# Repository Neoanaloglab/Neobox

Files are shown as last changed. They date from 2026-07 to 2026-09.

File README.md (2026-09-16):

# NeoBox

**English** · [简体中文](README.zh-CN.md) · [日本語](README.ja.md)

> An open-hardware, 3D-printable desktop flash light box for camera scanning 135 and 120 film: about 125 × 155 × 83 mm, twelve printed parts (four of them optional) at roughly 300–350 g, assembled with magnets alone: no screws, no threads, no tools. Any hot-shoe flash lies at the fully open front and fires in; an insert platform keeps the film flat, with a single universal anti-Newton glass as the optional upgrade.

**Contents:** [What NeoBox is](#what-neobox-is) · [What you get, and what you must already own](#what-you-get-and-what-you-must-already-own) · [Why a flash](#why-a-flash) · [How the light works](#how-the-light-works) · [Documentation](#documentation) · [Quick start](#quick-start) · [Repository layout](#repository-layout) · [Adapting to a different flash](#adapting-to-a-different-flash) · [Status](#status) · [Licence and credits](#licence-and-credits)

   

> [!IMPORTANT]
> This is the first release. The geometry is dimensionally verified in the Blender source and the exported STL files are numerically verified, but **no box of this geometry has ever been printed, photographed, measured or evenness-tested.** Read [Status](#status) before you spend money.

## What NeoBox is

NeoBox is a white box, fully open at the front, that turns one bare speedlight into an evenly glowing surface, so you can photograph film with a digital camera instead of a scanner, a technique called [camera scanning](docs/glossary.md#camera-scanning) (also DSLR scanning).

The flash lies flat on the desk with its head at the open front and fires **horizontally** into the white cavity; light reaches the film only after several diffuse bounces and one opal acrylic diffuser.

Because the flash stays outside the enclosure, the box only has to contain the mixing cavity and the film platform, which is why twelve printed parts, roughly 300–350 g of PLA and a 160 × 160 mm build plate are enough.

| Item | Specification |
|---|---|
| Outer size | ≈ 125 × 155 × 83 mm (footprint 124.8 × 154.8 mm; 87 mm to the top of a seated film holder) |
| Formats | 135 and 120 up to 6×9; 6×6 via a mask insert; 6×4.5 by cropping in post; mounted 135 slides via the optional slide plate; 4×5 sheets via the optional 4×5 stage, with an evenness caveat |
| Printed parts | 12 STL files (3 white, 9 black, including the optional 6×6 mask, slide plate and 4×5 stage); ≈ 300–350 g; all support-free |
| Bought parts | 1 opal acrylic diffuser, 32 Ø8 × 2 mm magnets, 4 steel washers; optional: 1 anti-Newton glass, 1 flocking sheet |
| Enclosure | A one-piece main body with a fully open front, and a cover-stage that drops on over four locating tenons |
| Diffusion | Single opal acrylic diffuser, 68 × 118 × 2 mm, under a 62 × 95 mm light window, 4.6 mm below the film |
| Film flatness | Insert platform: a 4.6 mm element ledge in the holder base carries a printed pressure-window insert, upgradable to one universal 64 × 95 × 2 mm anti-Newton glass |
| Film holders | Sliding-channel holders for 135 and 120, closed by Ø8 × 2 magnets, swapped by lifting one off and setting the other down; a pocketed slide plate for mounted 135 slides |
| Film plane | 83.2 mm above the desk, identical for both formats |
| Light source | Any hot-shoe flash with manual power, lying flat at the open front; reference build is a NEEWER TT560 with a ZENIKO T1 trigger set |
| Assembly | No screws, no threads, no tools; magnets and gravity only; levelling is done on the camera side with a small mirror |
| Licence | MIT |

## What you get, and what you must already own

NeoBox is one half of a scanning rig. It replaces the light table; it does not replace the camera above it.

| This repository gives you | You must already own or buy |
|---|---|
| 12 STL files (3 white, 9 black), every one printing support-free on a flat face | A camera body with manual exposure and raw capture (mirrorless or DSLR) |
| The Blender source `cad/neobox.blend`, the authoritative geometry | A macro-capable lens; one 1:1 macro lens covers every format in this project |
| Drawings, in English, 简体中文 and 日本語 | A [copy stand](docs/glossary.md#copy-stand), or a tripod with a horizontal or reversible column, that holds the camera squarely above the box |
| Ten documents covering shopping, printing, building and scanning | The flash itself, plus a trigger set: the transmitter goes on the camera's hot shoe, and the receiver stays outside the box |
| The committed STL exporter and the geometry verification script | A remote release, and software that does [flat-field correction](docs/glossary.md#flat-field-correction) and negative [inversion](docs/glossary.md#inversion) |
| Copy-paste [vendor scripts](docs/bom.md#vendor-scripts) for ordering every part from a print shop | The consumables in [Tools and consumables](docs/bom.md#tools-and-consumables); assembly itself needs no screwdriver, wrench or soldering iron |

> [!IMPORTANT]
> The build cost covers the printed and bought parts only. It excludes the flash, the trigger, the camera, the lens, the stand, the release and the software. If you own none of those, budget for them first; [Getting started](docs/getting-started.md#what-you-must-already-own) itemises the whole list.

## Why a flash

**The flash pulse *is* the exposure.** The camera's shutter dial stays at an ordinary sync speed (1/125 s is the recommendation); its only job is to be open when the flash fires. What actually defines the frame is the tube's pulse, which lasts just 1/1,000–1/20,000 s at working power. The front of the box is open, so ambient light can reach the cavity, but the pulse is far brighter than room light. Shoot in a dim room, keep ceiling lights out of the opening, and ambient contributes nothing visible.

**That makes vibration irrelevant.** The pulse behaves as an effective shutter one to three orders of magnitude shorter than the 1/15–1/60 s of real shutter time a continuous LED panel needs at ISO 100 and f/8. Copy-stand flex, shutter shock and footsteps on a wooden floor stop mattering, because nothing moves measurably within the pulse. This is the project's central claim.

The second argument is spectral, and film is pickier here than it looks. A colour negative is three stacked dye layers: yellow, magenta, cyan, recording blue, green and red respectively, with the cyan record and the orange mask both working at the red end of the spectrum. A scanning light has to deliver honest energy across all three bands at once. Wherever the source is weak or gapped, that dye layer is under-sampled, the channels stop separating cleanly, and the bill arrives after inversion: crossed colour curves and stubborn casts that no single white-balance click can fix.

**A xenon tube is the native light source for silver-halide materials.** Its emission is a genuinely continuous spectrum at roughly 5600 K, daylight-class colour rendering (CRI typically ≥ 95) with strong deep red, the R9 patch LEDs struggle with. A typical white LED is a blue pump plus phosphor: a spike near 450 nm, a dip around 480 nm (the "cyan gap"), a broad phosphor hump, then a roll-off past about 630 nm, landing exactly where the cyan layer and the orange mask need light most. The figure below shows the shape of the problem; the curves are schematic, typical of the two source classes, not measurements.

Spectral and time-domain comparison of flash and LED

"White" mixed from three LEDs fares no better, for the opposite reason: the spectrum collapses to three narrow spikes with near-nothing between them, so whole bands of the dye spectra are simply never sampled. A one-shot colour camera makes it worse. Its colour matrix is calibrated for continuous illuminants, three spikes read through the Bayer filters produce cross-talk the calibration never anticipated, and the white point baked into the mixing ratios fights the orange mask. The result is casts that shift from film stock to film stock and refuse to grade out.

The honest optimum lives elsewhere, and it deserves saying plainly: a monochrome camera with sequential RGB. Three exposures under narrow red, green and blue on a sensor with no Bayer mosaic make a densitometer-grade trichromatic scan, full resolution in every channel, separation defined by the source instead of by filter dyes. That is the drum-scanner lineage. It costs a niche camera, three shots per frame and a registration workflow. NeoBox deliberately sits at the pragmatic point of that curve: one flash, one shot, any camera, with a continuous spectrum keeping the single-shot path honest.

Consistency is the third argument, quiet but real. A manual flash at a fixed power fraction repeats shot after shot: every frame of a roll receives the same light, so one inversion profile fits the whole roll. There is no warm-up drift, no thermal colour shift over a session, and no PWM dimming, so nothing bands against an electronic shutter. And all of it arrives at f/8 and [base ISO](docs/glossary.md#base-iso), with power in reserve.

The precedent is commercial. Ricoh's [PENTAX FILM DUPLICATOR](https://ricohimagingstore.com/pentax-film-duplicator.html) is the benchmark camera-scanning rig, from a camera maker with film heritage, and it is specified around exactly this recipe: a digital camera with a macro lens, and an external strobe fired through a diffusion screen. NeoBox is the same optical recipe, with the light box printed at home and a film path of its own.

**An LED panel was considered and declined.** A panel is already a surface emitter, but it takes neither the effective-shutter argument nor the spectral argument above. The reasoning is in [Design](docs/design.md#8-flash-operation) and the [FAQ](docs/getting-started.md#faq).

## How the light works

Optical path through NeoBox: the flash fires horizontally into the white cavity, which mixes the light over several diffuse bounces; an opal acrylic diffuser under the film smooths it, the black parts above the diffuser absorb stray light, and the camera photographs the film against the even glow

1. **The flash fires sideways into the cavity, never at the film.** It lies flat on the desk with its light face at the fully open front, aimed into the box. The trigger receiver stays outside with it.
2. **The white cavity does the mixing.** Bare white filament walls and ceiling randomise direction over several diffuse bounces, the way an [integrating cavity](docs/glossary.md#integrating-cavity) does. There is no reflector plate and no internal adjustment hardware.
3. **One opal acrylic diffuser does the smoothing.** A 68 × 118 × 2 mm diffuser sits in a shallow recess in the cover-stage under the 62 × 95 mm light window, 4.6 mm below the film. Dust on it never images, because the diffuser itself is the glowing surface; wipe it occasionally and move on.
4. **Everything above the diffuser is black.** The holders, inserts and mask print in black filament, and an optional flocking sheet on the stage face kills the last of the glare, so stray light is absorbed instead of veiling the image.
5. **Nothing touches the image area.** The film rides on narrow lands along its non-image edges, under a pressure element seated on the 4.6 mm element ledge, leaving a 0.4 mm channel across the full frame. With the printed pressure-window insert any bow stays within 0.28 mm (inside the depth of field at 1:1 and f/8), and the optional [anti-Newton](docs/glossary.md#newton-rings) glass caps the whole frame continuously without ringing. Frames advance by pulling the strip through, so the holder is never opened mid-roll.

<details>
<summary>Why the flash stays outside the box</summary>

Earlier NeoBox revisions sealed the speedlight inside the enclosure, so the box had to be sized around the largest supported flash, and changing its batteries meant opening the box. v1 leaves the front wall entirely open: the flash lies on the desk and fires in, so the enclosure no longer depends on any flash dimension, any brand works, and the radio receiver sits outside where its signal is unobstructed.

Fully diffuse illumination keeps a side benefit known from darkroom enlargers, too: fine scratches and grain render softer than under directional light.

</details>

## Documentation

Read in this order. Everything below the line is reference material you can reach from anywhere.

```mermaid
flowchart LR
  A[Getting started] --> B[Bill of materials]
  B --> C[3D printing]
  C --> D[Assembly]
  D --> E[Scanning]
  E --> F[Troubleshooting]
```

| Document | Read this if… |
|---|---|
| [Getting started](docs/getting-started.md#getting-started) | You are new to this and want to know whether the project suits you, what it really costs, and how long it takes end to end. |
| [Bill of materials](docs/bom.md#bill-of-materials-and-sourcing) | You are about to buy. Parts, tools and consumables, sourcing in China, Japan and elsewhere, and copy-paste vendor scripts. |
| [3D printing](docs/printing.md#printing) | You are about to print, or to brief a print service. One settings block, a card per part, and acceptance checks. |
| [Assembly](docs/assembly.md#assembly) | The parts have arrived. Pressing in the magnets, the stack order, a checkpoint at every step, and the mirror levelling trick. |
| [Scanning](docs/scanning.md#scanning) | The box is built and you want negatives. Camera, lens, magnification, parallelism, focus, exposure, loading film, inversion. |
| [Troubleshooting](docs/troubleshooting.md#troubleshooting) | Something is wrong. Symptom, likely cause and fix, across printing, assembly, light and capture. |
| [Glossary](docs/glossary.md#glossary) | A word in these documents means nothing to you. One line per term, plus why it matters here. |
| [Design](docs/design.md#design) | You want the engineering: the dimension chain, the optical decisions, and how to work with the Blender source. |
| [Design log](docs/design-log.md#design-log) | You want to know why it is shaped like this, and which alternatives were tried and rejected. |
| [Contributing](CONTRIBUTING.md#contributing-to-neobox) | You want to send a patch. Which files are generated, the export and verify gate, and the three-language rule. |

## Quick start

- [ ] **1. Check that it suits you**: what you must already own, and the honest timeline. → [Getting started](docs/getting-started.md#getting-started)
- [ ] **2. Buy**: one opal acrylic diffuser cut to 68 × 118 × 2 mm, 32 Ø8 × 2 mm N35 magnets, 4 steel washers, and optionally one 64 × 95 × 2 mm anti-Newton glass and a flocking sheet. → [Bill of materials](docs/bom.md#tools-and-consumables)
- [ ] **3. Print**: 12 STL files in two colours (3 white, 9 black), plain PLA, no supports; every part prints on a flat face. The white filament must be **matte**: silk or glossy white keeps specular reflections alive in the cavity. → [3D printing](docs/printing.md#printing)
- [ ] **4. Assemble and calibrate**: press in the magnets, stack the parts; no screws, no tools. Then set a small mirror on the stage and centre the lens's own reflection in the viewfinder: the sensor is now parallel to the film plane. → [Assembly](docs/assembly.md#assembly)
- [ ] **5. Scan**: focus on the grain, meter, and shoot a roll. → [Scanning](docs/scanning.md#scanning)

> [!TIP]
> **[Bed size](docs/glossary.md#bed-size) is no longer a constraint.** The largest part is 154.8 mm long, so a 160 × 160 mm build plate is enough; every mainstream printer qualifies, and the large-bed warnings from earlier revisions no longer apply.

## Repository layout

| Path | Contents | Kind |
|---|---|---|
| [`cad/neobox.blend`](cad/neobox.blend) | Blender source: the authoritative geometry for every part | Source |
| [`cad/film-stage-aluminium-3mm.dxf`](cad/film-stage-aluminium-3mm.dxf) | The printed prototype's aluminium film stage, superseded; in v1 the stage is merged into the cover-stage | Historical |
| [`cad/legacy-plywood/`](cad/legacy-plywood/) | Two DXFs left from the abandoned plywood route. Not a complete build; kept for the record | Historical |
| [`stl/white-pla/`](stl/white-pla/) | `main-body.stl`, `cover-stage.stl`, `cover-stage-4x5.stl` | Generated |
| [`stl/black-pla/`](stl/black-pla/) | Four film-holder parts, two pressure-window inserts, `mask-6x6.stl`, `slide-plate-135.stl` and `sheet-plate-4x5.stl` | Generated |
| [`drawings/`](drawings/) | Optical path, cross-section, print orientation, exploded view, capture setup and manufacturing overview, in three languages, regenerated from the generators in `tools/drawings/` | Generated |
| [`docs/`](docs/) | The documentation set, each file in English, 简体中文 and 日本語 | Source |
| [`tools/export_stl.py`](tools/export_stl.py) | The committed exporter; regenerates the twelve STL files from `cad/neobox.blend` | Source |
| [`tools/drawings/`](tools/drawings/) | The drawing generators; regenerate the 18 SVG files under `drawings/` | Source |
| [`tools/verify_stl.py`](tools/verify_stl.py) | The geometry gate; checks watertightness, the 0.2 mm z-grid and every bounding box | Source |

## Adapting to a different flash

There is nothing to adapt. The reference build is a NEEWER TT560 with a ZENIKO T1 trigger set, but no dimension in the geometry depends on either: the flash lies flat on the desk with its head at the fully open front, and the receiver stays outside the box, where its radio signal is unobstructed and its batteries can be changed without touching anything.

Choosing a substitute takes one criterion: **manual power control**. TTL and HSS are useless here; do not pay for them. There is no re-derivation and no CAD edit: set the flash down, aim its head into the opening, re-meter, shoot. The dimension chain that actually sets the enclosure (window, cavity, film plane) is in [Design § 2](docs/design.md#2-dimension-chain).

> [!TIP]
> Never fix the outer height first and back-calculate the layers. Sum the layers, then read off the height. Doing it the other way round made the first draft physically unbuildable; it is entry 1 of the [design log](docs/design-log.md#design-log).

## Status

First release, v1 geometry.

- **Verified:** all twelve STL files are watertight single solids with zero non-manifold edges, every horizontal face sits on the 0.2 mm layer grid in its print orientation, and every bounding box matches the published dimensions. Run `tools/verify_stl.py` to reproduce this.
- **Not verified:** this geometry has **never been printed, photographed, measured or evenness-tested.** The only box ever printed was the old prototype, which shares almost no parts with v1.
- Every evenness figure quoted in the documents is a **design target**, not a measurement.
- The single-diffuser decision is informed by the author's existing light-pad workflow, not by testing this box.
- The film-flatness figures (the 0.4 mm channel, the ≤ 0.28 mm bow under the printed insert) come from the CAD stack and tolerance analysis, not from measuring real film in a real holder.

If you build one, the project would like to hear what came out tight, loose or uneven.

## Licence and credits

Designed by [Neo Analog Lab Inc. (ネオアナログラボ株式会社)](https://github.com/Neoanaloglab). Released under the [MIT License](LICENSE): build it, sell it, modify it, no permission needed.

---

[Documentation index](#documentation) · [Getting started](docs/getting-started.md#getting-started) →

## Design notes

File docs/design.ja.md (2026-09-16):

# 設計

[English](design.md) · [简体中文](design.zh-CN.md) · **日本語**

> エンジニアリングの参照資料です。どの寸法がどこから来ているのか、どの数字が光学的でどの数字が構造的なのか、ひとつ変えると何が起きるのか、そして CAD ソースを開き、編集し、書き出し直して検証するまでを扱います。

**目次：** [1. 光路](#1-光路) · [2. 寸法チェーン](#2-寸法チェーン) · [3. 光学上の判断](#3-光学上の判断) · [4. 天板ステージ](#4-天板ステージ) · [5. フィルムホルダー](#5-フィルムホルダー) · [6. 筐体](#6-筐体) · [7. フォーカス用ライト](#7-フォーカス用ライト) · [8. ストロボの運用](#8-ストロボの運用) · [9. 位置合わせと再現性](#9-位置合わせと再現性) · [10. v1 本体での 4×5](#10-v1-本体での-45) · [11. ソースファイルを扱う](#11-ソースファイルを扱う)

参考ストロボ：**NEEWER TT560** スピードライト 1 灯と **ZENIKO T1** 2.4 GHz トリガーセット。あくまで参考であって、前提ではありません。ストロボは箱の**外**、机の上に横たわるので、本書のどの寸法もストロボには依存しません。マニュアルで発光量を設定できるスピードライトなら何でも使えます。

| 表記 | 本書での意味 |
|---|---|
| 寸法 | ミリメートル。幅 × 奥行 × 高さ（X × Y × Z）の順に書く |
| `z` | 机の面を 0 とした絶対高さ。箱は机に直接立つので、本体の外底面からの高さでもある |
| パーツローカル z | [§2](#2-寸法チェーン) の積層量子化の表は、各パーツ自身のプリント底面から測る。使う箇所で明記する |
| XY 座標 | 箱の中心から測った値。箱の中心は採光窓の中心でもある |
| STL バウンディングボックス | 「STL バウンディングボックス」と明記した箇所だけの意味。値の大きい順に並んでいるので、X × Y × Z の順とは限らない |
| 出典 | 以下の数値はすべて `cad/neobox.blend` か、書き出し済みの STL ファイルから読んだもの。自分で読む手順は [§11](#11-ソースファイルを扱う) |

> [!IMPORTANT]
> ジオメトリは Blender 上で寸法を照合し、書き出した STL ファイルを数値で検証してあります。**この箱はまだ一度も、出力も組み立ても撮影も実測もされていません。** 本書に出てくる性能値はすべて結果ではなく設計目標です。拡散のためのマージンも、≤ 0.28 mm という平面保持の上限も、被写界深度によるカバーも同じです。均一性は測られておらず、本書のどこにも測ったかのような記述はありません。

---

## 1. 光路

NeoBox の断面図

机から上へ、順に積み上げると：

**机に横たわるストロボ → 完全に開いた前面 → 白い拡散チャンバー 120 × 150 × 70 → 天板ステージの採光窓 62 × 95 → 乳白アクリル 68 × 118 × 2、上面 78.6 → 空気 4.6 mm → フィルム面 z = 83.2。**

ストロボは箱の中にいません。箱と同じ机の上に横たわり、発光部を**オープンフロント（前面開口）**に寄せて、水平にチャンバーへ発光します。箱の前面には、壁がそもそもありません。TT560 の発光面は 60 × 45、中心は机から 31 mm で、高さ 70 mm の開口に余裕をもって収まります。

**フィルムに向けられている光は一切ありません。** 採光窓はチャンバーの天井、ビームと直角の位置にあり、光は素地のままの白い PLA で何度も拡散反射してからでなければ窓に届きません。これが内部を、シェードをかぶせたランプではなく[積分キャビティ (integrating cavity)](glossary.ja.md#積分キャビティ-integrating-cavity) にしています。光は 62 × 95 の窓を抜け、そのすぐ上、天板ステージに埋め込まれた[乳白 (opal)](glossary.ja.md#乳白-opal) アクリル 1 枚で最後の均しを受けます。

オープンフロントこそが v1 の設計変更のすべてです。実際に出力したプロトタイプ（社内第 4 版）はストロボを密閉した箱に収めており、その厄介ごとはすべてそこから生じていました：箱の高さはストロボの厚みから導出され、発光量のダイヤルに触るためのアクセスパネルが要り、配線のためのケーブルグランドが要り、公開 STL は特定の 1 機種にしか合いませんでした。ストロボが外に出れば、その全部が消えます：どのメーカーのストロボでも使え、レシーバーは電波の通りがよく電池交換もしやすい机の上に残り、パネルもグランドも換気の問題も存在しなくなります（[§6](#6-筐体)）。対価は、環境光がチャンバーに入り得ることです。このトレードは黙認ではなく織り込み済みです：同調速度において、閃光のパルスは室内の環境光よりはるかに明るいからです（[§8](#8-ストロボの運用)）。

> [!NOTE]
> **薄暗い部屋で撮影し、天井の照明が開口へ直射しないようにしてください。** パルスが環境光を圧倒するのは設計の前提ですが、開いた前面へまっすぐ向いた明るいランプだけは、そのマージンをただで削る唯一の置き方です。

---

## 2. 寸法チェーン

プロトタイプの箱はストロボから導出されており、その数字はプロトタイプとともに失効しました。v1 はその結びつきを断ちます：ストロボは箱に入らないので、寸法チェーンはもはや製品カタログから始まりません。机から始まり、パーツの上にパーツを重ねて、重力で上へ伸びていきます。

### プリントパーツ

STL は 12 ファイル。白 3 点、黒 9 点、すべてサポート不要です：

| STL | 色 | 外形 (mm) | 内容 |
|---|---|---|---|
| `main-body.stl` | 白 | 124.8 × 154.8 × 75.6 | 本体：底 3.0、左右と奥の壁 2.4、前面は全開。側壁の上面に位置決めダボ 2.4 × 12 × 2.6 を 4 個 |
| `cover-stage.stl` | 白 | 124.8 × 154.8 × 10.0 | 天板ステージ：壁に載る 6 mm 板。採光窓・アクリル溝・ワッシャーポケット・ホルダートレイを持つ（[§4](#4-天板ステージ)） |
| `film-holder-135-base.stl` | 黒 | 94 × 120 × 5 | 135 ホルダー底：窓 25 × 37、内側のガイドレール、4.6 のエレメント段を持つ外レール（[§5](#5-フィルムホルダー)） |
| `film-holder-135-lid.stl` | 黒 | 94 × 120 × 3 | 135 ホルダー蓋：窓 25 × 37、エレメントの収まるキャビティ、マグネットポケット 8 |
| `film-holder-120-base.stl` | 黒 | 94 × 120 × 5 | 120 ホルダー底：窓 57 × 85（6×9 フルコマ）、溝幅 62、外レールと段は 135 と同一 |
| `film-holder-120-lid.stl` | 黒 | 94 × 120 × 3 | 120 ホルダー蓋：窓 57 × 85、それ以外は 135 の蓋と同じ |
| `pressure-window-135.stl` | 黒 | 64 × 95 × 2 | 押さえ窓インサート 135（窓 25 × 37） |
| `pressure-window-120.stl` | 黒 | 64 × 95 × 2 | 押さえ窓インサート 120（窓 57 × 85） |
| `mask-6x6.stl` | 黒 | 94 × 80 × 1 | 6×6 マスク（窓 56.5 × 56.5）。トレイの中、120 の底の下に敷く |
| `slide-plate-135.stl` | 黒 | 94 × 120 × 5 | マウント済み 135 スライド用のスライドプレート：51.4 × 51.4 のポケット、窓 26 × 38、指掛け溝 2 つ。1 部品で完結する 4 組目のホルダー（[§5](#5-フィルムホルダー)） |
| `cover-stage-4x5.stl` | 白 | 124.8 × 154.8 × 10.0 | 4×5 天板ステージ：天板ステージと同じ外形・板・4 つのダボ穴に、採光窓 102 × 126、アクリル溝 107 × 131、トレイ 112.6 × 138.6 を持つ。ワッシャーポケットはない（[§10](#10-v1-本体での-45)） |
| `sheet-plate-4x5.stl` | 黒 | 112 × 138 × 5 | 4×5 シートプレート：102.2 × 127.6 のポケット、窓 97 × 121、縁の切欠き 2 つ。4×5 天板ステージのトレイに立つ |

どのパーツも平らな面を下にしてプリントします。ホルダー蓋 2 点だけは**上面を下**にします。最長のパーツは 154.8 mm なので、160 × 160 のビルドプレートで足ります。積層ピッチ・向き・スライサー設定は[プリントの資料](printing.ja.md)にあります。

### 高さ

アセンブリ全体がひとつの重力スタックです。ワールド z、机 = 0：

| 層 | z 範囲 | 備考 |
|---|---|---|
| 机 | 0 | ストロボと箱は同じ面に立つ |
| 本体の底板 | 0 – 3.0 | |
| 拡散チャンバー | 3.0 – 73.0 | 内寸 120 × 150 × 70、前面は開いている |
| 天板ステージの板 | 73.0 – 79.0 | 壁の上面に載る 6 mm 板。デッキ面は 79.0 |
| 乳白アクリル | 76.6 – 78.6 | 溝に収まり、上面はデッキより 0.4 低い |
| 鉄ワッシャー | 78.0 – 79.0 | ポケットに収まり、デッキと面一 |
| トレイのフランジ | 79.0 – 83.0 | ホルダー座を囲む縁。高さ 4 |
| ホルダー底 | 79.0 – 84.0 | フランジの内側、デッキの上に立つ。スライドプレートも同じ 5 mm を占める |
| **フィルム面** | **83.2** | 受けの上面。どちらのフォーマットでも同じ高さ |
| スライドのフィルム面 | ≈ 82.6 – 83.6 | スライドプレート内：ポケットの底 82.0 にマウント厚のおよそ半分を足した高さ。ピントを合わせ直す |
| 4×5 のフィルム面 | ≈ 82.2 | シートプレートのポケットの底 82.0 に載ったシート。ピントを合わせ直す |
| 押さえエレメント | 83.6 – 85.6 | インサートまたは AN ガラス。4.6 の段に載る |
| ホルダー蓋 | 84.0 – 87.0 | 組み上がりの総高 87 |

### 幅と奥行

本体の外形は 124.8 × 154.8。壁は 2.4 で前面は開いているので、内部チャンバーは **120 × 150 × 70**、オープンフロントはチャンバーの断面そのまま 120 × 70 です。62 × 95 の採光窓は中央にあり、窓の縁から最寄りの壁までの白壁マージンは **x 方向 29 mm、y 方向 27.5 mm**。これが拡散のためのマージンです。設計として意図的に余裕をもたせた値であり、下限は求められておらず、実測もありません。

### 別のストロボへの一般化

導出し直すものは何もありません。ストロボのカタログ値を箱の高さに変換していたプロトタイプの式は、入力そのものが消えたので式ごと消えました：**v1 の箱のどの寸法も、いかなるストロボのいかなる寸法も符号化していません。** 代わりのストロボに必要なのは、マニュアルで発光量を設定できること、そして横に寝かせた発光部が開口へ水平に発光できることだけです。TT560 の発光面 60 × 45・中心高さ 31 は参考値であって上限ではありません。レシーバーも箱の外なので、トリガーの機種も同様に自由です。ストロボを替えても `cad/neobox.blend` にも STL にも触りません（[§11](#11-ソースファイルを扱う)）。

### 積層ピッチへの量子化

**この設計でプリントされる z 方向の形状はすべて 0.2 mm のちょうど整数倍で、露出する水平の段差はどれも 0.4 mm（2 層）を下回りません。** 各パーツは自身のプリントの向きで、自身のプリント底面から量子化されています：

| パーツ（基準 = プリント底面） | z の段 |
|---|---|
| 本体 | 0 · 3.0 底板の上面 · 73.0 壁の上面 · 75.6 ダボの上面 |
| 天板ステージ | 0 · 2.8 ダボ穴の天井 · 3.6 アクリル溝の底 · 5.0 ワッシャーポケットの底 · 6.0 デッキ · 10.0 フランジの上面 |
| ホルダー底（両フォーマット共通） | 0 · 2.2 マグネットポケットの底 · 3.8 板面 · **4.2 受け** · **4.6 エレメント段** · 5.0 レールの上面 |
| ホルダー蓋（上面を下にしてプリント） | 0 · 1.0 キャビティの天井 · 3.0 蓋の下面（アセンブリ座標では 8.0 / 7.0 / 5.0） |
| インサート／マスク | 平板、2.0 ／ 1.0 |
| スライドプレート | 0 · 1.0 指掛け溝の底 · 3.0 ポケットの底 · 5.0 上面 |
| 4×5 天板ステージ | 0 · 2.8 ダボ穴の天井 · 3.6 アクリル溝の底 · 6.0 デッキ · 10.0 フランジの上面 |
| シートプレート | 0 · 1.0 切欠きの底 · 3.0 ポケットの底 · 5.0 上面 |

このグリッドの意味：0.2 mm の[積層ピッチ (layer height)](glossary.ja.md#積層ピッチ-layer-height)なら、上の段はすべて層の境界にぴたりと載るので、プリントされた 0.4 の段差は本物の 0.4 であって、スライサーの丸めの産物ではありません。0.1 mm もこのグリッドを割り切れますが、0.12 と 0.16 は割り切れません。この理屈はプロトタイプのホルダーで生まれ、そのまま引き継がれています（[設計ログ](design-log.ja.md#18-ホルダーを積層ピッチに量子化)の第 18 項）。v1 で新しいのは、ホルダーだけでなく設計全体がこれに従うことです。発注時のプリント仕様は全パーツ 0.2 です（[プリントの資料](printing.ja.md)）。検証スクリプトは書き出しのたびにグリッドと最小段差を強制します（[§11](#11-ソースファイルを扱う)）。

---

## 3. 光学上の判断

**最後の拡散層は、天板ステージに埋め込んだ乳白板 1 枚。** アクリル（購入部品、68 × 118 × 2）は 69 × 119・深さ 2.4 の溝に落とし込みます：横のクリアランスは各 0.5 mm、上面はデッキより 0.4 低くなります。ホルダーはデッキの上に立つので、**アクリルには何も触れません**。アクリルは光学の層であって構造の層ではなく、フィルム面の高さは終始プリントされたプラスチックを介して伝わり、アクリルを経由しません。取り出すときは、ホルダーを外し、箱の開口から手を入れて採光窓越しに突き上げます。

**アクリルの上の塵は写りません。** アクリルそのものが拡散して発光する面だからです：その上に載った粒子は光源の一部であって、光源とレンズの間に立つ物体ではなく、輪郭を投影できません。ときどき拭けば十分で、セッションごとの儀式は要りません。（オプションのガラスの上の塵は正反対のケースです。[§5](#5-フィルムホルダー) を参照。）

**拡散のマージン。** 窓から壁まで（x 29、y 27.5）が、チャンバーが窓を均一に満たせるかどうかを決める数字です。意図的に余裕をもたせた設計マージンで、下限は求められておらず、実測の裏付けもありません。

**チャンバー内は白一色、つや消しのみ。** 白い PLA そのものが拡散面です。内側は塗装しないでください。白いパーツにシルクや光沢のフィラメントも使わないこと。鏡面の壁は光を散らさず、発光部をホットスポットとして再現してしまいます。

**アクリルより上はすべて黒。** ホルダー・インサート・マスクは黒でプリントし、拡散層より上の迷光は反射させず吸収させます。オプションとして、デッキに A5 の黒い植毛シートを貼れば最後のぎらつきも消せます（[部品表](bom.ja.md)）。

**環境光は締め出すのではなく、許容する。** オープンフロントは室内光を通します。設計の答えは運用側にあります（薄暗い部屋、開口へ直射するランプを置かない、カメラは同調速度で）。残った環境光はパルスがはるかに上回るからです（[§8](#8-ストロボの運用)）。

**内部に調整パーツは置かない。** 光路のどこにも反射板もバッフルも水平出しの金物もありません。チャンバーは素の白壁だけです。内部パーツは 1 つ増えるごとに、位置を合わせる手間が 1 つ、ずれる原因が 1 つ増えます。均一性は[フラットフィールド補正 (flat-field correction)](glossary.ja.md#フラットフィールド補正-flat-field-correction)をかけたテストフレームで確認します。この補正が、レンズの周辺減光と光源そのもののムラを切り分けてくれます（[組み立ての資料](assembly.ja.md)）。

---

## 4. 天板ステージ

天板ステージは、プロトタイプの天板とフィルムステージを 1 枚の白い板に統合したものです。かつての蓋 1 枚・ステージ 1 枚・寸切りボルト 3 本・ナット 6 個・インサートナット 3 個が、いまはプリントパーツ 1 点です。壁の上面に直接載り、チャンバーより上の光学系すべてを受け持ちます。

この 1 パーツが持っているもの：

- **板体**：124.8 × 154.8、全高 10。構造板は 6 mm で、デッキ面は z = 79.0 に来ます。四隅のダボ穴（深さ 2.8）が本体の高さ 2.6 のダボにかぶさり、縦方向に 0.2 の逃げ。板は壁の上面に座り、ダボの上には決して載りません。ダボは XY の位置決めだけを受け持ちます。
- **採光窓**：62 × 95、中央、板を貫通。
- **アクリル溝**：69 × 119、深さ 2.4、底は 76.6、デッキ側に開口。乳白板は上から落とし込み、上面はデッキより 0.4 低く収まります（[§3](#3-光学上の判断)）。
- **トレイ**：94.6 × 120.6 のホルダー座を囲む高さ 4 のフランジで、上面は 83.0。ホルダーを片側 0.3 mm で位置決めし、その上面はフィルム面より 0.2 低い位置で、ホルダーから出たフィルムの尾を受け支えます（[§5](#5-フィルムホルダー)）。
- **ワッシャーポケット**：(±41, ±12) に 4 個、10.6 角・深さ 1.0。それぞれに 10 × 10 × 1 の鉄ワッシャー（または Ø10 × 1 の円板）を落とし込むとデッキと面一になります：ホルダー底のマグネットの受け座で、ホルダーはトレイにぱちんと吸い付いて動かなくなります。プロトタイプで接着していたワッシャーと同じ仕事を、接着なしでやります。

動かすときは、フランジをつまんで持ち上げます。天板ステージ全体が一体で箱から外れます。

**水平出しの金物がないのは、設計そのものであって欠落ではありません。** プロトタイプは 3 本の M6 寸切りでフィルムステージを箱に対して水平にしていました。v1 は寸切りもナットもインサートも、その手順ごと削除しました。

<details>
<summary>なぜ水平出しはカメラ側へ移ったのか</summary>

この設計では、プラスチックは決してねじを受け持ちません。FDM でプリントしたねじは弱く、荷重でクリープします。プロトタイプはすでに真鍮のインサートと鋼の寸切りでそれを避けていましたが、v1 はそれすら不要にしました。

より深い理由はこうです：意味のある平行はただひとつ、**フィルム面とセンサー**の平行であって、ステージを箱に対して水平にしてもそれは直接には得られません。プロトタイプで 3 つのナットを回し終えても、カメラをステージに正対させる作業は残っていました。v1 は、意味のあるその一手だけを残しました。フィルムステージに小さな鏡を置き、ファインダーを覗きながら、レンズ自身の反射が中央に来るまでカメラを動かします：中央に来た瞬間、センサーは鏡と平行であり、したがって鏡が載っているフィルム面と平行です（[鏡を使う方法](assembly.ja.md#ステップ-7--カメラ側で平行を出す鏡の方法)）。

鏡はプリントされたスタック全体の*最終結果*（底板・壁・板体・ホルダー）の上に載っているので、その下にあるすべてのプリント公差は、この一度の位置合わせで吸収されます。箱がどこかの基準まで平らである必要はありません。カメラのほうが、フィルム面が実際にある場所へ合わせに行くのです。

</details>

---

## 5. フィルムホルダー

フォーマットごとにホルダー 1 組。ホルダー底とホルダー蓋、どちらも 94 × 120 で、天板ステージのトレイに立ちます。フォーマットの変更は、1 組を持ち上げてもう 1 組を下ろすだけ：マグネットが外れて吸い直すまで 5 秒ほどで、ほかには何も動きません。コマ送りは、閉じたままのホルダーからフィルムを引き抜く動作で、1 本の途中でホルダーを開けることはありません。マウント済み 135 スライド用の 4 組目は、蓋のない 1 枚の板です（[下記](#マウント済みスライドスライドプレート)）。

| 項目 | 135 ホルダー | 120 ホルダー |
|---|---|---|
| 外形（底・蓋とも） | 94 × 120 | 94 × 120 |
| ホルダー底／蓋の板厚 | 5 ／ 3 | 5 ／ 3 |
| [窓 (window)](glossary.ja.md#窓-window)（底・蓋・インサートで共通） | 25 × 37 | 57 × 85（6×9 に対応） |
| フィルムの通り幅 | 内レールの間 35.4 | 溝の壁の間 62.0 |
| エレメント段（[下記](#フィルムの平面保持)） | 高さ 4.6、x 31 – 32.2 | 同一 |
| マグネット Ø8 × 2 | 底に 8 個 + 蓋に 8 個 | 同じ |

**窓は名目のコマに対して片側あたり約 0.5 mm 大きく開けてあります**（135 の名目は 24 × 36、120 の名目は 56 × 84）。カメラごとの画面枠のばらつきと、プリンタの XY 公差を吸収するためです。コマに合わせたトリミングは後処理で行います。[フィルムの装填](scanning.ja.md#フィルムの装填)を参照してください。

### フィルムの平面保持

フィルム面は[受け (land)](glossary.ja.md#受け-land)の上面です。窓を**四辺すべて**で囲む細い台で、ホルダー底の底面から 4.2。フィルムの厚みは 0.12 – 0.18 なので、その上面は 4.32 – 4.38 に来ます。そのすぐ上の 0.2 グリッドの段が **4.6** で、4.6 はまさに、エレメント段がその上に載るものの下面を置く高さです。この 3 つの数字がシステムのすべてです：

**受け 4.2 → フィルム上面 4.32 – 4.38 → エレメント下面 4.6。**

これで窓の四辺の受けの上に 0.4 mm の通り道ができ、エレメントの下ならどこでもフィルムは 0.22 – 0.28 mm だけ自由に浮けます。エレメントとは、段に載せる 64 × 95 × 2 の板のことです。交換式であることの根拠はここにあります：

- **標準：プリントの押さえ窓インサート**（フォーマットごとに 1 枚）。窓の周囲を一周する硬い天井が、縁での浮きを ≤ 0.28 に抑えます。開いた窓の真上ではフィルムは拘束されませんが、等倍・f/8 の被写界深度は約 ±0.4 mm あり、残った反りを覆います。
- **アップグレード：アンチニュートンガラス 1 枚、64 × 95 × 2、両フォーマット共用。** フルコマを連続して覆う天井：どの位置でも ≤ 0.28 mm。つや消し（AN）面を下にして、光沢のあるフィルムベース側に当てるので[ニュートンリング (Newton rings)](glossary.ja.md#ニュートンリング-newton-rings)は出ません。乳剤面は下の開いた窓を向き、何にも触れません。

**なぜガラス 1 枚でサンドイッチが完成するのか：** 昔ながらのガラスキャリアが 2 枚のガラスを必要とするのは、スタックの底面を定義するものがほかにないからです。ここでは底面がプリントされていて、受けが 4.2 の高さで四辺からフィルムを支えます。だから上にガラスを 1 枚置けばサンドイッチは閉じます。手入れすべきガラス面は半分になり、乳剤の下にはガラスが 1 枚もありません。

**なぜ 1 枚のガラスが両フォーマットに合うのか：** どちらの底も外レールの断面が同一だからです。エレメント段が x 31 – 32.2・高さ 4.6、その外の段が 32.2 – 33.5・高さ 5.0 で、エレメントの横方向を位置決めします。つまり同じ 64 × 95 の座が両方に存在します。135 の底では、細いストリップを導く内レール（±17.7 – 19.7）が 64 幅の板と干渉するため、|y| < 48 の中央部を丸ごと省き、両端に 12 mm のガイドだけを残してあります：ガラスはその切れ目から段の上へ落ち、ガイドが長手方向のずれを挟み止めます。

エレメントは一度据えたら、以後は手を触れません。コマ送りは、ホルダーから突き出たフィルムの先端をつまんで引くだけです。反った部分はエレメントの下面をくぐるときに押し伸ばされます。蓋のキャビティ（64.8 × 96、天井 7.0）は 0.4 の浮きしろを残してエレメントを囲みます：蓋はエレメントの位置を決めますが、決して押し付けません。エレメントの高さは常に段がプリントした 4.6 のままで、力で作った嵌合ではありません。装填の向きの目安：**ガラスなら反りを上に**（ガラスが押し伸ばします）、**インサートなら反りを下に**。ホルダーから出たフィルムはトレイのフランジに掛かり、その上面はフィルム面より 0.2 低い位置にあります。挟むのではなく、支えるだけです。長いストリップは尾側を手で支えてください。

> [!CAUTION]
> **ガラスの下面は焦点面からわずか 0.2 mm で、そこに載った塵はほぼピントの合った状態で写ります。** ガラスを据える前に両面をブロワーで吹いてください。箱の中で塵が写る面はここだけです。アクリルは正反対で、生まれつき塵に強い面です（[§3](#3-光学上の判断)）。

**マグネット。** Ø8 × 2 の N35 を圧入します（接着剤はどこにも使いません）。1 パーツに 8 個、両セットで 32 個。底のマグネットは板面から 0.4 突き出し、蓋のマグネットは蓋の下面と面一。閉じたとき両者の面は 0.8 離れていて**決して接触しません**。だから蓋は常にプリントされたレールの上面に座り、通り道の高さはマグネットの積み上がりではなく、プリントされた数字のままです。極性は、底と蓋のすべての位置が引き合うように組にすること：圧入の前に必ず相手のマグネットと吸着を確かめてください。圧入したマグネットは二度と抜けません。

**6×6 と 6×4.5。** 6×6 では `mask-6x6.stl`（94 × 80 × 1、窓 56.5 × 56.5）をトレイの中、120 の底の*下*に敷きます：ホルダー 1 組がまるごと 1 mm 高くなりますが、これは正常です。ピントを合わせ直して続けてください。6×4.5 に専用マスクはありません。後処理でトリミングします。

### マウント済みスライド：スライドプレート

マウントに入ったスライドの厚みはおよそ 1.2 – 3.2 mm で、0.4 mm の通り道の何倍もあるので、135 ホルダーには決して入りません。かといって 135 の底にポケットを掘れば、ストリップを支える受けがなくなります（[設計ログのエントリ 25](design-log.ja.md#25-マウント済みスライドには専用の板を)）。そこで `slide-plate-135.stl` を、1 部品で完結する 4 組目のホルダーとしました：94 × 120 × 5 の黒い板 1 枚で、135 のホルダー 1 組の代わりにトレイに立ちます。蓋もマグネットも押さえエレメントもありません。マウントは硬く、箱は水平なので、ポケットが位置を決め、重力が押さえます。

| 項目 | スライドプレート |
|---|---|
| 外形と厚み | 94 × 120 × 5。トレイの座はホルダー底と同じ |
| ポケット | 51.4 × 51.4、深さ 2.0。底は板の底面から 3.0（z = 82.0） |
| 窓 | 26 × 38、ポケットの底を貫通 |
| 指掛け溝 | 2 つ、18 × 12、ポケットの短辺の中央。底は 1.0 で、貫通しない |
| フィルム面 | ポケットの底にマウント厚のおよそ半分を足した高さ：紙マウントで約 82.6、ガラスマウントで約 83.6。ピントを合わせ直す |

**なぜ 51.4 か：** マウントの公称は 50 × 50 ですが、紙マウントは 50.8（2 インチ）まであります。51.4 なら最大のマウントでも片側 0.3 mm、プラマウントなら 0.7 mm の隙間が残り、ホルダー底がトレイに持つ隙間と同じです。**なぜ深さ 2.0 か：** いちばん薄い紙マウント（約 1.2）でもポケットの壁が捕まえ、いちばん厚いガラスマウント（約 3.2）は 1.2 突き出しますが、上には何もないので邪魔になりません。**なぜ 25 × 37 ではなく 26 × 38 か：** マウントはポケットの中で最大 0.7 mm 動けます。公称 24 × 36 のコマに対して片側 1 mm の余裕があれば、画面を縁取るのは常にマウント自身の開口であって、プリントの縁ではありません。それでもどのマウントも窓を四辺とも 5 mm 以上覆うので、光は漏れません。**指掛け溝**は、ポケットの縁より 0.8 低く座る紙マウントの縁に爪を掛けるためのものです。貫通せず、ポケットの底より 2.0 深いだけなので、光は通しません。

マウントは、窓にかざして見るときと同じ向きに入れます：上から見て像が正しく読める向き、つまりエマルジョン面が下。ストリップと同じ規則です。反った紙マウントや飛び出したコマは、ここでは何も平らにしません。専用のスライドスキャナーと同じです。1:1・f/8 での約 ±0.4 mm の被写界深度が、そのほとんどを吸収します。

---

## 6. 筐体

**本体**は一体でプリントする 1 パーツ：底板 3.0、左・右・奥の壁 2.4、そして前面には壁がありません。側壁の上面に位置決めダボが 4 個（2.4 × 12 × 2.6）立ち、天板ステージの四隅のダボ穴と噛み合います。

**オープンフロントが削除したもの。** プロトタイプにアクセスパネルが要ったのは、ストロボの発光量ダイヤルが遮光された箱の中にあったからです。配線が遮光壁を貫くからケーブルグランドが要り、熱の逃げ場がないから換気にも答えが要りました。v1 の箱の中には、手を伸ばす相手がそもそもいません：ストロボもレシーバーもその電池も机の上にあり、発光量の変更は指先ひとつ、フォーカス用ライトのケーブルは開口からそのまま外へ出て、チャンバーは外気に通じています。3 つの問題は、前の壁と一緒に消えました。

**ねじなし、接着剤なし、工具なし。** この設計のどこにも、プラスチックに噛み込むねじ山はありません。すべての結合は、ダボ穴に入るダボか、重力か、マグネットです：天板ステージはダボで位置が決まり自重で座り、ホルダーはマグネットでワッシャーに吸い付き、蓋はマグネットで底に吸い付き、エレメントは重力で段に載っています。マグネットは圧入、ワッシャーは置くだけ。組み立てとは順番に積むことで、数分で終わります（[組み立ての資料](assembly.ja.md)）。

> [!NOTE]
> **このビルド全体の締結部品の一覧は：ねじ 0 本、接着剤 0 滴。** プロトタイプに最後まで残っていた 2 つの接着箇所（ホルダーのマグネットと鉄ワッシャー）も消えました：v1 のマグネットは締まりばめで、ワッシャーはポケットに収まっています。

> [!WARNING]
> **重力スタックは、傾けて運んではいけません。** 組み上がった箱は、位置が合っているだけで、固定されてはいません：机の上を水平に滑らせるか、分解して別々に運んでください。天板ステージはフランジをつまめば一動作で外れます。

### 各部の位置一覧

XY は箱の中心から、z は机から。`cad/neobox.blend` から読んだ値です。

| 部位 | XY | z | 寸法 |
|---|---|---|---|
| オープンフロント | 前面 | 3.0 – 73.0 | チャンバーの全断面、120 × 70 |
| 位置決めダボ 4 個 | 側壁の上面 | 73.0 – 75.6 | 2.4 × 12 × 2.6 |
| ダボ穴 4 個 | 天板ステージの下面 | 深さ 2.8 | ダボに対し縦 0.2 の逃げ |
| 採光窓 | 中央 | 板を貫通、73.0 – 79.0 | 62 × 95 |
| アクリル溝 | 中央 | 底 76.6、79.0 のデッキへ開口 | 69 × 119、深さ 2.4 |
| ワッシャーポケット 4 個 | (±41, ±12) | 78.0 – 79.0 | 10.6 角、深さ 1.0 |
| トレイのフランジ | 94.6 × 120.6 の座を囲む | 79.0 – 83.0 | 縁、高さ 4 |

> [!TIP]
> ダボとダボ穴の嵌め合いは、FDM の通常の誤差に収まる寸法です。エレファントフット、XY の膨らみ、反りのどれもがここを食い潰します。天板ステージがきつい、あるいはガタつくときの対処はスライサーの設定であって、ファイルの編集ではありません。[きつい場合と緩い場合の対処](printing.ja.md#きつい場合と緩い場合の対処)を参照してください。

---

## 7. フォーカス用ライト

内蔵のフォーカス用ライトはなく、筐体の中に電気部品は一切ありません。構図合わせとピント合わせは普通の室内光で足ります。薄暗い部屋でもフィルムのディテールは十分見えますし、オープンフロントへ直接差し込まない限りどんな照明でも構いません。撮影の瞬間は、部屋の光をストロボが圧倒します。

---

## 8. ストロボの運用

マニュアル発光量のみ、通常シンクロ、[RAW](glossary.ja.md#raw) で撮影します。[TTL](glossary.ja.md#ttl-through-the-lens-調光) 調光はここでは無意味です（被写体は永遠に変わらないので、発光量は一度マニュアルで決めれば終わりです）。そして [HSS](glossary.ja.md#hss-ハイスピードシンクロ) が解決する問題は、[同調速度 (sync speed)](glossary.ja.md#同調速度-sync-speed)以下には存在しません。どちらにもお金を払わないでください。

**パルスがそのまま露光です。** 前面が開いていても、薄暗い部屋なら、同調速度の 1 回の露光が拾う環境光はパルスに比べて無視できます。つまりストロボ自身の発光時間が実効シャッターになり、三脚で耐えられるどんな定常光の露光時間より桁違いに短くなります。振動もシャッターショックも床の揺れも、問題でなくなります。

**シャッター速度：推奨は 1/125 秒。** フォーカルプレーンシャッターの同調速度は通常 1/160 – 1/250 とされますが、安価な 2.4 GHz トリガーの遅延がそこから約 1 段を食います。だから 1/125 です。本当の限界を超えたときの症状は見間違えようがありません：画面を横切る、縁のくっきりした暗い帯です。

> [!IMPORTANT]
> **電子シャッターでは、たいていストロボがそもそも発光しません。** ボタンを押しても何も起きないときは、まずここを確認してください。詳しくは[露出](scanning.ja.md#露出)にあります。

発光量の変更は指先ひとつです。ストロボは目の前の机に横たわっていて、開けるものも、乱すものもありません。レシーバーはその隣、箱の外にあり、電波の通り道はきれいで、電池交換は何にも触れません。実際には発光量はテストフレームで一度決めたら、あとは触りません。露出の手順は[露出](scanning.ja.md#露出)にあります。

---

## 9. 位置合わせと再現性

フィルム面は**どちらのストリップ判型でも** z = 83.2 に固定です（6×6 マスクは 120 の 1 組を 1 mm 持ち上げ、スライドプレートとシートプレートはフィルムをそこから 1 mm 以内に置きます。ピントを合わせ直すだけで、ほかは何も変わりません）。135 と 120 で変わるのは必要な撮影倍率、したがってカメラの高さであって、フィルムの高さではありません。カメラの高さは、フィルム面の高さにレンズの[ワーキングディスタンス](glossary.ja.md#ワーキングディスタンス-working-distance)を足して求めます。計算は[カメラの高さとスタンド](scanning.ja.md#カメラの高さとスタンド)にあります。

**平行出しは一度の位置合わせ：鏡を使う方法です。** フィルムステージに小さな鏡を置き、ファインダーの中でレンズ自身の反射を中央に持ってきます。その瞬間、センサーはフィルム面と平行になり、その下のスタック全体のプリント公差も同じ一手で吸収されています（[鏡を使う方法](assembly.ja.md#ステップ-7--カメラ側で平行を出す鏡の方法)、理由は [§4](#4-天板ステージ)）。箱に水平出しの金物がひとつもないのは、まさにこのためです。

カメラが決まったら、動かすのは箱のほうです。カメラを振り直すのではなく、机の上で箱をずらしてコマを中央に持ってきます。ストロボは開口へ軽く寄せ直すだけです。決まったら位置を再現できるようにしておきます。ベースボードに位置決めピンを 2 本打つか、箱の外形を鉛筆でなぞるか、どちらでも構いません。あわせて、フォーマットごとに使ったポールの高さも書き留めておきます。

**平行が先、均一性が後。** ストロボは振動を止めますが、センサーと平行になっていないフィルム面を直すことはできません。まず鏡を使う方法、それから[フラットフィールド補正](glossary.ja.md#フラットフィールド補正-flat-field-correction)をかけたテストフレームで均一性を確認します。

---

## 10. v1 本体での 4×5

4×5 は、本体をそのままに、オプションの部品 2 点と一回り大きいアクリル 1 枚で載ります。`cover-stage-4x5.stl` が天板ステージの代わりに載り、そのトレイに `sheet-plate-4x5.stl` が立ち、溝には 106 × 130 × 2 の乳白板が入ります。ほかは何も変わりません。同じダボ、同じオープンフロントに同じストロボ、同じ重力スタック、同じ 160 × 160 のビルドプレートです。

| 項目 | 4×5 天板ステージ | v1 天板ステージ |
|---|---|---|
| 外形・板・ダボ穴 | 124.8 × 154.8、6 mm の板、ダボに掛かる 4 つのダボ穴 | 同一 |
| 採光窓 | 102 × 126 | 62 × 95 |
| アクリル溝 | 107 × 131、底は 3.6。106 × 130 × 2 の板用 | 69 × 119。68 × 118 × 2 用 |
| フランジ内側のトレイ | 112.6 × 138.6、フランジ幅 4、上面 10.0 | 94.6 × 120.6、フランジ幅 7 |
| ワッシャーポケット | なし：シートプレートにマグネットはない | 4 個 |
| 拡散マージン（窓の縁から壁まで） | x 方向 9、y 方向 12 | x 方向 29、y 方向 27.5 |

| 項目 | シートプレート |
|---|---|
| 外形と厚み | 112 × 138 × 5。4×5 のフランジの内側でデッキの上に立つ |
| ポケット | 102.2 × 127.6、深さ 2.0。底は板の底面から 3.0（z = 82.0） |
| 窓 | 97 × 121、ポケットの底を貫通。画面 96 × 120 に、いつもの片側 0.5 を足したもの |
| 縁の切欠き | 2 つ、幅 18、短辺側。シートの縁の 3.7 内側から板の縁を突き抜けて外まで。底は 1.0 |
| フィルム面 | シートはポケットの底に載る：約 82.2 |

**なぜシートに押さえエレメントが要らないのか。** フルサイズで 4×5 を撮る倍率はおよそ 0.25× で、そのとき f/8 の被写界深度はおよそ 8 – 10 mm、135 の場合の 10 倍です。シート自身のミリ単位の反りは、この尺度では見えません。だからこの板は、シートの縁を受ける受けを持つポケットであって、上には何も載りません。蓋もガラスもマグネットもなし。シートは 1 枚ずつ、上から見て像が正しく読める向き（エマルジョン面が下）で入れ、縁の切欠きから取り出します。

**分かっていないこと：均一性。** v1 の窓は壁から 29 と 27.5 mm、4×5 の窓は 9 と 12 mm です。マージンの下限はこれまで一度も確立されておらず、何も測っていません。だから 4×5 ステージは、数値としてではなく、同じ本体の上での実験として公開します。まず何も入れずに 1 コマ撮ってください。受け入れられない勾配が見えたら、後処理のフラットフィールド補正が第一の手段（[scanning.ja.md](scanning.ja.md#フラットフィールド補正と反転)）、より大きな箱が第二の手段です。

<details>
<summary>マージンが足りないと分かったときの、大きな箱への道</summary>

導出すべきは「より大きな箱」であって、「別の種類の箱」ではありません。102 × 126 の窓はそのままに v1 のマージンを与えると、チャンバー内寸は 160 × 181、本体外形はおよそ 164.8 × 185.8 になり、160 × 160 のビルドプレートを超えて 220 クラスが必要になります。天板ステージ、トレイ、シートプレート、アクリルもそれに合わせて拡大します。オープンフロントの構成、ねじなしの重力スタック、積層グリッドはそのまま使えます。ストロボは大きくしなくて済むかもしれません。窓が大きくなる分で約 1.2 段失い、1:1 から 0.25× に下がる分で約 1.3 段戻るからです。ただしこれも測っていません。
</details>

---

## 11. ソースファイルを扱う

`cad/neobox.blend` が、このリポジトリで唯一のジオメトリのソースです。12 の STL ファイルはすべてここから生成されており、blend ファイルを通さずに STL へ届いた変更は、次に誰かが書き出し直した時点で失われます。

### ファイルを開く

| 項目 | 値 |
|---|---|
| Blender のバージョン | **3.0 以降。** ファイルは Zstandard 圧縮で、3.0 より前の Blender ではそもそも読めません。ファイルヘッダーには、最後に保存したバージョンとして **Blender 5.2** が記録されています |
| 単位系 | メートル法、unit scale 0.001、長さの単位はミリメートル。**Blender の 1 単位が 1 mm** |
| シーンの配置 | アセンブリは組み付いた位置のままモデリングしてあり、z の基準は本書と同じです：机（箱の外底面）が z = 0。120 のホルダー 1 組はアセンブリの脇 x = 200 に、6×6 マスクは x = 350 に、スライドプレートは x = 500 に、4×5 ステージは x = 650 に置いてあります |

### コレクション構成

```
Scene Collection
├── mock_view-target    ビューのターゲット用の empty
├── Scaffolding         Camera、Light：レンダリング用の足場
├── NeoBox_v1           筐体、天板ステージ、モックアップ
├── Holder_135          135 のホルダー 1 組。組み付いた位置にある
├── Holder_120          120 のホルダー 1 組。x = 200 に置いてある
├── Masks               6×6 マスク。x = 350 に置いてある
├── Holder_slide        スライドプレートとマウントのモックアップ。x = 500 に置いてある
└── Stage_4x5           4×5 天板ステージとシートプレート、そのモックアップ。x = 650 に置いてある
```

### どのオブジェクトがどの STL になるか

| STL ファイル | Blender のオブジェクト | 内容 |
|---|---|---|
| `main-body.stl` | `main-body_floor`、`main-body_wall-left`、`main-body_wall-right`、`main-body_wall-rear` | **4 オブジェクト**：底板、左壁、右壁、奥壁。前面が開いているので、まぐさも前柱も要らない |
| `cover-stage.stl` | `cover-stage` | 天板ステージ、一体、窓 62 × 95 |
| `film-holder-135-base.stl` | `film-holder-135-base` | 135 のホルダー底、平底 |
| `film-holder-135-lid.stl` | `film-holder-135-lid` | 135 のホルダー蓋 |
| `film-holder-120-base.stl` | `film-holder-120-base` | 120 のホルダー底、平底 |
| `film-holder-120-lid.stl` | `film-holder-120-lid` | 120 のホルダー蓋 |
| `pressure-window-135.stl` | `pressure-window-135` | 押さえ窓インサート 135 |
| `pressure-window-120.stl` | `pressure-window-120` | 押さえ窓インサート 120 |
| `mask-6x6.stl` | `mask-6x6` | 6×6 マスク |
| `slide-plate-135.stl` | `slide-plate-135` | スライドプレート、1 部品 |
| `cover-stage-4x5.stl` | `cover-stage-4x5` | 4×5 天板ステージ、1 部品 |
| `sheet-plate-4x5.stl` | `sheet-plate-4x5` | 4×5 シートプレート、1 部品 |

### 書き出してはいけないモックアップ

シーンにあるそれ以外のすべては、収まりと光路を見るためのモックアップで、どれ 1 つプリントも書き出しもしません：ストロボ本体とその発光面（`mock_flash-body`、`mock_flash-face`）、T1 レシーバー（`mock_trigger-receiver`）、光路を示す矢印 4 本（`mock_ray-1-into-cavity` から `mock_ray-4-through-window`）、135 と 120 のフィルムストリップのモックアップ（`mock_film-135`、`mock_film-120`）、50 × 50 × 2 のスライドマウント（`mock_slide-mount-50x50x2`）、4×5 のシート（`mock_film-4x5`）、乳白アクリル 2 枚（`mock_diffuser-68x118x2`、`mock_diffuser-106x130x2`）、AN ガラス（`mock_an-glass-64x95x2`）、鉄ワッシャー 4 枚（`mock_steel-shim-1` から `mock_steel-shim-4`）、テキストラベル（`mock_label`）、そしてカメラ／ライト／ビューターゲットという足場（`Camera`、`Light`、`mock_view-target`）です。

見分け方は名前です。プリントするパーツは、自分がなる STL ファイルと同じ名前を持ちます（本体だけは例外で、`main-body_` で始まる 4 枚のシェルに分かれています）。プリントしないオブジェクトは `mock_` で始まります。`Camera` と `Light` だけはこの規則の外ですが、どちらもメッシュではないので STL に届きようがありません。この命名規則は飾りではありません。`tools/export_stl.py` が書き出しのたびに検査していて、`MAPPING` に載っておらず `mock_` でも始まらないメッシュオブジェクトが 1 つでもあれば、書き出しは全体として失敗します。おかげで、シーンに足したプリントパーツを `MAPPING` に書き忘れても、そのパーツの STL が欠けたまま公開されることはありません。

> [!CAUTION]
> **マテリアル名はフィラメントの色を表していません。** マテリアルスロットはレンダリングのためのものです。8 つのマテリアルはいずれも、実際に割り当てられている相手を名前で説明しています：`NB_white` は本体シェルと天板ステージ、`NB_black` は黒でプリントするパーツすべてと、ストロボ本体・ラベル・スライドマウントのモック、`NB_steel` は鉄ワッシャーのモック 4 枚、`NB_opal` は乳白アクリルと AN ガラスのモック、`NB_film` はフィルムのモック 2 枚、`NB_glow` はストロボの発光面、`NB_ray` は光路の矢印 4 本、`NB_receiver` はレシーバーのモックです。プロトタイプ時代に残っていたマテリアルはすべて削除済みで、誤解を招く名前はもう残っていません。それでも色の出典はここではありません。色は必ず[12 点のパーツ](printing.ja.md#12-点のパーツ)から取り、マテリアルスロットからは絶対に取らないでください。

### 書き出しの約束

STL はすべて、**アセンブリのワールド座標のまま**書き出しています。途中で原点を戻したり、向きを変えたりはしません。

| ファイル | 書き出したファイルの中での位置 |
|---|---|
| `main-body.stl` | z 0 – 75.6、XY は中央 |
| `cover-stage.stl` | z 73 – 83、XY は中央 |
| `film-holder-135-base.stl` ／ `-lid.stl` | z 79 – 84 ／ 84 – 87、組み付いた位置のまま |
| `pressure-window-135.stl` | z 83.6 – 85.6、組み付いた位置のまま |
| `film-holder-120-base.stl` ／ `-lid.stl` | x 153 – 247、z 0 – 5 ／ 5 – 8 に置いてある |
| `pressure-window-120.stl` | x 168 – 232、z 4.6 – 6.6 に置いてある |
| `mask-6x6.stl` | x 303 – 397、z 0 – 1 に置いてある |
| `slide-plate-135.stl` | x 453 – 547、z 0 – 5 に置いてある |
| `cover-stage-4x5.stl` | x 587.6 – 712.4、z 0 – 10 に置いてある |
| `sheet-plate-4x5.stl` | x 594 – 706、z 6 – 11。4×5 天板ステージのデッキの上に立てて置いてある |

スライサーは各ファイルをバウンディングボックスでビルドプレートに落とします。12 ファイルのうち 10 は、読み込んだ時点でプリント面を下にして寝ています。ホルダー蓋の 2 つだけは違います。**上面を下**にしてプリントするパーツなので、インポート後に裏返す必要があります。必要な回転量は、[12 点のパーツ](printing.ja.md#12-点のパーツ)のパーツカードにそれぞれ書いてあります。

### 再書き出しの手順

コマンド 1 本で 12 ファイルすべてを再生成します。これは公開中の STL を作ったパイプラインをリポジトリに収めたものであり、サポートされる唯一の書き出し方法です：

```
blender --background cad/neobox.blend --python tools/export_stl.py
```

（`blender` は Blender インストール内の実行ファイルです。4.x／5.x のどれでも動きます。リポジトリのルートで実行し、続けて `python3 tools/verify_stl.py` を走らせてください。）

このスクリプトが必要な理由は、プリント部品が**互いに食い込むシェルとしてモデリングされている**からです。意図的に 0.2 – 0.5 mm 重ねてあります：壁は床へ、フランジは天板ステージの板へ、レールはホルダー底へ沈み込んでいます。これはソースをパラメトリックで編集しやすく保つための作りです。スクリプトは出力ファイルごとに、ソースオブジェクトを複製し、ルースパーツで分割し、EXACT ソルバーのブーリアン結合で 1 つのソリッドにまとめ、ブーリアンの残渣を溶接で除去し、水密を自己検査してから、アセンブリのワールド座標のまま書き出します。シーン自体には一切手を触れません。素のオブジェクトを File → Export → STL するとマルチシェルのファイルになり、その内部面が検証スクリプトの積層グリッド検査で不合格になります。

再生成したファイルは公開ファイルと**バイト単位では一致しないことがあります**（三角形分割は Blender のバージョン間で安定しません）が、幾何は完全に同一です。審判は検証スクリプトです：バウンディングボックス・水密・積層グリッド・最小段差の 4 項目がすべて合格であること。

<details>
<summary>手動での書き出し（スクリプトが使えない場合の代替）</summary>

1. **1 つの出力ファイルに対応するオブジェクトを選択します。** 上の対応表のとおりに選びます。*チェックポイント：*選択したオブジェクトの数が表と一致すること。本体は 4 つ、それ以外は 1 つずつ。
2. **本体だけでなく、どの部品も 1 つのソリッドにします。** 単一オブジェクトの部品も、内部はマルチシェルであり得ます。必要なものを join し、ルースパーツで分割してブーリアン結合し、距離 0.02 mm で頂点をマージ、1° の限定的溶解でブーリアン残渣を取り除きます。*チェックポイント：*部品が連続した 1 枚のシェルになり、検証スクリプトが「非多様体エッジなし」と報告すること。
3. **書き出します。** File → Export → STL、*Selection Only* にチェック、scale 1.00、forward Y、up Z。座標軸の変換はしないこと：ファイルの中の数値が、Blender の中の数値と一致していなければなりません。*チェックポイント：*書き出したファイルを読み込み直すと、パーツが元の位置にぴたりと戻ること。
4. **同じパスへ上書きします。** `stl/white-pla/` か `stl/black-pla/` の下に、ファイル名はそのままで。*チェックポイント：*`git status` に出るのが変更されたファイルであって、新規ファイルではないこと。
5. **コミットの前に検証します。** *チェックポイント：*`python3 tools/verify_stl.py` が `all 12 files pass` と表示し、終了コード 0 で終わること。

</details>

```mermaid
flowchart LR
  A[cad/neobox.blend を編集] --> B[影響する STL を書き出す]
  B --> C[python3 tools/verify_stl.py]
  C -->|12 ファイルすべて合格| D[3 言語のドキュメントを更新]
  C -->|1 つでも FAIL| A
  D --> E[blend・STL・ドキュメントをまとめてコミット]
```

### 検証スクリプトを走らせる

`tools/verify_stl.py` は、依存関係のない素の Python 3 です。リポジトリのルートで実行します。

```
python3 tools/verify_stl.py
```

`stl/` 以下のすべての `.stl` をたどり、ファイルごとに 4 つの不変条件を確認します。

| 確認項目 | 何を保証するか |
|---|---|
| watertight | すべてのエッジがちょうど 2 つの三角形に共有されていること。穴のない閉じたソリッド |
| layer grid | 水平面がすべて、そのパーツ自身の底面から 0.2 mm の整数倍の高さにあること |
| minimum step | 露出する水平の段差が、0.4 mm（0.2 で 2 層）を下回らないこと |
| bounding box | パーツの寸法が、ドキュメントに書いてあるとおりのままであること |

段差を探すとき 1 mm² 未満の水平面は無視するので、モデリング上の細片が誤検出を起こすことはありません。出力はファイルごとに 1 行と、合計が 1 行。どれかが失敗すると終了コードが 0 以外になるため、このスクリプトでコミットをゲートできます。

```
ok    film-holder-120-base.stl  [94.0, 120.0, 5.0]  256 triangles
...
all 12 files pass
```

公開しているバウンディングボックスは、スクリプト冒頭の `EXPECTED` テーブルに、値の大きい順で並べてあります。**公開している寸法を意図して変えたときは、同じコミットで `EXPECTED` も直してください**。さもないと、変えたつもりのパーツで検証が落ち、変えていないパーツのほうは黙って通ってしまいます。

### ストロボを変更する

プロトタイプでは、この見出しの下に導出し直しのチェックリストがありました。v1 では、変えるものがありません：**箱のどの寸法もストロボを符号化していない**ので、別のストロボ（別のトリガーでも）にしても `cad/neobox.blend` にも STL にも触りません。新しいストロボに必要なのは、マニュアルの発光量設定と、横に寝かせてオープンフロントへ水平に発光できる発光部だけです。交換したら、露出のテストフレームを撮り直して作業を続けてください（[§8](#8-ストロボの運用)）。

### `cad/` のその他のファイル

- `film-stage-aluminium-3mm.dxf`：プロトタイプのアルミ製フィルムステージ。履歴として残してあるだけです。v1 にフィルムステージはありません：このパーツは天板ステージに統合され、現在の設計でこのファイルから切り出すものは何もありません。
- `legacy-plywood/`：合板版の DXF。履歴として残してあるだけです。2 ファイルを合わせてもシェルとして完結しておらず、現在の設計でここから切り出すものは何もありません。

コントリビューションのルール（何がソースで何が生成物か、そして 3 言語をそろえる要件）は [CONTRIBUTING.md](../CONTRIBUTING.md#source-of-truth-vs-generated-files) にあります。

---

← [用語集](glossary.ja.md) · [ドキュメント一覧](../README.ja.md#ドキュメント) · [設計ログ](design-log.ja.md) →

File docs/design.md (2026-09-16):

# Design

**English** · [简体中文](design.zh-CN.md) · [日本語](design.ja.md)

> The engineering reference: where every dimension comes from, which numbers are optical and which are structural, what happens if you change one, and how to open, edit, re-export and verify the CAD source.

**Contents:** [1. Light path](#1-light-path) · [2. Dimension chain](#2-dimension-chain) · [3. Optical decisions](#3-optical-decisions) · [4. Cover-stage](#4-cover-stage) · [5. Film holders](#5-film-holders) · [6. Enclosure](#6-enclosure) · [7. Focus light](#7-focus-light) · [8. Flash operation](#8-flash-operation) · [9. Repositioning and repeatability](#9-repositioning-and-repeatability) · [10. 4×5 on the v1 body](#10-45-on-the-v1-body) · [11. Working with the source](#11-working-with-the-source)

Reference flash: a **NEEWER TT560** speedlight with a **ZENIKO T1** 2.4 GHz trigger set. It is a reference, not a requirement. The flash lies on the desk *outside* the box, so no dimension in this document depends on it; any speedlight with manual power control works.

| Convention | What it means here |
|---|---|
| Dimensions | Millimetres, written width × depth × height (X × Y × Z) |
| `z` | Absolute height above the desk. The box stands directly on the desk, so this is also the height above the outer bottom of the main body |
| Part-local z | The layer-quantisation tables in [§2](#2-dimension-chain) measure each part from its own print-bed face instead; stated where used |
| XY positions | Measured from the centre of the box, which is also the centre of the light window |
| STL bounding box | Quoted only where it is labelled as such; it is sorted largest first and is often not in X × Y × Z order |
| Source | Every number below is read from `cad/neobox.blend` or from the exported STL files. [§11](#11-working-with-the-source) explains how to read them yourself |

> [!IMPORTANT]
> The geometry is verified dimensionally in Blender and numerically in the exported STL files. **The box has never been printed, built, photographed or measured.** Every performance figure in this document is a design target, not a result: the mixing margins, the ≤ 0.28 mm flatness bound, the depth-of-field coverage. No evenness has been measured, and nothing here claims otherwise.

---

## 1. Light path

Cross-section drawing of the NeoBox

The stack, desk upward:

**flash lying flat on the desk → the fully open front → white cavity 120 × 150 × 70 → light window 62 × 95 in the cover-stage → opal acrylic 68 × 118 × 2, top face at 78.6 → 4.6 mm of air → film plane at z = 83.2.**

The flash is not inside the box. It lies flat on the same desk the box stands on, its head against the **open front** (the front face of the box has no wall at all) and fires horizontally into the cavity. The TT560's emitting face is 60 × 45 with its centre 31 mm above the desk, well inside the 70 mm-tall opening.

**Nothing is aimed at the film.** The light window is in the ceiling of the cavity, at right angles to the beam, so light reaches it only after several diffuse bounces off the bare white PLA. That is what makes the interior an [integrating cavity](glossary.md#integrating-cavity) rather than a lamp with a shade. It leaves through the 62 × 95 window and gets its final smoothing from one [opal](glossary.md#opal) acrylic sheet recessed into the cover-stage directly above.

The open front is the whole v1 architecture in one move. The printed prototype (internal revision 4) sealed the flash inside the box, and everything difficult about the prototype followed from that: the box height was derived from the flash's thickness, an access panel was needed to reach the power dial, a cable gland to pass wires, and the published STLs fitted one flash model and no other. With the flash outside, all of it disappears: any brand of flash works, the receiver stays on the desk where its radio signal is clean and its batteries are reachable, and there is no panel, gland or ventilation question left to answer ([§6](#6-enclosure)). The price is that ambient light can enter the cavity. That trade is accepted, not ignored: the flash pulse is far brighter than room ambient at sync speed ([§8](#8-flash-operation)).

> [!NOTE]
> **Work in a dim room, and keep ceiling lamps from shining straight into the opening.** The pulse overwhelms ambient light by design, but a bright lamp aimed into the open front is the one geometry that erodes that margin for free.

---

## 2. Dimension chain

In the prototype the box was derived from the flash, and its numbers died with it. v1 severs the link: the flash never enters the box, so the chain no longer starts at a product's datasheet. It starts at the desk and runs upward, part stacked on part, by gravity.

### The printed parts

Twelve STL files, three white and nine black, all printed without supports:

| STL | Colour | Overall (mm) | What it is |
|---|---|---|---|
| `main-body.stl` | white | 124.8 × 154.8 × 75.6 | Main box: 3.0 floor, 2.4 left/right/rear walls, front fully open; four locating tenons 2.4 × 12 × 2.6 on the side-wall tops |
| `cover-stage.stl` | white | 124.8 × 154.8 × 10.0 | Cover-stage: 6 mm plate seated on the walls, with light window, acrylic recess, washer pockets and holder tray ([§4](#4-cover-stage)) |
| `film-holder-135-base.stl` | black | 94 × 120 × 5 | 135 holder base: 25 × 37 window, inner guide rails, outer rails with the 4.6 element ledge ([§5](#5-film-holders)) |
| `film-holder-135-lid.stl` | black | 94 × 120 × 3 | 135 holder lid: 25 × 37 window, element cavity, 8 magnet pockets |
| `film-holder-120-base.stl` | black | 94 × 120 × 5 | 120 holder base: 57 × 85 window (full 6×9), 62 channel, same outer rails and ledge as the 135 |
| `film-holder-120-lid.stl` | black | 94 × 120 × 3 | 120 holder lid: 57 × 85 window, otherwise identical to the 135 lid |
| `pressure-window-135.stl` | black | 64 × 95 × 2 | Pressure-window insert, 135 (window 25 × 37) |
| `pressure-window-120.stl` | black | 64 × 95 × 2 | Pressure-window insert, 120 (window 57 × 85) |
| `mask-6x6.stl` | black | 94 × 80 × 1 | 6×6 mask (window 56.5 × 56.5), laid in the tray under the 120 base |
| `slide-plate-135.stl` | black | 94 × 120 × 5 | Slide plate for mounted 135 slides: 51.4 × 51.4 pocket, 26 × 38 window, two finger wells; a fourth holder set in one piece ([§5](#5-film-holders)) |
| `cover-stage-4x5.stl` | white | 124.8 × 154.8 × 10.0 | 4×5 cover-stage: the cover-stage's outline, plate and four notches with a 102 × 126 light window, a 107 × 131 acrylic recess and a 112.6 × 138.6 tray; no washer pockets ([§10](#10-45-on-the-v1-body)) |
| `sheet-plate-4x5.stl` | black | 112 × 138 × 5 | 4×5 sheet plate: 102.2 × 127.6 pocket, 97 × 121 window, two edge notches; stands in the 4×5 cover-stage's tray |

Every part prints flat face down; the two lids print top face down. The largest part is 154.8 mm long, so a 160 × 160 print bed is enough. Layer heights, orientation cards and slicer settings are in [printing.md](printing.md).

### Height

The whole assembly is one gravity stack. World z, desk = 0:

| Layer | z range | Note |
|---|---|---|
| Desk | 0 | the flash and the box stand on the same surface |
| Main-body floor | 0 – 3.0 | |
| Cavity | 3.0 – 73.0 | interior 120 × 150 × 70, open at the front |
| Cover-stage plate | 73.0 – 79.0 | 6 mm plate seated on the wall tops; deck face at 79.0 |
| Opal acrylic | 76.6 – 78.6 | in its recess, top face 0.4 below the deck |
| Steel washers | 78.0 – 79.0 | in their pockets, flush with the deck |
| Tray flange | 79.0 – 83.0 | rim around the holder seat, 4 high |
| Holder base | 79.0 – 84.0 | stands on the deck inside the flange; the slide plate occupies the same 5 mm |
| **Film plane** | **83.2** | land top; the same height for both formats |
| Slide film plane | ≈ 82.6 – 83.6 | in the slide plate: pocket floor at 82.0 plus about half the mount's thickness; refocus |
| 4×5 film plane | ≈ 82.2 | a sheet lying on the sheet plate's pocket floor at 82.0; refocus |
| Pressure element | 83.6 – 85.6 | insert or AN glass on the 4.6 ledge |
| Holder lid | 84.0 – 87.0 | total assembled height 87 |

### Width and depth

The main body is 124.8 × 154.8 outside; the walls are 2.4, the front is open, so the interior cavity is **120 × 150 × 70** and the open front is the cavity's full 120 × 70 cross-section. The 62 × 95 light window is centred, which leaves **29 mm of white wall in x and 27.5 mm in y** between the window edge and the nearest wall: the mixing margin. It is deliberately generous by design; no minimum has been established, and nothing has been measured.

### Generalising to another flash

There is nothing to re-derive. The prototype-era formulas that turned a flash datasheet into a box height are gone because the input is gone: **no dimension of the v1 box encodes any dimension of any flash.** A substitute flash needs manual power control and a head that can lie flat and fire level into the open front. The TT560's emitting face, 60 × 45 with its centre 31 above the desk, is the reference, not a limit. The receiver stays outside too, so the trigger model is equally free. Swapping flashes touches neither `cad/neobox.blend` nor the STLs ([§11](#11-working-with-the-source)).

### Layer quantisation

**Every printed z-feature in this design is an exact multiple of 0.2 mm, and no exposed horizontal step is under 0.4 mm (two layers).** Each part is quantised in its own print orientation, measured from its own print-bed face:

| Part (datum = print-bed face) | z stations |
|---|---|
| Main body | 0 · 3.0 floor top · 73.0 wall top · 75.6 tenon top |
| Cover-stage | 0 · 2.8 notch ceiling · 3.6 acrylic-recess floor · 5.0 washer-pocket floor · 6.0 deck · 10.0 flange top |
| Holder bases (both formats) | 0 · 2.2 magnet-pocket floor · 3.8 plate face · **4.2 land** · **4.6 element ledge** · 5.0 rail top |
| Holder lids (printed top face down) | 0 · 1.0 element-cavity ceiling · 3.0 lid underside (assembly-local 8.0 / 7.0 / 5.0) |
| Inserts / mask | flat plates, 2.0 / 1.0 |
| Slide plate | 0 · 1.0 finger-well floor · 3.0 pocket floor · 5.0 top |
| 4×5 cover-stage | 0 · 2.8 notch ceiling · 3.6 acrylic-recess floor · 6.0 deck · 10.0 flange top |
| Sheet plate | 0 · 1.0 notch floor · 3.0 pocket floor · 5.0 top |

The point of the grid: at a 0.2 mm [layer height](glossary.md#layer-height) every one of those stations lands exactly on a layer boundary, so a printed 0.4 step is a true 0.4 step, not a slicer rounding. 0.1 mm also divides the grid; 0.12 and 0.16 do not. The reasoning dates from the prototype's holders and carries over unchanged ([design log entry 18](design-log.md#18-layer-quantised-holders)); what is new in v1 is that the whole design obeys it, not just the holders. The print order spec pins every file at 0.2 ([printing.md](printing.md)). The verifier enforces the grid and the minimum step on every export ([§11](#11-working-with-the-source)).

---

## 3. Optical decisions

**One opal sheet, recessed into the cover-stage, is the final diffuser.** The acrylic (a bought part, 68 × 118 × 2) drops into a 69 × 119 recess 2.4 deep: 0.5 mm of side clearance, top face 0.4 below the deck. Because the holder stands on the deck, **nothing ever touches the acrylic**: it is an optical layer, not a structural one, and the film plane is referenced through printed plastic, never through it. To lift it out, take the holder off and push the sheet up through the light window from inside the box.

**Dust on the acrylic does not image.** The acrylic is itself the diffuse emitting surface: a particle sitting on it is part of the source, not an object between the source and the lens, so it cannot project an outline onto the film. Wipe the sheet periodically and move on; no per-session ritual. (Dust on the optional glass is the opposite case; see [§5](#5-film-holders).)

**Mixing margins.** The window-to-wall margins, 29 in x and 27.5 in y, are the numbers that decide how well the cavity fills the window evenly. They are design margins, chosen generous, with no established minimum and no measurement behind them.

**All-white cavity, matte only.** The white PLA *is* the mixing surface. Do not paint the inside, and do not print the white parts in silk or glossy filament: a specular wall reproduces the flash head as a hot spot instead of scattering it.

**Everything above the acrylic is black.** The holders, inserts and mask print in black so stray light above the diffuser is absorbed, not bounced back into the film. An optional A5 black flocking sticker on the deck kills the last of the glare ([bom.md](bom.md)).

**Ambient light is tolerated, not sealed out.** The open front admits room light; the design answer is operational (dim room, no lamp aimed into the opening, camera at sync speed), because the pulse dwarfs what remains ([§8](#8-flash-operation)).

**No internal adjusters.** No reflector plates, no baffles, no levelling hardware anywhere in the light path: the cavity is bare white walls and nothing else. Every internal part would be one more thing to align and one more thing to knock out of place. Verify evenness with a [flat-field-corrected](glossary.md#flat-field-correction) test frame, which separates lens vignetting from real source unevenness ([assembly.md](assembly.md)).

---

## 4. Cover-stage

The cover-stage is the prototype's top cover and film stage merged into a single white plate: one printed part where there used to be a cover, a stage, three studs, six nuts and three heat-set inserts. It seats directly on the wall tops and carries everything optical above the cavity.

What the one part carries:

- **The plate**: 124.8 × 154.8, 10 overall, a 6 mm structural plate whose deck face lands at z = 79.0. Four corner notches, 2.8 deep, drop over the main body's 2.6 tenons with 0.2 of vertical clearance. The plate seats on the wall tops, never on the tenons; the tenons only pin it in XY.
- **The light window**: 62 × 95, centred, straight through the plate.
- **The acrylic recess**: 69 × 119, 2.4 deep, floor at 76.6, open to the deck. The opal sheet drops in from above and sits 0.4 below the deck ([§3](#3-optical-decisions)).
- **The tray**: a flange rim around a 94.6 × 120.6 seat, 4 high, top at 83.0. It locates the holder with 0.3 mm per side and its top face catches the film tail 0.2 below the film plane ([§5](#5-film-holders)).
- **The washer pockets**: four, 10.6 square and 1.0 deep, at (±41, ±12). A 10 × 10 × 1 steel washer (or a Ø10 × 1 disc) drops into each, flush with the deck: ferrous seats for the holder-base magnets, so the holder snaps down onto the tray and stays put. It is the same job the prototype's glued washers did, now without glue.

To move it, pinch the flange and lift; the whole cover-stage comes off the box in one piece.

**There is no levelling hardware, and that is the design, not an omission.** The prototype levelled its film stage against the box on three M6 studs; v1 deletes the studs, the nuts, the inserts and the procedure.

<details>
<summary>Why levelling moved to the camera end</summary>

Plastic never carries a thread in this design. FDM-printed threads are weak and creep under load; the prototype already avoided them with brass inserts and steel studs, and v1 removes the need for even those.

The deeper reason: the only parallelism that matters is **film plane to sensor**, and levelling the stage against the box never delivered that directly; after the prototype's three-nut ritual you still had to square the camera to the stage. v1 keeps only the step that matters. Lay a small mirror on the film stage, look through the viewfinder, and move the camera until the reflection of its own lens is centred: when it is, the sensor is parallel to the mirror, and therefore to the film plane the mirror is lying on ([assembly.md](assembly.md#step-7--level-at-the-camera-the-mirror-method)).

Because the mirror lies on the *result* of the whole printed stack (floor, walls, plate, holder), every print tolerance underneath it is absorbed in that single alignment. The box does not need to be flat to a target; the camera meets the film plane wherever it actually is.

</details>

---

## 5. Film holders

One holder set per format: a base and a lid, both 94 × 120, standing in the cover-stage tray. Changing format means lifting one set off and dropping the other in: the magnets release and re-seat in about five seconds, and nothing else moves. The film is advanced by pulling the strip through the closed holder; it is never opened mid-roll. A fourth set, for mounted 135 slides, is a single plate with no lid ([below](#mounted-slides-the-slide-plate)).

| Feature | 135 holder | 120 holder |
|---|---|---|
| Outline, base and lid | 94 × 120 | 94 × 120 |
| Base / lid thickness | 5 / 3 | 5 / 3 |
| [Window](glossary.md#window) (base, lid and insert) | 25 × 37 | 57 × 85 (covers 6×9) |
| Film guide width | 35.4 between the inner rails | 62.0 between the channel walls |
| Element ledge ([§ below](#the-flattening-system)) | 4.6 high, at x 31 – 32.2 | identical |
| Magnets Ø8 × 2 | 8 in the base + 8 in the lid | same |

**Windows are deliberately about 0.5 mm oversize per side** against the nominal frame (135 is nominally 24 × 36, 120 is nominally 56 × 84) to absorb camera-gate variance between bodies and printer XY tolerance. You crop to the frame in post; see [scanning.md](scanning.md#loading-film).

### The flattening system

The film plane is the top of the [land](glossary.md#land), a ledge framing the window **on all four sides**, at 4.2 above the base bottom. Film is 0.12 – 0.18 thick, so its top face lies at 4.32 – 4.38. The next 0.2-grid station above that is **4.6**, and 4.6 is exactly where the element ledge places the underside of whatever rests on it. Those three numbers are the whole system:

**land 4.2 → film top 4.32 – 4.38 → element underside 4.6.**

That makes a 0.4 mm channel over the land on all four sides of the window, and 0.22 – 0.28 mm of free lift for the film anywhere under the element. The element is whatever 64 × 95 × 2 plate you set on the ledge; that is what makes the system interchangeable:

- **Default: the printed pressure-window insert**, one per format. A hard ceiling all round the window perimeter holds lift to ≤ 0.28 there; over the open window the film is unconstrained, but at 1:1 and f/8 the depth of field is about ±0.4 mm, which covers the residual bow.
- **Upgrade: one anti-Newton glass, 64 × 95 × 2, shared by both formats.** A continuous ceiling over the full frame: ≤ 0.28 mm at any position. Its matte (AN) face goes down, against the glossy film base, so no [Newton rings](glossary.md#newton-rings) form; the emulsion faces the open window below and touches nothing.

**Why a single glass completes the sandwich:** a classical glass carrier needs two glasses because nothing else defines the bottom of the stack. Here the bottom is printed (the land frame supports the film on all four sides at 4.2), so one glass on top closes the sandwich, with half the glass surfaces to keep clean and no glass at all under the emulsion.

**Why one glass fits both formats:** both bases carry an identical outer-rail profile: the element ledge at x 31 – 32.2, 4.6 high, and an outer step at 32.2 – 33.5, 5.0 high, which locates the element sideways. The same 64 × 95 seat therefore exists in both. In the 135 base, the inner guide rails at ±17.7 – 19.7 that steer the narrow strip would foul a 64-wide plate, so their middle is omitted over |y| < 48, leaving 12 mm guide stubs at each end: the glass drops through the gap onto the ledge, and the stubs bracket it lengthwise.

The element is seated once and then never handled. Advancing film means gripping the leader where it protrudes from the holder and pulling; a bowed section is ironed flat as it slides under the element. The lid's cavity (64.8 × 96, ceiling at 7.0) captures the element with 0.4 of float: the lid locates it but never presses on it, so the element's height remains the ledge's printed 4.6, not a force fit. Loading advice: **glass mode, bow up** (the glass flattens it); **insert mode, bow down**. Film that leaves the holder drapes onto the tray flange, whose top sits 0.2 below the film plane: a support, not a pinch. Hand-support the tail of a long strip.

> [!CAUTION]
> **The glass underside sits 0.2 mm from the focal plane, so dust on it lands essentially in focus.** Blow both faces of the glass before seating it; it is the one surface in the box where dust images. The acrylic, by contrast, is self-forgiving ([§3](#3-optical-decisions)).

**Magnets.** Ø8 × 2 N35, press-fitted (no glue anywhere), 8 per part, 32 across both sets. The base magnets stand 0.4 proud of the plate face; the lid magnets sit flush with the lid underside; closed, the faces are 0.8 apart and **never touch**, so the lid always seats on the printed rail tops and the channel height stays a printed number, not a magnet stack-up. Polarity must be paired so that every base–lid position attracts: check each magnet against its mate before pressing it home; a press-fitted magnet does not come back out.

**6×6 and 6×4.5.** For 6×6, lay `mask-6x6.stl` (94 × 80 × 1, window 56.5 × 56.5) in the tray *under* the 120 base: the whole set rides 1 mm higher, which is normal; refocus and carry on. 6×4.5 has no dedicated mask; crop in post.

### Mounted slides: the slide plate

A slide in its mount is about 1.2 – 3.2 mm thick, many times the 0.4 mm channel, so it can never enter the 135 holder; and cutting a pocket for it into the 135 base would remove the land that supports the strip ([design log entry 25](design-log.md#25-mounted-slides-a-plate-of-their-own)). Instead `slide-plate-135.stl` is a fourth holder set in one piece: a 94 × 120 × 5 black plate that stands in the tray in place of the 135 set. It has no lid, no magnets and no pressure element: a mount is rigid and the box is horizontal, so the pocket locates the mount and gravity holds it.

| Feature | Slide plate |
|---|---|
| Outline and thickness | 94 × 120 × 5, the same seat in the tray as a holder base |
| Pocket | 51.4 × 51.4, 2.0 deep; floor at 3.0 above the plate bottom (z = 82.0) |
| Window | 26 × 38, through the pocket floor |
| Finger wells | two, 18 × 12, centred on the pocket's short sides; floor at 1.0, blind |
| Film plane | pocket floor plus about half the mount's thickness: roughly 82.6 (card mounts) to 83.6 (glass mounts); refocus |

**Why 51.4:** mounts are nominally 50 × 50, but card mounts run up to 50.8 (2 inch), so 51.4 leaves 0.3 mm per side on the largest mount and 0.7 on a plastic one: the same clearance the holder bases have in the tray. **Why 2.0 deep:** the thinnest card mount, about 1.2, is still captured by the pocket walls, and the thickest glass mount, about 3.2, stands 1.2 proud, where nothing sits above it to object. **Why 26 × 38, not 25 × 37:** the mount can float up to 0.7 mm in the pocket, and with 1 mm of margin per side against the nominal 24 × 36 frame it is always the mount's own aperture, never the printed edge, that frames the image; every mount still overlaps the window by more than 5 mm on every side, so nothing leaks. **The finger wells** let a fingernail under the edge of a card mount that sits 0.8 below the pocket rim; they are blind, 2.0 below the pocket floor, so they pass no light.

A mount is loaded the way you would hold it up to a window: image reading correctly from above, which puts the emulsion down, the same rule as for strips. A warped card mount or a popped frame is not flattened by anything here, exactly as in a dedicated slide scanner; at 1:1 and f/8 the roughly ±0.4 mm depth of field absorbs most of it.

---

## 6. Enclosure

**Main body** is one printed piece: a 3.0 floor, three 2.4 walls (left, right, rear), and no front wall at all. Four locating tenons, 2.4 × 12 × 2.6, stand on the side-wall tops and engage the cover-stage's corner notches.

**What the open front deleted.** The prototype needed an access panel because the flash's power dial lived inside a sealed box, a cable gland because wires had to cross a light-tight wall, and a ventilation answer because heat had nowhere to go. In v1 there is nothing inside to reach: flash, receiver and their batteries all sit on the desk, a power change is a fingertip away, the focus light's cable simply walks out through the opening, and the cavity is open air. All three problems left with the front wall.

**No screws, no glue, no tools.** No thread engages plastic anywhere in the design. Every joint is a tenon in a notch, gravity, or a magnet: the cover-stage locates on tenons and holds by weight, the holder holds by magnets on washers, the lid by magnets on the base, the element by gravity in its ledge. The magnets press-fit; the washers drop in loose. Assembly is stacking, in order, and is over in minutes ([assembly.md](assembly.md)).

> [!NOTE]
> **The fastener inventory of the entire build is: zero screws, zero adhesive.** Even the prototype's two glue points (holder magnets and steel washers) are gone: v1's magnets are interference-fitted and its washers sit in pockets.

> [!WARNING]
> **A gravity stack must not be carried tilted.** Assembled, the box is aligned, not attached: move it flat across the desk, or move the pieces separately; the cover-stage lifts off by its flange in one motion.

### Feature location schedule

XY from the centre of the box; z from the desk. Read from `cad/neobox.blend`.

| Feature | XY | z | Size |
|---|---|---|---|
| Open front | front face | 3.0 – 73.0 | full cavity cross-section, 120 × 70 |
| Locating tenons, 4 | side-wall tops | 73.0 – 75.6 | 2.4 × 12 × 2.6 |
| Corner notches, 4 | cover-stage underside | 2.8 deep | 0.2 vertical clearance over the tenons |
| Light window | centred | through the plate, 73.0 – 79.0 | 62 × 95 |
| Acrylic recess | centred | floor 76.6, open to the deck at 79.0 | 69 × 119, 2.4 deep |
| Washer pockets, 4 | (±41, ±12) | 78.0 – 79.0 | 10.6 square, 1.0 deep |
| Tray flange | around the 94.6 × 120.6 seat | 79.0 – 83.0 | rim, 4 high |

> [!TIP]
> The tenon-and-notch fit is sized inside normal FDM error: elephant foot, XY expansion and warp all eat into it. If the cover-stage binds or rattles, the remedy is a slicer setting, not a file edit; see [printing.md](printing.md#if-it-came-out-tight-or-loose).

---

## 7. Focus light

There is no built-in focus light, and nothing electrical lives inside the enclosure. Frame and focus with ordinary room light: a dim room shows plenty of film detail, any lamp works as long as it does not shine straight into the open front, and at capture the flash overwhelms whatever the room contributes.

---

## 8. Flash operation

Manual power only, normal sync, shoot [raw](glossary.md#raw). [TTL](glossary.md#ttl) metering is useless here (the scene never changes, so power is set once, manually), and [HSS](glossary.md#hss) solves a problem that does not exist at or below [sync speed](glossary.md#sync-speed). Do not pay for either.

**The pulse is the exposure.** Even with the open front, in a dim room the ambient light a sync-speed exposure collects is negligible next to the pulse, so the flash's own duration acts as the effective shutter, orders of magnitude shorter than any tripod-safe continuous-light exposure. Vibration, shutter shock and floor rumble stop mattering.

**Shutter speed: 1/125 s is the recommendation.** Focal-plane shutters typically sync at 1/160 – 1/250, and a cheap 2.4 GHz trigger's latency costs about one stop of that; hence 1/125. The symptom of pushing past the real limit is unmistakable: a clean-edged dark band across the frame.

> [!IMPORTANT]
> **An electronic shutter will usually not fire a flash at all.** If nothing happens when you press the button, that is the first thing to check. Details in [scanning.md](scanning.md#exposure).

Power changes are a fingertip away: the flash is on the desk in front of you, nothing to open, nothing to disturb. The receiver sits beside it, outside the box, where its radio path is clean and a battery swap touches nothing. In practice power is set once, from a test frame, and left alone; exposure procedure is in [scanning.md](scanning.md#exposure).

---

## 9. Repositioning and repeatability

The film plane is fixed at z = 83.2 for **both** strip formats (the 6×6 mask lifts the 120 set by 1 mm; the slide plate and the sheet plate put their film within a millimetre of it; refocus, nothing else changes). What changes between 135 and 120 is the magnification you need, and therefore the camera height, not the height of the film. Work the camera height out from the film plane plus your lens's [working distance](glossary.md#working-distance); the arithmetic is in [scanning.md](scanning.md#camera-height-and-the-stand).

**Parallelism is one alignment: the mirror method.** Lay a small mirror on the film stage and centre the reflection of your own lens in the viewfinder: the sensor is then parallel to the film plane, and every print tolerance in the stack below has been absorbed in the same move ([assembly.md](assembly.md#step-7--level-at-the-camera-the-mirror-method), and the reasoning in [§4](#4-cover-stage)). This is why the box carries no levelling hardware at all.

Once the camera is set, the box is what moves: slide it on the desk to centre the frame rather than re-aiming the camera; the flash just gets nudged back against the opening. When you are satisfied, make the position repeatable (two locating pins on the baseboard or a pencil outline of the footprint, either works) and write down the column height you used for each format.

**Parallelism first, evenness second.** A flash freezes vibration; it cannot fix a film plane that is not parallel to the sensor. Mirror method first, then a [flat-field-corrected](glossary.md#flat-field-correction) test frame to check evenness.

---

## 10. 4×5 on the v1 body

4×5 rides on the unchanged main body with two optional parts and one larger acrylic: `cover-stage-4x5.stl` replaces the cover-stage, `sheet-plate-4x5.stl` stands in its tray, and a 106 × 130 × 2 opal sheet lies in its recess. Nothing else changes: the same tenons, the same flash at the same open front, the same gravity stack, the same 160 × 160 bed.

| Feature | 4×5 cover-stage | v1 cover-stage |
|---|---|---|
| Outline, plate, notches | 124.8 × 154.8, 6 mm plate, four notches over the tenons | identical |
| Light window | 102 × 126 | 62 × 95 |
| Acrylic recess | 107 × 131, floor at 3.6, for a 106 × 130 × 2 sheet | 69 × 119, for 68 × 118 × 2 |
| Tray inside the flange | 112.6 × 138.6, flange 4 wide, top at 10.0 | 94.6 × 120.6, flange 7 wide |
| Washer pockets | none: the sheet plate has no magnets | four |
| Mixing margin, window edge to wall | 9 in x, 12 in y | 29 in x, 27.5 in y |

| Feature | Sheet plate |
|---|---|
| Outline and thickness | 112 × 138 × 5, standing on the deck inside the 4×5 flange |
| Pocket | 102.2 × 127.6, 2.0 deep; floor at 3.0 above the plate bottom (z = 82.0) |
| Window | 97 × 121, through the pocket floor: the 96 × 120 image area plus the usual 0.5 per side |
| Edge notches | two, 18 wide, on the short sides, running from 3.7 under the sheet edge out through the plate edge; floor at 1.0 |
| Film plane | the sheet lies on the pocket floor: about 82.2 |

**Why the sheet needs no pressure element.** 4×5 on full frame is about 0.25×, and at f/8 the depth of field is then roughly 8 – 10 mm, ten times the 135 case. A sheet's own curl, a millimetre or two, is invisible at that scale, so the plate is a pocket with a land under the sheet edges and nothing on top: no lid, no glass, no magnets. Sheets load one at a time, image reading correctly from above (emulsion down), and lift out by the edge notches.

**What is not known: evenness.** The v1 window sits 29 and 27.5 mm from the walls; the 4×5 window sits 9 and 12. No minimum margin has ever been established and nothing has been measured, so the 4×5 stage is published as an experiment on the same body, not as a figure. Shoot one blank frame first: if it shows a gradient you will not accept, flat-field correction in post is the first remedy ([scanning.md](scanning.md#flat-field-and-inversion)) and a bigger box the second.

<details>
<summary>The bigger-box route, if the margins prove too small</summary>

Derive a bigger box, not a different kind of box: keep the 102 × 126 window and give it v1's margins, which makes the cavity 160 × 181 inside and the main body about 164.8 × 185.8 outside, past a 160 × 160 bed and onto a 220-class one, with the cover-stage, tray, sheet plate and acrylic scaled to match. The open-front architecture, the screwless gravity stack and the layer grid carry over unchanged. The flash may not need to grow: the larger window costs about 1.2 stops, and the drop from 1:1 to 0.25× gives back about 1.3, though that too is unmeasured.
</details>

---

## 11. Working with the source

`cad/neobox.blend` is the only source of geometry in this repository. The twelve STL files are generated from it, and a change that reaches the STLs without going through the blend file is lost the next time anyone re-exports.

### Opening the file

| Property | Value |
|---|---|
| Blender version | **3.0 or newer.** The file is Zstandard-compressed, which pre-3.0 Blender cannot read at all. The file header records **Blender 5.2** as the version it was last saved with |
| Unit system | Metric, unit scale 0.001, length unit millimetres: **one Blender unit is one millimetre** |
| Scene layout | The assembly is modelled in place, on the same z datum this document uses: the desk (the outer bottom of the box) is z = 0. The 120 holder set is parked beside the assembly at x = 200, the 6×6 mask at x = 350, the slide plate at x = 500 and the 4×5 stage at x = 650 |

### The collection tree

```
Scene Collection
├── mock_view-target        an empty, used as a view target
├── Scaffolding             Camera, Light: render scaffolding
├── NeoBox_v1               the enclosure, the cover-stage and the mock-ups
├── Holder_135              the 135 holder set, assembled in place
├── Holder_120              the 120 holder set, parked at x = 200
├── Masks                   the 6×6 mask, parked at x = 350
├── Holder_slide            the slide plate and its mount mock-up, parked at x = 500
└── Stage_4x5               the 4×5 cover-stage and sheet plate with their mock-ups, parked at x = 650
```

### Which objects make each STL

| STL file | Blender object(s) | Gloss |
|---|---|---|
| `main-body.stl` | `main-body_floor`, `main-body_wall-left`, `main-body_wall-right`, `main-body_wall-rear` | **four objects**: floor, left wall, right wall, rear wall; the open front needs no lintel or posts |
| `cover-stage.stl` | `cover-stage` | cover-stage, one piece, window 62 × 95 |
| `film-holder-135-base.stl` | `film-holder-135-base` | 135 holder base, flat-bottomed |
| `film-holder-135-lid.stl` | `film-holder-135-lid` | 135 holder lid |
| `film-holder-120-base.stl` | `film-holder-120-base` | 120 holder base, flat-bottomed |
| `film-holder-120-lid.stl` | `film-holder-120-lid` | 120 holder lid |
| `pressure-window-135.stl` | `pressure-window-135` | pressure-window insert, 135 |
| `pressure-window-120.stl` | `pressure-window-120` | pressure-window insert, 120 |
| `mask-6x6.stl` | `mask-6x6` | 6×6 mask |
| `slide-plate-135.stl` | `slide-plate-135` | slide plate, one piece |
| `cover-stage-4x5.stl` | `cover-stage-4x5` | 4×5 cover-stage, one piece |
| `sheet-plate-4x5.stl` | `sheet-plate-4x5` | 4×5 sheet plate, one piece |

### What is a mock-up and must never be exported

**The name says whether an object is printed.** A printed part carries the name of the STL file it becomes: `cover-stage` is the object that becomes `cover-stage.stl`, and the main body is the four shells sharing the `main-body_` prefix. Everything else in the scene is a mock-up, there to show fit and light path, and takes the `mock_` prefix instead; none of it is printed or exported: the flash body and its emitting face (`mock_flash-body`, `mock_flash-face`), the T1 receiver (`mock_trigger-receiver`), the four light-path arrows (`mock_ray-1-into-cavity` to `mock_ray-4-through-window`), the 135 and 120 film-strip mock-ups (`mock_film-135`, `mock_film-120`), a 50 × 50 × 2 slide mount (`mock_slide-mount-50x50x2`), a 4×5 sheet (`mock_film-4x5`), the two opal acrylics (`mock_diffuser-68x118x2`, `mock_diffuser-106x130x2`), the AN glass (`mock_an-glass-64x95x2`), the four steel washers (`mock_steel-shim-1` to `mock_steel-shim-4`), a text label (`mock_label`), and the view target (`mock_view-target`). `Camera` and `Light` carry no prefix and need none: neither is a mesh, so neither can reach an STL.

The convention is a gate, not a habit. `tools/export_stl.py` fails the whole export when it finds a mesh object that is neither listed in its `MAPPING` table, reproduced above, nor prefixed `mock_`. A printed part added to the scene and forgotten in that table therefore stops the export instead of quietly dropping out of the release.

> [!CAUTION]
> **Material names do not tell you the filament colour.** The eight materials (`NB_white`, `NB_black`, `NB_steel`, `NB_opal`, `NB_film`, `NB_glow`, `NB_ray`, `NB_receiver`) exist for the renders, and each is named for what it is applied to rather than for anything you load into the printer: `NB_black`, for one, covers every black printed part and three mock-ups, the flash body, the label and the slide mount. The prototype-era materials have been deleted, so nothing misleading survives in the list, but colours still come from [printing.md](printing.md#the-twelve-parts), never from the material slot.

### The export convention

Every STL is exported **in assembly world space**: nothing is re-zeroed or re-oriented on the way out.

| File | Where it sits inside the exported file |
|---|---|
| `main-body.stl` | z 0 – 75.6, centred on XY |
| `cover-stage.stl` | z 73 – 83, centred on XY |
| `film-holder-135-base.stl` / `-lid.stl` | z 79 – 84 / 84 – 87, in place on the assembly |
| `pressure-window-135.stl` | z 83.6 – 85.6, in place |
| `film-holder-120-base.stl` / `-lid.stl` | parked at x 153 – 247, z 0 – 5 / 5 – 8 |
| `pressure-window-120.stl` | parked at x 168 – 232, z 4.6 – 6.6 |
| `mask-6x6.stl` | parked at x 303 – 397, z 0 – 1 |
| `slide-plate-135.stl` | parked at x 453 – 547, z 0 – 5 |
| `cover-stage-4x5.stl` | parked at x 587.6 – 712.4, z 0 – 10 |
| `sheet-plate-4x5.stl` | parked at x 594 – 706, z 6 – 11, standing on the 4×5 cover-stage's deck |

A slicer drops each file onto the build plate by its bounding box. Ten of the twelve files arrive lying on their print face already; the two holder lids do not: they print **top face down** and have to be flipped after import. The required rotation is on each part card in [printing.md](printing.md#the-twelve-parts).

### Re-exporting

One command regenerates all twelve files. It is the committed form of the pipeline that produced the published STLs, and it is the only supported way to export:

```
blender --background cad/neobox.blend --python tools/export_stl.py
```

(`blender` is the binary inside your Blender installation; any 4.x/5.x build works. Run it from the repository root, then `python3 tools/verify_stl.py`.)

The script matters because the printable parts are **modelled as overlapping shells**, interpenetrating by 0.2 – 0.5 mm on purpose: the walls sink into the floor, the flange into the cover-stage plate, the rails into the holder bases. That keeps the source parametric and easy to edit. For every output file the script copies the source objects, splits them into shells, boolean-unions the shells into one solid (EXACT solver), welds away the boolean slivers, checks the result is watertight, and exports it in assembly world space; the scene itself is never touched. A naive File → Export → STL of the raw objects produces multi-shell files whose internal faces fail the verifier's layer-grid check.

Regenerated files may differ from the published ones **byte for byte** (triangulation is not stable across Blender versions) while being geometrically identical. The verifier is the referee: bounding box, watertightness, layer grid and minimum step must all pass.

<details>
<summary>Manual export, if you cannot run the script</summary>

1. **Select the objects** for one output file, using the mapping table above. *Checkpoint:* the number of selected objects matches the table: four for the main body, one for everything else.
2. **Make it one solid: every part, not just the main body.** Single-object parts can still be multi-shell inside. Join what needs joining, separate by loose parts, boolean-union the shells, then merge vertices by distance (0.02 mm) and run a limited dissolve (1°) to remove the boolean slivers. *Checkpoint:* the part is one connected shell and the verify script reports no non-manifold edges.
3. **Export.** File → Export → STL, with *Selection Only*, scale 1.00, forward Y, up Z. No axis conversion: the numbers in the file must be the numbers in Blender. *Checkpoint:* re-importing the file puts the part back exactly where it was.
4. **Write it to the same path** under `stl/white-pla/` or `stl/black-pla/`, keeping the filename. *Checkpoint:* `git status` shows a modified file, not a new one.
5. **Verify** before you commit anything. *Checkpoint:* `python3 tools/verify_stl.py` prints `all 12 files pass` and exits 0.

</details>

```mermaid
flowchart LR
  A[Edit cad/neobox.blend] --> B[Export the affected STLs]
  B --> C[python3 tools/verify_stl.py]
  C -->|all 12 files pass| D[Update the docs in all three languages]
  C -->|any FAIL| A
  D --> E[Commit blend, STLs and docs together]
```

### Running the verifier

`tools/verify_stl.py` is plain Python 3 with no dependencies. Run it from the repository root:

```
python3 tools/verify_stl.py
```

It walks every `.stl` under `stl/` and checks four invariants per file:

| Check | What it enforces |
|---|---|
| watertight | Every edge is shared by exactly two triangles: a closed solid, no holes |
| layer grid | Every horizontal face sits on a 0.2 mm multiple above that part's own base |
| minimum step | No exposed horizontal step below 0.4 mm, which is two layers at 0.2 |
| bounding box | The part still measures what the documentation says it measures |

Horizontal faces smaller than 1 mm² are ignored when hunting for steps, so modelling slivers do not raise false alarms. Output is one line per file plus a total, and the exit status is non-zero if anything fails, so the script can gate a commit:

```
ok    film-holder-120-base.stl  [94.0, 120.0, 5.0]  256 triangles
...
all 12 files pass
```

The published bounding boxes live in the `EXPECTED` table at the top of the script, sorted largest first. **If you change a published dimension on purpose, edit `EXPECTED` in the same commit**; otherwise the check fails on the part you meant to change and quietly passes on the part you did not.

### Changing the flash

In the prototype era this heading introduced a re-derivation checklist. In v1 there is nothing to change: **no dimension of the box encodes the flash**, so a different flash (or a different trigger) touches neither `cad/neobox.blend` nor the STLs. The new flash needs manual power control and a head that can lie flat and fire level into the open front; after swapping, redo the metering test frame and carry on ([§8](#8-flash-operation)).

### Other files in `cad/`

- `film-stage-aluminium-3mm.dxf`: the prototype's aluminium film stage, kept for history only. v1 has no film stage: the part was merged into the cover-stage, and nothing in the current design is cut from this file.
- `legacy-plywood/`: DXFs from the plywood revision, kept for history only. Between them the two files do not describe a complete shell, and nothing in the current design is cut from them.

Contribution rules (what is source, what is generated, and the three-language requirement) are in [CONTRIBUTING.md](../CONTRIBUTING.md#source-of-truth-vs-generated-files).

---

← [Glossary](glossary.md) · [Documentation index](../README.md#documentation) · [Design log](design-log.md) →

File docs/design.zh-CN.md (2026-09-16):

# 设计

[English](design.md) · **简体中文** · [日本語](design.ja.md)

> 工程参考：每一个尺寸从哪里来，哪些数字是光学的、哪些是结构的，改动其中一个会发生什么，以及怎么打开、修改、重新导出并校验 CAD 源文件。

**目录：**[1. 光路](#1-光路) · [2. 尺寸链](#2-尺寸链) · [3. 光学决策](#3-光学决策) · [4. 顶盖台](#4-顶盖台) · [5. 胶片夹](#5-胶片夹) · [6. 壳体](#6-壳体) · [7. 对焦灯](#7-对焦灯) · [8. 闪光灯用法](#8-闪光灯用法) · [9. 复位与重复性](#9-复位与重复性) · [10. 4×5 装在 v1 主箱上](#10-45-装在-v1-主箱上) · [11. 使用源文件](#11-使用源文件)

参考闪光灯：一只 **NEEWER TT560** 机顶闪，配一套 **ZENIKO T1** 2.4 GHz 触发器，只是参考，不是前提。闪光灯平躺在箱**外**的桌面上，本文没有任何一个尺寸依赖于它；任何能手动调出力的机顶闪都可以用。

| 约定 | 在本文里的含义 |
|---|---|
| 尺寸 | 单位毫米，一律写成 宽 × 深 × 高（X × Y × Z） |
| `z` | 从桌面起算的绝对高度。箱子直接立在桌面上，所以这也是从主箱外底面起算的高度 |
| 零件自身 z | [§2](#2-尺寸链) 的层高量化表按每个零件自己的打印底面起算，用到的地方会注明 |
| XY 坐标 | 从箱体中心起算，箱体中心也就是透光窗中心 |
| STL 包围盒 | 只在明确写了「STL 包围盒」的地方才是这个含义：它按数值从大到小排序，往往不是 X × Y × Z 的顺序 |
| 数据来源 | 下文每一个数字都读自 `cad/neobox.blend` 或导出的 STL 文件。[§11](#11-使用源文件) 讲了怎么自己去读 |

> [!IMPORTANT]
> 几何在 Blender 里做过尺寸核对，导出的 STL 文件也做过数值校验。**这只箱子从未被打印、装配、拍照或实测过。** 本文里所有性能数字都是设计目标，不是结果：混光余量、≤ 0.28 mm 的压平上限、景深覆盖，全部如此。均匀度没有实测过，本文也没有任何地方声称测过。

---

## 1. 光路

NeoBox 剖视图

自桌面向上的叠层：

**闪光灯平躺在桌面 → 完全敞开的前口 → 白色混光腔 120 × 150 × 70 → 顶盖台上的透光窗 62 × 95 → 乳白亚克力 68 × 118 × 2，顶面在 78.6 → 4.6 mm 空气 → 胶片面 z = 83.2。**

闪光灯不在箱子里。它平躺在与箱子同一张桌面上，灯头怼着**敞开前口**（箱体前面根本没有墙），水平向腔内发光。TT560 的发光面是 60 × 45，中心离桌面 31 mm，稳稳落在 70 mm 高的箱口范围之内。

**没有任何光是对着胶片打的。** 透光窗开在混光腔的顶上，与光束成直角，光要在裸白 PLA 壁面上漫反射好几次才走得到窗口。正是这一点让箱子内部成为一个[混光腔](glossary.zh-CN.md#混光腔)（integrating cavity），而不是一盏带灯罩的灯。光从 62 × 95 的窗口射出，再由嵌在顶盖台里的那块[乳白](glossary.zh-CN.md#乳白)（opal）亚克力完成最后一道柔化。

敞开前口就是 v1 的全部架构变化。打印过的原型机（内部第 4 版）把闪光灯封在箱内，它的一切麻烦都由此而来：箱体高度要从灯体厚度推导、要开抽口才够得着出力拨盘、要留过线孔穿线，发布的 STL 也只适配一款闪光灯。灯一出箱，这些全部消失：任何品牌的闪光灯都能用，接收器留在桌面上，信号干净、换电池不碰箱子，抽口、盖板、过线孔和通风问题都不复存在（[§6](#6-壳体)）。代价是环境光可以进入混光腔。这个交换是算过账的，不是装看不见：在同步速度下，闪光脉冲远比室内环境光亮（[§8](#8-闪光灯用法)）。

> [!NOTE]
> **在昏暗的房间里拍摄，并且别让顶灯直射箱口。** 脉冲压过环境光是设计前提，但一盏正对敞开前口的亮灯，是唯一能白白吃掉这个余量的摆法。

---

## 2. 尺寸链

原型机的箱子是从闪光灯推导出来的，那些数字也随它一起作废了。v1 切断了这条线：闪光灯根本不进箱，尺寸链不再从某款产品的规格表开始，而是从桌面开始，一件叠一件，靠重力向上生长。

### 打印件

十二个 STL 文件，白色三件、黑色九件，全部免支撑：

| STL | 颜色 | 外形 (mm) | 内容 |
|---|---|---|---|
| `main-body.stl` | 白 | 124.8 × 154.8 × 75.6 | 主箱：底 3.0，左右后三壁 2.4，前面全开；侧壁顶四个定位榫 2.4 × 12 × 2.6 |
| `cover-stage.stl` | 白 | 124.8 × 154.8 × 10.0 | 顶盖台：6 mm 板搁在箱壁上，带透光窗、亚克力暗槽、垫片沉孔和夹座托盘（[§4](#4-顶盖台)） |
| `film-holder-135-base.stl` | 黑 | 94 × 120 × 5 | 135 夹底座：开窗 25 × 37，内侧导轨，外轨带 4.6 元件台阶（[§5](#5-胶片夹)） |
| `film-holder-135-lid.stl` | 黑 | 94 × 120 × 3 | 135 夹上盖：开窗 25 × 37，元件限位腔，8 个磁孔 |
| `film-holder-120-base.stl` | 黑 | 94 × 120 × 5 | 120 夹底座：开窗 57 × 85（整格 6×9），通道宽 62，外轨与台阶和 135 完全相同 |
| `film-holder-120-lid.stl` | 黑 | 94 × 120 × 3 | 120 夹上盖：开窗 57 × 85，其余与 135 上盖一样 |
| `pressure-window-135.stl` | 黑 | 64 × 95 × 2 | 135 压片窗插片（窗 25 × 37） |
| `pressure-window-120.stl` | 黑 | 64 × 95 × 2 | 120 压片窗插片（窗 57 × 85） |
| `mask-6x6.stl` | 黑 | 94 × 80 × 1 | 6×6 遮幅插片（窗 56.5 × 56.5），垫在托盘里 120 底座下方 |
| `slide-plate-135.stl` | 黑 | 94 × 120 × 5 | 装框 135 幻灯片用的幻灯片板：51.4 × 51.4 方槽、26 × 38 开窗、两个指槽；独立的第四副夹子，只有一件（[§5](#5-胶片夹)） |
| `cover-stage-4x5.stl` | 白 | 124.8 × 154.8 × 10.0 | 4×5 顶盖台：沿用顶盖台的外形、板身和四个榫槽，透光窗改为 102 × 126、亚克力暗槽 107 × 131、托盘 112.6 × 138.6；没有垫片沉孔（[§10](#10-45-装在-v1-主箱上)） |
| `sheet-plate-4x5.stl` | 黑 | 112 × 138 × 5 | 4×5 片板：102.2 × 127.6 片槽、97 × 121 开窗、两个边缺口；立在 4×5 顶盖台的托盘里 |

每个零件都是平的那一面朝下打印；两个上盖**顶面朝下**。最大件长 154.8 mm，160 × 160 的打印床就够。层高、摆放方向和切片参数见[打印文档](printing.zh-CN.md)。

### 高度

整个装配就是一摞重力堆叠。世界坐标 z，桌面 = 0：

| 层 | z 范围 | 说明 |
|---|---|---|
| 桌面 | 0 | 闪光灯和箱子立在同一张桌面上 |
| 主箱底板 | 0 – 3.0 | |
| 混光腔 | 3.0 – 73.0 | 内腔 120 × 150 × 70，前面敞开 |
| 顶盖台板 | 73.0 – 79.0 | 6 mm 板搁在壁顶上，台面在 79.0 |
| 乳白亚克力 | 76.6 – 78.6 | 嵌在暗槽里，顶面比台面低 0.4 |
| 钢垫片 | 78.0 – 79.0 | 落在沉孔里，与台面齐平 |
| 托盘凸缘 | 79.0 – 83.0 | 围着夹座的一圈边，高 4 |
| 夹底座 | 79.0 – 84.0 | 立在凸缘围出的台面上；幻灯片板占的也是这 5 mm |
| **胶片面** | **83.2** | 承台顶面，两种画幅同一高度 |
| 幻灯片的胶片面 | ≈ 82.6 – 83.6 | 在幻灯片板里：槽底 82.0 加上框厚的一半左右；重新对焦 |
| 4×5 的胶片面 | ≈ 82.2 | 页片平躺在片板槽底 82.0 上；重新对焦 |
| 压片元件 | 83.6 – 85.6 | 插片或防牛顿环玻璃，搁在 4.6 台阶上 |
| 夹上盖 | 84.0 – 87.0 | 装配总高 87 |

### 宽度与深度

主箱外形 124.8 × 154.8；壁厚 2.4，前面敞开，所以内腔是 **120 × 150 × 70**，敞开前口就是内腔完整的 120 × 70 截面。62 × 95 的透光窗居中，窗口边缘到最近箱壁的白壁余量是 **x 方向 29 mm、y 方向 27.5 mm**，这就是混光余量。它是刻意留得宽裕的设计余量；下限没有确定过，也没有任何实测。

### 换用其他闪光灯

没有任何东西需要重新推导。原型机那套把闪光灯规格表换算成箱体高度的公式没有了，因为输入本身没有了：**v1 箱体的任何尺寸都不编码任何闪光灯的任何尺寸。** 替代的闪光灯只需要能手动调出力、灯头能平躺着水平对准敞开前口。TT560 的发光面 60 × 45、中心离桌 31，是参考，不是限制。接收器同样在箱外，触发器的型号也同样自由。换闪光灯既不用动 `cad/neobox.blend`，也不用动 STL（[§11](#11-使用源文件)）。

### 层高量化

**这个设计里每一个打印出来的 z 向特征都是 0.2 mm 的整数倍，暴露的水平台阶一律不低于 0.4 mm（两层）。** 每个零件按自己的打印方向量化，从自己的打印底面起算：

| 零件（基准 = 打印底面） | z 特征位 |
|---|---|
| 主箱 | 0 · 3.0 底板顶 · 73.0 壁顶 · 75.6 榫顶 |
| 顶盖台 | 0 · 2.8 榫槽顶 · 3.6 亚克力槽底 · 5.0 垫片孔底 · 6.0 台面 · 10.0 凸缘顶 |
| 夹底座（两幅面同） | 0 · 2.2 磁孔底 · 3.8 板面 · **4.2 承台** · **4.6 元件台阶** · 5.0 导轨顶 |
| 夹上盖（顶面朝下打印） | 0 · 1.0 限位腔顶 · 3.0 盖底（装配坐标 8.0 / 7.0 / 5.0） |
| 插片／遮幅片 | 平板，2.0 ／ 1.0 |
| 幻灯片板 | 0 · 1.0 指槽底 · 3.0 槽底 · 5.0 顶面 |
| 4×5 顶盖台 | 0 · 2.8 榫槽顶 · 3.6 亚克力槽底 · 6.0 台面 · 10.0 凸缘顶 |
| 片板 | 0 · 1.0 缺口底 · 3.0 槽底 · 5.0 顶面 |

这张网格的意义：在 0.2 mm [层高](glossary.zh-CN.md#层高)下，上面每一个特征位都正好落在层边界上，打印出来的 0.4 台阶就是真正的 0.4，而不是切片软件四舍五入的产物。0.1 mm 也整除这张网格；0.12 和 0.16 不整除。这套推理源自原型机的胶片夹，原样沿用（[设计日志第 18 条](design-log.zh-CN.md#18-夹子按层高量化)）；v1 的新意在于整个设计都服从它，而不只是夹子。下单打印规格是所有件一律 0.2（[打印文档](printing.zh-CN.md)）。校验脚本对每次导出都强制检查网格和最小台阶（[§11](#11-使用源文件)）。

---

## 3. 光学决策

**最后一道扩散层是一块嵌在顶盖台里的乳白板。** 亚克力（外购件，68 × 118 × 2）落进 69 × 119、深 2.4 的暗槽：四周各 0.5 mm 间隙，顶面比台面低 0.4。因为胶片夹立在台面上，**永远没有东西碰到亚克力**：它是光学层，不是结构层，胶片面的高度全程经由打印塑料传递，从不经过它。要取出来，掀掉夹子，从箱口伸手经透光窗向上一顶。

**亚克力上的灰尘不会成像。** 亚克力本身就是漫射发光面：落在它上面的颗粒是光源的一部分，不是挡在光源和镜头之间的物体，投不出轮廓。定期擦拭即可，不需要每次开工的仪式。（可选玻璃上的灰尘是完全相反的情况，见 [§5](#5-胶片夹)。）

**混光余量。** 窗到壁的余量（x 29、y 27.5）是决定腔体能不能把窗口照匀的数字。它们是刻意留宽的设计余量，没有确定过下限，也没有实测依据。

**腔内全白，而且只能哑光。** 白色 PLA 本身*就是*那层混光面。不要在内部涂装，白色件也不要用丝绸或高光耗材：镜面壁会把灯头复制成一个热点，而不是把它打散。

**亚克力以上的一切都是黑的。** 夹子、插片和遮幅片都用黑色打印，扩散层以上的杂光被吸收，而不是反弹回胶片。可选项：在台面贴一张 A5 黑色植绒贴，消掉最后一点眩光（[物料清单](bom.zh-CN.md)）。

**环境光是被容忍的，不是被封死的。** 敞开前口会放进室内光；设计给出的答案是操作性的（昏暗房间、别让灯直射箱口、快门保持在同步速度），因为剩下那点环境光被脉冲远远压过（[§8](#8-闪光灯用法)）。

**没有任何内部调节件。** 光路里没有反射板、没有挡板、没有调平五金：混光腔就是四面裸白墙，别无他物。每多一个内部零件，就多一样要对齐、也多一样会被碰歪的东西。均匀度用一张做过[平场校正](glossary.zh-CN.md#平场校正)的测试片来验证，平场校正能把镜头暗角和光源本身的不均分开（[装配文档](assembly.zh-CN.md)）。

---

## 4. 顶盖台

顶盖台是原型机的顶盖和胶片台合并成的一块白色板：过去的一个盖、一块台、三根螺杆、六颗螺母、三颗热熔铜螺母，现在是一个打印件。它直接搁在箱壁顶上，承载混光腔以上的全部光学件。

这一个零件身上带着什么：

- **板体**：124.8 × 154.8，总高 10；结构板厚 6 mm，台面落在 z = 79.0。四角榫槽深 2.8，罩住主箱 2.6 高的定位榫，竖向留 0.2 间隙。板搁在壁顶上，永远不压在榫上；榫只负责 XY 定位。
- **透光窗**：62 × 95，居中，贯穿板体。
- **亚克力暗槽**：69 × 119，深 2.4，槽底在 76.6，向台面开口。乳白板从上方落入，顶面比台面低 0.4（[§3](#3-光学决策)）。
- **托盘**：围着 94.6 × 120.6 夹座的一圈凸缘，高 4，顶在 83.0。它给夹子留每边 0.3 mm 的定位间隙，顶面还在比胶片面低 0.2 处托住伸出的片尾（[§5](#5-胶片夹)）。
- **垫片沉孔**：四个，10.6 见方、深 1.0，位于 (±41, ±12)。每孔放入一片 10 × 10 × 1 钢垫片（或 Ø10 × 1 圆片），与台面齐平：给夹底座的磁铁当铁座，夹子啪地吸落在托盘上不再乱动，干的和原型机那四片粘上去的垫片是同一件事，只是不再用胶。

要挪动它，捏住凸缘一提，整个顶盖台一体离箱。

**没有调平五金，这是设计本身，不是缺漏。** 原型机用三根 M6 螺杆把胶片台对着箱体调平；v1 把螺杆、螺母、铜螺母连同那套流程一起删掉了。

<details>
<summary>为什么调平挪到了相机端</summary>

这个设计里塑料从不承担螺纹。FDM 打印的螺纹既弱又会蠕变；原型机已经在用铜螺母加钢螺杆回避它，v1 则连这些都不再需要。

更深一层的原因是：唯一要紧的平行度是**胶片面对传感器**，而对着箱体调平胶片台从来就没有直接给出过这件事；原型机拧完三颗螺母，还是得把相机对着台面摆正。v1 只保留了真正要紧的那一步。在胶片台上放一面小镜子，看着取景器移动相机，直到镜头自己的倒影居中：居中的那一刻，传感器就平行于镜面，也就平行于镜子所躺的胶片面（[装配文档的镜子法](assembly.zh-CN.md#第-7-步相机端调平镜子法)）。

因为镜子躺在整摞打印件的*最终结果*上（底板、箱壁、板体、夹子），它下面的所有打印公差都在这一次对齐里被吸收了。箱子不需要平到某个指标；相机会在胶片面实际所在的位置迎上去。

</details>

---

## 5. 胶片夹

每种画幅一副夹子：夹底座加夹上盖，都是 94 × 120，立在顶盖台的托盘里。换画幅就是掀走一副、放下另一副：磁吸松开再吸合，前后五秒，其余什么都不动。过片是把片条从合着的夹子里抽过去，整卷中途从不开夹。装框的 135 幻灯片另有第四副，只有一块板、没有上盖（[见下](#装框幻灯片幻灯片板)）。

| 特征 | 135 夹 | 120 夹 |
|---|---|---|
| 外形，两件相同 | 94 × 120 | 94 × 120 |
| 夹底座／夹上盖板厚 | 5 ／ 3 | 5 ／ 3 |
| [开窗](glossary.zh-CN.md#开窗)（底座、上盖与插片同窗） | 25 × 37 | 57 × 85（覆盖 6×9） |
| 走片宽度 | 内轨之间 35.4 | 通道壁之间 62.0 |
| 元件台阶（[见下](#压平系统)） | 高 4.6，位于 x 31 – 32.2 | 完全相同 |
| 磁铁 Ø8 × 2 | 底座 8 颗 + 上盖 8 颗 | 相同 |

**开窗每边刻意比标称画幅大出约 0.5 mm**（135 标称 24 × 36，120 标称 56 × 84），用来吸收不同机身片门的差异和打印机的 XY 公差。最终构图靠后期裁切，见[翻拍扫描的装片](scanning.zh-CN.md#装片)。

### 压平系统

胶片面就是[承台](glossary.zh-CN.md#承托)的顶面，一圈**四边环绕**开窗的窄台，在底座底面以上 4.2。胶片厚 0.12 – 0.18，顶面因此落在 4.32 – 4.38。再往上最近的 0.2 网格位是 **4.6**，而 4.6 恰好就是元件台阶托住任何搁在上面之物底面的高度。这三个数就是整套系统：

**承台 4.2 → 胶片顶 4.32 – 4.38 → 元件底 4.6。**

于是开窗四边的承台上方各有一条 0.4 mm 通道，元件之下的任何位置胶片都有 0.22 – 0.28 mm 的自由起伏量。元件就是你搁在台阶上的那块 64 × 95 × 2 的板，可互换性正来自于此：

- **默认：打印压片窗插片**，每幅面一片。窗口四周一圈硬限位，把边缘起伏压到 ≤ 0.28；开窗正上方胶片虽然无约束，但 1:1、f/8 时景深约 ±0.4 mm，足以覆盖残余的拱起。
- **升级：一片防牛顿环玻璃，64 × 95 × 2，两幅面通用。** 整幅画面连续封顶：任何位置 ≤ 0.28 mm。磨砂（AN）面朝下贴着光亮的片基，不起[牛顿环](glossary.zh-CN.md#牛顿环)；药膜面朝着下方敞开的窗口，不接触任何东西。

**为什么单片玻璃就能凑齐三明治：** 传统玻璃夹片器要两片玻璃，因为没有别的东西来定义叠层的底面。这里的底面是打印出来的（承台在 4.2 处从四边托住胶片），所以顶上加一片玻璃就把三明治合上了：要保持干净的玻璃面少了一半，药膜下方更是一片玻璃都没有。

**为什么一片玻璃能通吃两种画幅：** 两个底座的外轨轮廓完全相同：元件台阶在 x 31 – 32.2、高 4.6，外档在 32.2 – 33.5、高 5.0，负责元件的横向定位。同一个 64 × 95 的座在两个底座里都存在。135 底座上，引导窄片条的内轨（±17.7 – 19.7）会顶住 64 宽的板，所以内轨在 |y| < 48 的中段整个断开，只在两端各留 12 mm 导向段：玻璃从缺口落到台阶上，导向段顺势在长度方向上把它框住。

元件放进去一次，之后就不再碰。过片是捏住伸出夹外的片头直接抽拉；拱起的部位滑过元件底面时被顺势压平。上盖的限位腔（64.8 × 96，顶在 7.0）以 0.4 的浮动余量罩住元件：上盖给它定位，却从不压它，元件的高度始终是台阶打印出来的 4.6，不是压出来的配合。装片方向建议：**玻璃模式拱面朝上**（让玻璃把它压平）；**插片模式拱面朝下**。伸出夹外的胶片搭在托盘凸缘上，凸缘顶比胶片面低 0.2：是托，不是夹；长片条请用手托住尾端。

> [!CAUTION]
> **玻璃底面离焦平面只有 0.2 mm，落在上面的灰尘几乎就在焦点上。** 装玻璃之前把两面都用气吹吹净：这是箱子里唯一会让灰尘成像的表面。亚克力则恰恰相反，天生免疫（[§3](#3-光学决策)）。

**磁铁。** Ø8 × 2 N35，过盈压入（全程无胶），每件 8 颗，两副共 32 颗。底座磁铁凸出板面 0.4；上盖磁铁与盖底齐平；合上后两组磁面相距 0.8，**永不接触**，所以上盖永远坐在打印的导轨顶上，通道高度始终是打印出来的数字，而不是磁铁叠出来的。极性必须配对，让每一对底座–上盖位置都相吸：压入前逐颗与对位磁铁验吸；压进去的磁铁是取不出来的。

**6×6 与 6×4.5。** 拍 6×6 时，把 `mask-6x6.stl`（94 × 80 × 1，窗 56.5 × 56.5）垫进托盘、放在 120 底座*下方*：整副夹子抬高 1 mm，属于正常，重新对焦即可。6×4.5 没有专用遮幅片，后期裁切。

### 装框幻灯片：幻灯片板

装框的幻灯片厚约 1.2 – 3.2 mm，是 0.4 mm 通道的许多倍，永远进不了 135 夹；而在 135 底座上给它挖一个槽，又会把托住片条的承台挖掉（[设计日志第 25 条](design-log.zh-CN.md#25-装框幻灯片自成一板)）。所以 `slide-plate-135.stl` 是独立的第四副夹子，只有一件：一块 94 × 120 × 5 的黑色板，代替 135 那副立在托盘里。它没有上盖、没有磁铁、没有压片元件：幻灯片框本身是硬的，箱子又是卧式的，方槽负责定位，重力负责压住。

| 特征 | 幻灯片板 |
|---|---|
| 外形与厚度 | 94 × 120 × 5，在托盘里坐的是和夹底座同一个位置 |
| 方槽 | 51.4 × 51.4，深 2.0；槽底在板底以上 3.0（z = 82.0） |
| 开窗 | 26 × 38，穿过槽底 |
| 指槽 | 两个，18 × 12，居中开在方槽的两条短边上；底在 1.0，不穿透 |
| 胶片面 | 槽底加上框厚的一半左右：纸框约 82.6，玻璃框约 83.6；重新对焦 |

**为什么是 51.4：** 幻灯片框标称 50 × 50，但纸框可以到 50.8（2 英寸），51.4 给最大的框每边留 0.3 mm、给塑料框每边留 0.7 mm，和夹底座在托盘里的间隙是同一口径。**为什么深 2.0：** 最薄的纸框约 1.2，仍然被槽壁扣住；最厚的玻璃框约 3.2，露出 1.2，上面没有任何东西会碰到它。**为什么是 26 × 38 而不是 25 × 37：** 框在槽里最多能偏 0.7 mm，相对标称的 24 × 36 画幅每边留 1 mm 余量，框住画面的就永远是框自己的片窗，而不是打印出来的边；任何框在四边仍然比开窗多盖出 5 mm 以上，所以不漏光。**指槽**让指甲能伸到纸框的边下面，纸框比槽沿低 0.8；指槽是盲槽，比槽底再低 2.0，不透光。

装框幻灯片的放法和你拿着它对着窗看时一样：从上往下看图像是正的，这样药膜就朝下，和片条同一规则。翘曲的纸框或者鼓起来的片子，这里没有任何东西能压平，专用的幻灯片扫描仪也一样；1:1、f/8 下约 ±0.4 mm 的景深能吃掉大部分。

---

## 6. 壳体

**主箱**是一体打印件：底板 3.0，左、右、后三面壁 2.4，前面根本没有墙。侧壁顶上立着四个定位榫，2.4 × 12 × 2.6，与顶盖台的四角榫槽配合。

**敞开前口删掉了什么。** 原型机需要抽口盖板，因为闪光灯的出力拨盘封在不透光的箱子里；需要过线孔，因为线要穿过一面遮光墙；还要回答通风问题，因为热量无处可去。v1 的箱内没有任何需要伸手去够的东西：闪光灯、接收器和它们的电池都在桌面上，改出力抬手就到，对焦灯的线直接从箱口走出去，腔体本身就通着空气。三个问题和那面前墙一起消失了。

**无螺丝、无胶水、无工具。** 整个设计里没有任何螺纹咬进塑料。每一处连接不是榫入槽、就是重力、就是磁吸：顶盖台靠榫定位、靠自重压住，夹子靠磁铁吸在垫片上，上盖靠磁铁吸在底座上，元件靠重力躺在台阶里。磁铁压入，垫片散放。装配就是按顺序往上摞，几分钟完事（[装配文档](assembly.zh-CN.md)）。

> [!NOTE]
> **整台装配的紧固件清单是：零颗螺丝、零滴胶水。** 连原型机仅剩的两处用胶（夹子磁铁和铁垫片）也没有了：v1 的磁铁是过盈压入的，垫片是落在沉孔里的。

> [!WARNING]
> **重力堆叠不能斜着搬。** 组装态的箱子是对齐的，不是连接的：要么贴着桌面平移，要么拆开来分件搬；顶盖台捏住凸缘一提就整体离箱。

### 特征位置总表

XY 从箱体中心起算，z 从桌面起算。数据读自 `cad/neobox.blend`。

| 特征 | XY | z | 尺寸 |
|---|---|---|---|
| 敞开前口 | 前面 | 3.0 – 73.0 | 内腔完整截面，120 × 70 |
| 定位榫，4 个 | 侧壁顶 | 73.0 – 75.6 | 2.4 × 12 × 2.6 |
| 榫槽，4 个 | 顶盖台底面 | 深 2.8 | 罩榫，竖向留 0.2 间隙 |
| 透光窗 | 居中 | 贯穿板体，73.0 – 79.0 | 62 × 95 |
| 亚克力暗槽 | 居中 | 槽底 76.6，向 79.0 的台面开口 | 69 × 119，深 2.4 |
| 垫片沉孔，4 个 | (±41, ±12) | 78.0 – 79.0 | 10.6 见方，深 1.0 |
| 托盘凸缘 | 围 94.6 × 120.6 夹座 | 79.0 – 83.0 | 一圈边，高 4 |

> [!TIP]
> 榫与榫槽的配合尺寸落在 FDM 的正常误差范围之内：象足、XY 膨胀和翘曲都会吃掉它。顶盖台扣不动或者晃，要改的是切片参数，不是模型文件，见[打印文档里的偏紧偏松处理](printing.zh-CN.md#打紧了或打松了怎么办)。

---

## 7. 对焦灯

箱内没有内置对焦灯，也没有任何电气件。取景和对焦用普通房间光就够：昏暗房间里看清胶片细节绰绰有余，什么灯都行，只要别直射敞开前口；拍摄瞬间闪光会把房间光全部压过去。

---

## 8. 闪光灯用法

只用手动出力、普通同步，拍 [raw](glossary.zh-CN.md#raw)。[TTL](glossary.zh-CN.md#ttl) 测光在这里毫无用处（场景永远不变，出力手动定一次就够），而 [HSS](glossary.zh-CN.md#hss) 解决的问题在[同步速度](glossary.zh-CN.md#同步速度)以内根本不存在。都别为它们花钱。

**闪光脉冲本身就是曝光。** 就算前口敞开，在昏暗房间里，一次同步速度的曝光收进来的环境光与脉冲相比可以忽略，于是闪光自身的持续时间就是等效快门，比任何三脚架能撑住的连续光曝光短几个数量级。振动、快门震动、地面传来的抖动，从此都不再是问题。

**快门速度：推荐 1/125 s。** 焦平面快门的同步速度通常标 1/160 – 1/250，而廉价 2.4 GHz 引闪器的延迟大约要吃掉一档，所以是 1/125。超过真实极限的症状一目了然：画面上一条边缘干净利落的暗带。

> [!IMPORTANT]
> **电子快门通常根本引不了闪。** 按下快门什么都没发生，这是第一个要检查的地方。细节见[翻拍扫描的曝光](scanning.zh-CN.md#曝光)。

改出力抬手就到：闪光灯就躺在你面前的桌上，没有东西要打开，也没有东西会被碰乱。接收器就在它旁边、箱子外面，信号路径干净，换电池什么都不碰。实际使用中，出力靠一张试拍定一次，之后不再动；曝光流程在[翻拍扫描的曝光](scanning.zh-CN.md#曝光)。

---

## 9. 复位与重复性

**两种片条画幅**的胶片面都固定在 z = 83.2（6×6 遮幅片把 120 那副抬高 1 mm；幻灯片板和片板托出的胶片面与它相差不到一毫米；重新对焦即可，其余不变）。135 和 120 之间变的是需要的放大倍率，因而变的是相机高度，不是胶片的高度。相机高度要用胶片面高度加上镜头的[工作距离](glossary.zh-CN.md#工作距离)算出来，算法在[翻拍扫描的相机高度与支架](scanning.zh-CN.md#相机高度与支架)。

**平行度就是一次对齐：镜子法。** 在胶片台上放一面小镜子，让取景器里镜头自己的倒影居中：传感器随即平行于胶片面，其下整摞零件的打印公差也在同一个动作里被吸收（[装配文档的镜子法](assembly.zh-CN.md#第-7-步相机端调平镜子法)，推理见 [§4](#4-顶盖台)）。这正是箱体上一件调平五金都没有的原因。

相机一旦调好，之后动的是箱子：在桌面上推动箱体来把画幅摆正居中，而不是重新去瞄相机；闪光灯顺手往箱口一靠就位。位置满意之后，把它变成可复现的：在底板上打两个定位销，或者用铅笔描出箱子的轮廓，两种都行；再把每种画幅对应的立柱高度记下来。

**先平行度，后均匀度。** 闪光能冻结振动，却治不好一个与传感器不平行的胶片面。先做镜子法，再拍一张做过[平场校正](glossary.zh-CN.md#平场校正)的测试片检查均匀度。

---

## 10. 4×5 装在 v1 主箱上

4×5 靠两个可选件和一块更大的亚克力，直接装在原封不动的主箱上：`cover-stage-4x5.stl` 代替顶盖台，`sheet-plate-4x5.stl` 立在它的托盘里，一块 106 × 130 × 2 的乳白板躺在它的暗槽里。其余什么都不变：同一组定位榫，同一支闪光灯放在同一个敞开前口，同一套重力堆叠，同一块 160 × 160 的打印床。

| 特征 | 4×5 顶盖台 | v1 顶盖台 |
|---|---|---|
| 外形、板身、榫槽 | 124.8 × 154.8，6 mm 板，四个榫槽对准定位榫 | 相同 |
| 透光窗 | 102 × 126 | 62 × 95 |
| 亚克力暗槽 | 107 × 131，槽底在 3.6，放 106 × 130 × 2 的板 | 69 × 119，放 68 × 118 × 2 |
| 凸缘围出的托盘 | 112.6 × 138.6，凸缘宽 4，顶在 10.0 | 94.6 × 120.6，凸缘宽 7 |
| 垫片沉孔 | 没有：片板没有磁铁 | 四个 |
| 混光余量，窗口边到箱壁 | x 方向 9，y 方向 12 | x 方向 29，y 方向 27.5 |

| 特征 | 片板 |
|---|---|
| 外形与厚度 | 112 × 138 × 5，立在 4×5 凸缘围出的台面上 |
| 片槽 | 102.2 × 127.6，深 2.0；槽底在板底以上 3.0（z = 82.0） |
| 开窗 | 97 × 121，穿过槽底：96 × 120 的影像区加上惯例的每边 0.5 |
| 边缺口 | 两个，宽 18，开在两条短边上，从页片边缘下方 3.7 处一直切出板边；底在 1.0 |
| 胶片面 | 页片平躺在槽底上：约 82.2 |

**为什么页片不需要压片元件。** 全画幅拍 4×5 约为 0.25×，f/8 下的景深大约 8 – 10 mm，是 135 的十倍。页片自身一两毫米的卷曲在这个尺度上看不出来，所以片板就是一个槽，页片边缘下面有承台，上面什么都没有：没有上盖、没有玻璃、没有磁铁。页片一张一张装，从上往下看图像是正的（药膜朝下），从边缺口抠出来。

**不知道的事：均匀性。** v1 的窗口离箱壁 29 和 27.5 mm，4×5 的窗口只离 9 和 12。从来没有确立过最小余量，也没有测过任何东西，所以 4×5 套件是作为同一只箱子上的实验发布的，不是作为一个数字。先拍一张空白片：如果出现你不能接受的渐变，第一个办法是后期平场校正（[scanning.zh-CN.md](scanning.zh-CN.md#平场校正与反相)），第二个办法是更大的箱子。

<details>
<summary>余量真的不够时的大箱路线</summary>

要推导的是一只更大的箱子，不是另一种箱子：保留 102 × 126 的窗口，给它 v1 的余量，内腔就成了 160 × 181，主箱外形约 164.8 × 185.8，超出 160 × 160 的床、要上 220 级的床，顶盖台、托盘、片板和亚克力按比例跟着改。敞开前口的架构、无螺丝的重力堆叠和层格原样沿用。闪光灯未必要换大：更大的窗口要多吃约 1.2 档，而从 1:1 降到 0.25× 又还回约 1.3 档，不过这一点同样没有实测。
</details>

---

## 11. 使用源文件

`cad/neobox.blend` 是本仓库里唯一的几何来源。十二个 STL 文件都由它生成，任何绕过 blend 文件、直接改到 STL 上的改动，下一次有人重新导出时就会丢失。

### 打开文件

| 项目 | 值 |
|---|---|
| Blender 版本 | **3.0 或更新。** 文件是 Zstandard 压缩的，3.0 以前的 Blender 根本读不了。文件头记录的最后保存版本是 **Blender 5.2** |
| 单位系统 | 公制，unit scale 0.001，长度单位毫米：**一个 Blender 单位就是一毫米** |
| 场景布局 | 装配体就位建模，z 基准与本文一致：桌面（也就是箱体外底面）为 z = 0。120 那副夹子停放在装配体旁 x = 200 处，6×6 遮幅片停放在 x = 350 处，幻灯片板停放在 x = 500 处，4×5 套件停放在 x = 650 处 |

### 集合（collection）树

```
Scene Collection
├── mock_view-target    一个 empty，用作视图目标
├── Scaffolding         Camera、Light：渲染用的脚手架
├── NeoBox_v1           壳体、顶盖台和示意件
├── Holder_135          135 那副夹子，就位装配
├── Holder_120          120 那副夹子，停放在 x = 200
├── Masks               6×6 遮幅片，停放在 x = 350
├── Holder_slide        幻灯片板和它的幻灯片框示意件，停放在 x = 500
└── Stage_4x5           4×5 顶盖台和片板及其示意件，停放在 x = 650
```

### 每个 STL 由哪些对象组成

| STL 文件 | Blender 对象 | 说明 |
|---|---|---|
| `main-body.stl` | `main-body_floor`、`main-body_wall-left`、`main-body_wall-right`、`main-body_wall-rear` | **四个对象**：底板、左壁、右壁、后壁；前面敞开，不再需要门楣和前柱 |
| `cover-stage.stl` | `cover-stage` | 顶盖台，一体件，窗 62 × 95 |
| `film-holder-135-base.stl` | `film-holder-135-base` | 135 夹底座，平底 |
| `film-holder-135-lid.stl` | `film-holder-135-lid` | 135 夹上盖 |
| `film-holder-120-base.stl` | `film-holder-120-base` | 120 夹底座，平底 |
| `film-holder-120-lid.stl` | `film-holder-120-lid` | 120 夹上盖 |
| `pressure-window-135.stl` | `pressure-window-135` | 135 压片窗插片 |
| `pressure-window-120.stl` | `pressure-window-120` | 120 压片窗插片 |
| `mask-6x6.stl` | `mask-6x6` | 6×6 遮幅插片 |
| `slide-plate-135.stl` | `slide-plate-135` | 幻灯片板，一体 |
| `cover-stage-4x5.stl` | `cover-stage-4x5` | 4×5 顶盖台，一体 |
| `sheet-plate-4x5.stl` | `sheet-plate-4x5` | 4×5 片板，一体 |

### 哪些是示意件，绝不能导出

场景里其余的一切都是看装配关系和光路用的示意件，一件也不打印、不导出：闪光灯灯体和它的发光面（`mock_flash-body`、`mock_flash-face`）、T1 接收器（`mock_trigger-receiver`）、四支光路箭头（`mock_ray-1-into-cavity` 到 `mock_ray-4-through-window`）、135 和 120 的胶片示意条（`mock_film-135`、`mock_film-120`）、一个 50 × 50 × 2 的幻灯片框（`mock_slide-mount-50x50x2`）、一张 4×5 页片（`mock_film-4x5`）、两块乳白亚克力（`mock_diffuser-68x118x2`、`mock_diffuser-106x130x2`）、防牛顿环玻璃（`mock_an-glass-64x95x2`）、四片钢垫片（`mock_steel-shim-1` 到 `mock_steel-shim-4`）、一个文字标签（`mock_label`），以及相机／灯光／视图目标这些脚手架（`Camera`、`Light`、`mock_view-target`）。

这条界线现在写在名字里，也由脚本兜底。命名约定有两条：**要打印的对象，名字就是它生成的那个 STL 文件名**（主箱是四片壳体，共用 `main-body_` 前缀）；**不打印的对象，一律带 `mock_` 前缀**。`Camera` 和 `Light` 不在这条规则之内：它们不是 MESH 对象，本来就到不了 STL。`tools/export_stl.py` 会强制执行：任何一个 MESH 对象，只要既不在它的 `MAPPING` 表里、又没有 `mock_` 前缀，导出就整体失败。这样一来，往场景里加了新的可打印零件却忘了写进 `MAPPING`，不会悄无声息地少导出一个零件，而是当场让导出失败。

> [!CAUTION]
> **材质名不代表耗材颜色。** 场景里现在只有八个材质，全部只为渲染服务，名字说的是它贴在什么东西上：`NB_white` 贴主箱四片壳体和顶盖台，`NB_black` 贴全部黑色打印件外加闪光灯灯体、文字标签和幻灯片框这三个示意件，其余六个（`NB_steel`、`NB_opal`、`NB_film`、`NB_glow`、`NB_ray`、`NB_receiver`）只贴在示意件上。原型机时代那批材质已经全部删除，槽里不再有会误导人的残余。即便如此，耗材颜色仍然一律以[打印文档的十二个零件](printing.zh-CN.md#十二个零件)为准，绝不要看材质槽。

### 导出约定

每个 STL 都是**按装配体的世界坐标**导出的，导出过程中没有任何归零或改向。

| 文件 | 它在导出文件里所处的位置 |
|---|---|
| `main-body.stl` | z 0 – 75.6，XY 居中 |
| `cover-stage.stl` | z 73 – 83，XY 居中 |
| `film-holder-135-base.stl` ／ `-lid.stl` | z 79 – 84 ／ 84 – 87，在装配位上 |
| `pressure-window-135.stl` | z 83.6 – 85.6，在装配位上 |
| `film-holder-120-base.stl` ／ `-lid.stl` | 停放在 x 153 – 247，z 0 – 5 ／ 5 – 8 |
| `pressure-window-120.stl` | 停放在 x 168 – 232，z 4.6 – 6.6 |
| `mask-6x6.stl` | 停放在 x 303 – 397，z 0 – 1 |
| `slide-plate-135.stl` | 停放在 x 453 – 547，z 0 – 5 |
| `cover-stage-4x5.stl` | 停放在 x 587.6 – 712.4，z 0 – 10 |
| `sheet-plate-4x5.stl` | 停放在 x 594 – 706，z 6 – 11，立在 4×5 顶盖台的台面上 |

切片软件是按包围盒把文件落到打印床上的。十二个文件里有十个导入时就已经打印面朝下躺平；两个夹上盖不是：它们要**顶面朝下**打印，导入后必须翻面。每个零件需要转多少，写在[打印文档的十二个零件](printing.zh-CN.md#十二个零件)那一节的零件卡片上。

### 重新导出

一条命令再生成全部十二个文件。它就是产出已发布 STL 的那套管线的入库版本，也是唯一受支持的导出方式：

```
blender --background cad/neobox.blend --python tools/export_stl.py
```

（`blender` 指你 Blender 安装目录里的可执行文件，4.x／5.x 都可以。在仓库根目录运行，跑完接着 `python3 tools/verify_stl.py`。）

这个脚本之所以必要，是因为可打印零件都是**用互相嵌入的壳体建模的**，刻意互相咬进 0.2 – 0.5 mm：墙体沉入箱底、凸缘沉入顶盖台板、导轨沉入夹底座。这样源文件才能保持参数化、容易修改。脚本对每个输出文件做的是：复制源对象、按松散壳体拆分、用 EXACT 求解器把壳体布尔并集成单一实体、焊掉布尔残渣、自检水密，再按装配体世界坐标导出；场景本身自始至终不被改动。直接 File → Export → STL 导出原始对象，得到的是多壳体文件，其内部假面过不了校验脚本的层高网格检查。

再生成的文件与已发布文件**逐字节比可能不同**（三角剖分在 Blender 版本之间并不稳定），但几何完全一致。裁判是校验脚本：外形、水密、层高网格、最小台阶四项全过才算数。

<details>
<summary>手动导出（跑不了脚本时的后备）</summary>

1. **选中一个输出文件对应的对象**，照上面的映射表来。*检查点：*选中的对象数量和表里对得上：主箱四个，其余每个文件一个。
2. **每个零件都要合成单一实体，不只是主箱。** 单对象的零件内部同样可能是多壳体。该 join 的 join，按松散块拆分后做布尔并集，再按距离合并顶点（0.02 mm）、跑一次 1° 的有限溶解清掉布尔残渣。*检查点：*零件是一层连通的壳，校验脚本报告没有非流形边。
3. **导出。** File → Export → STL，勾 *Selection Only*，scale 1.00，forward Y，up Z。不要做任何坐标轴转换：文件里的数字必须和 Blender 里的数字一致。*检查点：*把文件重新导入，零件正好回到原来的位置。
4. **写回原路径**，`stl/white-pla/` 或 `stl/black-pla/` 下面，文件名不变。*检查点：*`git status` 显示的是一个被修改的文件，不是一个新文件。
5. **提交之前先校验。** *检查点：*`python3 tools/verify_stl.py` 打印 `all 12 files pass` 并以 0 退出。

</details>

```mermaid
flowchart LR
  A[修改 cad/neobox.blend] --> B[重新导出受影响的 STL]
  B --> C[python3 tools/verify_stl.py]
  C -->|12 个文件全部通过| D[三种语言的文档一起更新]
  C -->|有任何 FAIL| A
  D --> E[blend、STL 和文档一并提交]
```

### 运行校验脚本

`tools/verify_stl.py` 是纯 Python 3，没有任何依赖。在仓库根目录运行：

```
python3 tools/verify_stl.py
```

它会遍历 `stl/` 下的每一个 `.stl`，对每个文件检查四条不变量：

| 检查项 | 它保证什么 |
|---|---|
| watertight | 每条边恰好被两个三角面共用：闭合实体，没有破洞 |
| layer grid | 每个水平面都落在该零件自身基准面以上 0.2 mm 的整数倍处 |
| minimum step | 没有低于 0.4 mm 的暴露水平台阶，也就是 0.2 层高下的两层 |
| bounding box | 零件的实际尺寸仍然和文档写的一致 |

找台阶时会忽略小于 1 mm² 的水平面，这样建模留下的碎片不会误报。输出是每个文件一行加一个合计，只要有任何一项失败退出码就非零，所以这个脚本可以用来卡提交：

```
ok    film-holder-120-base.stl  [94.0, 120.0, 5.0]  256 triangles
...
all 12 files pass
```

对外公布的包围盒数据存在脚本顶部的 `EXPECTED` 表里，按数值从大到小排序。**如果你是有意改动了某个已公布的尺寸，请在同一个 commit 里改 `EXPECTED`**；否则你想改的那个零件会检查失败，而你没打算改的那个零件反倒悄悄通过了。

### 换闪光灯

在原型机时代，这个标题下面是一份重新推导的清单。到了 v1，没有任何东西需要改：**箱体的任何尺寸都不编码闪光灯**，换一只闪光灯（或者换一套触发器），既不碰 `cad/neobox.blend` 也不碰 STL。新闪光灯只要能手动调出力、灯头能平躺着水平对准敞开前口；换完重拍一张测光试片，继续干活（[§8](#8-闪光灯用法)）。

### `cad/` 里的其他文件

- `film-stage-aluminium-3mm.dxf`：原型机的铝制胶片台，只作历史保存。v1 没有胶片台：这个零件已并入顶盖台，现在的设计里没有任何东西按它切。
- `legacy-plywood/`：胶合板版本留下的 DXF，只作历史保存。这两个文件加起来也描述不出一个完整的壳体，现在的设计里没有任何零件是按它们切的。

贡献规则（哪些是源文件、哪些是生成物，以及三语同步的要求）在 [CONTRIBUTING.md（英文）](../CONTRIBUTING.md#source-of-truth-vs-generated-files)。

---

← [术语表](glossary.zh-CN.md) · [文档索引](../README.zh-CN.md#文档) · [设计日志](design-log.zh-CN.md) →

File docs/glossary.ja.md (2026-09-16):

# 用語集

[English](glossary.md) · [简体中文](glossary.zh-CN.md) · **日本語**

> NeoBox のドキュメントが「読者は当然知っている」という顔で使っている語を、1 語 1 行で定義し、このプロジェクトでなぜそれが効いてくるのかを 1 行添えたページです。ほかのページからは、必要な項目へ直接リンクしています。

**目次：** [アンチニュートンガラス](#アンチニュートンガラス-anti-newton-glass) · [ベース ISO](#ベース-iso) · [ビルドプレートのサイズ](#ビルドプレートのサイズ-bed-size) · [ブリッジ](#ブリッジ-bridging) · [カメラスキャン](#カメラスキャン-camera-scanning) · [溝](#溝-channel) · [複写スタンド](#複写スタンド-copy-stand) · [天板ステージ](#天板ステージ-cover-stage) · [拡散板](#拡散板-diffuser) · [EFCS](#efcs-先幕電子シャッター) · [エレメント段](#エレメント段-element-ledge) · [エレファントフット](#エレファントフット-elephant-foot) · [EV](#ev-露出値) · [フィルムゲート](#フィルムゲート-film-gate) · [フラットフィールド補正](#フラットフィールド補正-flat-field-correction) · [ガイドナンバー](#ガイドナンバー-gn) · [HSS](#hss-ハイスピードシンクロ) · [インフィル](#インフィル-infill) · [積分キャビティ](#積分キャビティ-integrating-cavity) · [反転](#反転-inversion) · [受け](#受け-land) · [積層ピッチ](#積層ピッチ-layer-height) · [位置決めダボとダボ穴](#位置決めダボとダボ穴-locating-tenon-and-notch) · [撮影倍率](#撮影倍率-magnification-ratio) · [マニュアル発光量](#マニュアル発光量-manual-power-fraction) · [ミラー調整法](#ミラー調整法-mirror-alignment) · [ニュートンリング](#ニュートンリング-newton-rings) · [乳白](#乳白-opal) · [オープンフロント](#オープンフロント-open-front) · [外周壁](#外周壁-perimeters) · [押さえ窓インサート](#押さえ窓インサート-pressure-window-insert) · [レール](#レール-rail) · [RAW](#raw) · [フィルム走行路](#フィルム走行路-run-out-corridor) · [シートプレート](#シートプレート-sheet-plate) · [スライドプレート](#スライドプレート-slide-plate) · [サポート](#サポート-supports) · [同調速度](#同調速度-sync-speed) · [TTL](#ttl-through-the-lens-調光) · [窓](#窓-window) · [ワーキングディスタンス](#ワーキングディスタンス-working-distance)

## A–Z

このプロジェクトでは、フィルム写真と 3D プリントという 2 つの語彙が交差します。両方に通じている読者は、まずいません。以下の項目はどれも、どちらも初めてという人に向けて書いてあります。並び順は英語版・中国語版と行を揃えるため、英語名のアルファベット順です。

> [!TIP]
> パーツの名前は別の話です。各パーツには名前が 1 つだけあり、途中で呼び替えることはありません。プリントするもの：**本体**、**天板ステージ**、**フィルムホルダー**（**ホルダー底** / **ホルダー蓋**、フォーマットごとに 1 組）、**押さえ窓インサート**、**6×6 マスク**、**スライドプレート**、**4×5 天板ステージ**、**シートプレート**。買うもの：**拡散板**、**磁石**、**スチールシム**、オプションで**アンチニュートンガラス**。プロトタイプの**天板**と**フィルムステージ**は v1 で天板ステージに統合され、**アクセスパネル**・**寸切りボルト**・**ナット**は廃止されました。v1 には締結部品がひとつもありません。目の前にある形と名前が結び付かないときは[パーツ各部の呼び方](printing.ja.md#パーツ各部の呼び方)を見てください。名前ごとに、目で見える特徴が対応づけてあります。

### アンチニュートンガラス (anti-Newton glass)

片面を微細なマット仕上げにしたガラス。フィルムを押し当てても[ニュートンリング](#ニュートンリング-newton-rings)が出ないように作られている。NeoBox のオプションの平面性アップグレードは、両フォーマット共用の片面 AN ガラス 1 枚、64 × 95 × 2 mm。

**なぜ重要か：** プリント製の[押さえ窓インサート](#押さえ窓インサート-pressure-window-insert)の代わりに[エレメント段](#エレメント段-element-ledge)へ置くと、コマ全体を連続した面で押さえ、フィルムのどの位置でも浮きを 0.28 mm 以内に抑えます。マット面を下にして、フィルムの光沢のあるベース面に当てます。乳剤面は下の開いた窓に向くので、何にも触れません。ガラスの下面は焦点面からわずか 0.2 mm なので、付いた埃はそのまま写ります。装填前にブロアーで吹いてください。

### ベース ISO

カメラのセンサーが持つ本来の最低感度。多くの機種では ISO 100 で、ダイナミックレンジが最も広く、ノイズが最も少ない。

**なぜ重要か：** 箱の中ではストロボの出力に余裕があるので、ベース ISO から動かす理由はどこにもありません。測光は ISO 100、f/5.6–f/8 から始めます。[露出](scanning.ja.md#露出)を参照してください。

### ビルドプレートのサイズ (bed size)

FDM プリンタのビルドプレートのうち、実際に出力できる範囲。X × Y で表す。

**なぜ重要か：** 好みではなく可否の判定です。ただし v1 では簡単に通ります。最大のパーツは本体と天板ステージの 124.8 × 154.8 mm なので、160 × 160 mm のプレートがあれば全パーツを出力できます。280 mm 級のプレートを求めたプロトタイプ時代の注意書きは廃止です。[お使いのプリンタで出力できるか](printing.ja.md#お使いのプリンタで出力できるか)を参照してください。

### ブリッジ (bridging)

支えのない隙間を、両端の定着点のあいだに一気に架け渡すようにフィラメントを押し出し、垂れる前に空中で冷やし固める造形。

**なぜ重要か：** v1 にはブリッジすべき場所がありません。本体の前面は「渡された開口」ではなく、壁そのものがありません。それが[オープンフロント](#オープンフロント-open-front)です。12 点のパーツはすべて平らな面を下にして、[サポート](#サポート-supports)なしで出力できます。

### カメラスキャン (camera scanning)

ネガをフラットベッドスキャナやドラムスキャナに通す代わりに、スタンドに据えたデジタルカメラで撮影して取り込む方法。使うカメラが何であれ DSLR スキャンとも呼ばれる。

**なぜ重要か：** NeoBox はこの方法のための光源であり、それ以外の何物でもありません。カメラを保持する機能はありませんし、カメラ本体・レンズ・スタンドは自分で用意するものです。[カメラスキャンとは](getting-started.ja.md#カメラスキャンとは)を参照してください。

### 溝 (channel)

フィルムホルダーの内部で、フィルムストリップが滑って通る高さ 0.4 mm のすき間。幅は 135 用ホルダーで 35.4 mm、120 用ホルダーで 62.0 mm。床が[受け](#受け-land)、側面が[レール](#レール-rail)、天井は、[エレメント段](#エレメント段-element-ledge)に載った押さえエレメント（[押さえ窓インサート](#押さえ窓インサート-pressure-window-insert)または[アンチニュートンガラス](#アンチニュートンガラス-anti-newton-glass)）の下面。

**なぜ重要か：** フィルムの装填もコマ送りも、はみ出した先端をつまんで溝を横に引き抜くことで行います。途中でホルダーを開けることも、押さえエレメントを動かすこともありません。反ったコマは、滑り込むときに天井へ押し当てられて平らになります。0.4 mm という数字は、ホルダー系のパーツだけ細かい[積層ピッチ](#積層ピッチ-layer-height)で出力する価値がある理由でもあります。

### 複写スタンド (copy stand)

台板に立てた支柱でカメラを真下向きに保持し、高さを変えられるようにした器具。水平アームや反転可能なセンターポールを持つ三脚でも同じ役目を果たす。

**なぜ重要か：** フィルム面は机の面から 83.2 mm 上にあり、スタンドはその高さにレンズの[ワーキングディスタンス](#ワーキングディスタンス-working-distance)を足した分を確保しつつ、センサーをフィルムと平行に保てなければなりません。[カメラの高さとスタンド](scanning.ja.md#カメラの高さとスタンド)を参照してください。

### 天板ステージ (cover-stage)

箱の上面を閉じる白いパーツ 1 点。プロトタイプの天板とフィルムステージが v1 で統合されたもので、124.8 × 154.8 × 10 mm。6 mm の板が箱の壁に載り、本体側の[位置決めダボ](#位置決めダボとダボ穴-locating-tenon-and-notch)に 4 つのダボ穴で位置決めされます。板の上では立ち上がったフランジが 94.6 × 120.6 mm のホルダー座を囲み、板には 62 × 95 mm の採光窓、[拡散板](#拡散板-diffuser)を収める隠しスロット、そしてホルダーの磁石が吸い付く、面一に埋まったスチールシム 4 枚を備えています。オプションの 4×5 版 `cover-stage-4x5.stl` は外形とダボ穴をそのままに、102 × 126 mm の窓、106 × 130 × 2 mm の板を収める溝、[シートプレート](#シートプレート-sheet-plate)用の 112.6 × 138.6 mm のトレイを持ちます。

**なぜ重要か：** 天板とステージの統合で、部品の積み重ねとその間の公差がまるごと消えました。水平を出すものも、ねじ止めするものもありません。フランジをつまめば全体を持ち上げられ、ホルダーはその上で磁力により数秒で着脱できます。フランジ上面はフィルム面より 0.2 mm 低いので、ホルダーからはみ出したフィルムは引っかからずにその上を渡っていきます。

### 拡散板 (diffuser)

透過する光を散らし、均一な光の面に変える半透明の板。NeoBox にあるのはちょうど 1 枚、68 × 118 × 2 mm の[乳白](#乳白-opal)アクリル板で、[天板ステージ](#天板ステージ-cover-stage)内部、採光窓の下の浅いスロットに収まっている。

**なぜ重要か：** これ自体が光る面です。ここを出た光は、4.6 mm の空気を挟んですぐフィルムに届きます。拡散して光る面なので、付いた埃は像になりません。毎回の儀式ではなく、ときどき拭けば十分です。取り出すときは、ホルダーを外し、箱の口から手を入れて採光窓越しに上へ押し出します。

### EFCS (先幕電子シャッター)

Electronic first-curtain shutter。露光の開始をセンサー側で電子的に行い、終了はメカの後幕で行う方式。

**なぜ重要か：** EFCS ならストロボは発光しますし、先幕が走る衝撃もなくなります。*完全*電子シャッター（サイレントシャッター）はこれとは別の設定で、たいていストロボを発光させられません。[露出](scanning.ja.md#露出)を参照してください。

### エレメント段 (element ledge)

各ホルダー底の外レールにある高さ 4.6 mm の段。押さえエレメント（[押さえ窓インサート](#押さえ窓インサート-pressure-window-insert)または[アンチニュートンガラス](#アンチニュートンガラス-anti-newton-glass)）を受け、その外側にはエレメントのずれを止める 0.4 mm 高い縁が立つ。段の形は 135 用と 120 用のホルダーで同一で、だからガラス 1 枚が両方に収まる。

**なぜ重要か：** エレメントの下面を、フィルムが載る 4.2 mm の[受け](#受け-land)より 0.4 mm 上、ちょうど 4.6 mm に固定します。この差が、フィルムの通る[溝](#溝-channel)*そのもの*です。エレメントは段に一度置いたら二度と触りません。コマ送りは、その下でストリップを引き抜くだけです。

### エレファントフット (elephant foot)

出力物の最初の数層が、ノズルとヒートベッドに押しつぶされて外側へわずかに膨らむ現象。

**なぜ重要か：** 逃げの最も少ない嵌合を直撃します。本体の[位置決めダボ](#位置決めダボとダボ穴-locating-tenon-and-notch)にかぶさる[天板ステージ](#天板ステージ-cover-stage)下面のダボ穴の口と、押さえ窓インサートが[エレメント段](#エレメント段-element-ledge)に収まるときの外形です。スライサーのエレファントフット補正を有効にしてください。[きつい場合と緩い場合の対処](printing.ja.md#きつい場合と緩い場合の対処)を参照してください。

### EV (露出値)

Exposure value。1 EV は 1 段、つまりセンサーに届く光量が倍になる、または半分になることを指す。

**なぜ重要か：** 光の均一性と露出の一貫性を測るための単位です。四隅のあいだでも、コマとコマのあいだでも同じで、判定はつねに[フラットフィールド補正](#フラットフィールド補正-flat-field-correction)のあとに行います。

### フィルムゲート (film gate)

コマの露光範囲を決める長方形の開口。本来はフィルムカメラの中の金属枠を指すが、転じてここでは、撮影のために覗くフィルムホルダーの[窓](#窓-window)も指す。

**なぜ重要か：** カメラごとにゲート寸法は微妙に違うので、ホルダーの窓は片側およそ 0.5 mm 大きく切ってあり、その個体差とプリンタの XY 公差を吸収します。毎セッション、ブロアーで吹いておくべき面の名前でもあります。[アンチニュートンガラス](#アンチニュートンガラス-anti-newton-glass)を使うなら、それも一緒に。

### フラットフィールド補正 (flat-field correction)

フィルムを入れない状態で、均一に光る面だけを撮影し、その参照画像で実際のコマを割ることで、レンズの周辺減光と光源のムラを打ち消す処理。

**なぜ重要か：** 箱の出来を判断する前に、まずこれです。レンズの周辺減光と光源本来のムラを切り分ける唯一の方法で、箱の均一性は補正後に残ったぶんで判定します。[フラットフィールド補正と反転](scanning.ja.md#フラットフィールド補正と反転)を参照してください。

### ガイドナンバー (GN)

ストロボの出力を表す数値。ISO 100 で適正露出になる「絞り値 × 距離」に等しい。基準機の NEEWER TT560 は GN38（メートル）。

**なぜ重要か：** ストロボの製品パッケージに印刷されているのはこの数字ですが、NeoBox の中ではほとんど何も語りません。ストロボは[オープンフロント](#オープンフロント-open-front)から発光し、光は何度も拡散反射してからでなければフィルムに届かないからです。測光は ISO 100、f/5.6–f/8 から始め、数段ぶんの出力は筐体に取られるものと考えてください。

### HSS (ハイスピードシンクロ)

High-speed sync。ストロボが小さなパルスを高速で連射することで、カメラの[同調速度](#同調速度-sync-speed)より速いシャッター速度でも使えるようにする機能。

**なぜ重要か：** ここでは無用ですが、その代金を求められることがあります。薄暗い部屋でストロボ撮影をする以上、同調速度以下で撮るのは自分で選んだ前提です。

### インフィル (infill)

パーツの[外周壁](#外周壁-perimeters)の内側を埋める格子構造。中実に対する割合で指定する。

**なぜ重要か：** 12 点すべて 15 % が仕様です。v1 にはインフィルに荷重を預けるパーツがもうありません。壁を不透明に保つのは外周壁であって、インフィルではありません。[プリント設定](printing.ja.md#プリント設定)を参照してください。

### 積分キャビティ (integrating cavity)

内壁がつや消し白の閉じた空間。光が何度も反射するうちに、向きと明るさが均される。実験室版が積分球。

**なぜ重要か：** NeoBox がまさにこれで、一面だけ開いた 120 × 150 × 70 mm の白い空洞です。ストロボは机に寝かせて[オープンフロント](#オープンフロント-open-front)から水平に発光し、フィルムに直接向けられているものは何もありません。均一性は白い壁と天井での反射から生まれるのであって、拡散板だけが作っているのではありません。内側を白いフィラメントのまま残し、塗装してはいけないのもこのためです。[光がどう進むか](../README.ja.md#光がどう進むか)を参照してください。

### 反転 (inversion)

撮影したネガをポジ画像に変換する処理。階調を反転し、カラーネガのオレンジベースを除き、コントラストと色を決める。

**なぜ重要か：** ワークフローの最後の工程であり、光源が一定であることが効いてくるところです。1 本のすべてのコマが同じ発光量で撮れているので、反転プロファイル 1 つで 1 本まるごとに通用します。[フラットフィールド補正と反転](scanning.ja.md#フラットフィールド補正と反転)を参照してください。

### 受け (land)

ホルダー底の内側にある、フィルムの縁が載る立ち上がった座。周囲の面から 0.4 mm 高く、高さ 4.2 mm の位置にある。

**なぜ重要か：** 受けの上面が、そのままフィルム面です。ストリップは縁だけがそこに触れ、画面部分は開いた窓の上に浮いています。その 0.4 mm 上を、[エレメント段](#エレメント段-element-ledge)に載った押さえエレメントがふさいでいます。

### 積層ピッチ (layer height)

1 層の厚み。パーツの水平な面の高さをすべて量子化するので、積層ピッチの整数倍にならない寸法は設計どおりには出せない。

**なぜ重要か：** 設計上の高さはすべて 0.2 mm グリッドに載っており、露出する段差はすべて 0.4 mm 以上です。プリント仕様は全パーツ 0.2 mm なので、どの高さも層境界にちょうど載ります。[プリント設定](printing.ja.md#プリント設定)を参照してください。
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

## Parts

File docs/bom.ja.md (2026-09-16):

# 部品表と調達

[English](bom.md) · [简体中文](bom.zh-CN.md) · **日本語**

> NeoBox を作るために買うものすべてをまとめたページです。v1 ではリストが短くなりました。工具も締結部品もいっさい不要になったからです。「間違ったほうを買わずに済む仕様」と、日本・中国・その他の地域の店舗にそのまま貼り付けられる発注文面つきです。

**目次：** [費用](#費用) · [このリポジトリが用意しないもの](#このリポジトリが用意しないもの) · [工具と消耗品](#工具と消耗品) · [プリントパーツ](#プリントパーツ) · [購入部品](#購入部品) · [磁石](#磁石) · [正しい部品を選ぶ](#正しい部品を選ぶ) · [光源](#光源) · [発注の順番](#発注の順番) · [発注文面](#発注文面) · [部品が届いたら](#部品が届いたら)

---

## 費用

価格は 2026 年 8 月時点の中国 EC（タオバオ／1688）の実勢価格に基づく目安で、CNY 表記です。

| 区分 | 含まれるもの | 価格（CNY） |
|---|---|---|
| 3D プリント | プリントパーツ 12 点（うち 4 点はオプション）、白と黒の PLA | 50–110 |
| 拡散板 | 乳白アクリル、2 mm、68 × 118 mm カット | 5–10 |
| 磁石とシム | ネオジム磁石 32 個、スチールシム 4 枚 | 10–20 |
| **ストロボを除くビルド全体** | 上記すべてを一度ずつ | **JPY 1,500–3,000 · CNY 65–140** |

> [!NOTE]
> 各行を極値どうしで足すとちょうど CNY 65–140 になり、その大半は出力代行の代金です。これは実際に出力したプロトタイプ（社内第 4 版、CNY 250–420）のおよそ 3 分の 1 です。寸切りボルト、ナット、インサートナット、フォームテープ、グロメット、塗装がすべてなくなり、プリントパーツもすべて小さくなりました。プロトタイプをお持ちなら、旧拡散板を裁ち直せばアクリルの行は 0 になります。JPY の数字は同じビルドを円で表したもので、すべての部品を日本国内で買った場合の見積もりではありません。

この合計に含めず、別に見積もる項目が 2 つあります。任意アップグレードの[アンチニュートンガラス](#購入部品)（CNY 15–30）と[植毛シート](#購入部品)（CNY 5–10）です。2 つ合わせておよそ CNY 20–40 です。

---

## このリポジトリが用意しないもの

NeoBox は光源です。フィルムをスキャナに通す代わりにデジタルカメラで複写する[カメラスキャン](glossary.ja.md#カメラスキャン-camera-scanning)（camera scanning、DSLR スキャンとも）のセットアップの片側でしかありません。もう片側は自分で用意することになります。

| すでに持っているか、買う必要があるもの | 役割 |
|---|---|
| カメラ本体 | マニュアル露出と raw が使えるものなら何でも |
| マクロ撮影のできるレンズ | 24 × 36 mm という小さなコマを画面いっぱいに写す。普通のレンズはそこまで寄れない |
| 複写スタンド（copy stand）、または水平アーム・反転可能なセンターポールを持つ三脚 | カメラをフィルムの真上に、再現性のある高さで保持する |
| ストロボとトリガーのセット | マニュアルで発光量を決められるホットシューストロボなら何でも。基準にした組み合わせと価格は[光源](#光源)に記載 |
| カメラのホットシューに載せるトリガー送信機 | 基準にしたトリガーセットに同梱。ただしそのセットはビルド費用に含まれない |
| レリーズ | 露光中にカメラを押してしまわないため |
| 反転（inversion）ソフト | raw のネガを陽画に変換する |

> [!IMPORTANT]
> CNY 65–140 で買えるのは箱だけです。ストロボとトリガー（基準にした組み合わせで 2 点合計 CNY 350–550）も、上の表のカメラ側の機材も、いっさい含まれていません。何かを発注する前に、[はじめに の「すでに持っている必要があるもの」](getting-started.ja.md#すでに持っている必要があるもの)を読んでください。

カメラ側の選び方と使い方は [scanning.ja.md](scanning.ja.md#カメラ側の機材) が扱います。このページは箱を作る部品で終わりです。

---

## 工具と消耗品

このセクションに「必須」の項目は、今回初めて 1 つもありません。v1 のビルドにはねじも接着剤も塗装も工具もありません。磁石は手で圧入し、それ以外のパーツはすべて置くだけで収まります。机に残るのは、箱を「作る」ためではなく「使う」ための品だけです。

| 工具・消耗品 | 用途 | 仕様 |
|---|---|---|
| ブロアー | 拡散板、インサート、[フィルムゲート](glossary.ja.md#フィルムゲート-film-gate)の清掃。アンチニュートンガラスを買った場合は、取り付け前の除塵にも | エアダスターではなくゴム球のブロアー |
| 小さな平面鏡（30 mm 程度） | 平行出しの手順：ステージに鏡を置き、ファインダーでレンズ自身の映り込みを中央に合わせる | 平らな鏡の端材で可 |
| 綿手袋、または清潔な手 | フィルムを縁だけで持つ | — |
| 金尺またはノギス | このページ末尾の到着時チェック | 200 mm あれば 154.8 mm のパーツを測り切れる |

32 個の強力な小型磁石については、始める前に読んでおく価値があります。[組み立ての「工具と安全」](assembly.ja.md#工具と安全)へ。

---

## プリントパーツ

製造の全体図：箱の断面、各プリントパーツの寸法と出力姿勢、購入部品の一覧

ビルドは**プリントパーツ 12 点**。白 3 点、黒 9 点。6×6 マスク、スライドプレート、4×5 の 2 点はオプションで、すべてサポートレスです。

| ファイル | 色 | 外形（mm） | 内容 |
|---|---|---|---|
| main-body.stl | 白 | 124.8 × 154.8 × 75.6 | 本体：床と三方の壁、前面は全開 |
| cover-stage.stl | 白 | 124.8 × 154.8 × 10.0 | 天板ステージ：天板とフィルムステージを 1 パーツに統合したもの |
| film-holder-135-base.stl | 黒 | 94 × 120 × 5 | 135 ホルダー底、開口 25 × 37 |
| film-holder-135-lid.stl | 黒 | 94 × 120 × 3 | 135 ホルダー蓋 |
| film-holder-120-base.stl | 黒 | 94 × 120 × 5 | 120 ホルダー底、開口 57 × 85（6×9 フルフレーム） |
| film-holder-120-lid.stl | 黒 | 94 × 120 × 3 | 120 ホルダー蓋 |
| pressure-window-135.stl | 黒 | 64 × 95 × 2 | 135 用の押さえ窓インサート |
| pressure-window-120.stl | 黒 | 64 × 95 × 2 | 120 用の押さえ窓インサート |
| mask-6x6.stl | 黒 | 94 × 80 × 1 | 6×6 マスク。120 ホルダー底の下に敷く |
| slide-plate-135.stl | 黒 | 94 × 120 × 5 | マウント済み 135 スライド用のスライドプレート。135 ホルダーの代わりにトレイに立つ |
| cover-stage-4x5.stl | 白 | 124.8 × 154.8 × 10.0 | 4×5 天板ステージ。同じ本体の上で cover-stage.stl の代わりに載り、一回り大きいアクリルを収める |
| sheet-plate-4x5.stl | 黒 | 112 × 138 × 5 | 4×5 シートプレート。4×5 天板ステージのトレイに立つ |

出力仕様は注文にそのまま書き込みます：普通の PLA、積層ピッチは全パーツ 0.2 mm、インフィル 15 %、どのファイルにも[サポート](glossary.ja.md#サポート-supports)なし。すべてのパーツは平らな面をプレートに向けて出力し、ホルダー蓋の 2 点だけは仕上がりの上面を下に向けます。積層ピッチ、[インフィル](glossary.ja.md#インフィル-infill)、パーツごとの出力カードは [printing.ja.md](printing.ja.md#プリント設定) にあります。このページは「何を発注するか」だけを扱います。

> [!IMPORTANT]
> どのファイルも **160 × 160 mm** の[ビルドプレート](glossary.ja.md#ビルドプレートのサイズ-bed-size)に収まります。最大のパーツでも 154.8 mm です。プロトタイプの「280 × 300 mm 以上」という条件はなくなり、220 mm プレートに関する旧ドキュメントの警告も過去のものになりました。一般的なホビー機なら、全パーツを自宅で出力できます。

> [!WARNING]
> 白フィラメントは**マット必須**です。白の 2 点は拡散チャンバーそのもので、ストロボの光は拡散板に届くまでにこの壁で何度も反射します。シルクや光沢の白は発光部をホットスポットとして写し込みます。内側は塗装もコーティングもしないので、光沢で出力してしまうと後から直す方法はなく、マットで刷り直すしかありません。ショップには「希望」ではなく「要件」として伝えてください。「できればマットで」と言うと、機械に今かかっているフィラメントが出てきます。

白と黒を 1 回の注文にまとめるのは普通のことです。1 店舗、1 注文、2 色。支払う前に、フィラメント交換が別料金かどうかを確認してください。mask-6x6.stl は 6×6 を撮るときにしか使いませんが、フィラメント 1 g 程度なので、同じ注文から外す理由はありません。slide-plate-135.stl もオプションです。マウント済みスライドを持っているなら注文してください。cover-stage-4x5.stl と sheet-plate-4x5.stl は 4×5 の 2 点で、シートフィルムを撮る場合にだけ、下の一回り大きいアクリルと一緒に注文してください。

---

## 購入部品

### 買うもの

| 項目 | 仕様 | 数量 | 価格（CNY） |
|---|---|---|---|
| 乳白アクリル拡散板 | 2 mm、68 × 118 mm カット | 1（2 枚発注） | 5–10 |
| ネオジム磁石 | Ø8 × 2 mm、N35、普通の軸方向磁化の円板 | 32（予備を数個） | 8–15 |
| スチールシム | 10 × 10 × 1 mm の角板、または Ø10 × 1 mm の円板 | 4 | 2–5 |
| アンチニュートンガラス（任意） | 64 × 95 × 2 mm、片面 AN 処理。1 枚で両判型共用 | 1 | 15–30 |
| 黒の植毛シート（任意） | 粘着つき、A5 | 1 | 5–10 |
| 乳白アクリル拡散板、4×5 用（任意） | 2 mm、106 × 130 mm カット。4×5 天板ステージだけが使う | 1 | 8–15 |

最初の 3 行が標準ビルドの購入部品のすべてで、ねじは 1 か所もありません。残りの 3 行はオプションです。アンチニュートンガラスはプリントの押さえ窓インサート 2 枚をガラス 1 枚（両判型共用）で置き換えるもの、植毛シートは窓のまわりのステージ面の反射を消すもの、一回り大きい乳白板は 4×5 天板ステージの拡散板です。

発注上の注意が 2 つ。**拡散板は 2 枚**：乳白アクリルは輸送中にカット端が欠けやすく、しかも光路のど真ん中に置かれます。2 枚目のカット代はほとんどかかりませんが、送り直すと 1 週間かかります。プロトタイプからのアップグレードなら、旧拡散板（110 × 130 mm）は同じ 2 mm の乳半材です。アクリルを扱う店ならどこでも 68 × 118 mm に裁ち直してくれるので、この行は注文から消えます。**磁石は数個の予備を**：圧入は縁の欠けた磁石に容赦がなく、N35 の円板は 1 個数円です。

### 地域別の検索ワード

同じ部品でも言葉が違うと見つかりません。各行に 3 地域分を並べてあります。

| 項目 | 日本（Amazon.jp／モノタロウ／ヨドバシ） | 中国（タオバオ／1688） | その他の地域（英語） |
|---|---|---|---|
| 乳白アクリル拡散板 | `乳半アクリル板 2mm 切断` | `乳白亚克力板 定制 2mm` | `opal acrylic sheet 2 mm cut to size` |
| ネオジム磁石 | `ネオジム磁石 丸型 8×2` | `钕磁铁 8x2mm N35` | `neodymium disc magnet 8 × 2 mm N35` |
| スチールシム | `平座金 M5 外径10 鉄・ユニクロ` | `铁片 10x10x1` または `M5平垫片 外径10 铁` | `mild steel shim 10 × 10 × 1 mm` / `M5 steel washer, 10 mm OD` |
| アンチニュートンガラス | `アンチニュートンガラス` | `防牛顿环玻璃 定制` | `anti-Newton glass, cut to size` |
| 植毛シート | `植毛シート 黒 粘着` | `黑色植绒布 背胶 A5` | `self-adhesive black flocking sheet` |
| 3D プリント出力代行 | `3Dプリント 出力代行 PLA` | `3D打印 代打 PLA` | JLC3DP、PCBWay、Craftcloud、または地元のメイカースペース |

---

## 磁石

Ø8 × 2 mm・N35 のネオジム磁石が 32 個。ホルダーの 4 パーツ（底 2 点、蓋 2 点）にそれぞれ 8 個ずつ入ります。すべて手で圧入する締まりばめで、このビルドに接着剤は一滴も登場しません。

| 役割 | 仕組み |
|---|---|
| ホルダーを閉じておく | 蓋の 8 個と底の 8 個が向かい合い、ホルダー 1 台につき 8 組の引き合うペアになる |
| ホルダーを天板ステージに留める | 底の磁石が、天板ステージの座ぐりに面一で収まる 4 枚のスチールシムを底板越しに引き付ける。持ち上げれば外れ、判型の交換は数秒 |

32 個は予備込みで CNY 8–15 です。底の磁石が吸い付く相手が[スチールシム 4 枚](#購入部品)なので、この 2 行は同じ注文にまとめてください。シムを省くと、ホルダーをステージに留めるものが何もなくなります。

> [!WARNING]
> この磁石は皮膚を挟んで合わさると強く挟み込みますし、ばらのネオジム磁石は子どもやペットにとって深刻な誤飲事故のもとです。予備は蓋つきの容器に入れて保管してください。極性は表示されておらず、圧入は接着剤と大差ないほど外しにくいものです。底用と蓋用の磁石を 1 組ずつ合わせて引き合うことを確かめ、どれか 1 個でも押し込む**前に**それぞれの上面へ印を付けてください。向きを逆に圧入すると、蓋を押さえるどころか押し上げてしまい、掘り出そうとすればたいてい穴ごと駄目になります。手順は[ステップ 1 — マグネットを圧入する](assembly.ja.md#ステップ-1--マグネットを圧入する)にあります。

---

## 正しい部品を選ぶ

お金を払ったのに使えないものが届く、代表的な 6 パターンです。

| 部品 | ありがちな失敗 | 何を指定するか |
|---|---|---|
| [乳白](glossary.ja.md#乳白-opal)（オパール）アクリル拡散板 | フロスト（つや消し）アクリルを買ってしまう | 乳白は板そのものが乳白色で、板の内部で光を散らします。フロストは透明アクリルの片面を荒らしただけで、ストロボの発光部が写ります。「乳半、光拡散用、2 mm」と伝え、68 × 118 mm のカット寸法を指定してください。密度の高い板ほど光量を食う代わりに均一性が上がります。ストロボの出力には余裕があります。 |
| ネオジム磁石 | 厚さを間違える | ポケットは Ø8 × 2 mm の普通の軸方向磁化円板に合わせてあります。3 mm では飛び出して蓋を押し上げ、1 mm では深く沈みすぎて吸着しません。N35 が普通のグレードで、それで十分です。N52 は高いだけで、余分な吸着力の使い道がありません。 |
| スチールシム | ステンレスを買ってしまう | ステンレスの多くはほとんど磁石に付きませんが、この 4 枚は磁石に吸い付かせるためだけに存在します。鉄（ユニクロめっき等）を指定し、厚さは 1 mm まで。座ぐりの深さが 1 mm で、シムは面一に収まる必要があります。10 × 10 mm の角板でも Ø10 mm の円板でも入ります。 |
| アンチニュートンガラス | すりガラスを買ってしまう | アンチニュートンガラスはスキャナや引き伸ばし機の部品で、片面に目でほとんど分からないほど薄い処理があり、像を拡散させずにニュートンリングを抑えます。すりガラスは拡散板なので、シャープネスが壊れます。「片面アンチニュートン処理、64 × 95 × 2 mm」と指定してください。 |
| 黒の植毛シート | フェルトや光沢のシートを買ってしまう | 植毛シートは表面がベルベット状の粘着シートです。フェルトは厚すぎ、光沢のシートは反射します。つや消し黒・粘着つき。A5 が 1 枚あれば窓のまわりのステージ面を覆えます。 |

---

## 光源

| 項目 | 仕様 | 価格（CNY） |
|---|---|---|
| ホットシューストロボ、ブランド不問（基準機：NEEWER TT560） | 必須条件はマニュアル発光量のみ。基準機 TT560 は[ガイドナンバー（GN）](glossary.ja.md#ガイドナンバー-gn)38、[マニュアル 1/1–1/128](glossary.ja.md#マニュアル発光量-manual-power-fraction)（1 段刻み）、≈ 5600 K | 200–300 |
| ZENIKO T1 トリガーセット、または任意の 2.4 GHz セット | 送信機＋受信機 | 150–250 |

ストロボ本体は箱の中に入りません。机の上に平置きし、発光部を本体の完全に開いた前面開口に当てて、白い拡散チャンバーへ向けて発光させます。受信機もストロボに付けたまま、箱の外です。旧版の制約が消えたのはこの置き方のおかげです。電波はさえぎられず、電池交換で箱に触れる必要はなく、発光量の変更はストロボ本体のダイヤルでそのまま行えます。

ストロボ選びで本当に効くのは 1 点だけ、**発光量をマニュアルで決められること**です。[TTL](glossary.ja.md#ttl-through-the-lens-調光) も [HSS](glossary.ja.md#hss-ハイスピードシンクロ) もここでは何の役にも立ちません。そこにお金を払わないでください。プロトタイプのもう 1 つの条件だった「発光部が 90° 回ること」は、密閉筐体と一緒になくなりました。ストロボは寝かせたまま水平に発光します。

> [!NOTE]
> 「公開している STL は TT560 専用」というプロトタイプ時代の警告はなくなりました。箱のどの寸法もストロボ本体に依存しないので、確認すべき長さ・厚さの上限もありません。表に TT560 が残っているのは、安価で入手しやすい基準機としてであって、要件ではありません。手元にマニュアル発光のストロボがあるならそれを使ってください。

---

## 発注の順番

注文は 3 系統。すべて同じ日に出せて、互いに待つ必要はありません。

```mermaid
flowchart TD
  A[注文 1：STL 12 点<br/>1 店舗、白＋黒] --> D[到着時チェック]
  B[注文 2：乳白アクリル 68 × 118<br/>希望すればアンチニュートンガラスも] --> D
  C[注文 3：磁石とスチールシム<br/>任意で植毛シート] --> D
  D --> E[組み立て]
```

| 注文 | 標準的な納期 | いつ出すか |
|---|---|---|
| 1：STL 12 点 | 2–5 日＋輸送 | 最初。いちばん時間がかかる |
| 2：乳白アクリル、カット指定 | 3–7 日 | 同じ日に、1 と並行して |
| 3：磁石とスチールシム | 翌日〜数日 | いつでも |
| アンチニュートンガラス、植毛シート（任意） | 3–7 日 | 注文 2・3 と一緒に。箱が動いてからでも（プリントのインサートが標準構成） |

何かが何かを待つ工程はもうありません。「天板のポスト穴を実測してからインサートナットを買う」というプロトタイプ時代のルールは、インサートナットもろとも消えました。外注で保険を掛けたければ、先に 135 のホルダーを 1 組だけ出力してもらい、フィルムが滑るか確かめてください（[まず 135 ホルダーを 1 組だけ出力する](printing.ja.md#まず-135-ホルダーを-1-組だけ出力する)）。ここまでパーツが小さくなった今、これは念のためであって、かつてのような関門ではありません。

出力代行に支払う前に確認したい質問が 3 つあります。

- [ ] **マット**の白 PLA の在庫はありますか。
- [ ] 積層ピッチは店の標準に置き換えず、指定どおり 0.2 mm で出力してもらえますか。
- [ ] 白と黒を 1 注文にまとめた場合、フィラメント交換は別料金ですか。

> [!TIP]
> 梱包は引き続き重要です。プリントパーツには厚めのプチプチを頼み（壁は 2.4 mm しかありません）、アクリルはその内側に挟んで送ってもらってください。乳白アクリルは端が欠けます。

---

## 発注文面

そのまま貼り付けられる発注文面です。それぞれ、店が読む言語で書いてあります。内容は [printing.ja.md の「出力サービスへの発注」](printing.ja.md#出力サービスへの発注)と一致しています。あちらはパーツごとのリファレンスとして同じ指示を載せているので、片方の設定を変えたらもう片方も直してください。

12 ファイルはすべてサポート不要で、直感に反する置き方はホルダー蓋 2 点だけ。仕上がりの上面をプレートに向けます。以下の文面はどれもその点を明記しています。スライサーは自動では置き直してくれません。

<details>
<summary>3D プリント発注文面：日本の出力代行向け、日本語</summary>

```
合計 12 ファイルです。単位はミリ、スケール変更は不可。
普通の PLA：白 3 点、黒 9 点。白はマット必須です
（シルク／光沢はストロボの発光部が明るい斑点として写り込みます）。
積層ピッチは全ファイル 0.2 mm、
インフィル 15 %、全ファイル サポート不要。
置き方：すべて平らな面をプレートに。ただしホルダー蓋 2 点
（film-holder-135-lid / film-holder-120-lid）のみ、
仕上がりの上面をプレートに向けてください。

白 PLA 3 点：
  main-body.stl        124.8×154.8×75.6
  cover-stage.stl      124.8×154.8×10
  cover-stage-4x5.stl  124.8×154.8×10（オプション、4×5 用）
黒 PLA 9 点：
  film-holder-135-base.stl   94×120×5
  film-holder-135-lid.stl    94×120×3
  film-holder-120-base.stl   94×120×5
  film-holder-120-lid.stl    94×120×3
  pressure-window-135.stl    64×95×2
  pressure-window-120.stl    64×95×2
  mask-6x6.stl               94×80×1
  slide-plate-135.stl        94×120×5（オプション、マウント済みスライド用）
  sheet-plate-4x5.stl        112×138×5（オプション、4×5 用）

最大のパーツは 154.8 mm。ビルドプレートは 160×160 mm で足ります。
```

先方が細かい指定を嫌う場合は、この二点だけ守ってもらってください。

```
積層ピッチは全ファイル 0.2 mm、インフィル 15 %、サポート不要、
すべて平面をプレートに（ホルダー蓋 2 点のみ上面を下に）。白はマット必須。
```

念のため、まず 135 のホルダー底＋蓋を 1 組だけ出力し、フィルムが滑ることを確認してから残りを発注するのも手です。検索ワード：`3Dプリント 出力代行 PLA`

</details>

<details>
<summary>3D プリント発注文面：中国のショップ（タオバオ／1688）に送る中国語の文面</summary>

```
共 12 个 STL 文件，单位毫米，请勿缩放。
普通 PLA：白色 3 件、黑色 9 件。白色必须是哑光料
（丝面／亮面会把灯头映成亮斑）。
层高一律 0.2，填充 15%，全部免支撑。
摆放：全部平面朝下；只有两个夹上盖
（film-holder-135-lid / film-holder-120-lid）成品顶面朝下贴床。

白色 PLA 3 件：
  main-body.stl        124.8×154.8×75.6
  cover-stage.stl      124.8×154.8×10
  cover-stage-4x5.stl  124.8×154.8×10（可选，4×5 用）
黑色 PLA 9 件：
  film-holder-135-base.stl   94×120×5
  film-holder-135-lid.stl    94×120×3
  film-holder-120-base.stl   94×120×5
  film-holder-120-lid.stl    94×120×3
  pressure-window-135.stl    64×95×2
  pressure-window-120.stl    64×95×2
  mask-6x6.stl               94×80×1
  slide-plate-135.stl        94×120×5（可选，装框幻灯片用）
  sheet-plate-4x5.stl        112×138×5（可选，4×5 用）

最大件 154.8mm，160×160 打印床即可，不需要大尺寸机器。
```

店家嫌啰嗦时，只需咬住这两句：

```
层高 0.2、填充 15%、全部免支撑、平面朝下
（只有两个夹上盖顶面朝下）。白色必须哑光。
```

如需保险，可先让店家打一副 135 夹（夹底座＋夹上盖）试片条滑动，合适再打其余。搜索词：`3D打印 代打 PLA`

</details>

<details>
<summary>3D プリント発注文面：その他の地域、英語</summary>

```
12 STL files. Millimetres. Do not scale.
Plain PLA: 3 white parts, 9 black parts. White must be MATTE -
silk or gloss reproduces the flash head as a bright spot on the film.
0.2 mm layers on every file, 15% infill,
no supports on any file.
Placement: every part flat face down, except the two lids
(film-holder-135-lid, film-holder-120-lid): their finished TOP face
goes on the plate.

White PLA, 3 parts:
  main-body.stl        124.8 x 154.8 x 75.6
  cover-stage.stl      124.8 x 154.8 x 10
  cover-stage-4x5.stl  124.8 x 154.8 x 10   (optional, for 4x5)
Black PLA, 9 parts:
  film-holder-135-base.stl   94 x 120 x 5
  film-holder-135-lid.stl    94 x 120 x 3
  film-holder-120-base.stl   94 x 120 x 5
  film-holder-120-lid.stl    94 x 120 x 3
  pressure-window-135.stl    64 x 95 x 2
  pressure-window-120.stl    64 x 95 x 2
  mask-6x6.stl               94 x 80 x 1
  slide-plate-135.stl        94 x 120 x 5   (optional, for mounted slides)
  sheet-plate-4x5.stl        112 x 138 x 5  (optional, for 4x5)

Largest part 154.8 mm: a 160 x 160 mm bed is enough.
```

保険を掛けるなら、まず 135 のホルダー底と蓋を 1 組だけ出力し、フィルムストリップが滑るのを確認してから残り 10 ファイルを発注してください。

</details>

<details>
<summary>乳白アクリルとアンチニュートンガラスのカット発注文面：日本語、中国語、英語</summary>

日本（アクリル通販・レーザー加工ショップ）、アクリル：

```
乳半（乳白半透明）アクリル 厚 2 mm、68×118 mm に 2 枚切断してください。
（4×5 を使う場合は 106×130 mm も 1 枚。）
表面をつや消しにした透明板ではなく、板そのものが光を拡散する
乳半材でお願いします。
```

日本、アンチニュートンガラス（任意）：

```
アンチニュートンガラス（片面 AN 処理）、厚 2 mm、64×95 mm に 1 枚。
すりガラスではなく、スキャナや引き伸ばし機に使う
アンチニュートンガラスでお願いします。
```

中国（タオバオ／1688）、アクリル：

```
乳白半透明亚克力 2mm 厚，68×118mm，切 2 块。
（如做 4×5：另切 106×130mm 一块。）
要乳白（板体本身扩散），不要磨砂透明板。
```

中国、アンチニュートンガラス（任意）：

```
防牛顿环玻璃，单面 AN 处理，2mm 厚，裁 64×95mm 一片。
要扫描仪／放大机用的防牛顿环玻璃，不是磨砂玻璃。
```

その他の地域、アクリル：

```
Opal (white translucent, light-diffusing) acrylic, 2 mm thick,
cut 2 pieces at 68 x 118 mm.
(For 4x5: one more piece at 106 x 130 mm.)
Opal, not frosted clear - the sheet itself must diffuse, not just its surface.
```

その他の地域、アンチニュートンガラス（任意）：

```
Anti-Newton glass, single-side AN treatment, 2 mm thick,
one piece cut to 64 x 95 mm.
Scanner / enlarger AN glass - not ground or frosted glass.
```

いずれの場合も図面は不要です。カット寸法が仕様のすべてです。

</details>

### 店から難色を示されたら

| 言われること | 実際の意味 | どうするか |
|---|---|---|
| 「白は光沢しか在庫がありません」 | その表面が全コマにホットスポットとして写る | マットが入るまで待つか、白の 2 点を別の店へ。黒のパーツは影響を受けません。 |
| 「中を肉抜き／壁を薄くして材料を節約しましょうか」 | 頼んでいないモデル改変 | 断ってください。壁 2.4 mm、床 3.0 mm は設計値です。 |
| 「0.12 か 0.16 の積層のほうがきれいに出ますよ」 | 無断の仕様変更 | 全ファイル 0.2 mm。設計の高さグリッドが 0.2 mm なので、これより粗い積層では段差が層境界に載りません。それ以外は変えないでください。 |
| 「念のため全体にサポートを入れておきます」 | フィルムに面する面に傷が残る | どのファイルにもサポートは不要です。すべてサポートレスで設計されています。 |

---

## 部品が届いたら

磁石を 1 個でも圧入する前に、以下を確認してください。出力代行でいちばん多い事故は今も、スライサーの「プレートに合わせて縮小」が入ったままというものです。金尺で測れば捕まえられます。

- [ ] **本体**：外形 124.8 × 154.8 mm、床から壁の上端まで 75.6 mm。短ければファイルが縮小されています。出力全体を突き返してください。
- [ ] **天板ステージ**：124.8 × 154.8 mm。力を入れずに壁の上に載り、4 つの位置決めダボがそれぞれのダボ穴に収まること。
- [ ] **フィルムホルダー**：蓋が底に平らに載り、フィルムストリップが底の[溝](glossary.ja.md#溝-channel)を滑らかに通ること。
- [ ] **押さえ窓インサート**：それぞれのホルダー底のエレメント段に収まり、平らに座ること。
- [ ] **拡散板**：全面が均一に乳白で、透明に抜けた部分も明るい斑もないこと。天板ステージ裏面の受け溝に収まること。保護フィルムは組立まで貼ったままにし、そのとき**両面とも**剥がします。
- [ ] **スチールシム**：磁石が吸い付くこと（付かなければステンレスなので返品）。座ぐりに入れて面一になり、ステージ面から飛び出さないこと。
- [ ] **磁石**：底用と蓋用を 1 組ずつ合わせて引き合うことを確かめ、どれか 1 個でも圧入する前に上面へ印を付けること。
- [ ] **アンチニュートンガラス（買った場合）**：64 × 95 mm で、片面にごく薄いマットの AN 処理があること。

どれか 1 つでも落ちたものは、ビルドに入る前に[トラブルシューティング](troubleshooting.ja.md#プリント)行きです。全部にチェックが入ったら、自宅で出力する人は [printing.ja.md](printing.ja.md#組み立てる前に各パーツを確認する) のパーツごとの確認へ、外注した人はそのまま[組み立て](assembly.ja.md)へ進んでください。

---

← [はじめに](getting-started.ja.md) · [ドキュメント一覧](../README.ja.md#ドキュメント) · [3D プリント](printing.ja.md) →

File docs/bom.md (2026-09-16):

# Bill of materials and sourcing

**English** · [简体中文](bom.zh-CN.md) · [日本語](bom.ja.md)

> Everything you have to buy for a NeoBox. The v1 list is short, because the build needs no tools and no fasteners; each part comes with the specification that stops you buying the wrong version, plus copy-paste ordering text for shops in China, Japan and everywhere else.

**Contents:** [What it costs](#what-it-costs) · [What this repo does not buy for you](#what-this-repo-does-not-buy-for-you) · [Tools and consumables](#tools-and-consumables) · [Printed parts](#printed-parts) · [Parts you buy](#parts-you-buy) · [Magnets](#magnets) · [Getting the right part](#getting-the-right-part) · [Light source](#light-source) · [Ordering sequence](#ordering-sequence) · [Vendor scripts](#vendor-scripts) · [When the parts arrive](#when-the-parts-arrive)

---

## What it costs

Prices are indicative, in CNY, from Chinese marketplaces (Taobao / 1688) as of August 2026.

| Group | What it covers | Price (CNY) |
|---|---|---|
| 3D printing | the 12 printed parts (4 optional), white and black PLA | 50–110 |
| Diffuser | opal acrylic, 2 mm, cut 68 × 118 mm | 5–10 |
| Magnets and shims | 32 neodymium magnets, 4 steel shims | 10–20 |
| **Whole build, excluding the flash** | everything above, once | **CNY 65–140 · JPY 1,500–3,000** |

> [!NOTE]
> Added line by line, the extremes bracket exactly CNY 65–140, and the print order is most of it. That is roughly a third of what the printed prototype (internal revision 4) cost (CNY 250–420): the studs, nuts, heat-set inserts, foam, grommets and paint are all gone, and every printed part shrank. If you own a prototype, re-cutting its diffuser takes the acrylic line to zero. The JPY figure is the same build expressed in yen, not a quote for buying every line inside Japan.

The two optional upgrades are priced separately and never inside that total: [anti-Newton glass](#parts-you-buy) at CNY 15–30 and the [flocking sheet](#parts-you-buy) at CNY 5–10. Both together come to about CNY 20–40.

---

## What this repo does not buy for you

NeoBox is a light source. It is one half of a [camera scanning](glossary.md#camera-scanning) setup (photographing film with a digital camera instead of running it through a scanner), and the other half is yours.

| You must already own or buy | What it does |
|---|---|
| Camera body | any body with manual exposure and raw files |
| Macro-capable lens | you photograph a frame as small as 24 × 36 mm; an ordinary lens will not focus that close |
| Copy stand, or a tripod with a horizontal or reversible column | holds the camera square above the film at a repeatable height |
| Flash and trigger set | any hot-shoe flash with manual power control; the reference pair is specified and priced under [Light source](#light-source) |
| Trigger transmitter for the camera hot shoe | supplied with the reference trigger set, but that set is not in the build cost |
| Remote release | so you do not push the camera while it exposes |
| Inversion software | turns the raw negative into a positive image |

> [!IMPORTANT]
> CNY 65–140 buys the box and nothing else. It excludes the flash and trigger (CNY 350–550 together for the reference pair) and every camera-side item above. Read [what you must already own](getting-started.md#what-you-must-already-own) before you order anything.

Choosing and using the camera side is [scanning.md](scanning.md#camera-side-equipment). This document stops at the parts that make the box.

---

## Tools and consumables

For the first time, this section lists no requirements. The v1 build has no screws, no glue, no paint and no tools: the magnets press in by hand and everything else drops into place. What stays on the desk is for using the box, not building it.

| Tool or consumable | What it is for | Specification |
|---|---|---|
| Rocket blower | dusting the diffuser, the inserts and the [film gate](glossary.md#film-gate), and the AN glass before it goes in, if you bought one | a bulb blower, not canned air |
| Small flat mirror, about 30 mm | the parallelism method: it sits on the stage while you centre the lens's own reflection in the viewfinder | any flat mirror offcut |
| Cotton gloves, or clean hands | handling film by its edges | — |
| Steel rule or calipers | the arrival checks at the foot of this page | 200 mm reaches across the 154.8 mm parts |

Thirty-two small, strong magnets still want reading about before you start: [Tools and safety](assembly.md#tools-and-safety).

---

## Printed parts

One-page manufacturing overview: a section through the box, every printed part with its size and print orientation, and the bought parts

The build is **12 printed parts**: 3 white, 9 black; the 6×6 mask, the slide plate and the two 4×5 parts are optional, and all of them are support-free.

| File | Colour | Footprint (mm) | What it is |
|---|---|---|---|
| main-body.stl | white | 124.8 × 154.8 × 75.6 | main box: floor and three walls, front fully open |
| cover-stage.stl | white | 124.8 × 154.8 × 10.0 | cover-stage: lid and film stage merged into one part |
| film-holder-135-base.stl | black | 94 × 120 × 5 | 135 holder base, 25 × 37 gate |
| film-holder-135-lid.stl | black | 94 × 120 × 3 | 135 holder lid |
| film-holder-120-base.stl | black | 94 × 120 × 5 | 120 holder base, 57 × 85 gate (full 6×9 frame) |
| film-holder-120-lid.stl | black | 94 × 120 × 3 | 120 holder lid |
| pressure-window-135.stl | black | 64 × 95 × 2 | 135 pressure-window insert |
| pressure-window-120.stl | black | 64 × 95 × 2 | 120 pressure-window insert |
| mask-6x6.stl | black | 94 × 80 × 1 | 6×6 mask, sits under the 120 base |
| slide-plate-135.stl | black | 94 × 120 × 5 | slide plate for mounted 135 slides, stands in the tray in place of the 135 holder |
| cover-stage-4x5.stl | white | 124.8 × 154.8 × 10.0 | 4×5 cover-stage, replaces cover-stage.stl on the same main body; takes the larger acrylic |
| sheet-plate-4x5.stl | black | 112 × 138 × 5 | 4×5 sheet plate, stands in the 4×5 cover-stage's tray |

The print spec, written straight into the order: ordinary PLA, 0.2 mm layers on every file, 15 % infill, no [supports](glossary.md#supports) on any file. Every part prints flat face down except the two holder lids, which print top face down. Layer height, [infill](glossary.md#infill) and the per-part cards are in [printing.md](printing.md#print-settings); this page only tells you what to order.

> [!IMPORTANT]
> Every file fits a **160 × 160 mm** [bed](glossary.md#bed-size): the largest footprint in the build is 154.8 mm. The prototype's 280 × 300 mm requirement is gone, and so are the old warnings about 220 mm beds. Any common hobby printer prints the whole set at home.

> [!WARNING]
> White filament must be **matte**. The two white parts are the diffusion cavity: the flash bounces off those walls several times before it reaches the diffuser, and silk or glossy white reproduces the flash head as a hot spot. The inside is never painted or coated, so a glossy part cannot be fixed after it is printed, only reprinted in matte. Tell the shop this is a requirement, not a preference: "matte preferred" gets you whatever is already loaded on the machine.

White and black in one order is normal: one shop, one order, two colours. Ask before you pay whether the filament change is charged separately. mask-6x6.stl is only used when shooting 6×6, but at a gram of filament there is no reason to leave it out of the order. slide-plate-135.stl is optional too: order it if you have mounted slides. cover-stage-4x5.stl and sheet-plate-4x5.stl are the 4×5 pair: order them, with the larger acrylic below, only if you shoot sheet film.

---

## Parts you buy

### What to buy

| Item | Specification | Qty | Price (CNY) |
|---|---|---|---|
| Opal acrylic diffuser | 2 mm, cut 68 × 118 mm | 1 (order 2) | 5–10 |
| Neodymium magnet | Ø8 × 2 mm, N35, plain axially-magnetised disc | 32 (order a few spares) | 8–15 |
| Steel shim | 10 × 10 × 1 mm square, or Ø10 × 1 mm round | 4 | 2–5 |
| Anti-Newton glass (optional) | 64 × 95 × 2 mm, one face AN; one sheet serves both formats | 1 | 15–30 |
| Black flocking sheet (optional) | self-adhesive, A5 | 1 | 5–10 |
| Opal acrylic diffuser, 4×5 (optional) | 2 mm, cut 106 × 130 mm; only the 4×5 cover-stage uses it | 1 | 8–15 |

The first three lines are the entire bought-parts list of the default build, with nothing threaded anywhere. The last three are optional: the AN glass replaces the two printed pressure-window inserts with one sheet that serves both formats, the flocking sheet kills glare on the stage surface around the window, and the larger opal sheet is the diffuser of the 4×5 cover-stage.

Two ordering notes. **Order 2 diffusers**: opal acrylic chips at the cut edges in transit, it sits directly in the optical path, and a second cut costs almost nothing while a second shipping cycle costs a week. And if you are upgrading from a prototype, its 110 × 130 mm diffuser is the same 2 mm opal; any acrylic shop will trim it to 68 × 118 mm, and the line drops out of the order. **Order a few spare magnets**: press-fitting is unforgiving of a chipped edge, and N35 discs cost pennies each.

### Search terms by region

The same part is unfindable with the wrong words, so each row carries all three.

| Item | China (Taobao / 1688) | Japan (Amazon.jp / Monotaro / Yodobashi) | Elsewhere (English) |
|---|---|---|---|
| Opal acrylic diffuser | `乳白亚克力板 定制 2mm` | `乳半アクリル板 2mm 切断` | `opal acrylic sheet 2 mm cut to size` |
| Neodymium magnet | `钕磁铁 8x2mm N35` | `ネオジム磁石 丸型 8×2` | `neodymium disc magnet 8 × 2 mm N35` |
| Steel shim | `铁片 10x10x1` or `M5平垫片 外径10 铁` | `平座金 M5 外径10 鉄・ユニクロ` | `mild steel shim 10 × 10 × 1 mm` / `M5 steel washer, 10 mm OD` |
| Anti-Newton glass | `防牛顿环玻璃 定制` | `アンチニュートンガラス` | `anti-Newton glass, cut to size` |
| Black flocking sheet | `黑色植绒布 背胶 A5` | `植毛シート 黒 粘着` | `self-adhesive black flocking sheet` |
| 3D printing service | `3D打印 代打 PLA` | `3Dプリント 出力代行 PLA` | JLC3DP, PCBWay, Craftcloud, or a local makerspace |

---

## Magnets

Thirty-two Ø8 × 2 mm N35 magnets, eight in each of the four holder parts: both bases, both lids. They press into their pockets by hand, interference-fit, with no glue anywhere.

| What they do | How |
|---|---|
| Hold each holder shut | the 8 lid magnets face the 8 base magnets: 8 attracting pairs per holder |
| Hold the holder on the cover-stage | the base magnets pull, through the holder floor, on the 4 steel shims sitting flush in the cover-stage; lift and it pops free, so the format swap takes seconds |

CNY 8–15 buys all 32 with spares. What the base magnets grip is the [4 steel shims](#parts-you-buy), so the two lines belong in one order: skip the shims and nothing holds the holder to the stage.

> [!WARNING]
> Two of these magnets meeting across a fold of skin pinch hard, and loose neodymium magnets are a serious swallowing hazard for children and pets. Keep the spares in a closed container. Polarity is not marked, and a press-fit is not much easier to undo than glue: pair each base magnet with its lid magnet, confirm they attract, and mark the up-face of each **before** pressing any of them home. A magnet pressed in the wrong way round pushes the lid off instead of holding it shut, and digging it out usually wrecks the pocket. The procedure is [Step 1 — Press in the magnets](assembly.md#step-1--press-in-the-magnets).

---

## Getting the right part

Six ways to spend the money and receive something that does not work.

| Part | The mistake | What to specify |
|---|---|---|
| [Opal](glossary.md#opal) acrylic diffuser | Buying frosted acrylic | Opal is milky right through and scatters inside the sheet. Frosted is clear acrylic with one surface roughened, and it will show the flash head. Say "opal, light-diffusing, 2 mm" and give the 68 × 118 mm cut size. A denser grade costs light and buys evenness; the flash has power to spare. |
| Neodymium magnet | Buying the wrong thickness | The pockets fit Ø8 × 2 mm plain, axially magnetised discs. A 3 mm disc stands proud and holds the lid open; a 1 mm disc sits too deep to grip. N35 is the ordinary grade and is enough; N52 costs more and adds pull you do not need. |
| Steel shim | Buying stainless | Most stainless is barely magnetic, and these four exist only to give the magnets something to grip. Carbon steel or zinc-plated, 1 mm thick and no more: the counterbore is 1 mm deep and the shim must sit flush. 10 × 10 mm square or Ø10 mm round both fit. |
| Anti-Newton glass | Buying ground or frosted glass | AN glass is a scanner and enlarger part: one face carries an etch so faint you can barely see it, which stops Newton's rings without diffusing the image. Ground or frosted glass is a diffuser and destroys sharpness. Specify single-side anti-Newton, 64 × 95 × 2 mm. |
| Black flocking sheet | Buying felt or glossy vinyl | Flocking is a velvet-surfaced self-adhesive sheet; felt is too thick and vinyl is shiny. Matte black, self-adhesive; one A5 sheet covers the stage surface around the window. |

---

## Light source

| Item | Specification | Price (CNY) |
|---|---|---|
| Hot-shoe flash, any brand (reference: NEEWER TT560) | manual power control is the only hard requirement; the reference TT560: [GN38](glossary.md#guide-number), [manual 1/1–1/128](glossary.md#manual-power-fraction) in full stops, ≈ 5600 K | 200–300 |
| ZENIKO T1 trigger set, or any 2.4 GHz set | transmitter + receiver | 150–250 |

The flash never goes inside the box. It lies flat on the desk with its head against the fully open front of the main body and fires into the white cavity; the receiver stays on it, outside. That placement is why the old constraints are gone: the radio signal is unobstructed, batteries change without touching the box, and power changes are made on the flash itself, in the open.

Only one thing matters when you choose a flash: **manual power control**. [TTL](glossary.md#ttl) and [HSS](glossary.md#hss) do nothing here, so do not pay for them. And the prototype's second requirement, a head that turns 90°, went away with the enclosure: the flash fires level, lying flat.

> [!NOTE]
> The prototype-era warning that "the published STL files fit the TT560 and nothing else" is gone. No dimension of the box depends on the flash body, so there is no length or thickness limit to check. The TT560 stays in the table as a cheap, widely available reference, not a requirement; use whatever manual flash you own.

---

## Ordering sequence

Three orders, and all of them can go out on the same day. Nothing waits on anything else.

```mermaid
flowchart TD
  A[Order 1: the twelve STLs<br/>one shop, white + black] --> D[Arrival checks]
  B[Order 2: opal acrylic 68 × 118<br/>plus the AN glass, if wanted] --> D
  C[Order 3: magnets and shims<br/>plus the flocking sheet] --> D
  D --> E[Assembly]
```

| Order | Typical lead time | When to place it |
|---|---|---|
| 1: the twelve STLs | 2–5 days plus shipping | first; it is the long pole |
| 2: opal acrylic, cut to size | 3–7 days | the same day, in parallel |
| 3: magnets and shims | next day to a few days | any time |
| AN glass and flocking (optional) | 3–7 days | with orders 2 and 3, or after the box works; the printed inserts are the default |

Nothing gates anything: the prototype's measure-first rule for heat-set inserts vanished with the inserts themselves. Outsourcing and want insurance anyway? Have the shop run one 135 holder base and lid first and check that a film strip slides: [Print one 135 holder first](printing.md#print-one-135-holder-first). With parts this small it is a nicety, not the gate it used to be.

Three questions to ask a print shop before you pay:

- [ ] Do you have **matte** white PLA in stock?
- [ ] Will you keep the 0.2 mm layer height as written, rather than switching to your house default?
- [ ] White and black in one order: is the filament change charged separately?

> [!TIP]
> Packing still matters. Ask for bubble wrap around the printed parts (the walls are 2.4 mm), and ask for the acrylic to travel sandwiched between them, because opal acrylic chips at the edges.

---

## Vendor scripts

Copy-paste briefs, each written in the language the shop reads. They agree with [Ordering from a print service](printing.md#ordering-from-a-print-service), which carries the same instructions as a per-part reference; change a setting in one place and change it in the other.

All twelve files print support-free, and the only non-obvious placement is the two holder lids: finished top face down on the plate. Every brief below says so; slicers will not place parts for you.

<details>
<summary>3D printing brief: China (Taobao / 1688), in Chinese</summary>

```
共 12 个 STL 文件，单位毫米，请勿缩放。
普通 PLA：白色 3 件、黑色 9 件。白色必须是哑光料
（丝面／亮面会把灯头映成亮斑）。
层高一律 0.2，填充 15%，全部免支撑。
摆放：全部平面朝下；只有两个夹上盖
（film-holder-135-lid / film-holder-120-lid）成品顶面朝下贴床。

白色 PLA 3 件：
  main-body.stl        124.8×154.8×75.6
  cover-stage.stl      124.8×154.8×10
  cover-stage-4x5.stl  124.8×154.8×10（可选，4×5 用）
黑色 PLA 9 件：
  film-holder-135-base.stl   94×120×5
  film-holder-135-lid.stl    94×120×3
  film-holder-120-base.stl   94×120×5
  film-holder-120-lid.stl    94×120×3
  pressure-window-135.stl    64×95×2
  pressure-window-120.stl    64×95×2
  mask-6x6.stl               94×80×1
  slide-plate-135.stl        94×120×5（可选，装框幻灯片用）
  sheet-plate-4x5.stl        112×138×5（可选，4×5 用）

最大件 154.8mm，160×160 打印床即可，不需要大尺寸机器。
```

店家嫌啰嗦时，只需咬住这两句：

```
层高 0.2、填充 15%、全部免支撑、平面朝下
（只有两个夹上盖顶面朝下）。白色必须哑光。
```

如需保险，可先让店家打一副 135 夹（夹底座＋夹上盖）试片条滑动，合适再打其余。搜索词：`3D打印 代打 PLA`

</details>

<details>
<summary>3D printing brief: Japan, in Japanese</summary>

```
合計 12 ファイルです。単位はミリ、スケール変更は不可。
普通の PLA：白 3 点、黒 9 点。白はマット必須です
（シルク／光沢はストロボの発光部が明るい斑点として写り込みます）。
積層ピッチは全ファイル 0.2 mm、
インフィル 15 %、全ファイル サポート不要。
置き方：すべて平らな面をプレートに。ただしホルダー蓋 2 点
（film-holder-135-lid / film-holder-120-lid）のみ、
仕上がりの上面をプレートに向けてください。

白 PLA 3 点：
  main-body.stl        124.8×154.8×75.6
  cover-stage.stl      124.8×154.8×10
  cover-stage-4x5.stl  124.8×154.8×10（オプション、4×5 用）
黒 PLA 9 点：
  film-holder-135-base.stl   94×120×5
  film-holder-135-lid.stl    94×120×3
  film-holder-120-base.stl   94×120×5
  film-holder-120-lid.stl    94×120×3
  pressure-window-135.stl    64×95×2
  pressure-window-120.stl    64×95×2
  mask-6x6.stl               94×80×1
  slide-plate-135.stl        94×120×5（オプション、マウント済みスライド用）
  sheet-plate-4x5.stl        112×138×5（オプション、4×5 用）

最大のパーツは 154.8 mm。ビルドプレートは 160×160 mm で足ります。
```

先方が細かい指定を嫌う場合は、この二点だけ守ってもらってください。

```
積層ピッチは全ファイル 0.2 mm、インフィル 15 %、サポート不要、
すべて平面をプレートに（ホルダー蓋 2 点のみ上面を下に）。白はマット必須。
```

念のため、まず 135 のホルダー底＋蓋を 1 組だけ出力し、フィルムが滑ることを確認してから残りを発注するのも手です。検索ワード：`3Dプリント 出力代行 PLA`

</details>

<details>
<summary>3D printing brief: everywhere else, in English</summary>

```
12 STL files. Millimetres. Do not scale.
Plain PLA: 3 white parts, 9 black parts. White must be MATTE -
silk or gloss reproduces the flash head as a bright spot on the film.
0.2 mm layers on every file, 15% infill,
no supports on any file.
Placement: every part flat face down, except the two lids
(film-holder-135-lid, film-holder-120-lid): their finished TOP face
goes on the plate.

White PLA, 3 parts:
  main-body.stl        124.8 x 154.8 x 75.6
  cover-stage.stl      124.8 x 154.8 x 10
  cover-stage-4x5.stl  124.8 x 154.8 x 10   (optional, for 4x5)
Black PLA, 9 parts:
  film-holder-135-base.stl   94 x 120 x 5
  film-holder-135-lid.stl    94 x 120 x 3
  film-holder-120-base.stl   94 x 120 x 5
  film-holder-120-lid.stl    94 x 120 x 3
  pressure-window-135.stl    64 x 95 x 2
  pressure-window-120.stl    64 x 95 x 2
  mask-6x6.stl               94 x 80 x 1
  slide-plate-135.stl        94 x 120 x 5   (optional, for mounted slides)
  sheet-plate-4x5.stl        112 x 138 x 5  (optional, for 4x5)

Largest part 154.8 mm: a 160 x 160 mm bed is enough.
```

If you want the insurance step: print one 135 holder base and lid first, check that a film strip slides, then order the remaining ten files.

</details>

<details>
<summary>Opal acrylic and anti-Newton glass cutting briefs: Chinese, Japanese and English</summary>

China (Taobao / 1688), acrylic:

```
乳白半透明亚克力 2mm 厚，68×118mm，切 2 块。
（如做 4×5：另切 106×130mm 一块。）
要乳白（板体本身扩散），不要磨砂透明板。
```

China, AN glass (optional):

```
防牛顿环玻璃，单面 AN 处理，2mm 厚，裁 64×95mm 一片。
要扫描仪／放大机用的防牛顿环玻璃，不是磨砂玻璃。
```

Japan, acrylic:

```
乳半（乳白半透明）アクリル 厚 2 mm、68×118 mm に 2 枚切断してください。
（4×5 を使う場合は 106×130 mm も 1 枚。）
表面をつや消しにした透明板ではなく、板そのものが光を拡散する
乳半材でお願いします。
```

Japan, AN glass (optional):

```
アンチニュートンガラス（片面 AN 処理）、厚 2 mm、64×95 mm に 1 枚。
すりガラスではなく、スキャナや引き伸ばし機に使う
アンチニュートンガラスでお願いします。
```

Everywhere else, acrylic:

```
Opal (white translucent, light-diffusing) acrylic, 2 mm thick,
cut 2 pieces at 68 x 118 mm.
(For 4x5: one more piece at 106 x 130 mm.)
Opal, not frosted clear - the sheet itself must diffuse, not just its surface.
```

Everywhere else, AN glass (optional):

```
Anti-Newton glass, single-side AN treatment, 2 mm thick,
one piece cut to 64 x 95 mm.
Scanner / enlarger AN glass - not ground or frosted glass.
```

No drawing is needed for any of these; the cut size is the whole specification.

</details>

### If the shop pushes back

| What you hear | What it means | What to do |
|---|---|---|
| "I only have glossy white in stock" | The finish becomes a hot spot on every frame | Wait for matte, or move the two white parts to another shop. Black parts are unaffected. |
| "Shall I hollow it out / thin the walls to save material?" | An unrequested model edit | No. Walls are 2.4 mm and the floor is 3.0 mm by design. |
| "0.12 or 0.16 layers will look nicer" | A silent spec change | 0.2 mm on every file: the design's height grid is 0.2 mm, and coarser layers land the steps between boundaries. Nothing else changes. |
| "Supports everywhere, to be safe" | Scars on the film-facing surfaces | No supports on any file. Every part is designed to print support-free. |

---

## When the parts arrive

Check these before you press in a single magnet. The commonest print-service accident is still a slicer left on "scale to fit the plate", and a steel rule catches it.

- [ ] **Main body**: outside 124.8 × 154.8 mm, 75.6 mm from the floor to the wall tops. If it is short, the file was scaled: reject the whole print.
- [ ] **Cover-stage**: 124.8 × 154.8 mm, and it drops onto the wall tops with the four locating tenons finding their notches without force.
- [ ] **Holders**: each lid sits flat on its base, and a strip of film slides through the base [channel](glossary.md#channel).
- [ ] **Pressure-window inserts**: each drops onto the element ledge in its holder base and sits flat.
- [ ] **Diffuser**: evenly milky right through, with no clear window and no bright patch; it fits the recess on the underside of the cover-stage. Leave the protective film on until assembly, then peel it from **both** faces.
- [ ] **Steel shims**: a magnet sticks to them (if not, they are stainless: return them), and each sits flush in its counterbore, not proud of the stage surface.
- [ ] **Magnets**: pair each base magnet with a lid magnet, confirm they attract, and mark the up-face of each before pressing any of them in.
- [ ] **AN glass, if bought**: 64 × 95 mm, and one face carries the faint matte AN sheen.

Anything that fails one of these belongs in [Troubleshooting](troubleshooting.md#printing) before it goes anywhere near the build. With every box ticked, go on to [printing](printing.md#check-each-part-before-you-assemble) if you are printing at home, or straight to assembly if you are not.

---

← [Getting started](getting-started.md) · [Documentation index](../README.md#documentation) · [Printing](printing.md) →

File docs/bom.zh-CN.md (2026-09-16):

# 物料清单与采购

[English](bom.md) · **简体中文** · [日本語](bom.ja.md)

> 做一台 NeoBox 要买的全部东西。到了 v1 这份清单变短了，因为整机不需要任何工具、任何紧固件；每一项都写清了能让你避开错误版本的规格，并附上可直接复制给中国、日本及其他地区店家的下单话术。

**目录：**[造价](#造价) · [本仓库不替你买的东西](#本仓库不替你买的东西) · [工具与耗材](#工具与耗材) · [打印件](#打印件) · [采购件](#采购件) · [磁铁](#磁铁) · [买对规格](#买对规格) · [光源](#光源) · [下单顺序](#下单顺序) · [给店家的话术](#给店家的话术) · [到货检查](#到货检查)

---

## 造价

价格为参考价，取自 2026 年 8 月的中国电商平台（淘宝／1688），单位人民币。

| 分组 | 包含内容 | 价格（CNY） |
|---|---|---|
| 3D 打印 | 12 个打印件（4 个可选），白色与黑色 PLA | 50–110 |
| 扩散板 | 乳白亚克力，2 mm，切 68 × 118 mm | 5–10 |
| 磁铁与垫片 | 32 颗钕磁铁、4 片钢垫片 | 10–20 |
| **整台箱子，不含闪光灯** | 以上全部，各一份 | **CNY 65–140 · JPY 1,500–3,000** |

> [!NOTE]
> 逐行按极值相加正好是 CNY 65–140，其中大头是打印单。这个数字大约只有原型机（CNY 250–420）的三分之一：螺杆、螺母、热熔铜螺母、海绵条、过线圈和喷漆全没了，每个打印件也都缩小了。手上有原型机的话，把旧扩散板裁小续用，亚克力这一行就直接归零。JPY 那个数字是同一台箱子折成日元的结果，不是在日本本地逐项采购的报价。

两件可选升级另计，从不含在上述总价里：[防牛顿环玻璃](#采购件) CNY 15–30、[植绒贴](#采购件) CNY 5–10，两件全买约 CNY 20–40。

---

## 本仓库不替你买的东西

NeoBox 只是一个光源。它是[相机翻拍](glossary.zh-CN.md#相机翻拍)（camera scanning，用数码相机拍摄胶片，而不是把胶片送进扫描仪）这套方案的一半，另一半得你自己准备。

| 你必须已经有、或者另外去买 | 它负责什么 |
|---|---|
| 机身 | 任何能手动曝光、能出 raw 的机身 |
| 具备微距能力的镜头 | 你要拍的画幅最小只有 24 × 36 mm，普通镜头对不到这么近 |
| 翻拍台（copy stand），或带横臂或可倒置中轴的三脚架 | 把相机端正地架在胶片正上方，而且高度可重复 |
| 闪光灯与引闪套装 | 任何功率手动可调的热靴闪光灯都行，参考组合与价格见[光源](#光源) |
| 装在相机热靴上的引闪发射器 | 参考引闪套装自带，但那套本来就不算在箱子的造价里 |
| 快门线或遥控器 | 曝光的时候不至于碰到相机 |
| 反相（inversion）软件 | 把 raw 负片转成正像 |

> [!IMPORTANT]
> CNY 65–140 买到的只有箱子。它不含闪光灯和引闪（参考组合两件合计 CNY 350–550），也不含上表里任何相机端的器材。下任何一单之前，先读[入门指南](getting-started.zh-CN.md#你需要自备的器材)里"你需要自备的器材"一节。

相机端怎么选、怎么用，写在[扫描文档](scanning.zh-CN.md#相机端器材)里。本页只管构成箱子的那些零件。

---

## 工具与耗材

这一节头一次列不出任何硬性要求。v1 整机没有螺丝、没有胶水、没有喷漆、也不需要任何工具：磁铁用手压入，其余零件全靠放置到位。下面留在桌上的东西是用箱子时要的，不是装箱子时要的。

| 工具或耗材 | 用来做什么 | 规格 |
|---|---|---|
| 吹气球 | 吹扩散板、插片和[片门](glossary.zh-CN.md#片门)；买了防牛顿环玻璃的话，装进去之前也要吹 | 皮吹球，不要用高压气罐 |
| 约 30 mm 的小平面镜 | 平行度校准：把镜子放在台面上，在取景器里让镜头自己的倒影居中 | 任何平整的镜子边角料 |
| 棉手套，或者洗干净的手 | 只捏片条的边缘 | — |
| 钢尺或卡尺 | 本页末尾的到货检查 | 200 mm 就够量 154.8 mm 的零件 |

32 颗又小又强的磁铁，动手之前仍然值得先读一遍：[装配文档](assembly.zh-CN.md#工具与安全)里的"工具与安全"。

---

## 打印件

一页式制造总览：箱体剖面、每个打印件的尺寸与打印朝向，以及需要采购的零件

整机共 **12 个打印件**：白 3 件、黑 9 件，其中 6×6 遮幅插片、幻灯片板和两个 4×5 件可选，全部免支撑。

| 文件 | 颜色 | 外形（mm） | 是什么 |
|---|---|---|---|
| main-body.stl | 白 | 124.8 × 154.8 × 75.6 | 主箱：箱底加三面墙，前面完全敞开 |
| cover-stage.stl | 白 | 124.8 × 154.8 × 10.0 | 顶盖台：顶盖与胶片台合并成的一个零件 |
| film-holder-135-base.stl | 黑 | 94 × 120 × 5 | 135 夹底座，窗口 25 × 37 |
| film-holder-135-lid.stl | 黑 | 94 × 120 × 3 | 135 夹上盖 |
| film-holder-120-base.stl | 黑 | 94 × 120 × 5 | 120 夹底座，窗口 57 × 85（6×9 整格） |
| film-holder-120-lid.stl | 黑 | 94 × 120 × 3 | 120 夹上盖 |
| pressure-window-135.stl | 黑 | 64 × 95 × 2 | 135 压片窗插片 |
| pressure-window-120.stl | 黑 | 64 × 95 × 2 | 120 压片窗插片 |
| mask-6x6.stl | 黑 | 94 × 80 × 1 | 6×6 遮幅插片，垫在 120 底座下方 |
| slide-plate-135.stl | 黑 | 94 × 120 × 5 | 装框 135 幻灯片用的幻灯片板，代替 135 胶片夹立在托盘里 |
| cover-stage-4x5.stl | 白 | 124.8 × 154.8 × 10.0 | 4×5 顶盖台，在同一只主箱上代替 cover-stage.stl；配更大的那块亚克力 |
| sheet-plate-4x5.stl | 黑 | 112 × 138 × 5 | 4×5 片板，立在 4×5 顶盖台的托盘里 |

打印规格直接写进订单：普通 PLA，层高一律 0.2 mm，填充 15%，任何文件都不加[支撑](glossary.zh-CN.md#支撑)。所有零件平面朝下打印，只有两个夹上盖顶面朝下。层高、[填充](glossary.zh-CN.md#填充)和每个零件的参数卡，都在[打印文档](printing.zh-CN.md#打印参数)里。本页只告诉你要下什么单。

> [!IMPORTANT]
> 每个文件都放得进 **160 × 160 mm** 的[打印床](glossary.zh-CN.md#打印床尺寸)：整机最大的外形只有 154.8 mm。原型机那条 280 × 300 mm 的要求没有了，旧文档里关于 220 mm 打印床的告警也一并作废。任何常见的爱好级打印机都能在家打完整套。

> [!WARNING]
> 白色耗材必须是**哑光**的。两个白色件就是混光腔本身：闪光在这些墙面上反弹好几次才到扩散板，丝面和亮面白料会把灯头映成一块亮斑。内壁永远不喷漆、不做涂层，所以亮面的件打出来没法补救，只能换哑光料重打。要明确告诉店家这是硬性要求，不是偏好：说"最好用哑光"，机器上装着什么料就给你打什么料。

白色和黑色放在同一单里打是常规做法：一家店、一个订单、两种颜色。付款前先问清楚换料要不要另外收费。mask-6x6.stl 只在拍 6×6 时用，但它只费一克料，没有理由不放进同一单。slide-plate-135.stl 也是可选的：有装框幻灯片就把它加进去。cover-stage-4x5.stl 和 sheet-plate-4x5.stl 是 4×5 那一对：只在你拍页片时才连同下面那块更大的亚克力一起下单。

---

## 采购件

### 要买什么

| 项目 | 规格 | 数量 | 价格（CNY） |
|---|---|---|---|
| 乳白亚克力扩散板 | 2 mm，切 68 × 118 mm | 1（下单买 2 片） | 5–10 |
| 钕磁铁 | Ø8 × 2 mm，N35，普通轴向充磁圆片 | 32（多买几颗备用） | 8–15 |
| 钢垫片 | 10 × 10 × 1 mm 方片，或 Ø10 × 1 mm 圆片 | 4 | 2–5 |
| 防牛顿环玻璃（可选） | 64 × 95 × 2 mm，单面 AN 处理；一片两幅面通用 | 1 | 15–30 |
| 黑色植绒贴（可选） | 背胶，A5 | 1 | 5–10 |
| 乳白亚克力扩散板，4×5（可选） | 2 mm，切 106 × 130 mm；只有 4×5 顶盖台用它 | 1 | 8–15 |

前三行就是默认构型的全部采购件，整机没有一处螺纹。后三行是可选件：防牛顿环玻璃用一片玻璃替掉两个打印的压片窗插片、两幅面通用；植绒贴消掉窗口四周台面的反光；更大的那块乳白板是 4×5 顶盖台的扩散板。

两个下单提示。**扩散板买 2 片**：乳白亚克力在运输途中容易崩边，它又正好处在光路上；多切一片几乎不要钱，重走一轮物流却要一周。从原型机升级的话，旧的 110 × 130 mm 扩散板就是同样的 2 mm 乳白料；任何亚克力店都能帮你裁成 68 × 118 mm，这一行就从订单里划掉了。**磁铁多买几颗备用**：过盈压入最怕崩了边的磁铁，而 N35 圆片一颗只要几毛钱。

### 分地区搜索词

同一个零件，词用错就搜不出来，所以每一行都给了三地的说法。

| 项目 | 中国（淘宝／1688） | 日本（Amazon.jp／Monotaro／Yodobashi） | 其他地区（英文） |
|---|---|---|---|
| 乳白亚克力扩散板 | `乳白亚克力板 定制 2mm` | `乳半アクリル板 2mm 切断` | `opal acrylic sheet 2 mm cut to size` |
| 钕磁铁 | `钕磁铁 8x2mm N35` | `ネオジム磁石 丸型 8×2` | `neodymium disc magnet 8 × 2 mm N35` |
| 钢垫片 | `铁片 10x10x1` 或 `M5平垫片 外径10 铁` | `平座金 M5 外径10 鉄・ユニクロ` | `mild steel shim 10 × 10 × 1 mm` / `M5 steel washer, 10 mm OD` |
| 防牛顿环玻璃 | `防牛顿环玻璃 定制` | `アンチニュートンガラス` | `anti-Newton glass, cut to size` |
| 黑色植绒贴 | `黑色植绒布 背胶 A5` | `植毛シート 黒 粘着` | `self-adhesive black flocking sheet` |
| 3D 打印代打 | `3D打印 代打 PLA` | `3Dプリント 出力代行 PLA` | JLC3DP、PCBWay、Craftcloud，或者本地的创客空间 |

---

## 磁铁

32 颗 Ø8 × 2 mm 的 N35 磁铁，四个夹件（两个底座、两个上盖）每件 8 颗。全部用手过盈压入磁孔，整机没有一滴胶水。

| 作用 | 怎么实现 |
|---|---|
| 把胶片夹合紧 | 上盖 8 颗与底座 8 颗一一相对，每个夹子构成 8 对相吸磁铁 |
| 把夹子吸在顶盖台上 | 底座磁铁隔着夹底板，吸住嵌平在顶盖台沉孔里的 4 片钢垫片；掀起就脱开，换幅面只要几秒 |

CNY 8–15 就能连备用一起买齐 32 颗。底座磁铁吸的对象就是那 [4 片钢垫片](#采购件)，所以这两行该放进同一单：省掉垫片，夹子就没有任何东西把它固定在台面上。

> [!WARNING]
> 这种磁铁隔着一层皮肉相吸时夹得很疼，散落的钕磁铁对儿童和宠物更是严重的误吞风险。备用的请放进有盖的盒子。磁铁不标极性，而过盈压入并不比胶水好拆多少：每一对底座磁铁和上盖磁铁先凑在一起确认相吸，在压入**之前**把朝上的面标好。压反了的磁铁会把上盖顶开而不是吸住，挖出来通常连磁孔一起报废。具体步骤见[第 1 步——压入磁铁](assembly.zh-CN.md#第-1-步压入磁铁)。

---

## 买对规格

六种把钱花出去、收到的东西却用不了的方式。

| 零件 | 常犯的错 | 下单时要讲明什么 |
|---|---|---|
| [乳白](glossary.zh-CN.md#乳白)亚克力扩散板 | 买成磨砂亚克力 | 乳白是整块板体都呈乳浊状，光在板内散射；磨砂只是透明亚克力把一面打毛，会把灯头映出来。要说"乳白、导光扩散、2 mm"，并给出 68 × 118 mm 的切割尺寸。板越浓，损失的光越多、匀度越好；闪光灯的功率有的是富余。 |
| 钕磁铁 | 厚度买错 | 磁孔是按 Ø8 × 2 mm 的普通轴向充磁圆片开的。3 mm 的会凸出来把上盖顶开；1 mm 的陷得太深吸不住。N35 就是普通牌号，足够用；N52 更贵，多出来的吸力用不上。 |
| 钢垫片 | 买成不锈钢 | 多数不锈钢几乎不被磁铁吸住，而这四片存在的唯一意义就是给磁铁一个吸附面。要碳钢或镀锌件，厚 1 mm 不能再厚：沉孔深 1 mm，垫片必须与台面齐平。10 × 10 方片或 Ø10 圆片都行。 |
| 防牛顿环玻璃 | 买成磨砂玻璃 | 防牛顿环玻璃是扫描仪和放大机的配件：一面带着肉眼几乎看不出的细微蚀纹，既压住牛顿环又不扩散影像。磨砂玻璃是扩散片，会毁掉锐度。要指明"单面防牛顿环处理，64 × 95 × 2 mm"。 |
| 黑色植绒贴 | 买成毛毡或亮面贴纸 | 植绒贴是表面带绒毛的背胶贴片；毛毡太厚，亮面贴纸反光。要哑光黑、背胶，一张 A5 就够贴满窗口四周的台面。 |

---

## 光源

| 项目 | 规格 | 价格（CNY） |
|---|---|---|
| 热靴闪光灯，任何品牌（参考型号：NEEWER TT560） | 硬性要求只有功率手动可调；参考机 TT560：[闪光指数](glossary.zh-CN.md#闪光指数) GN38，[手动 1/1–1/128](glossary.zh-CN.md#手动出力档位) 整档，≈ 5600 K | 200–300 |
| ZENIKO T1 引闪套装，或任何 2.4 GHz 套装 | 发射器＋接收器 | 150–250 |

闪光灯从来不进箱子。它平躺在桌面上，灯头怼在主箱完全敞开的前口，向白色混光腔里打光；接收器就留在灯上、留在箱外。旧版的那些限制正是因为这个摆法而消失的：无线信号毫无遮挡，换电池不用碰箱子，改功率直接在灯上拨。

选闪光灯真正要紧的只有一条：**功率能手动调**。[TTL](glossary.zh-CN.md#ttl) 和 [HSS](glossary.zh-CN.md#hss) 在这里毫无用处，别为它们花钱。原型机的第二条要求"灯头能转 90°"也随着封闭箱体一起消失了：灯平躺着水平直射。

> [!NOTE]
> 原型机时代那条"公开的 STL 只适配 TT560，别的灯都不行"的警告已经不存在了。箱子的任何尺寸都不再取决于闪光灯机身，也就没有长度、厚度限制可查。TT560 留在表里只是作为便宜、好买的参考机型，不是要求；手上有什么手动灯就用什么。

---

## 下单顺序

三个订单，可以同一天全部发出，互相不等。

```mermaid
flowchart TD
  A[订单 1：12 个 STL<br/>一家店，白＋黑] --> D[到货检查]
  B[订单 2：乳白亚克力 68 × 118<br/>想要就加上防牛顿环玻璃] --> D
  C[订单 3：磁铁和钢垫片<br/>可加植绒贴] --> D
  D --> E[装配]
```

| 订单 | 常见货期 | 什么时候下 |
|---|---|---|
| 1：12 个 STL | 2–5 天，加物流 | 最先下，它是最长的一环 |
| 2：乳白亚克力，按尺寸切 | 3–7 天 | 同一天，与 1 并行 |
| 3：磁铁和钢垫片 | 次日到几天 | 随时 |
| 防牛顿环玻璃、植绒贴（可选） | 3–7 天 | 跟订单 2、3 一起，或者等箱子跑通再说，打印插片本来就是默认方案 |

没有谁卡谁：原型机时代那条"先量顶盖立柱孔、再买热熔铜螺母"的规矩随着热熔铜螺母一起消失了。外包打印还想上个保险的话，可以先让店家打一副 135 夹试试片条能不能滑动，见[打印文档](printing.zh-CN.md#先打一副-135-胶片夹)的"先打一副 135 胶片夹"。零件小成这样，这一步只是锦上添花，不再是当年的关卡。

付款前要问打印店的三个问题：

- [ ] 有没有**哑光**白色 PLA 的现货？
- [ ] 会不会照写好的 0.2 层高打，而不是悄悄换成店里的默认参数？
- [ ] 白色和黑色放在一单里，换料要不要另外收费？

> [!TIP]
> 包装仍然要紧。让店家给打印件裹厚气泡膜（壁厚只有 2.4 mm），再让亚克力夹在打印件中间运输，乳白亚克力最容易崩边。

---
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

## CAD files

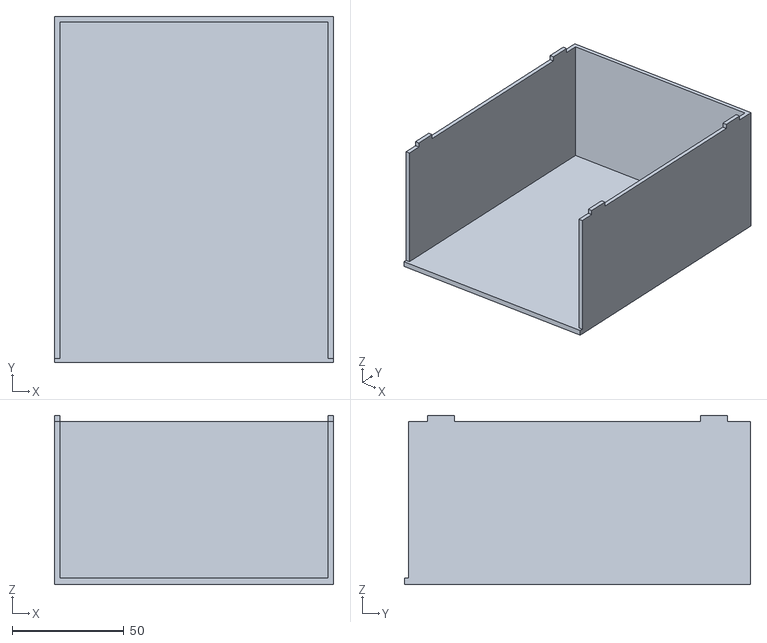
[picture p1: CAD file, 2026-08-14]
stl/white-pla/main-body.stl
124.8 x 154.8 x 75.6

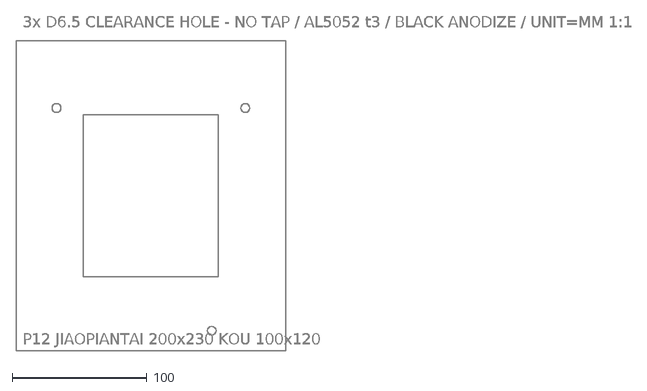
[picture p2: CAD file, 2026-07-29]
cad/film-stage-aluminium-3mm.dxf
P12 JIAOPIANTAI 200x230 KOU 100x120
3x D6.5 CLEARANCE HOLE - NO TAP / AL5052 t3 / BLACK ANODIZE / UNIT=MM 1:1

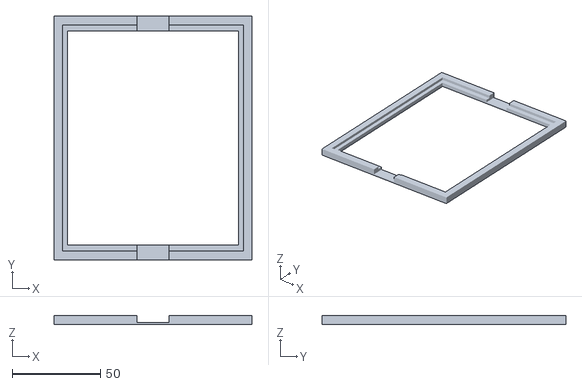
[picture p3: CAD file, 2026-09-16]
stl/black-pla/sheet-plate-4x5.stl
112.0 x 138.0 x 5.00

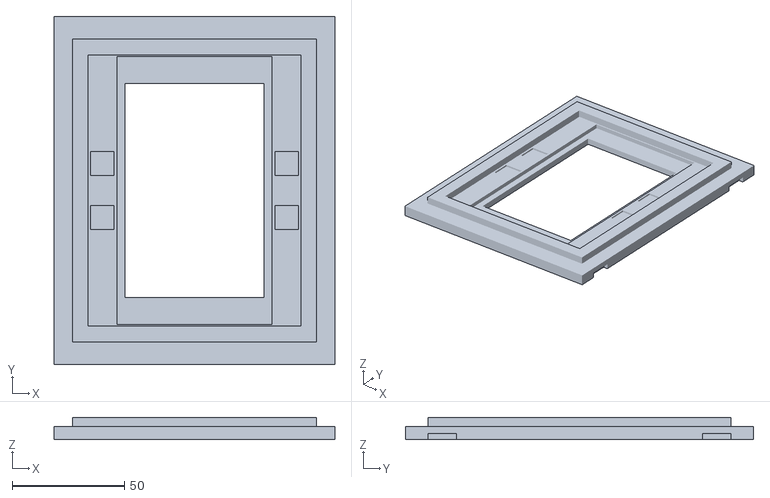
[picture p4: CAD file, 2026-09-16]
stl/white-pla/cover-stage.stl
124.8 x 154.8 x 10.0

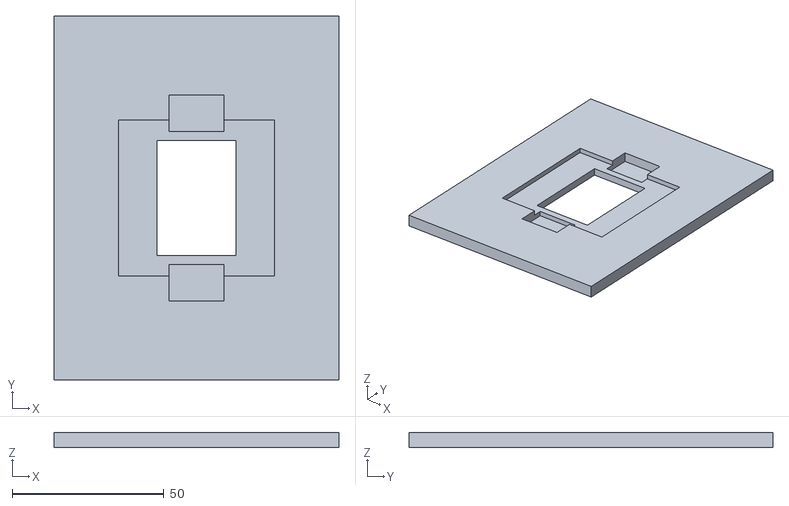
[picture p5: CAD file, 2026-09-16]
stl/black-pla/slide-plate-135.stl
94.0 x 120.0 x 5.00

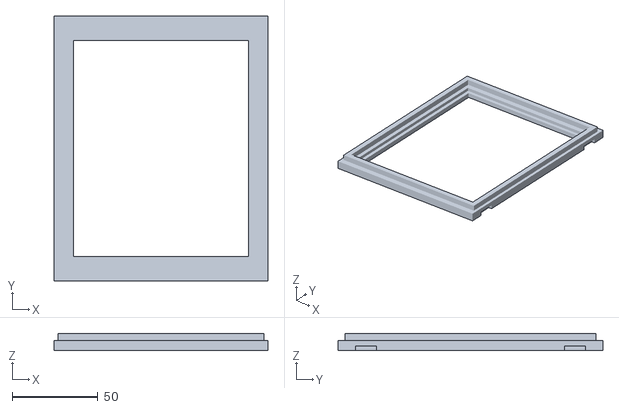
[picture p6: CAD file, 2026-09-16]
stl/white-pla/cover-stage-4x5.stl
124.8 x 154.8 x 10.0

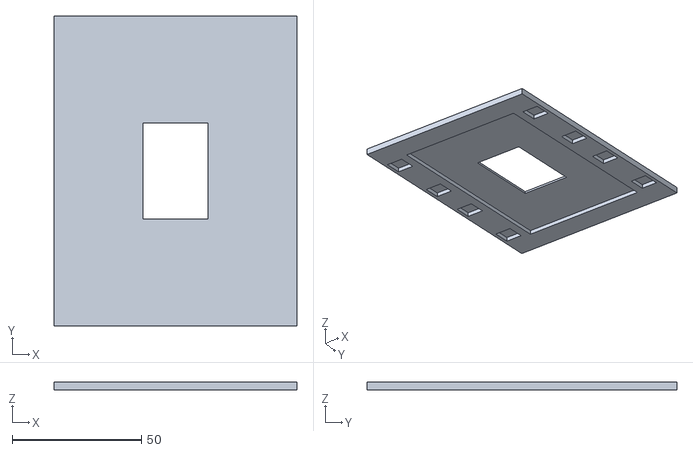
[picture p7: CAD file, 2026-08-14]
stl/black-pla/film-holder-135-lid.stl
94.0 x 120.0 x 3.00

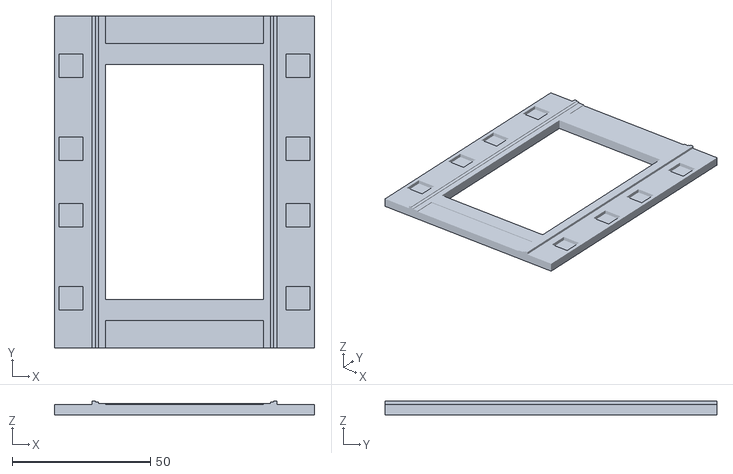
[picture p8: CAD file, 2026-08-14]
stl/black-pla/film-holder-120-base.stl
94.0 x 120.0 x 5.00

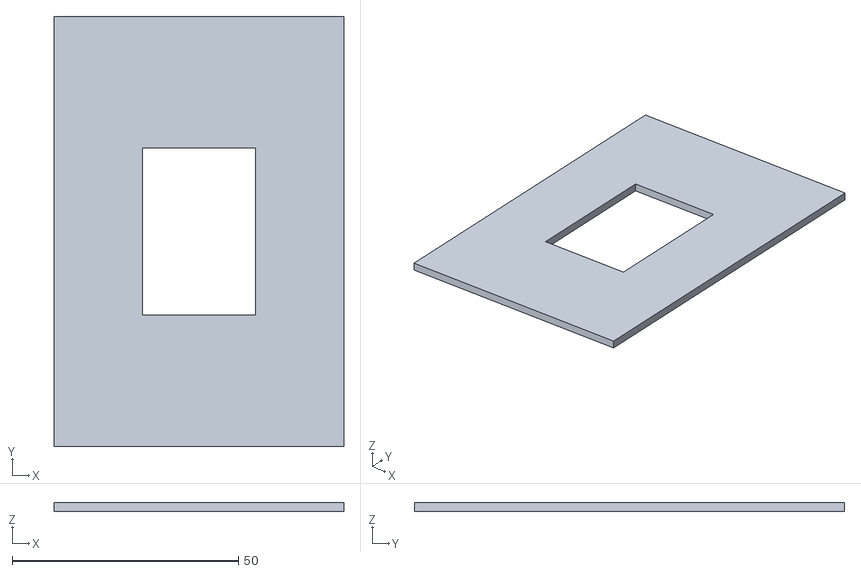
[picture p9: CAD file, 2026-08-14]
stl/black-pla/pressure-window-135.stl
64.0 x 95.0 x 2.00

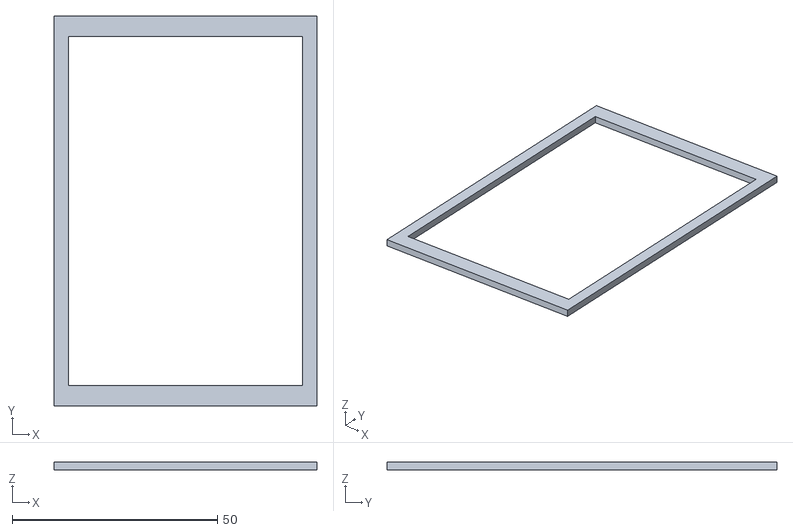
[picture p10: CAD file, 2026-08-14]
stl/black-pla/pressure-window-120.stl
64.0 x 95.0 x 2.00

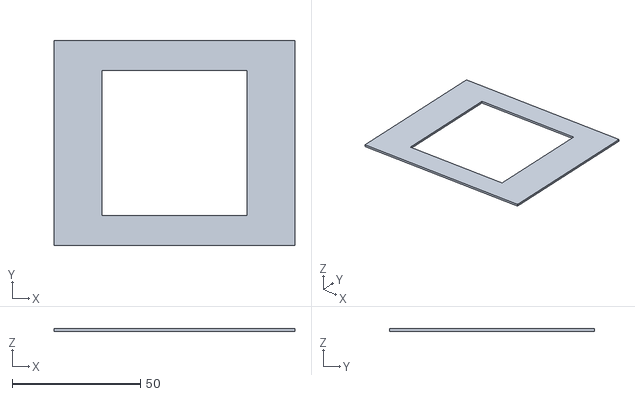
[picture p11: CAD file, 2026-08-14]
stl/black-pla/mask-6x6.stl
94.0 x 80.0 x 1.00

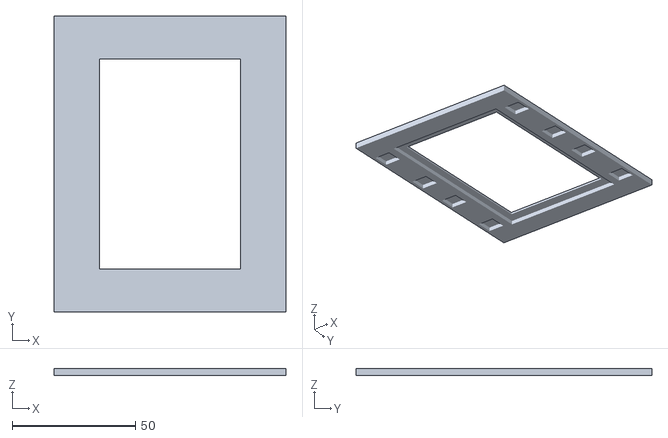
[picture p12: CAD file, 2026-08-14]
stl/black-pla/film-holder-120-lid.stl
94.0 x 120.0 x 3.00

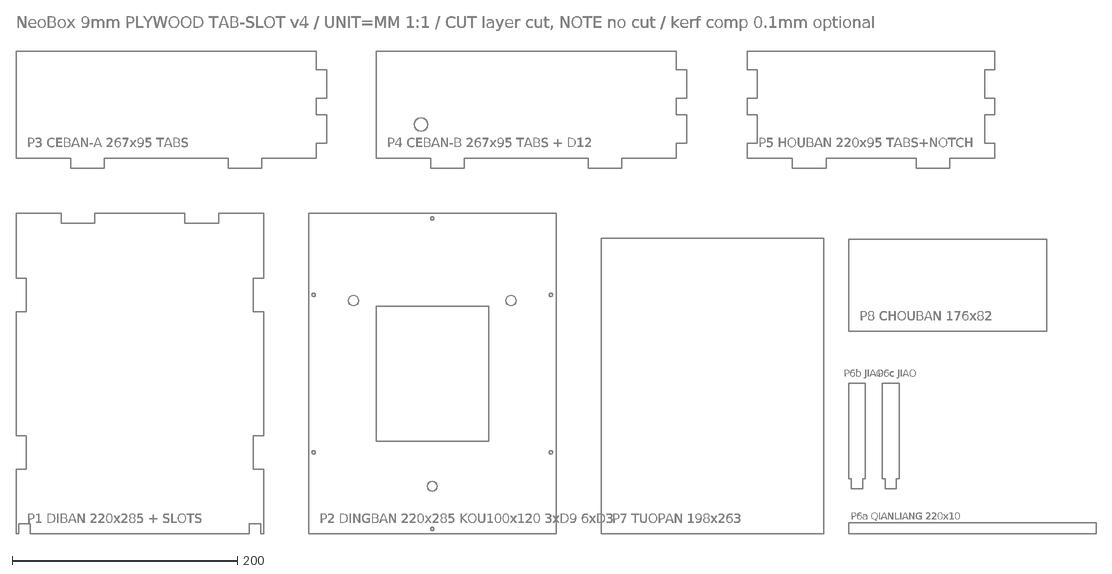
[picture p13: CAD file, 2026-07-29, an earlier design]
cad/legacy-plywood/panels-9mm.dxf
P1 DIBAN 220x285 + SLOTS
P2 DINGBAN 220x285 KOU100x120 3xD9 6xD3
P7 TUOPAN 198x263
P6a QIANLIANG 220x10
P6b JIAO
P6c JIAO
P8 CHOUBAN 176x82
P3 CEBAN-A 267x95 TABS
P4 CEBAN-B 267x95 TABS + D12
P5 HOUBAN 220x95 TABS+NOTCH
NeoBox 9mm PLYWOOD TAB-SLOT v4 / UNIT=MM 1:1 / CUT layer cut, NOTE no cut / kerf comp 0.1mm optional

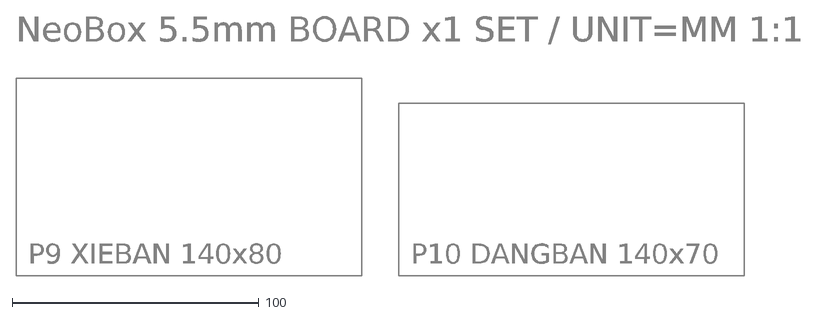
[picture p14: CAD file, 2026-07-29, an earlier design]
cad/legacy-plywood/panels-5.5mm.dxf
P9 XIEBAN 140x80
P10 DANGBAN 140x70
NeoBox 5.5mm BOARD x1 SET / UNIT=MM 1:1

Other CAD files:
stl/black-pla/film-holder-135-base.stl
cad/neobox.blend

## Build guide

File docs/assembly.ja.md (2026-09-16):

# 組立

[English](assembly.md) · [简体中文](assembly.zh-CN.md) · **日本語**

> プリントパーツ 12 個、マグネット 32 個、鉄ワッシャー 4 枚、乳白アクリル 1 枚を、実際に使える光源に変えるまで。道具はひとつも使いません。極性を合わせて圧入するマグネット、本体から天板ステージ、フィルムホルダーへと重力だけで積み上がるスタック、そしてフィルム面をセンサーと平行にする鏡の方法を扱います。

**目次：** [始める前に](#始める前に) · [工具と安全](#工具と安全) · [何が何を固定するか](#何が何を固定するか) · [組立手順](#組立手順) · [フォーマット切り替えと日常の扱い](#フォーマット切り替えと日常の扱い) · [うまくいかないとき](#うまくいかないとき)

## 始める前に

このビルドには、ねじが 1 本もなく、ねじ山も、接着剤のひと滴も、塗装のひと吹きもありません。だから工具も要りません。どの結合もマグネットか、位置決めの形状か、重力のどれかで、しかもすべての手順が可逆です。載せたのと同じ動きで、そのまま持ち上げて外せます。硬化や乾燥の待ち時間はどこにもないので、組立はひと息で終わります。ゆっくりやる価値があるのはマグネットの圧入だけです。全工程でそこだけが、やり直しの利かない操作だからです。

手をつける前に、パーツを確認してください。パーツごとの完全な一覧は [printing.ja.md](printing.ja.md#組み立てる前に各パーツを確認する) に、購入部品は[部品表](bom.ja.md)にあります。次の 4 つは、通らなければそこで止まるものです。

- [ ] **天板ステージ**が、四隅のダボ穴を壁上端の位置決めダボに合わせて、自重だけで**本体**に落ち、がたつかずに座る。
- [ ] **Ø8 × 2 mm のマグネット**が座ぐり穴に手で入り始め、しっかり押すと底まで届く。しまりばめなので、きついのが正解です。
- [ ] **鉄ワッシャー**がマグネットに吸い付く。ステンレスは吸い付かず、あとになっても何も警告してくれません。
- [ ] **フィルムストリップ**が無理なく**ホルダー底**の溝を通り、**ホルダー蓋**ががたつかずに載る。

## 工具と安全

工具の一覧はありません。工具そのものがないからです。こても、スパナも、ナイフも、接着剤も、塗料も使いません。あると便利なのは 2 つだけ。ホコリを飛ばすブロアーと、最後のステップで使う 30 mm 程度の小さな平面鏡です。マグネットが親指で押し切れないときは、マグネットを机に置いてパーツのほうを上から押し付けてください。この机が、このビルドで「工具」にいちばん近いものです。

> [!WARNING]
> - **Ø8 × 2 mm のマグネット**は小さく強力で、誤飲の危険が本当にあります。子どもとペットから遠ざけてください。2 個が吸着するときに皮膚を挟み、磁気カードのデータを消し、ハードディスクにも悪影響を与えます。
> - 圧入したマグネットは簡単には抜けません。極性の確認は、毎回**押し込む前に**行ってください。
>
> 箱の中に電気製品は何ひとつ入りません。ストロボはオープンフロント（前面開口）の外に寝かせて中へ発光させ、受信機もその横に置いたままです。

## 何が何を固定するか

NeoBox の組み上がりスタックの分解図

| インターフェース | 方式 |
|---|---|
| 本体 | 一体プリントの 1 部品。組み立てる箇所はない |
| 天板ステージ → 本体 | 壁の上端に載り、四隅のダボ穴が位置決めダボに掛かる。重力のみ、ねじなし |
| 鉄ワッシャー → 天板ステージ | ステージ面（天板ステージの上面）の座ぐり穴 4 か所に落とし、面一に納まる。接着なし。座ぐりが位置を決め、真上のマグネットが押さえる |
| 乳白アクリル → 天板ステージ | 透過窓に被さる凹部に納まり、上面はステージ面より 0.4 mm 低い。固定なし |
| ホルダー底 → 天板ステージ | トレイフランジが位置を決め、底のマグネットが鉄ワッシャーに吸着して引き付ける |
| 押さえエレメント → ホルダー底 | インサートまたはアンチニュートンガラスがエレメント段（4.6 mm）に載る。意図して緩い |
| ホルダー蓋 → ホルダー底 | マグネット 8 ペア |
| ストロボ → 箱 | 箱には決して入れない。オープンフロントの外の机に寝かせ、発光部を庫内へ向ける |

## 組立手順

### ステップ 1 — マグネットを圧入する

**必要なもの：** ホルダーの 4 部品（ホルダー底 2 枚、ホルダー蓋 2 枚）、Ø8 × 2 mm マグネット 32 個、マーカーペン。

各部品にマグネットを 8 個ずつ圧入します。ホルダー底は**上から**、上面の座ぐり穴へ。ホルダー蓋は**下から**、裏面の座ぐり穴へ。このステップの中身は極性がすべてです。底の各マグネットは、将来向かい合う蓋のマグネットと引き合わなければなりません。しかも押し込む前に合わせておく必要があります。圧入は、このビルドでいちばん「取り消し」から遠い操作だからです。

1. マグネットは 1 本のスタックのまま持ち、端から 1 個ずつ、途中で裏返さずに取ります。こうすればどのマグネットも同じ向きでスタックを離れます。
2. ホルダー底を平らに置き、8 個を同じ向きのまま上面から 1 個ずつ、それぞれ穴の底まで圧入します。たいてい親指で足ります。足りなければマグネットを机に置き、パーツのほうを押し付けてください。
3. ホルダー蓋を裏返して、裏面を上に向けます。各座ぐり穴について、まずばらのマグネットを、向かい合うことになる圧入済みの底マグネットに触れさせます。引き合う向きでぱちんと付きます。露出している面にペンで印を付け、引きはがし、**印の面から先に**蓋の穴へ圧入します。印のない面（引き合う面）が見える状態で仕上がります。
4. もう一方のフォーマットの底と蓋にも同じことをします。

**チェックポイント：** どの蓋も底にぱちんと吸い付き、閉じたホルダーを片端で持っても閉じたまま。蓋のマグネットは蓋の裏面と面一で仕上がります。底のマグネットは板面から 0.4 mm 出っ張りますが、これは設計どおりで、押し込みが足りないのではありません。沈めようとしないでください。

**失敗の形：** 逆向きのマグネットが 1 個あると、その角で蓋が押し開かれます。そして圧入済みのマグネットは、おとなしくは出てきません。手順 3 の「触れさせて印を付ける」確認は 1 個あたり数秒。省くと部品ごと失いかねません。

> [!IMPORTANT]
> このサンドイッチを閉じているのは 8 ペアのマグネットだけで、その後ろにクリップもねじもありません。どの底にも、どの蓋にも 8 個すべてを入れます。v1 に「省略できるマグネット」はありません。

### ステップ 2 — 鉄ワッシャーを座ぐりに落とす

**必要なもの：** 天板ステージ、鉄ワッシャー 4 枚（10 × 10 × 1 mm の角形、または Ø10 × 1 mm の円形）。

1. ステージ面の座ぐり穴 4 か所に、ワッシャーを 1 枚ずつ落とします。

このステップはこれで全部です。接着はしません。座ぐりがワッシャーをステージ面と面一に位置決めし、使用時には真上に来るホルダー底のマグネットが押さえます。

**チェックポイント：** ステージ面を指先でなぞって、どのワッシャーの縁にも段差を感じないこと。予備のマグネットで、どのワッシャーもまっすぐ吊り上げられること。吊り上がらないワッシャーはステンレスです。今ここで交換してください。あとになっても何も教えてくれません。

**失敗の形：** ステンレスのワッシャーは見た目がまったく同じで、音もなく失敗します。ホルダー底が定位置に引き込まれなくなるだけです。ステージ面から出っ張ったワッシャーは、上に載る底を傾けます。

### ステップ 3 — アクリルを凹部に収める

**必要なもの：** 68 × 118 × 2 mm の[乳白](glossary.ja.md#乳白-opal)アクリル（4×5 天板ステージなら 106 × 130 × 2 mm の板）、ブロアー。

1. **両面の保護フィルムを剥がします。** アクリル板は両面ともフィルム付きで届きます。
2. 両面をブロアーで払います。
3. トレイ中央、透過窓に被さる凹部へ板を置きます。落とし込むと、上面はステージ面より 0.4 mm 低いところで止まります。

**チェックポイント：** 板の全周がステージ面より低く、凹部の中で少し動かせること。緩いのが正解です。何も固定していませんし、この 0.4 mm の段差のおかげで、上に載るホルダーさえ板には触れません。

**失敗の形：** 面に残った保護フィルムは拡散のしかたを変えますが、乳白の板の上では実によく隠れます。収める前に、四隅で剥がし残しの端を探してください。

> [!NOTE]
> アクリルに載ったホコリはコマには写りません。この板そのものが拡散して光る面であって、レンズが結像する対象ではないからです。手入れはときどきの拭き取りで十分、それも乾いた布で。アルコール、アンモニア、ガラスクリーナーは使わないでください。3 つともアクリルにクレーズ（微細なひび）を生じさせます。

### ステップ 4 — 天板ステージを本体に載せる

**必要なもの：** 本体、ワッシャーとアクリルを収めた天板ステージ。

1. トレイフランジをつまんで天板ステージを持ち、四隅のダボ穴を壁上端の位置決めダボに合わせ、まっすぐ下ろします。自重で座ります。
2. 浮いたりがたついたりするなら、どこかのダボが穴の横に乗り上げています。まっすぐ持ち上げて、載せ直してください。押さない、ひねらない。

**チェックポイント：** 天板ステージが壁の上端に全周すきまなく平らに座り、がたつかないこと。そして同じくらい軽く、まっすぐ持ち上げて外せること。

**失敗の形：** ダボが穴に入らないのはプリントの問題（どちらかのパーツの最初の数層の[エレファントフット](glossary.ja.md#エレファントフット-elephant-foot)）であって、力で解決するものではありません。[printing.ja.md](printing.ja.md#きつい場合と緩い場合の対処) を参照してください。

### ステップ 5 — ホルダー底をトレイに収める

**必要なもの：** 載せ終えた天板ステージ、使うフォーマットのホルダー底（マウント済みスライドならスライドプレート）。6×6 を撮るなら 6×6 マスクも。

1. トレイフランジの内側へ底を下ろします。すきまは片側 0.3 mm。気になるほどの遊びもなく収まります。
2. 手を離して落ち着かせます。底のマグネットがステージ面の鉄ワッシャーを見つけ、底を平らに、定位置へ引き込みます。

**チェックポイント：** 底がトレイの床に平らに座ってがたつかず、着地の瞬間にマグネットが受け取る感触があるはずです。持ち上げてもう一度落としてみてください。毎回同じ収まり方をするはずです。

**失敗の形：** 落としても無反応で、吸着も位置決めの感触もないなら、ステップ 2 のワッシャーがステンレスか、そもそも入っていません。フランジに入らない底は、これもエレファントフットで、力を入れる理由にはなりません。

> [!NOTE]
> 6×6 を撮るときは、先に **6×6 マスク**をトレイに敷き、その上に 120 の底を載せます。ホルダー全体が 1 mm 高く座りますが、それで正常です。6×4.5 の専用マスクはありません。120 の窓のまま撮って、あとでトリミングしてください。マウント済みスライドでは、**スライドプレート**が 135 の底の代わりにトレイに単独で立ちます。マグネットもエレメントも蓋もないので、ステップ 6 は不要です。4×5 では、**シートプレート**が同じように **4×5 天板ステージ**のトレイに立ちます。こちらはステップ 3 の専用アクリルを入れて、ステップ 4 とまったく同じようにダボに載せます。マグネットなし、ステップ 6 なし。

### ステップ 6 — 押さえエレメントを載せ、蓋を閉じる

**必要なもの：** 使うフォーマットの押さえ窓インサート、またはアンチニュートンガラス 64 × 95 × 2 mm（1 枚で両フォーマット兼用）。それと対応するホルダー蓋、ブロアー。

1. エレメントを外側レールのエレメント段（4.6 mm）に載せます。段はエレメントをフィルムの通り道の 0.4 mm 上に構え、この 0.4 mm が押さえ設計のすべてです。フィルムはエレメントの下をすべって送られ、浮き上がった部分はエレメントの下面に沿って平らにならされます。エレメントは一度収めたら、以後は触りません。
2. ガラスの場合：**つや消し（AN）面を下**、フィルム側へ向けます。つや消し面がフィルムベースの光沢面に接することで、ニュートンリングを防ぎます。収める直前に下面をブロアーで払ってください。焦点面まで 0.2 mm しかなく、そこのホコリは写ります。
3. 蓋を載せます。8 ペアのマグネットが引き込んで閉じます。

**チェックポイント：** 蓋が全周で座り、浮いた角がないこと。そして閉じた蓋の下で、エレメントにかすかな遊びが残っていること。蓋の内側の空間には 0.4 mm の余裕を持たせてあり、浮いているのが正解です。エレメントががっちり挟まっているなら、どこかが出っ張っています。強く押さず、開けて確かめてください。

**失敗の形：** ガラスを光沢面を下にして入れると、フィルムベースとのあいだにニュートンリングを招きます。閉じない角が 1 つあるなら、ステップ 1 で逆向きに入れたマグネットの、遅れて届いた報告です。

### ステップ 7 — カメラ側で平行を出す：鏡の方法

箱には水平調整の機構がありませんが、欠けているのではありません。大事な関係はただひとつ、**フィルム面とセンサーの平行**で、それを合わせる正しい場所がカメラ側だからです。カメラ側でのひと調整が、プリントパーツの公差まで含めて、連鎖全体を一度に修正します。

**必要なもの：** カメラの下に据えた組み上がりの箱、30 mm 程度の小さな平面鏡。

1. 閉じたホルダーの上、フィルム窓の中央に鏡を平らに置きます。
2. ライブビューを見ます。レンズとカメラが映り込んでいるはずです。
3. **箱ではなくカメラを**傾け、ずらして、レンズの映り込みが画面のちょうど中央に来て左右対称に見えるようにします。
4. 映り込みが中央に来たとき、センサーは鏡と平行で、その鏡はフィルム面に載っています。これで完了です。
5. 雲台を固定して、もう一度確認します。締めると動きます。

```mermaid
flowchart TD
    A[スタックを組み、ホルダーを閉じる] --> B[鏡をホルダーの上、窓の中央に置く]
    B --> C[カメラはライブビューで箱に正対]
    C --> D{レンズの映り込みは中央で左右対称か}
    D -- いいえ --> E[カメラを傾ける・ずらす。箱は動かさない]
    E --> C
    D -- はい --> F[雲台を固定し、もう一度確認]
```

**チェックポイント：** 雲台を固定した状態でも映り込みが中央にあること。箱かカメラを動かしたら、そのたびに確認し直してください。数秒で済みます。

<details>
<summary>なぜカメラ側で、なぜ鏡なのか</summary>

水準器は重力に対する水平を測りますが、重力は光路の中にいません。床に対して完璧に水平な面でも、センサーに対しては傾いていられます。鏡が測るのは、まさにその唯一大事な関係で、しかも 2 倍にして見せてくれます。センサーの光軸と鏡面のあいだの角度は、映り込みの位置のずれとして 2 倍で現れるので、「レンズ自身の映り込みを中央に置く」ことは感度の高いゼロ合わせになります。

箱ではなくカメラ側で調整することは、鏡より下にあるすべて（壁上端の平面度、ダボの座り、積み重なったプリント公差）を同じひと動作で吸収することでもあります。箱に何かを噛ませても、直せるのは箱だけです。v1 が箱側の水平調整機構を改良せずに削除したのは、これが理由です。

</details>

カメラ側のセットアップについては、スタンドは[平行出し](scanning.ja.md#平行出し)を、フォーマットごとの高さは[カメラの高さとスタンド](scanning.ja.md#カメラの高さとスタンド)を参照してください。

## フォーマット切り替えと日常の扱い

- **フォーマットの切り替えは、ホルダーの交換です。** ホルダーはマグネットで載っているだけなので、丸ごと持ち上げて、もう一方のフォーマットのホルダーを収めます。インサートはそれぞれのホルダーに入れたまま。アンチニュートンガラスを使うなら、1 枚で両フォーマット兼用なので、ガラスだけを相手のエレメント段へ移します。
- **フィルム送り：** ホルダーの外に出ている先端をつまんで、そのまま引きます。末端はトレイフランジの上端（フィルム面より 0.2 mm 低い位置）に載って支えられて進みます。長いストリップは、反対の手で末端側を支えてください。
- **装填の向き：** ガラスなら反りの凸面を上に、インサートなら凸面を下にします。
- **マウント済みスライド：** 135 のホルダーを持ち上げて外し、スライドプレートを収め、マウントを窓にかざして見るときと同じ向き、つまり上から見て像が正しく読める向き（エマルジョン面が下）でポケットに落とし込みます。取り出すときは 2 つの指掛け溝に指を掛けます。ほかは何も変わりません。ピントだけ合わせ直してください。
- **4×5 シート：** 天板ステージを持ち上げて外し、専用アクリルを入れた 4×5 天板ステージを同じダボに載せ、そのトレイにシートプレートを収めて、シートを上から見て像が正しく読める向き（エマルジョン面が下）でポケットに落とし込みます。取り出すときは縁の切欠きに指を掛けます。ピントを合わせ直し、ポールの高さも取り直してください。4×5 はおよそ 0.25× です。
- **アクリルの取り出し：** ホルダーを外し、オープンフロントから手を入れて、透過窓越しに板を上へ押し出します。
- **天板ステージは丸ごと持ち上げられます。** トレイフランジをつまんで、まっすぐ上へ。
- **ストロボは常に箱の外：** オープンフロントに寝かせ、発光部を庫内へ向けます。受信機も外に置いたままです。電波はクリアで、電池交換に箱を開ける必要もありません。撮影は薄暗い部屋で行い、天井の照明が開口へ直接差し込まないようにしてください。

> [!IMPORTANT]
> 組み上がった箱は、重力で積んであるだけのスタックです。どの部品も、ほかのどの部品にも固定されていません。傾けないでください。組んだまま運ばないでください。ホルダーと天板ステージを外し、部品ごとに分けて運びます。

## うまくいかないとき

| この段階での症状 | 見に行く先 |
|---|---|
| 天板ステージが浮く・がたつく、ホルダー底がトレイに落ち着かない | [組み立ての問題](troubleshooting.ja.md#組み立て) |
| 暗い染み、片側だけ明るい、全コマに走る輪郭のはっきりした暗い帯 | [光と均一性](troubleshooting.ja.md#光と均一性) |
| フィルムの溝がきつすぎる／ゆるすぎる、パーツが反って出てきた | [printing.ja.md](printing.ja.md#きつい場合と緩い場合の対処) |

---

← [3D プリント](printing.ja.md) · [ドキュメント一覧](../README.ja.md#ドキュメント) · [スキャン](scanning.ja.md) →

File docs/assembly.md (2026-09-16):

# Assembly

**English** · [简体中文](assembly.zh-CN.md) · [日本語](assembly.ja.md)

> How to turn twelve printed parts, thirty-two magnets, four steel washers and a sheet of opal acrylic into a working light source, with no tools at all: magnets pressed in with paired polarity, a gravity stack from main body to cover-stage to film holder, and the mirror method that makes the film plane parallel to your sensor.

**Contents:** [Before you start](#before-you-start) · [Tools and safety](#tools-and-safety) · [What connects to what](#what-connects-to-what) · [Assembly steps](#assembly-steps) · [Formats and everyday handling](#formats-and-everyday-handling) · [If something is wrong](#if-something-is-wrong)

## Before you start

There is not a single screw, thread, drop of glue or coat of paint in this build, and therefore not a single tool. Every joint is a magnet, a locating feature or gravity, and every step is reversible: parts lift apart the same way they went together. Nothing cures and nothing dries, so the whole assembly is one sitting; the only part worth doing slowly is the magnets, because they are the one thing that is hard to undo.

Check the parts before you start. The full per-part list is in [printing.md](printing.md#check-each-part-before-you-assemble), and the purchased parts are in [bom.md](bom.md); these four checks are the ones that stop the build:

- [ ] The **cover-stage** drops onto the **main body** with its four corner notches over the locating tenons on the wall tops, and sits flat without rocking.
- [ ] A **Ø8 × 2 magnet** starts in its counterbore by hand and needs a firm push to seat. It is an interference fit; snug is correct.
- [ ] A **steel washer** sticks to a magnet. A stainless one will not, and nothing later ever warns you.
- [ ] A **film strip** slides through the **holder base** channel without being forced, and the **holder lid** sits on the base without rocking.

## Tools and safety

There is no tool list, because there are no tools: no iron, no spanners, no knife, no glue, no paint. The two useful extras are a blower for dust and a small flat mirror about 30 mm across for the last step. If a magnet is too stiff for a thumb, set the magnet on the tabletop and press the part down over it. The table is as close to a tool as this build gets.

> [!WARNING]
> - The **Ø8 × 2 magnets** are small, strong and a genuine swallowing hazard: keep them away from children and pets. A pair snapping together pinches skin, and they will wipe cards and disturb drives.
> - A pressed-in magnet is hard to get back out. Check polarity **before** you press, every single time.
>
> Nothing electrical ever goes inside the box: the flash lies outside at the open front and fires in, and the receiver stays out there with it.

## What connects to what

Exploded view of the NeoBox assembly stack

| Interface | Method |
|---|---|
| Main body | One printed piece, nothing to assemble |
| Cover-stage → main body | Rests on the wall tops, four corner notches over the locating tenons. Gravity only, no screws |
| Steel washers → cover-stage | Dropped into four counterbores, flush with the deck (the stage's top face). No glue: the counterbores and the magnets above them do the holding |
| Opal acrylic → cover-stage | Lies in its recess over the light window, top face 0.4 mm below the deck. Loose |
| Holder base → cover-stage | The tray flange locates it; its base magnets pull it down onto the steel washers |
| Pressure element → holder base | The insert or the AN glass rests on the 4.6 mm element ledge. Deliberately loose |
| Holder lid → holder base | Eight magnet pairs |
| Flash → box | Never inside. It lies on the table at the open front with its head firing into the cavity |

## Assembly steps

### Step 1 — Press in the magnets

**You need:** the four clamp parts (two holder bases, two holder lids), the 32 Ø8 × 2 magnets, a marker pen.

Every clamp part takes eight magnets: bases from **above**, into the counterbores in the top face; lids from **below**, into the underside. Polarity is the whole game: each base magnet must attract the lid magnet that will face it, and it has to be right before pressing, because pressing is the nearest thing to permanent in this build.

1. Keep the magnets as one stack and peel them off one end without flipping any, so every magnet leaves the stack the same way up.
2. Lay a holder base flat and press its eight magnets in from the top face, all the same way up, each to the bottom of its pocket. Thumb pressure usually seats them; if not, put the magnet on the table and press the part down over it.
3. Turn a holder lid underside-up. For each pocket, first touch the loose magnet to the pressed base magnet it will face; it snaps on in the attracting orientation. Mark the exposed face with the pen, pull it off, and press it into the lid pocket **marked face first**, leaving the unmarked, attracting face showing.
4. Repeat for the other format's base and lid.

**Checkpoint:** each lid snaps shut onto its base and stays shut when you hold the closed holder by one end. The lid magnets finish flush with the lid's underside; the base magnets stand 0.4 mm proud of the base's plate face. That is the design, not a bad press, so do not try to sink them.

**Failure mode:** one reversed magnet pushes its corner of the lid open, and a pressed-in magnet does not come out willingly. The touch-and-mark check in sub-step 3 costs seconds per magnet; skipping it can cost the part.

> [!IMPORTANT]
> The eight magnet pairs are all that holds the sandwich shut; there are no clips or screws behind them. Every base and every lid gets its full eight; no magnet in v1 is optional.

### Step 2 — Drop the steel washers into the cover-stage

**You need:** the cover-stage, the four steel washers (10 × 10 × 1 mm squares or Ø10 × 1 discs).

1. Drop one washer into each of the four counterbores in the deck.

That is the whole step. No glue: each counterbore locates its washer flush with the deck, and in use the holder-base magnets above press it home.

**Checkpoint:** a fingertip drawn across the deck feels no edge at any washer, and a spare magnet lifts each one straight back out. If the magnet will not lift a washer, that washer is stainless. Swap it now, because nothing later will tell you.

**Failure mode:** a stainless washer looks identical and fails silently: the holder base never gets pulled into register. A washer riding proud of the deck tilts the base above it.

### Step 3 — Acrylic into its recess

**You need:** the 68 × 118 × 2 mm [opal](glossary.md#opal) acrylic (or the 106 × 130 × 2 mm sheet, if this is the 4×5 cover-stage), a blower.

1. **Peel the protective film off both faces.** Sheet acrylic ships masked on both sides.
2. Blow both faces clean.
3. Lay the sheet into the recess over the light window, in the middle of the tray floor. It drops in and stops with its top face 0.4 mm below the deck.

**Checkpoint:** the sheet sits below deck level all round and can be nudged slightly in its recess. Loose is correct: nothing fixes it, and the 0.4 mm step means even the holder above never touches it.

**Failure mode:** protective film left on a face changes the diffusion, and on opal sheet it hides well. Look for a peel edge at the corners before the sheet goes in.

> [!NOTE]
> Dust on the acrylic never shows in a frame: the sheet is itself the diffuse glowing surface, not something the lens images. An occasional wipe with a dry cloth is all it needs. Never use alcohol, ammonia or glass cleaner, all of which craze acrylic.

### Step 4 — Cover-stage onto the main body

**You need:** the main body, the cover-stage with its washers and acrylic in place.

1. Hold the cover-stage by the tray flange, line up its four corner notches with the locating tenons on the wall tops, and lower it straight down. It seats under its own weight.
2. If it stands high or rocks, a tenon is riding beside its notch: lift straight off and re-seat. Never press, never twist.

**Checkpoint:** the stage sits flat on the wall tops with no gap and no rocking, and lifts straight back off just as freely.

**Failure mode:** a notch that will not take its tenon is a printing artefact ([elephant foot](glossary.md#elephant-foot) on the first layers of either part), not something to force. See [printing.md](printing.md#if-it-came-out-tight-or-loose).

### Step 5 — Holder base into the tray

**You need:** the cover-stage in place, the holder base for your format (or the slide plate, for mounted slides), and the 6×6 mask if that is your frame.

1. Lower the base inside the tray flange. At 0.3 mm of clearance per side it goes in without play worth noticing.
2. Let it settle: the base magnets find the steel washers in the deck and pull the base flat into register.

**Checkpoint:** the base lies flat on the tray floor and does not rock, and you should feel the magnets take it as it lands. Lift it out and drop it again; it should land the same way every time.

**Failure mode:** a base that stays indifferent, with no settle and no grip, means Step 2's washers are stainless or missing. A base that will not enter the flange without force is elephant foot again, not a reason to push.

> [!NOTE]
> For 6×6 frames, lay the **6×6 mask** in the tray first and the 120 base on top of it. The whole clamp then rides 1 mm higher; that is normal. There is no 6×4.5 mask: shoot through the 120 window and crop afterwards. For mounted slides the **slide plate** stands in the tray in place of the 135 base, on its own: no magnets, no element, no lid, so Step 6 does not apply to it. For 4×5 the **sheet plate** stands the same way in the tray of the **4×5 cover-stage**, which goes onto the tenons exactly as in Step 4 with its own acrylic from Step 3; no magnets, no Step 6.

### Step 6 — Pressure element in, lid on

**You need:** the pressure-window insert for your format (or the 64 × 95 × 2 mm AN glass, one sheet serving both formats), the matching holder lid, a blower.

1. Set the element down on the 4.6 mm element ledge in the outer rails. The ledge holds it 0.4 mm above the film path, and that 0.4 mm is the whole pressure design: film advances by sliding underneath, and any bow in the strip is smoothed flat against the element's underside on the way through. The element is fitted once and then left alone.
2. If it is the glass: **matte (AN) face down**, toward the film: the matte face against the film base's glossy side is what prevents Newton's rings. Blow the underside just before it goes in: it will sit 0.2 mm from the focal plane, and dust *there* does image.
3. Set the lid on. The eight magnet pairs snap it down.

**Checkpoint:** the lid seats all round with no corner standing open, and the element keeps a whisper of float under the closed lid: the lid cavity leaves it 0.4 mm, and floating is correct. An element clamped rigid means something is proud somewhere; open up and look rather than pressing harder.

**Failure mode:** the glass put in glossy face down invites Newton's rings against the film base. A corner that will not close is a reversed magnet from Step 1, reporting late.

### Step 7 — Level at the camera: the mirror method

The box has no levelling hardware, and none is missing. Only one relationship matters, **the film plane parallel to the sensor**, and the camera end is the right end to set it, because one adjustment there corrects the whole chain at once, printed tolerances included.

**You need:** the assembled box under your camera, a small flat mirror about 30 mm across.

1. Lay the mirror flat on the closed holder, centred over the film window.
2. Watch live view. You will see the lens and the camera reflected back.
3. Tilt and shift **the camera, not the box,** until the reflection of the lens sits dead centre in the frame and looks symmetrical.
4. When the reflection is centred, the sensor is parallel to the mirror, and the mirror is lying on the film plane. Done.
5. Lock the head, then look once more; tightening moves things.

```mermaid
flowchart TD
    A[Assemble the stack and close the holder] --> B[Mirror flat on the holder, centred on the window]
    B --> C[Camera in live view over the box]
    C --> D{Lens reflection centred and symmetrical?}
    D -- No --> E[Tilt or shift the camera, never the box]
    E --> C
    D -- Yes --> F[Lock the head, then check once more]
```

**Checkpoint:** with the head locked, the reflection is still centred. Repeat the check whenever the box or the camera has moved; it costs seconds.

<details>
<summary>Why the camera, and why a mirror</summary>

A spirit level measures against gravity, and gravity is not in the optical chain: a stage perfectly level to the floor can still be tilted relative to the sensor. The mirror measures the one relationship that matters, and doubles it: any angle between the sensor's axis and the mirror shows up twice over in where the reflection lands, which makes centring the lens's own reflection a sensitive null test.

Adjusting at the camera rather than the box also absorbs everything below the mirror in the same move: wall-top flatness, tenon seating, the stack of printed tolerances. Shimming the box could only ever correct the box. That is why v1 deleted the box-side levelling hardware instead of refining it.

</details>

For the camera side of the setup, the stand is in [parallelism](scanning.md#parallelism), and the height for each format in [camera height and the stand](scanning.md#camera-height-and-the-stand).

## Formats and everyday handling

- **Changing format is changing the clamp.** Lift the whole clamp off (it is held by magnets alone) and drop the other format's clamp in. Each clamp keeps its own insert fitted; if you use the AN glass, that one sheet serves both formats, so only the glass moves across to the other clamp's ledge.
- **Advancing film:** pinch the leader where it sticks out of the clamp and pull. The tail rides on the top of the tray flange, 0.2 mm below the film plane, which supports it on the way; with a long strip, steady the far end with your free hand.
- **Loading direction:** with the glass, load the strip curl-up; with the insert, curl-down.
- **Mounted slides:** lift the 135 clamp out, set the slide plate in, and drop the mount into its pocket the way you would hold it up to a window, image reading correctly from above (emulsion down). Lift it out by the two finger wells. Nothing else changes; refocus.
- **4×5 sheets:** lift the cover-stage off and set the 4×5 cover-stage on the same tenons with its own acrylic in place, set the sheet plate in its tray, and drop the sheet into the pocket image reading correctly from above (emulsion down). Lift it out by the edge notches. Refocus and re-set the column: 4×5 wants about 0.25×.
- **Getting the acrylic out:** lift the clamp off, reach in through the open front, and push the sheet up through the light window.
- **The cover-stage comes off as one piece:** grip it by the tray flange and lift straight up.
- **The flash never moves in:** it lies at the open front with its head firing into the cavity, and the receiver stays outside where its signal is clean and its batteries are reachable. Work in a dim room and keep ceiling light out of the box mouth.

> [!IMPORTANT]
> The assembled box is a gravity stack: no part is fastened to any other. Never tilt it, and never carry it assembled: take the clamp and the cover-stage off and move the pieces separately.

## If something is wrong

| Symptom at this stage | Where to look |
|---|---|
| The cover-stage stands high or rocks, or the holder will not settle in the tray | [Assembly problems](troubleshooting.md#assembly) |
| A dark patch, a bright side, or a clean dark band across frames | [Light and evenness](troubleshooting.md#light-and-evenness) |
| The film channel is too tight or too loose, or a part came out warped | [printing.md](printing.md#if-it-came-out-tight-or-loose) |

---

← [Printing](printing.md) · [Documentation index](../README.md#documentation) · [Scanning](scanning.md) →

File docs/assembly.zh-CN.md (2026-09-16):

# 装配

[English](assembly.md) · **简体中文** · [日本語](assembly.ja.md)

> 怎么把十二个打印件、三十二颗磁铁、四片钢垫片和一片乳白亚克力变成一台能用的光源，全程没有一件工具：按极性配对压入的磁铁，从主箱到顶盖台再到胶片夹的重力堆叠，以及让胶片面与传感器平行的镜子法。

**目录：**[开工之前](#开工之前) · [工具与安全](#工具与安全) · [什么固定什么](#什么固定什么) · [装配步骤](#装配步骤) · [换幅面与日常操作](#换幅面与日常操作) · [出问题的时候](#出问题的时候)

## 开工之前

这台机器上没有一颗螺丝、一段螺纹、一滴胶、一层漆，所以也不需要任何工具。每一处连接不是磁铁、就是定位结构，再不然就是重力，而且每一步都可逆：零件怎么落上去，就能怎么提下来。没有任何固化或晾干的等待，整台一口气装完；唯一值得放慢的是压磁铁，因为那是全程里唯一难以反悔的动作。

动手之前先验件。逐件检查的完整清单在[打印文档](printing.zh-CN.md#装配前逐件检查)里，外购件在[物料清单](bom.zh-CN.md)里；下面这四项是不合格就干不下去的：

- [ ] **顶盖台**四角的榫槽对准箱壁顶上的定位榫，靠自重落到**主箱**上，坐平不晃。
- [ ] 一颗 **Ø8 × 2 磁铁**能用手在沉孔里起头，用力一按才到底。这是过盈配合，紧是对的。
- [ ] **钢垫片**能被磁铁吸住。不锈钢的吸不住，而且之后不会有任何东西提醒你。
- [ ] **片条**不用硬塞就能滑过**夹底座**的通道，**夹上盖**放上去不晃。

## 工具与安全

没有工具清单，因为没有工具：不用烙铁，不用扳手，不用刀，不用胶，不用漆。值得备的只有两样：一只吹灰的气吹球，和最后一步用的一面约 30 mm 的小平面镜。磁铁用拇指压不到底时，把磁铁放在桌面上、按着零件往下压。这张桌子就是全程最接近"工具"的东西。

> [!WARNING]
> - **Ø8 × 2 磁铁**又小又强，误吞是真实的风险，放到小孩和宠物够不到的地方。两颗相吸时会夹住皮肉，也会抹掉磁卡、干扰硬盘。
> - 压进去的磁铁很难再取出来。每一颗都要在**压入之前**验好极性。
>
> 箱体里永远不进任何带电的东西：闪光灯躺在箱外的敞开前口处朝里打光，引闪接收器也跟它一起留在外面。

## 什么固定什么

NeoBox 装配堆叠的爆炸图

| 接口 | 方式 |
|---|---|
| 主箱 | 一体打印件，没有需要装配的地方 |
| 顶盖台 → 主箱 | 搁在箱壁顶上，四角榫槽套住定位榫。只靠重力，无螺丝 |
| 钢垫片 → 顶盖台 | 落进台面（顶盖台上表面）的四个沉孔，与台面齐平。不用胶：沉孔定位，上方的磁铁负责按住 |
| 乳白亚克力 → 顶盖台 | 躺在透光窗上方的暗槽里，顶面低于台面 0.4 mm。不固定 |
| 夹底座 → 顶盖台 | 托盘凸缘管定位，底座磁铁把它吸到钢垫片上 |
| 压片元件 → 夹底座 | 插片或防牛顿环玻璃搁在 4.6 mm 元件台阶上。故意做成松的 |
| 夹上盖 → 夹底座 | 八对磁铁 |
| 闪光灯 → 箱体 | 永远不进箱。灯平躺在敞开前口外的桌面上，灯头朝腔内打光 |

## 装配步骤

### 第 1 步——压入磁铁

**需要：**四个夹件（两个夹底座、两个夹上盖），32 颗 Ø8 × 2 磁铁，一支记号笔。

每个夹件压八颗磁铁：底座**从上面**压进顶面的沉孔，上盖**从下面**压进底面的沉孔。极性是这一步的全部：每颗底座磁铁必须和将来正对它的上盖磁铁相吸，而且必须在压入之前就对好，因为压入是全程里最接近"不可逆"的动作。

1. 把磁铁保持成一摞，从一端逐颗取用，途中不翻面，这样每颗磁铁离开摞时朝向都一样。
2. 夹底座平放，八颗磁铁同一朝向从顶面逐颗压入，每颗压到孔底。拇指通常够用；不够就把磁铁放在桌面上，按着零件往下压。
3. 夹上盖翻过来、底面朝上。每个沉孔先拿散磁铁去碰将来正对它的那颗底座磁铁，它会按相吸的朝向"啪"地贴上去。用笔在露出的那一面做记号，取下来，**记号面朝里**压进上盖的沉孔，让没做记号的相吸面留在外面。
4. 另一个幅面的底座和上盖照做。

**检查点：**每副夹子都能"啪"地吸合，捏住合好的夹子一端提起来也不散。上盖磁铁与盖底齐平；底座磁铁凸出板面 0.4 mm。这是设计如此，不是没压到位，不要试图把它按平。

**失败模式：**一颗装反的磁铁会把那个角的上盖顶开，而压进去的磁铁不会痛快地出来。第 3 小步的"碰一下、做记号"每颗只花几秒；省掉它可能赔上整个零件。

> [!IMPORTANT]
> 把这个三明治合紧的只有这八对磁铁，它们背后没有卡扣也没有螺丝。每个底座、每个上盖都要压满八颗；v1 里没有"可选磁铁"。

### 第 2 步——钢垫片入沉孔

**需要：**顶盖台，四片钢垫片（10 × 10 × 1 mm 方片或 Ø10 × 1 圆片）。

1. 每片垫片落进台面上的一个沉孔。

这一步就这么多。不用胶：沉孔让垫片与台面齐平地定位，用起来时上方夹底座的磁铁会把它按住。

**检查点：**指尖扫过台面，任何一片垫片处都摸不到台阶；拿一颗备用磁铁能把每片垫片直接吸出来。吸不起来的那片是不锈钢，现在就换掉，因为之后不会有任何东西提醒你。

**失败模式：**不锈钢垫片看着一模一样，坏起来无声无息：夹底座永远不会被吸进定位。凸出台面的垫片会把上面的底座垫歪。

### 第 3 步——亚克力入暗槽

**需要：**68 × 118 × 2 mm [乳白](glossary.zh-CN.md#乳白)亚克力（装的是 4×5 顶盖台，就是 106 × 130 × 2 mm 那块），气吹球。

1. **两面的保护膜都撕掉。**亚克力板出厂时两面都贴着膜。
2. 两面吹干净。
3. 把板放进托盘中央、透光窗上方的暗槽。它落进去之后，顶面比台面低 0.4 mm。

**检查点：**整片板四周都低于台面，在槽里能被轻轻拨动。松是对的：没有任何东西固定它，而那 0.4 mm 的落差意味着连上方的夹子都碰不到它。

**失败模式：**留在面上的保护膜会改变扩散效果，而它在乳白板上极难看出来。放进去之前先在四角找一找揭膜的翘边。

> [!NOTE]
> 亚克力上的灰尘不会出现在片子里：这块板本身就是漫射发光面，不是镜头拍摄的对象。偶尔用干布擦一次就够，绝不要用酒精、氨水或玻璃清洁剂，这三样都会让亚克力龟裂。

### 第 4 步——顶盖台落上主箱

**需要：**主箱，装好垫片和亚克力的顶盖台。

1. 捏住托盘凸缘端起顶盖台，四角榫槽对准箱壁顶上的定位榫，竖直放下。它靠自重落座。
2. 如果架高了或者发晃，是某个榫骑在了槽旁边：竖直提起、重新落。不压，不拧。

**检查点：**顶盖台平贴箱壁顶、四周无缝不晃，而且同样轻松地就能竖直提起来。

**失败模式：**榫进不了槽是打印问题（两边零件头几层的[象足](glossary.zh-CN.md#象足)），不是用力的理由。见[打印文档](printing.zh-CN.md#打紧了或打松了怎么办)。

### 第 5 步——夹底座入托盘

**需要：**已就位的顶盖台，你这个幅面的夹底座（装框幻灯片则是幻灯片板）；拍 6×6 的再加遮幅插片。

1. 把底座放进托盘凸缘里。单边 0.3 mm 的间隙，落进去几乎没有可察觉的旷量。
2. 松手让它落定：底座磁铁会找到台面里的钢垫片，把底座吸平、吸进定位。

**检查点：**底座平贴托盘底、不晃，落下去那一刻应当能感觉到磁铁"接住"了它。提出来再放一次，每次都应当落成同一个样子。

**失败模式：**落下去无动于衷，没有吸附感也没有定位感，说明第 2 步的垫片是不锈钢的或者根本没放。进不了凸缘的底座又是象足，不是用力的理由。

> [!NOTE]
> 拍 6×6 时，先把**遮幅插片**平放进托盘，再把 120 底座压在它上面。整副夹子因此抬高 1 mm，这是正常的。没有 6×4.5 的专用遮幅：直接用 120 的窗口拍，后期裁切。装框幻灯片用**幻灯片板**代替 135 底座单独立在托盘里：没有磁铁、没有元件、没有上盖，所以第 6 步对它不适用。拍 4×5 时**片板**同样单独立在 **4×5 顶盖台**的托盘里，后者带着第 3 步装好的自己那块亚克力，按第 4 步一样落到定位榫上；没有磁铁，没有第 6 步。

### 第 6 步——放压片元件、扣上盖

**需要：**你这个幅面的压片窗插片（或者 64 × 95 × 2 mm 防牛顿环玻璃，一片通用两个幅面），对应的夹上盖，气吹球。

1. 把元件放到外轨的 4.6 mm 元件台阶上。台阶把它架在片路上方 0.4 mm 处，而这 0.4 mm 就是整个压平设计：过片时片条从元件底下滑过，拱起的部位贴着元件底面被压平。元件装这一次，以后不再动它。
2. 用玻璃的话：**磨砂（AN）面朝下**，朝着胶片：磨砂面贴着片基的亮面，牛顿环就起不来。放进去之前把底面吹一遍：它离焦平面只有 0.2 mm，那里的灰尘是会入镜的。
3. 扣上盖。八对磁铁把它吸到位。

**检查点：**上盖四周落实、没有翘起的角，而元件在扣好的盖子下面还留有一丝浮动：上盖的限位腔给它留了 0.4 mm，能浮才是对的。元件被夹死说明哪里凸了：掀开来看，别硬压。

**失败模式：**玻璃亮面朝下就是在片基上招牛顿环。有一个角合不拢，是第 1 步装反的那颗磁铁迟到的报告。

### 第 7 步——相机端调平：镜子法

箱体上没有任何调平机构，也不缺这个机构：要紧的只有一层关系，就是**胶片面与传感器平行**，而相机端正是设定这层关系的正确一端，因为在那里动一次，整条链一起被修正，打印件的公差也包括在内。

**需要：**已装好、摆在相机下方的箱子，一面约 30 mm 的小平面镜。

1. 把镜子平放在扣好的夹子上，对准片窗的中央。
2. 开实时取景。你会看到镜头和相机的反射像。
3. 调**相机（不是箱子）**的俯仰和位置，直到镜头的反射像正好居中、看上去对称。
4. 反射像居中的那一刻，传感器就与镜面平行，而镜子正躺在胶片面上。完成。
5. 锁紧云台，再看一眼：拧紧这个动作本身会让东西移位。

```mermaid
flowchart TD
    A["装好堆叠，扣上夹子"] --> B["镜子平放在夹子上，对准片窗"]
    B --> C["相机开实时取景对着箱子"]
    C --> D{"镜头的反射像居中且对称吗"}
    D -- 否 --> E["调相机的俯仰和位置，永远不动箱子"]
    E --> C
    D -- 是 --> F["锁紧云台，再复查一遍"]
```

**检查点：**云台锁紧之后，反射像仍然居中。箱子或相机被动过就再查一次，只花几秒钟。

<details>
<summary>为什么调相机、为什么用镜子</summary>

水平仪量的是相对重力的水平，而重力不在光路里：一块对地绝对水平的台面，仍然可以相对传感器是歪的。镜子量的正是那层唯一要紧的关系，而且把它放大了一倍：传感器轴线与镜面之间的任何夹角，都会以两倍的量体现在反射像的位置上，所以"让镜头自己的反射像居中"是一个灵敏的归零判据。

在相机端调而不是在箱体上调，还把镜子以下的一切（箱壁顶的平整度、榫的落座、打印件层层叠叠的公差）在同一次动作里全部吸收掉了。垫箱子只能修箱子。这就是 v1 直接删掉箱体调平机构、而不是改良它的原因。

</details>

相机那一侧的设置：支架见[平行度](scanning.zh-CN.md#平行度)，各幅面的相机高度见[相机高度与支架](scanning.zh-CN.md#相机高度与支架)。

## 换幅面与日常操作

- **换幅面就是换夹子。**整副夹子提起来（它只靠磁铁吸着），再把另一个幅面的夹子放进去。插片各归各的夹子常驻不动；用防牛顿环玻璃的话，一片通用两个幅面，只把玻璃移到另一副夹子的台阶上。
- **过片：**捏住伸出夹外的片头直接抽。片尾搭在托盘凸缘顶上，比胶片面低 0.2 mm，一路托着它走；片条长就用另一只手托住远端。
- **装片方向：**用玻璃，拱面朝上装；用插片，拱面朝下装。
- **装框幻灯片：**把 135 那副夹子掀出来，放进幻灯片板，把框放进方槽，放法和你拿着它对着窗看时一样，从上往下看图像是正的（药膜朝下）。从两个指槽把它抠出来。其余什么都不变；重新对焦。
- **4×5 页片：**把顶盖台掀下来，把 4×5 顶盖台连同它自己那块已装好的亚克力放到同一组定位榫上，把片板放进它的托盘，再把页片放进片槽，从上往下看图像是正的（药膜朝下）。从边缺口把它抠出来。重新对焦并重设立柱：4×5 要的放大倍率约为 0.25×。
- **取亚克力：**掀掉夹子，从敞开前口伸手进去，经透光窗把板向上顶出来。
- **顶盖台整体可提起：**捏住托盘凸缘，竖直上提。
- **闪光灯永远在箱外：**平躺在敞开前口处，灯头朝腔内，接收器留在外面，信号干净，换电池也不用开箱。在昏暗的房间里拍，别让顶灯直射箱口。

> [!IMPORTANT]
> 组装好的箱子是一摞靠重力叠着的零件，没有任何一件固定在另一件上。不要倾斜它，更不要整机搬运：把夹子和顶盖台取下来，分开拿。

## 出问题的时候

| 这个阶段的现象 | 去哪里看 |
|---|---|
| 顶盖台架高或发晃，夹底座在托盘里落不定 | [故障排查：装配](troubleshooting.zh-CN.md#装配) |
| 有暗斑、有一侧偏亮，或者每张都有一条边界干净的暗带 | [故障排查：光线与均匀性](troubleshooting.zh-CN.md#光线与均匀性) |
| 走片通道太紧或太松，或者零件打翘了 | [打印文档里的偏紧偏松处理](printing.zh-CN.md#打紧了或打松了怎么办) |

---

← [3D 打印](printing.zh-CN.md) · [文档索引](../README.zh-CN.md#文档) · [翻拍扫描](scanning.zh-CN.md) →

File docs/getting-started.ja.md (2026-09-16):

# はじめに

[English](getting-started.md) · [简体中文](getting-started.zh-CN.md) · **日本語**

> お金を使う前に読んでください。NeoBox とは何か、自分に作れるのか、すでに何を持っている必要があるのか、いくらかかり、どれだけ時間がかかり、どの順番で進めるのか。

**目次：** [このプロジェクトはあなた向きか](#このプロジェクトはあなた向きか) · [カメラスキャンとは](#カメラスキャンとは) · [すでに持っている必要があるもの](#すでに持っている必要があるもの) · [費用と所要時間](#費用と所要時間) · [ロードマップ](#ロードマップ) · [必要なスキル](#必要なスキル) · [よくある質問](#よくある質問) · [用語を調べる場所](#用語を調べる場所)

---

## このプロジェクトはあなた向きか

NeoBox は、カメラの下に置いて 135 判と 120 判（最大 6×9）のネガ、そしてオプション部品でマウント済みの 135 スライドと 4×5 のシートを撮影する、すなわち[カメラスキャン](glossary.ja.md#カメラスキャン-camera-scanning) (camera scanning) するための、3D プリント可能なストロボ光源ボックスです。組み上がった状態で設置面積 124.8 × 154.8 mm、高さ 87 mm。床ではなく、机の上に収まるサイズです。

素のクリップオンストロボは机の上に寝かせ、発光部を筐体の**完全に開いた前面（オープンフロント）**に突き当てて、内部へ水平に発光させます。フィルムに向いている光は 1 本もありません。光は白い[拡散チャンバー](glossary.ja.md#積分キャビティ-integrating-cavity) (integrating cavity) の壁で何度も拡散反射したあと、62 × 95 mm の採光窓と、フィルム直下の[乳白](glossary.ja.md#乳白-opal) (opal) アクリル[拡散板](glossary.ja.md#拡散板-diffuser)を通って、上向きに抜けていきます。前面が開いているぶん室内光も入るので、薄暗い部屋で作業し、天井照明が開口部に直接差し込まないようにしてください。閃光の光量は室内光よりはるかに大きいので、それで足ります。

構成は聞いた印象よりも小さくまとまっています。

- **プリントパーツ 12 点**（白 3 点・黒 9 点。6×6 マスク、スライドプレート、4×5 の 2 点はオプション）。STL 12 ファイルはすべてサポート不要で、平らな面を下にして出力します。
- **乳白アクリル拡散板 1 枚**、68 × 118 × 2 mm。天板ステージのポケットに落とし込むだけ。
- **マグネット 32 個と鉄ワッシャー 4 枚**：Ø8 × 2 mm の N35 円板をフィルムホルダーの各パーツに圧入し、10 × 10 × 1 mm のワッシャーを天板ステージに面一で沈めます。
- **ねじなし、ねじ山なし、接着なし、工具なし。** 筐体は重力とマグネットだけで組み上がり、水平出しは箱ではなくカメラ側で行います。

> [!IMPORTANT]
> これは最初の公開リリースです。形状は Blender ソース上で寸法検証済みで、STL 12 ファイルはいずれも水密な単一ソリッド、すべての水平面が 0.2 mm グリッドに乗っています。ただしこの形状の箱は、**まだ一度も出力も撮影も実測も均一性テストもされていません。** あなたが作れば、あなたが最初の 1 人です。

**作るべき人。** すでにフィルムで撮っていて、スタンドに載せられるカメラを持っている人。振動が問題にならない[ベース ISO](glossary.ja.md#ベース-iso) (base ISO)・f/8 の撮影がしたい人。パーツの出力とマグネットの圧入が苦にならない人。締める・はんだ付けする・接着する作業は一切ありません。

**やめておくべき人。** 3D プリンタも出力サービスも使えない人。構造部品はすべてプリントで、公開ファイルに代替ルートはありません。4×5 は同じ本体で可能ですが、均一性には留保があります。[よくある質問](#よくある質問)を参照してください。

> [!WARNING]
> **ビルドプレートの事前確認。** 最大の 2 点 `main-body.stl` と `cover-stage.stl` の設置面積はどちらも 124.8 × 154.8 mm。160 × 160 mm の[ビルドプレート](glossary.ja.md#ビルドプレートのサイズ-bed-size)があれば全パーツを出力でき、いまどきのデスクトップ機ならまず足ります。サポートはどのパーツにも不要で、向きのルールはただ 1 つ、ホルダーの蓋 2 点だけは天面を下に、それ以外は平らな底面を下にして出力します。160 × 160 mm に届かない場合は、ほかにお金を使う前に外注のあてを付けてください。

お金を動かす前に確定させることが 3 つあります。

- [ ] 設置面積 124.8 × 154.8 mm のパーツを自分で出力できるか、出力してもらえるか。要は、160 × 160 mm のビルドプレートに手が届くかどうか。
- [ ] **マニュアル発光**できるクリップオンストロボを、持っているか、これから買うか。メーカーは問いません。箱の外に置くだけです。
- [ ] マクロ撮影できるレンズと、箱の真上でカメラをフィルム面と平行に保持できるものを持っているか。

3 つとも「はい」なら[部品表](bom.ja.md#工具と消耗品)へ進んでください。1 つ目が「いいえ」なら、ここで終わりです。

製造総図：プリントする 12 ファイルの寸法と出力上の注意、購入部品、そして組み上がった箱の断面

## カメラスキャンとは

カメラスキャンとは、ネガをスキャナに通す代わりに、背面から照らしたネガをデジタルカメラで撮影することです。フィルムは均一に光る面の上のホルダーに収まり、カメラは真上から見下ろし、撮影した [RAW](glossary.ja.md#raw) ファイルを後から[反転](glossary.ja.md#反転-inversion) (inversion) させます。

フラットベッドスキャナと比べた場合のトレードオフは、セットアップの手間と引き換えに速度を得ることです。リグを合わせ込むのに一晩かかりますが、それ以降は 1 コマがシャッター 1 回です。ラボスキャンと比べると、ネガは手元に残り、色の判断はすべて自分の側に残ります。

NeoBox が担当するのは、そのうち光源側の半分だけです。ライトパッドを置き換えるものであって、どのカメラを使うかについては何も言いません。ただしカメラ側は本当に作業量があり、それは[スキャン](scanning.ja.md#カメラ側の機材)ドキュメントに書いてあります。

## すでに持っている必要があるもの

以下にプリントパーツはありません。ストロボとトリガーは参考機種として[部品表](bom.ja.md#工具と消耗品)に載っていますが、それ以外はあらかじめ持っている必要があり、本プロジェクトでは金額を出しません。

| 必要なもの | なぜ必要か | 費用 |
|---|---|---|
| マニュアル露出と RAW が使えるカメラ | 露出は手で決め、1 本のあいだ一度も変えないため | 本書では算定しない |
| マクロ撮影できるレンズ | フルサイズのセンサーを 135 のコマで埋めるには[撮影倍率](glossary.ja.md#撮影倍率-magnification-ratio) (magnification ratio) 1:1 が要る。1:1 マクロなら本機が扱う全フォーマットをカバーでき、大きいフォーマットほど倍率は低くて済む | 本書では算定しない |
| [複写スタンド](glossary.ja.md#複写スタンド-copy-stand) (copy stand)、または水平・反転できるセンターポールを持つ三脚 | フィルム面は箱の設置面から 83.2 mm 上に来る。カメラはその上に、フィルム面と平行に構える必要がある | 本書では算定しない |
| マニュアル発光できるクリップオンストロボ | 光源そのもの。机に寝かせて発光部を開口部に当てるだけで、箱の中には入らない。メーカーは問わず、NEEWER TT560 は参考機種にすぎない | 部品表を参照 |
| ラジオトリガーのセット | 送信機はカメラのホットシューに。受信機はストロボと一緒に箱の外に残るので、電波が筐体に遮られず、電池交換で箱に触れる必要もない。参考機種：ZENIKO T1 | 部品表を参照 |
| リモートレリーズ | コマとコマのあいだ、カメラに手を触れないため | 本書では算定しない |
| 反転ソフトウェア | 撮影した RAW をポジに変えるため | 本書では算定しない |
| ブロアーと小さな平面鏡 | ブロアーはフィルムと（使うなら）ガラスをホコリから守る。平面鏡は水平出しの道具そのもので、鏡に映るレンズ自身の像を中央に合わせて使う | [部品表](bom.ja.md#工具と消耗品)に一覧 |

> [!NOTE]
> カメラ側は意図的に値段を出していません。マクロレンズとスタンドは、すでに持っていれば 0 円、そうでなければプロジェクトの残り全部より高くつくこともあります。ここで金額を書いても、根拠のない数字をでっち上げるだけです。大事なのは、部品を発注する前にそれらが手元にあることです。

ストロボが使えるかどうかを決めるのは、**マニュアル発光できるか**、その 1 点だけです。本体の寸法は関係なく、発光部が回る必要もありません。開口部の前に寝かせるだけだからです。[TTL](glossary.ja.md#ttl-through-the-lens-調光) も [HSS](glossary.ja.md#hss-ハイスピードシンクロ) もここでは無意味なので、そこにお金を払わないでください。

## 費用と所要時間

価格はすべて[部品表](bom.ja.md#工具と消耗品)にまとめてあります。このページでは支出を仕分けるだけです。

| 何を買うのか | 費用 |
|---|---|
| 構造にかかわるすべて：PLA プリントパーツ 12 点、乳白アクリル、マグネット 32 個、鉄ワッシャー 4 枚 | 部品表に記載 |
| クリップオンストロボ（マニュアル発光できるホットシュー機ならどれでも） | 参考機種を部品表に記載 |
| ラジオトリガーのセット | 参考機種を部品表に記載 |
| オプション：アンチニュートンガラス、植毛シート | 部品表に記載 |
| カメラ、レンズ、スタンド、レリーズ、ソフトウェア | 本書では算定しない |

出力は小さな仕事です。154.8 mm より長いパーツはなく、普通の PLA で足り、全パーツがサポート不要で、積層ピッチ 0.2 mm、インフィル 15% です。

| 工程 | 目安の所要時間 | 備考 |
|---|---|---|
| 3D プリント（自宅または出力サービス） | 数日 | ほぼ必ずクリティカルパス。2 色構成、サポートの除去なし |
| 乳白アクリルの指定寸法カット | 数日 | 68 × 118 × 2 mm の指定カット。プロトタイプ時代の 110 × 130 mm 板があれば、切り直して使い回せる |
| マグネットと鉄ワッシャー | たいてい最初に届く | すべて規格品で、特注はなし |
| 組立 | 数分 | 工具不要。作業の大半はマグネット 32 個の圧入 |
| 最初のセットアップ | 一晩 | 鏡でカメラの平行出し、そのあと均一性の確認 |

> [!TIP]
> 3 つの発注はリードタイムがまったく違うので、順番にではなく同じ日にまとめて出してください。クリティカルパスはほぼ必ず出力です。

## ロードマップ

```mermaid
flowchart TD
    A[判断：出力できるか] --> B[部品・アクリル・マグネットを買う]
    B --> C[12 ファイルを出力または発注]
    C --> D[組む前に全パーツを検品]
    D --> E[組立：マグネット圧入、アクリル、積み上げ]
    E --> F[鏡を使ってカメラの平行を出す]
    F --> G[キャリブレーション：フラットフィールド補正]
    G --> H[最初の 1 本をスキャン]
```

| ステップ | 実際にやること | 解説ドキュメント |
|---|---|---|
| 判断 | ビルドプレートのサイズ（160 × 160 mm で足りる）、ストロボの有無、すでに持っているもの | このページ |
| 購入 | 部品と消耗品、発注用の文面、到着時の受け入れ検査 | [部品表](bom.ja.md#工具と消耗品) |
| 出力 | STL 12 ファイルを普通の PLA で出力。[積層ピッチ](glossary.ja.md#積層ピッチ-layer-height) 0.2 mm、インフィル 15%、サポートなし | [出力](printing.ja.md#出力サービスへの発注) |
| パーツ検品 | 組む前に測る。いま見つかった不良は再出力で済むが、後で見つかると組立ごとやり直しになる | [出力](printing.ja.md#組み立てる前に各パーツを確認する) |
| 組立 | マグネット 32 個をホルダーのパーツに圧入し、アクリルとワッシャーを天板ステージに収め、全体を積み上げる。工具は使わない | [組立](assembly.ja.md#組立手順) |
| 平行出し | フィルム面に小さな鏡を置き、レンズ自身の映り込みが中央に来るまでカメラを動かす。調整するのはカメラで、箱ではない | [組立](assembly.ja.md#ステップ-7--カメラ側で平行を出す鏡の方法) |
| キャリブレーション | フィルムなしの発光面を撮影し、まず[フラットフィールド補正](glossary.ja.md#フラットフィールド補正-flat-field-correction) (flat-field correction) をかけてから均一性を判断する | [撮影](scanning.ja.md#フラットフィールド補正と反転) |
| 最初の 1 本 | カメラの高さ、ピント、発光量、フィルムの装填、撮影、反転 | [スキャン](scanning.ja.md#フィルムの装填) |
| うまくいかないとき | 症状 → 原因の候補 → 対処。全工程分 | [トラブルシューティング](troubleshooting.ja.md#プリント) |

## 必要なスキル

特別なものは何もありません。スライサーのデフォルトプロファイルに従えて、フィルムのまわりで手を清潔に保てるなら作れます。ドライバーもスパナもはんだごても接着剤も出番がなく、CAD 作業も一切不要です。設計は特定のストロボ機種に縛られていません。

つまずきやすいのは 2 か所だけで、どちらもそこに到達する前に 2 回読んでおく価値があります。

**マグネットの極性。** Ø8 × 2 mm のマグネット 32 個を、1 パーツあたり 8 個ずつ圧入します。どのマグネットも相手側パーツのマグネットと引き合う向きでなければならず、圧入は抜き戻すことを想定した嵌合ではありません。押し込む前に、すでに収めた相手側と極性を必ず突き合わせてください。

**平行出し。** フィルム面は水平であれば足りるのではなく、センサーと**平行**でなければなりません。しかもこの設計では、箱の側に調整機構はありません。フィルムの位置に小さな平面鏡を置き、レンズ自身の映り込みが画面のど真ん中に来るまでカメラを動かします。中央に来た瞬間、センサーはフィルム面と平行になり、その下にあるプリントパーツの公差もまとめて吸収されています。平行が先、均一性が後です。

<details>
<summary>なぜ連続光の LED パネルではなくストロボを設計の中心に据えたのか</summary>

閃光パルスこそが露光です。薄暗い部屋なら、拡散チャンバーを経て届く閃光の光量は、開いた前面から入る室内光を圧倒します。しかもパルスは実シャッター時間のほんの一瞬で終わるので、振動もシャッターショックも床の揺れも、関係がなくなります。

利点はそれだけではありません。全コマがまったく同じ光量を受けるので、反転プロファイルは 1 本のロールに 1 つで済みます。ベース ISO・f/8 という動作点も、キセノン管が出す本当に連続したデイライトバランスのスペクトルも、ストロボを選んだからこそのものです。

</details>

## よくある質問

**誰かが実際に作ったのですか。** いいえ。v1 の形状は CAD 上で寸法検証済み、書き出したファイルも数値検証済みですが、この形状の箱は 1 台も出力も撮影も実測も均一性テストもされていません。出力されたことがあるのは旧プロトタイプだけで、v1 と共通する部品はほぼありません。光学に関する記述はすべて、実測ではなく筋の通った推論として読んでください。

**ストロボの代わりに LED パネルを使えますか。** 公開ファイルのままでは使えません。LED 版は公開しておらず、採用しなかった理由は上の折りたたみブロックにあります。部品表のオプション LED ストリップはポジションライトであって、露光用の光源ではありません。

**手持ちのストロボは入りますか。** 使えます。そもそも箱に入れないからです。ストロボは机に寝かせ、発光部を完全に開いた前面に当てるだけなので、本体の寸法は一切関係ありません。マニュアル発光できるクリップオンストロボならどれでも使えます。NEEWER TT560 は、光路設計の基準にした参考機種にすぎません。

**マグネットは必要ですか。** 必要です。32 個全部と、鉄ワッシャー 4 枚もです。各蓋の 8 個が各ベースの 8 個と引き合ってホルダーを閉じ、ベース側のマグネットは天板ステージに面一で沈めたワッシャーもつかみます。ホルダーがステージに固定されるのも、5 秒でフォーマットを入れ替えられるのも、この磁力のおかげです。なければ、すべてが自重で載っているだけになります。

**220 × 220 mm のビルドプレートで出力できますか。** できます。全パーツ、余裕をもって収まります。設置面積が 124.8 × 154.8 mm を超えるパーツはないので 160 × 160 mm でも足り、サポートが要るパーツもありません。

**アンチニュートンガラスは必要ですか。** いいえ。標準の押さえはフォーマットごとの押さえ窓インサート（プリント品）です。窓の四辺が固い規制面になり、フィルムの浮き上がりは最大でも 0.28 mm で、等倍・f/8 での被写界深度およそ ±0.4 mm に完全に収まります。1 枚で両フォーマット共通のアンチニュートンガラス（64 × 95 × 2 mm）はアップグレードで、画面全体を連続して押さえます。すりガラス面がフィルムベースの光沢面に接するため[ニュートンリング](glossary.ja.md#ニュートンリング-newton-rings)は出ず、乳剤面は下の開口に向くので何にも触れません。

> [!CAUTION]
> ガラスを使う場合、ガラス下面は焦点面から 0.2 mm しか離れていないので、そこに付いたホコリはそのまま写ります。エレメントは一度収めたら動かしません。収める前にブロアーで吹いてください。対照的に、乳白アクリルの上のホコリは決して写りません。発光面そのものの上にあるからで、ときどき拭けば十分です。

**4×5 は使えますか。** はい。オプションの部品 2 点と一回り大きいアクリル、それに留保が 1 つ付きます。`cover-stage-4x5.stl` が同じ本体の上で天板ステージの代わりに載り、102 × 126 mm の採光窓と、106 × 130 × 2 mm の乳白板を収める溝を持ちます。`sheet-plate-4x5.stl` はそのトレイに立ち、97 × 121 mm の窓の上の 102.2 × 127.6 mm のポケットでシートを受けます。蓋もガラスもありません。4×5 の撮影倍率では、被写界深度が反りをまるごと吸収します。留保は均一性です。窓はチャンバーの壁から 9 と 12 mm で、v1 の 29 と 27.5 より近く、何も測っていません。まず何も入れずに 1 コマ撮ってください。[設計 §10](design.ja.md#10-v1-本体での-45)と[4×5 シート](scanning.ja.md#45-シート)を参照してください。

**マウント済みスライドは使えますか。** はい、オプションのスライドプレートで使えます。135 用の通路は高さ 0.4 mm、素のフィルムストリップ用の寸法なので、マウントがホルダーに入ることはありません。代わりに `slide-plate-135.stl` がホルダーの位置にトレイに立ちます。51.4 mm 角のポケットが紙・プラスチック・ガラスのマウントを受け、その下に 26 × 38 mm の窓があります。蓋もマグネットもなく、ポケットが位置を決めて重力が押さえます。[マウント済みスライド](scanning.ja.md#マウント済みスライド)を参照してください。マウントなしのポジフィルムは、ほかのストリップと同じく 135 ホルダーに通します。

**コマ送りとフォーマットの切り替えはどうやるのですか。** コマ送りは引き抜きです。ホルダーから出ているフィルムの先端をつまんで、そのまま引きます。押さえエレメントの下をすべる間にフィルムの反りは押しならされ、1 本撮り終えるまでホルダーを開けることはありません。フォーマットの切り替えは、ホルダーを持ち上げて別のホルダーを載せるだけ。マグネットが位置を決めてくれるので 5 秒ほどです。6×6 はマスクを 120 ベースの下に敷きます。ホルダー全体が 1 mm 持ち上がりますが、それで正常です。6×4.5 専用のマスクはないので、後処理でトリミングしてください。長いストリップの後端はトレイのフランジに載り、フィルム面よりわずかに低い位置で支えられるので、先のほうには手を添えてください。装填と取り扱いは[スキャン](scanning.ja.md#フィルムの装填)で扱います。

## 用語を調べる場所

このプロジェクトは、フィルム写真・光学・FDM 出力という 3 つの分野の語彙を大量に使い、しかも 1 つの文の中で混ぜます。どの用語も[用語集](glossary.ja.md#カメラスキャン-camera-scanning)に 1 行ずつ、一度だけ定義してあります。

言葉に引っかかったら、まずそこを見てください：[拡散チャンバー](glossary.ja.md#積分キャビティ-integrating-cavity)、[フラットフィールド補正](glossary.ja.md#フラットフィールド補正-flat-field-correction)、[同調速度 (sync speed)](glossary.ja.md#同調速度-sync-speed)、[ガイドナンバー](glossary.ja.md#ガイドナンバー-gn)、[サポート (supports)](glossary.ja.md#サポート-supports)、[積層ピッチ](glossary.ja.md#積層ピッチ-layer-height)、[ワーキングディスタンス (working distance)](glossary.ja.md#ワーキングディスタンス-working-distance)、[ニュートンリング](glossary.ja.md#ニュートンリング-newton-rings)、[ベース ISO](glossary.ja.md#ベース-iso)、[EV](glossary.ja.md#ev-露出値)。

寸法そのものではなく、その寸法に至った理由を知りたいときは、[設計](design.ja.md#3-光学上の判断)ドキュメントに工学的な根拠が、[設計ログ](design-log.ja.md#設計ログ)に試して却下した案の記録があります。

---

← [README](../README.ja.md) · [ドキュメント一覧](../README.ja.md#ドキュメント) · [部品表](bom.ja.md) →

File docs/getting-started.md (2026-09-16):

# Getting started

**English** · [简体中文](getting-started.zh-CN.md) · [日本語](getting-started.ja.md)

> Read this before you spend anything: what NeoBox is, whether you can build it, what you must already own, what it costs, how long it takes, and the order to do it in.

**Contents:** [Is this project for you?](#is-this-project-for-you) · [What camera scanning is](#what-camera-scanning-is) · [What you must already own](#what-you-must-already-own) · [What it costs and how long it takes](#what-it-costs-and-how-long-it-takes) · [The road map](#the-road-map) · [Skills you need](#skills-you-need) · [FAQ](#faq) · [Where to look things up](#where-to-look-things-up)

---

## Is this project for you?

NeoBox is a 3D-printable flash light source box that sits under your camera so you can photograph, or [camera-scan](glossary.md#camera-scanning), 35 mm and 120 negatives up to 6×9, plus mounted 135 slides and 4×5 sheets with the optional parts. The assembled stack has a 124.8 × 154.8 mm footprint and stands 87 mm tall: it lives on a desk, not on the floor.

A bare speedlight lies flat on the desk with its head against the box's fully open front, firing horizontally into the white [cavity](glossary.md#integrating-cavity). Nothing points at the film. The light bounces off the white walls several times, then leaves upward through a 62 × 95 mm window and one [opal](glossary.md#opal) acrylic [diffuser](glossary.md#diffuser) directly under the film. The open front also lets room light in: work in a dim room and keep ceiling lights from shining into the opening. The flash pulse is far stronger than anything the room adds.

The whole build is smaller than it sounds:

- **12 printed parts** (three white, nine black; the 6×6 mask, the slide plate and the two 4×5 parts are optional), all twelve STL files support-free, each printed with its flat face down.
- **1 opal acrylic diffuser**, 68 × 118 × 2 mm, dropped into a pocket in the cover-stage.
- **32 magnets and 4 steel washers**: Ø8 × 2 mm N35 discs press-fitted into the film holder parts, and 10 × 10 × 1 mm washers that sit flush in the cover-stage.
- **No screws, no threads, no glue, no tools.** The box assembles by gravity and magnets, and levelling happens at the camera, not inside the box.

> [!IMPORTANT]
> This is the first release. The geometry is dimensionally verified in the Blender source, and all twelve STL files are watertight single solids with every horizontal face on the 0.2 mm grid. But no box of this geometry has **ever been printed, photographed, measured or evenness-tested.** If you build one, you are the first.

**Build it if you** already shoot film and already own a camera you can put on a stand; want [base-ISO](glossary.md#base-iso), f/8 captures where vibration is irrelevant; and are happy to print the parts and press in some magnets. There is nothing to screw, solder or glue.

**Do not start if you** have neither a 3D printer nor access to a print service: every structural part is printed and there is no alternative route in the released files. 4×5 is possible on the same body, with an evenness caveat; see the [FAQ](#faq).

> [!WARNING]
> **Build-plate go/no-go.** The two largest parts, `main-body.stl` and `cover-stage.stl`, share a 124.8 × 154.8 mm footprint, so a 160 × 160 mm [bed](glossary.md#bed-size) prints the entire set, and any current desktop machine qualifies. Nothing needs supports; the one orientation rule is that the two holder lids print top face down while every other part prints flat bottom down. If you cannot reach a 160 × 160 mm bed, settle the outsourcing route before you spend anything else.

Three things to settle before any money moves:

- [ ] Can you reach a 160 × 160 mm bed, your own or a service's, for parts with a 124.8 × 154.8 mm footprint?
- [ ] Do you own, or will you buy, a hot-shoe speedlight with **manual power control**? Any brand; it sits outside the box.
- [ ] Do you own a macro-capable lens and something that holds the camera square above the box?

If all three are yes, continue to the [bill of materials](bom.md#tools-and-consumables). If the first is no, stop here.

One-page manufacturing overview: the twelve printed files with their sizes and print notes, the bought parts, and a section through the assembled box

## What camera scanning is

Camera scanning means photographing a backlit negative with a digital camera instead of running it through a scanner. The film sits in a holder above an evenly glowing surface, the camera looks straight down at it, and you [invert](glossary.md#inversion) the [raw](glossary.md#raw) file afterwards.

Against a flatbed, the trade is setup work for speed: aligning the rig takes an evening, but afterwards each frame is one shutter press. Against a lab scan, you keep the negative in your hands and the whole colour decision stays yours.

NeoBox is only the light source half of that. It replaces the light pad, and it says nothing about which camera you use. The camera half is real work, though, and it is written up in [scanning](scanning.md#camera-side-equipment).

## What you must already own

Nothing below is a printed part. The flash and the trigger appear in the [bill of materials](bom.md#tools-and-consumables) as reference picks; everything else you must already have, and none of it is costed by this project.

| You need | Why | Cost |
|---|---|---|
| A camera with manual exposure and raw | The exposure is set by hand and never changes across a roll | not costed here |
| A macro-capable lens | Filling a full-frame sensor with a 135 frame needs 1:1 [magnification](glossary.md#magnification-ratio); any 1:1 macro lens covers every format this box handles, at less than full magnification for the larger ones | not costed here |
| A [copy stand](glossary.md#copy-stand), or a tripod with a horizontal or reversible column | The film plane sits 83.2 mm above whatever the box stands on; the camera must hang above that, square to it | not costed here |
| A hot-shoe speedlight with manual power control | The light source. It lies flat on the desk with its head at the open front and never enters the box; any brand fits, and the NEEWER TT560 is only the reference pick | see the bill of materials |
| A radio trigger set | Transmitter on the camera hot shoe; the receiver stays outside with the flash, so the signal is never boxed in and batteries change without touching the box. Reference pick: ZENIKO T1 | see the bill of materials |
| A remote release | Keeps your hand off the camera between frames | not costed here |
| Inversion software | Turns the raw capture into a positive | not costed here |
| A rocket blower and a small flat mirror | The blower keeps film (and the optional glass) free of dust; the mirror is the levelling instrument: you centre the lens's own reflection in it | listed in [bom](bom.md#tools-and-consumables) |

> [!NOTE]
> The camera side is deliberately not priced. A macro lens and a stand can cost anything from nothing, if you already own them, to more than the rest of the project combined, so quoting a figure would be inventing one. What matters is that you have them before you order parts.

Only one thing decides whether a flash is suitable: **manual power control**. No dimension of it matters and the head does not need to tilt or swivel, because the flash simply lies at the opening. [TTL](glossary.md#ttl) and [HSS](glossary.md#hss) are useless here, so do not pay for them.

## What it costs and how long it takes

Prices live in one place, the [bill of materials](bom.md#tools-and-consumables); this page only sorts the spending into piles:

| What you are buying | Cost |
|---|---|
| Everything structural: twelve PLA parts, the opal acrylic sheet, 32 magnets, 4 steel washers | priced in the bill of materials |
| A speedlight (any hot-shoe model with manual power control) | reference pick priced in the bill of materials |
| A radio trigger set | reference pick priced in the bill of materials |
| Optional upgrades: anti-Newton glass and flocking sheet | priced in the bill of materials |
| Camera, lens, stand, release, software | not costed here |

Printing is a small job: nothing is longer than 154.8 mm, plain PLA is fine, and every part goes down support-free: 0.2 mm layers, 15 % infill.

| Stage | Typical elapsed time | Notes |
|---|---|---|
| 3D printing, at home or from a service | days | usually the critical path; two colours, no supports to remove |
| Opal acrylic cut to size | days | 68 × 118 × 2 mm custom cut; a prototype-era 110 × 130 mm sheet can be cut down and reused |
| Magnets and washers | usually the fastest order | stock sizes, nothing custom |
| Assembly | minutes | no tools; pressing in the 32 magnets is most of the work |
| First set-up | an evening | camera parallelism with the mirror, then an evenness check |

> [!TIP]
> The three orders have very different lead times, so place them on the same day rather than in sequence. The critical path is almost always the printing.

## The road map

```mermaid
flowchart TD
    A[Decide: can you print it] --> B[Buy parts, acrylic, magnets]
    B --> C[Print or order the 12 files]
    C --> D[Check every part before you build]
    D --> E[Assemble: magnets, acrylic, stack]
    E --> F[Align the camera with the mirror method]
    F --> G[Calibrate: flat-field correction]
    G --> H[Scan your first roll]
```

| Step | What actually happens | Written up in |
|---|---|---|
| Decide | Bed size (160 × 160 mm is enough), flash on hand, what you already own | this page |
| Buy | Parts and consumables; vendor scripts; acceptance checks on arrival | [bom](bom.md#tools-and-consumables) |
| Print | Twelve STL files in plain PLA: 0.2 mm [layers](glossary.md#layer-height), 15 % infill, no supports | [printing](printing.md#ordering-from-a-print-service) |
| Check parts | Measure before you build; a wrong part found now costs a reprint, found later costs the build | [printing](printing.md#check-each-part-before-you-assemble) |
| Assemble | Press 32 magnets into the holder parts, drop the acrylic and washers into the cover-stage, stack everything, no tools | [assembly](assembly.md#assembly-steps) |
| Align | A small mirror on the film plane; move the camera until its own lens reflection is centred; the camera levels, the box does not | [assembly](assembly.md#step-7--level-at-the-camera-the-mirror-method) |
| Calibrate | Photograph the bare glowing window and apply [flat-field correction](glossary.md#flat-field-correction) before judging evenness | [scanning](scanning.md#flat-field-and-inversion) |
| First roll | Camera height, focus, flash power, loading film, shooting, inverting | [scanning](scanning.md#loading-film) |
| Something is wrong | Symptom → likely cause → fix, for every stage | [troubleshooting](troubleshooting.md#printing) |

## Skills you need

Nothing exotic. If you can follow a slicer's default profile and keep your hands clean around film, you can build this. There is no screwdriver, spanner, soldering iron or glue anywhere in the build, and no CAD work at all; the design is not tied to any flash model.

Two steps catch people out, and both are worth reading twice before you reach them:

**Magnet polarity.** Thirty-two Ø8 × 2 mm magnets go into the holder parts, eight per part, as press-fits. Every magnet must attract its partner in the mating part, and an interference fit is not meant to come back out. Dry-check the polarity of each magnet against its already-seated partners before pressing it home.

**Parallelism.** The film plane must be parallel to the sensor, not merely horizontal, and in this design nothing on the box adjusts. Lay a small flat mirror where the film goes and move the camera until the reflection of its own lens sits dead centre in the frame. When it does, the sensor is parallel to the film plane, and every printed-part tolerance underneath has been absorbed in the same move. Parallelism first, evenness second.

<details>
<summary>Why the design is built around a flash and not a continuous LED panel</summary>

The flash pulse **is** the exposure. In a dim room, its output through the cavity dwarfs anything ambient light adds through the open front, and the pulse is over in a small fraction of any real shutter time, so vibration, shutter shock and floor rumble stop mattering.

Other things follow from the same choice. Every frame receives identical output, so one inversion profile fits the whole roll. Base-ISO, f/8 shooting is the design's working point, and a xenon tube gives a genuinely continuous, daylight-balanced spectrum.

</details>

## FAQ

**Has anyone built one?** No. The v1 geometry is dimensionally verified in CAD and the exported files are numerically checked, but no box of this geometry has ever been printed, photographed, measured or evenness-tested; the only thing ever printed was the old prototype, which shares almost no parts with v1. Treat every optical claim as reasoned, not measured.

**Can I use an LED panel instead of a flash?** Not with the released files: no LED variant is published, and the argument against one is in the collapsed block above. The optional LED strip in the bill of materials is a positioning light only, never the exposure.

**Will my flash fit?** Yes. The flash never enters the box: it lies flat on the desk with its head at the fully open front, so no dimension of it matters. Any hot-shoe speedlight with manual power control works; the NEEWER TT560 is only the reference the light path was drawn around.

**Do I need the magnets?** Yes: all 32, plus the 4 steel washers. Eight magnets in each lid pull against eight in each base to clamp the holder shut, and the base magnets also grip the washers set flush in the cover-stage, which is what holds the holder to the stage and makes the five-second format swap possible. Without them, everything merely rests under its own weight.

**Can I print this on a 220 × 220 mm build plate?** Yes, the entire set, with room to spare. Nothing exceeds a 124.8 × 154.8 mm footprint, so even a 160 × 160 mm bed is enough, and no part needs supports.

**Do I need the anti-Newton glass?** No. The default pressure element is a printed insert per format: the window edges are hard limits and the film cannot bow more than 0.28 mm, inside the roughly ±0.4 mm depth of field at 1:1, f/8. The anti-Newton glass (64 × 95 × 2 mm, one sheet shared by both formats) is an upgrade that caps the whole frame continuously; its matte face rests on the film's glossy base, so no [Newton rings](glossary.md#newton-rings), and the emulsion faces the open window below, touching nothing.

> [!CAUTION]
> In glass mode the underside of the glass sits 0.2 mm from the focal plane, so a dust speck there lands in the image. The element goes in once and stays, so blow it clean before it goes in. Dust on the opal acrylic, by contrast, never images: it lies on the glowing surface itself, and an occasional wipe is enough.

**Does it do 4×5?** Yes, with two optional parts, a larger acrylic and one caveat. `cover-stage-4x5.stl` replaces the cover-stage on the same main body, with a 102 × 126 mm light window and a recess for a 106 × 130 × 2 mm opal sheet; `sheet-plate-4x5.stl` stands in its tray and takes the sheet in a 102.2 × 127.6 mm pocket over a 97 × 121 mm window. No lid, no glass: at 4×5 magnification the depth of field covers any curl. The caveat is evenness: the window sits 9 and 12 mm from the cavity walls instead of v1's 29 and 27.5, and nothing has been measured, so shoot a blank frame first. See [Design § 10](design.md#10-45-on-the-v1-body) and [4×5 sheets](scanning.md#45-sheets).

**Does it do mounted slides?** Yes, with the optional slide plate. The 135 channel is 0.4 mm high, sized for bare strips, so a mount never enters the holder; instead `slide-plate-135.stl` stands in the tray in the holder's place, with a 51.4 mm square pocket that takes card, plastic and glass mounts over a 26 × 38 mm window. No lid, no magnets: the pocket locates the mount and gravity holds it. See [Mounted slides](scanning.md#mounted-slides). Unmounted transparencies go through the 135 holder like any strip.

**How do I advance film, and switch formats?** Advance by pulling: grip the strip where it leaves the holder and draw it through. The pressure element flattens any arch as the film slides under it, and the holder is never opened mid-roll. To switch formats, lift one holder off and set the other down; the magnets locate it, about five seconds. For 6×6, lay the mask under the 120 base; the holder rides 1 mm higher, which is normal. 6×4.5 has no dedicated mask, so crop in post. A long strip's tail rests on the tray flange just below the film plane, so give its far end a hand. Loading and handling are covered in [scanning](scanning.md#loading-film).

## Where to look things up

This project uses a lot of vocabulary from three different trades (film photography, optics and FDM printing) and mixes them in single sentences. Every term is defined once, in one line, in the [glossary](glossary.md#camera-scanning).

Start there whenever a word stops you: [integrating cavity](glossary.md#integrating-cavity), [flat-field correction](glossary.md#flat-field-correction), [sync speed](glossary.md#sync-speed), [guide number](glossary.md#guide-number), [supports](glossary.md#supports), [layer height](glossary.md#layer-height), [working distance](glossary.md#working-distance), [Newton rings](glossary.md#newton-rings), [base ISO](glossary.md#base-iso), [EV](glossary.md#ev).

For the reasoning behind a dimension rather than the dimension itself, the [design](design.md#3-optical-decisions) document holds the engineering, and the design log records what was tried and rejected.

---

← [README](../README.md) · [Documentation index](../README.md#documentation) · [Bill of materials](bom.md) →

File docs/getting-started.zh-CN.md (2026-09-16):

# 从这里开始

[English](getting-started.md) · **简体中文** · [日本語](getting-started.ja.md)

> 在花钱之前先读这一篇：NeoBox 是什么、你能不能做出来、需要自备哪些器材、总共要花多少钱和多长时间，以及各步骤的先后顺序。

**目录：** [本项目是否适合你](#本项目是否适合你) · [什么是相机翻拍](#什么是相机翻拍) · [你需要自备的器材](#你需要自备的器材) · [费用与时间](#费用与时间) · [整体流程](#整体流程) · [需要的技能](#需要的技能) · [常见问题](#常见问题) · [到哪里查资料](#到哪里查资料)

---

## 本项目是否适合你

NeoBox 是一只 3D 打印的闪光灯光源箱，放在相机下方，用来对 35 mm 和最大 6×9 的 120 底片做[相机翻拍](glossary.zh-CN.md#相机翻拍)（camera scanning，也叫 DSLR scanning），配上可选件还能拍装框的 135 幻灯片和 4×5 页片。组装好的整摞占地 124.8 × 154.8 mm、高 87 mm，放在桌面上用，不占地方。

一只裸机顶闪光灯平躺在桌面上，灯头怼着主箱**完全敞开的前口**，向腔内水平打光。没有任何光直接对着胶片。光要先在白色[混光腔](glossary.zh-CN.md#混光腔)（integrating cavity）里经过若干次漫反射，再向上穿过 62 × 95 mm 的透光窗和胶片正下方那块[乳白](glossary.zh-CN.md#乳白)亚克力[扩散板](glossary.zh-CN.md#扩散板)。前口是敞开的，环境光进得来：在昏暗的房间里拍，别让顶灯直射箱口。闪光的量远大于房间里那点光。

整套东西比听上去要少：

- **12 个打印件**（白色 3 件、黑色 9 件；6×6 遮幅插片、幻灯片板和两个 4×5 件可选），十二个 STL 全部免支撑，都是平面朝下打印。
- **1 块乳白亚克力扩散板**，68 × 118 × 2 mm，嵌进顶盖台的暗槽里。
- **32 颗磁铁加 4 片钢垫片**：Ø8 × 2 mm 的 N35 圆片过盈压进夹件，10 × 10 × 1 mm 的钢垫片沉在顶盖台里与台面齐平。
- **无螺丝、无螺纹、无粘接、无工具。** 整箱靠重力和磁吸组装；调平在相机端做，不在箱子上做。

> [!IMPORTANT]
> 这是第一个正式发布版。几何尺寸已在 Blender 源文件中逐项核对，十二个 STL 全部是水密单实体，每一个水平面都落在 0.2 mm 网格上。但这套几何的箱子**从未被打印、拍摄、实测或做过均匀性测试**。你要是动手做了，你就是第一个。

**适合动手的人**：已经在拍胶片，手里有一台能架起来的相机；想要在[基准 ISO](glossary.zh-CN.md#基准-iso)、f/8 下拍摄，并且完全不用担心震动；不介意打印这些件、压几颗磁铁。要拧、要焊、要粘的东西，一样都没有。

**先别开始**：如果你既没有 3D 打印机，也找不到代打服务。所有受力件都是打印出来的，已发布的文件里没有第二条路。4×5 可以装在同一只箱子上拍，但均匀性有待验证，见[常见问题](#常见问题)。

> [!WARNING]
> **打印床尺寸先行确认。** 最大的两个件 `main-body.stl` 和 `cover-stage.stl` 占地同为 124.8 × 154.8 mm，一张 160 × 160 mm 的[打印床](glossary.zh-CN.md#打印床尺寸)就能打完整套，当下的桌面机基本都够。全部免支撑；唯一的方向规则是两个夹上盖顶面朝下打，其余全部平底朝下。如果你连 160 × 160 mm 的床都够不到，先把外发这条路落实，再花别的钱。

花钱之前先把三件事定下来：

- [ ] 你能不能打印、或者找到人打印占地 124.8 × 154.8 mm 的件？说白了，就是够不够得到一张 160 × 160 mm 的打印床。
- [ ] 你有没有、或者会不会买一只**支持手动出力**的热靴闪光灯？品牌不限，它待在箱子外面。
- [ ] 你有没有一支具备微距能力的镜头，以及能把相机端正地架在箱子正上方的东西？

三个都是「有」，就继续看[物料清单](bom.zh-CN.md#工具与耗材)。第一个是「没有」，到此为止。

一页纸制造总览：十二个打印文件的尺寸与打印要点、需要采购的零件，以及装配后箱体的剖面

## 什么是相机翻拍

相机翻拍就是用数码相机去拍一张背光的底片，而不是把它送进扫描仪。胶片架在一块均匀发光的表面之上，相机垂直向下拍，事后再把 [raw](glossary.zh-CN.md#raw) 文件[反相](glossary.zh-CN.md#反相)（inversion）。

跟平板扫描仪比，这笔买卖是拿前期调校换后期速度：把整套装置对齐要花一个晚上，但之后每一格就是按一次快门。跟送店冲扫比，底片始终在你自己手上，整个色彩判断也都归你。

NeoBox 只是这件事里「光源」的那一半。它取代的是看片灯板（light pad），至于你用什么相机，它一句都没管。而相机那一半是实打实的工作量，写在[翻拍](scanning.zh-CN.md#相机端器材)里。

## 你需要自备的器材

下面这些都不是打印件。闪光灯和引闪器以参考型号的身份列在[物料清单](bom.zh-CN.md#工具与耗材)里；其余的你必须已经有，本项目也一概不为它们计价。

| 你需要 | 为什么 | 价格 |
|---|---|---|
| 一台能手动曝光、能出 raw 的相机 | 曝光是手动定死的，一卷之内不再改动 | 此处不计价 |
| 一支具备微距能力的镜头 | 用全画幅拍满一格 135，需要 1:1 的[放大倍率](glossary.zh-CN.md#放大倍率)（magnification）；任何一支 1:1 微距镜都能覆盖本箱支持的全部画幅，画幅越大，用到的放大倍率越低 | 此处不计价 |
| 一台[翻拍台](glossary.zh-CN.md#翻拍台)（copy stand），或者带横臂、可倒置中轴的三脚架 | 胶片平面位于箱子落地面以上 83.2 mm；相机必须悬在它正上方并与之平行 | 此处不计价 |
| 一只支持手动出力的热靴闪光灯 | 就是光源本身。它平躺在桌面上、灯头怼着敞开前口，从不进箱；品牌不限，NEEWER TT560 只是参考型号 | 见物料清单 |
| 一套无线引闪器 | 发射端装在相机热靴上；接收端跟闪光灯一起留在箱外，信号不被箱体挡，换电池也不用碰箱子。参考型号：ZENIKO T1 | 见物料清单 |
| 一根快门线或遥控器 | 拍摄间隙手不碰相机 | 此处不计价 |
| 反相软件 | 把 raw 原片变成正像 | 此处不计价 |
| 一只气吹加一小块平面镜 | 气吹保证胶片（以及可选的玻璃）不落灰；平面镜是调平工具本身：让镜头自己的倒影在镜中居中 | 列在[物料清单](bom.zh-CN.md#工具与耗材)里 |

> [!NOTE]
> 相机那一侧是有意不计价的。一支微距镜和一套支架，本来就有就是零成本，也可能比这个项目其余部分加起来还贵，随便报一个数字就是在编。真正要紧的是：在下单买件之前，这些东西你得已经有了。

判断一只闪光灯合不合用，只看一点：**能不能手动调出力**。它的尺寸无所谓，灯头也不需要能转，因为它只是平躺在箱口而已。[TTL](glossary.zh-CN.md#ttl) 和[高速同步（HSS）](glossary.zh-CN.md#hss)在这里毫无用处，别为它们花钱。

## 费用与时间

价格都集中写在[物料清单](bom.zh-CN.md#工具与耗材)里，这一页只把开销分好堆：

| 你买的是什么 | 费用 |
|---|---|
| 全部结构件和箱内之物：十二个 PLA 打印件、乳白亚克力、32 颗磁铁、4 片钢垫片 | 在物料清单中计价 |
| 机顶闪光灯（任何支持手动出力的热靴型号） | 参考型号在物料清单中计价 |
| 一套无线引闪器 | 参考型号在物料清单中计价 |
| 可选升级：防牛顿环玻璃、植绒贴 | 在物料清单中计价 |
| 相机、镜头、支架、快门线、软件 | 此处不计价 |

打印是件小活：没有任何件长过 154.8 mm，普通 PLA 就够，全部免支撑：层高 0.2 mm，填充 15%。

| 阶段 | 通常耗时 | 说明 |
|---|---|---|
| 3D 打印（自己打或找代打） | 数日 | 几乎总是关键路径；两种颜色，没有支撑要拆 |
| 乳白亚克力定制切割 | 数日 | 定制裁 68 × 118 × 2 mm；原型机时期的 110 × 130 mm 板可以让店家裁小续用 |
| 磁铁与钢垫片 | 通常最快到 | 全是现货规格，没有定制件 |
| 装配 | 几分钟 | 不用任何工具；压 32 颗磁铁占了大半工作量 |
| 第一次调校 | 一个晚上 | 先用镜子做相机端平行度，再查均匀性 |

> [!TIP]
> 这三笔单子的交期差别很大，所以要同一天一起下，而不是办完一笔再办下一笔。关键路径几乎总是打印。

## 整体流程

```mermaid
flowchart TD
    A["决策：这东西你打得出来吗"] --> B["采购零件、亚克力与磁铁"]
    B --> C["自己打印或外发这 12 个文件"]
    C --> D["开工前逐件检查"]
    D --> E["装配：压磁铁、放亚克力、堆叠成箱"]
    E --> F["用镜面对齐法调平相机"]
    F --> G["校准：平场校正"]
    G --> H["翻拍第一卷片子"]
```

| 步骤 | 实际在做什么 | 写在哪一篇 |
|---|---|---|
| 决策 | 打印床尺寸（160 × 160 mm 就够）、闪光灯在不在手、你已经有什么 | 本页 |
| 采购 | 零件与耗材；淘宝话术；到货验收 | [物料清单](bom.zh-CN.md#工具与耗材) |
| 打印 | 十二个 STL，普通 PLA：[层高](glossary.zh-CN.md#层高) 0.2 mm、填充 15%、无支撑 | [3D 打印](printing.zh-CN.md#找代打服务下单) |
| 逐件检查 | 开工前先量；现在发现件不对只是重打一件，装到一半才发现就是整台返工 | [3D 打印](printing.zh-CN.md#装配前逐件检查) |
| 装配 | 把 32 颗磁铁压进夹件，亚克力和钢垫片放进顶盖台，整箱堆叠起来，全程不用工具 | [装配](assembly.zh-CN.md#装配步骤) |
| 对齐 | 一小块平面镜放在胶片平面上，挪相机直到镜头自己的倒影居中；调的是相机，不是箱子 | [装配](assembly.zh-CN.md#第-7-步相机端调平镜子法) |
| 校准 | 拍一张不放胶片的发光面，先做[平场校正](glossary.zh-CN.md#平场校正)（flat-field correction），再谈均匀性 | [翻拍](scanning.zh-CN.md#平场校正与反相) |
| 第一卷 | 相机高度、对焦、闪光出力、装片、拍摄、反相 | [翻拍](scanning.zh-CN.md#装片) |
| 出问题了 | 症状 → 可能原因 → 处理，覆盖每一个阶段 | [排错](troubleshooting.zh-CN.md#打印) |

## 需要的技能

没什么冷门的。会照着切片软件的默认配置走、碰胶片时手是干净的，这东西你就做得出来。整个制作过程里没有螺丝刀、扳手、烙铁和胶水，也完全不需要动 CAD。设计不绑定任何一款闪光灯。

有两步特别容易翻车，都值得在真正做到之前先读两遍：

**磁铁极性。** 32 颗 Ø8 × 2 mm 磁铁要过盈压进夹件，每件 8 颗。每一颗都必须与对面件里的那颗相吸，而过盈配合压进去就没打算再取出来。所以每颗下压之前，先跟已经装好的对面磁铁比一下极性。

**平行度。** 胶片平面必须与传感器平行，而不只是水平。这套设计里，箱子上没有任何可调的东西。把一小块平面镜放在放胶片的位置，挪动相机，直到镜头自己的倒影正好落在画面正中。倒影一居中，传感器就与片平面平行了，下面所有打印件的公差也在同一步里被吸收掉。先平行度，后均匀性。

<details>
<summary>为什么整个设计围绕闪光灯，而不是常亮 LED 面板</summary>

闪光脉冲本身**就是**曝光。在昏暗的房间里，经混光腔打出来的闪光量远大于从敞开前口漏进来的环境光，而脉冲的持续时间只是任何真实快门时间的一个零头，机械震动、快门震动和地板传来的晃动就此不再重要。

好处还不止防震这一条。每一格得到的输出完全一致，一卷片子共用一条反相曲线。基准 ISO、f/8 就是这套设计的工作点，而氙气灯管给出的又是真正连续的日光平衡光谱。

</details>

## 常见问题

**有人真做出来过吗？** 没有。v1 的几何在 CAD 里逐项核对过尺寸，导出的文件也做过数值校验，但这套几何从来没有被打印、拍摄、实测或做过均匀性测试；打印过的只有旧原型机，它和 v1 几乎没有共同零件。所有关于光学的说法都请当成推演结果，而不是实测结果。

**能不能用 LED 面板代替闪光灯？** 用已发布的这套文件不行：没有发布 LED 版本，不采用的理由在上面那个折叠块里。物料清单里的可选 LED 灯带只是定位灯，从来不参与曝光。

**我的闪光灯装得进去吗？** 装得下，因为根本不用装进去。闪光灯平躺在桌面上、灯头怼着完全敞开的前口，它的任何尺寸都无关紧要。任何支持手动出力的热靴闪光灯都能用；NEEWER TT560 只是光路设计时参照的型号。

**磁铁一定要装吗？** 要，32 颗全装，4 片钢垫片也要。每个夹上盖里的 8 颗与夹底座里的 8 颗相吸，把夹子扣紧；底座磁铁同时吸住顶盖台里与台面齐平的钢垫片，夹子因此固定在台上，5 秒换画幅靠的也是它。不装的话，一切都只是靠自重搁着。

**220 × 220 mm 的打印床能打吗？** 能，整套都能，还很宽裕。没有任何件的占地超过 124.8 × 154.8 mm，所以 160 × 160 mm 的床就够，而且没有件需要支撑。

**防牛顿环玻璃是必需的吗？** 不是。默认压平元件是每个画幅一片的打印压片窗插片：窗口四边是硬限位，胶片最多拱起 0.28 mm，完全落在 1:1、f/8 下约 ±0.4 mm 的景深之内。防牛顿环玻璃（64 × 95 × 2 mm，一片两个画幅通用）是升级件，把整个画面连续封平；磨砂面贴着片基亮面，不起[牛顿环](glossary.zh-CN.md#牛顿环)，药膜面朝着下方的开窗，什么都不碰。

> [!CAUTION]
> 玻璃模式下，玻璃底面离焦平面只有 0.2 mm，落在那里的灰尘会直接进画面。元件装进去一次就不再动，所以装之前先用气吹吹干净。相比之下，乳白亚克力上的灰尘永远不会成像：它就落在发光面本身上，偶尔擦一擦就够了。

**支持 4×5 吗？** 支持，靠两个可选件、一块更大的亚克力，外加一条但书。`cover-stage-4x5.stl` 在同一只主箱上代替顶盖台，透光窗 102 × 126 mm，暗槽放一块 106 × 130 × 2 mm 的乳白板；`sheet-plate-4x5.stl` 立在它的托盘里，用 102.2 × 127.6 mm 的片槽接住页片，槽下开 97 × 121 mm 的窗。没有上盖、没有玻璃：4×5 的放大倍率下，景深足以盖过任何卷曲。但书是均匀性：窗口离混光腔壁只有 9 和 12 mm，而 v1 是 29 和 27.5，而且没有测过任何东西，所以先拍一张空白片。见[设计 §10](design.zh-CN.md#10-45-装在-v1-主箱上)和[4×5 页片](scanning.zh-CN.md#45-页片)。

**支持装框的幻灯片吗？** 支持，用可选的幻灯片板。135 的通道高 0.4 mm，是按裸片条的尺寸做的，带框的幻灯片永远进不了胶片夹；改由 `slide-plate-135.stl` 代替胶片夹立在托盘里，它上面一个 51.4 mm 见方的方槽，纸框、塑料框、玻璃框都放得进，槽下是一个 26 × 38 mm 的开窗。没有上盖、没有磁铁：方槽定位，重力压住。见[装框幻灯片](scanning.zh-CN.md#装框幻灯片)。没装框的反转片和普通片条一样走 135 胶片夹。

**怎么过片、怎么换画幅？** 过片靠抽：捏住伸出夹外的片头直接拉。胶片滑过压平元件下方时，拱起的部位会被顺势压平，一卷拍完之前夹子不用打开。换画幅就是掀掉一副夹子、放上另一副，磁吸自动定位，5 秒钟的事。拍 6×6 时把遮幅插片垫在 120 底座下面，夹子整体会抬高 1 mm，属正常现象；6×4.5 没有专用遮幅，后期裁切。长片条的尾巴会搭在托盘凸缘上，比片平面略低，远端用手托一下。装片和取放写在[翻拍](scanning.zh-CN.md#装片)里。

## 到哪里查资料

这个项目同时用到三个行当的词汇（胶片摄影、光学和 FDM 打印），而且经常一句话里混着用。每个词都在[术语表](glossary.zh-CN.md#相机翻拍)里用一行给出定义，只定义一次。

碰到读不下去的词就先去那里查：[混光腔](glossary.zh-CN.md#混光腔)、[平场校正](glossary.zh-CN.md#平场校正)、[同步速度](glossary.zh-CN.md#同步速度)（sync speed）、[闪光指数](glossary.zh-CN.md#闪光指数)、[支撑](glossary.zh-CN.md#支撑)（supports）、[层高](glossary.zh-CN.md#层高)、[工作距离](glossary.zh-CN.md#工作距离)（working distance）、[牛顿环](glossary.zh-CN.md#牛顿环)（Newton rings）、[基准 ISO](glossary.zh-CN.md#基准-iso)、[EV](glossary.zh-CN.md#ev)。

想知道的是某个尺寸背后的道理而不是尺寸本身，工程内容在[设计](design.zh-CN.md#3-光学决策)文档里；设计日志则记录了试过什么、又为什么放弃。

---

← [README](../README.zh-CN.md) · [文档索引](../README.zh-CN.md#文档) · [物料清单](bom.zh-CN.md) →

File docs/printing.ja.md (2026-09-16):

# 3D プリント

[English](printing.md) · [简体中文](printing.zh-CN.md) · **日本語**

> NeoBox の 12 点のパーツをどう出力するか。なぜほぼどのプリンタでも出せるのか、ビルド全体で共通の設定 1 組、ファイルごとのカード、そして組み立てに入る前に走らせる確認項目をまとめます。

**目次：** [お使いのプリンタで出力できるか](#お使いのプリンタで出力できるか) · [プリント設定](#プリント設定) · [フィラメント](#フィラメント) · [12 点のパーツ](#12-点のパーツ) · [まず 135 ホルダーを 1 組だけ出力する](#まず-135-ホルダーを-1-組だけ出力する) · [組み立てる前に各パーツを確認する](#組み立てる前に各パーツを確認する) · [きつい場合と緩い場合の対処](#きつい場合と緩い場合の対処) · [出力サービスへの発注](#出力サービスへの発注)

STL は 12 ファイルで、**標準ビルドの 8 点＋オプション 4 点（6×6 マスク、マウント済みスライド用のスライドプレート、そして 4×5 の天板ステージとシートプレート）**です。うち白が 3 点、黒が 9 点。すべて 1:1 のミリメートル・モデルで、すべてサポートなしで出力でき、フィラメントは標準ビルドでおよそ **300–350 g、プロトタイプのほぼ 3 分の 1** です。

製造の一覧図：プリントパーツ、購入部品、各パーツの出力上の注意

> [!CAUTION]
> スライサーにこれらのファイルをスケーリングさせないでください。「ビルドプレートに合わせて縮小」は出力の発注が失敗する最も多いパターンです。ファイルは最初から 1:1 であり、下の受け入れ検査はすべてそれが保たれている前提で書かれています。

> [!NOTE]
> この設計はまだ出力されていません。このページの記述はいずれも実機から得たものではありません。形状は CAD で検証済みです（権威は `cad/neobox.blend`）。

---

## お使いのプリンタで出力できるか

ほぼ間違いなく出力できます。ビルド最大のパーツである本体と天板ステージは、プレート上で 124.8 × 154.8 mm、最も高いのは 75.6 mm の本体です。**160 × 160 mm のビルドプレートがあればセット全体を出力できます**。つまり現行の小型機まで含めて、ほとんどすべてのデスクトップ機で足ります。プロトタイプ時代の大型パーツと筐体外注に関する警告は、プロトタイプとともに廃止されました。

| パーツ | ビルドプレート上の設置面 | 高さ |
|---|---|---|
| `main-body.stl` | 124.8 × 154.8 | 75.6 |
| `cover-stage.stl` | 124.8 × 154.8 | 10.0 |
| `film-holder-*-base.stl`（2 点） | 94 × 120 | 5.0 |
| `film-holder-*-lid.stl`（2 点） | 94 × 120 | 3.0 |
| `pressure-window-*.stl`（2 点） | 64 × 95 | 2.0 |
| `mask-6x6.stl` | 94 × 80 | 1.0 |
| `slide-plate-135.stl` | 94 × 120 | 5.0 |
| `cover-stage-4x5.stl` | 124.8 × 154.8 | 10.0 |
| `sheet-plate-4x5.stl` | 112 × 138 | 5.0 |

---

## プリント設定

ビルド全体でこの設定 1 組です。このリポジトリの他の場所に出てくるプリント設定の記述は、すべてここを参照しています。

| 設定項目 | 値 | なぜその値か |
|---|---|---|
| スケール | 100 %、ミリメートル | ファイルはすでに 1:1 です。 |
| フィラメント | 通常の PLA（筐体 2 点は白、残りは黒） | [フィラメント](#フィラメント)を参照。 |
| [積層ピッチ](glossary.ja.md#積層ピッチ-layer-height)（layer height） | **全パーツ 0.2 mm** | 設計上の高さはすべて 0.2 mm グリッドに載っており、0.2 で出力すればどの面も層境界にちょうど乗ります。0.4 の段差は本物の 0.4 になります。 |
| [インフィル](glossary.ja.md#インフィル-infill)（infill） | 15 % | 自重以上の荷重を受けるパーツはありません。 |
| [サポート](glossary.ja.md#サポート-supports)（supports） | **どのパーツにも不要** | 全パーツが各カードの姿勢でサポートなしに出るよう設計されています。 |

> [!IMPORTANT]
> スライサーがどこかにサポートを提案してきたら、パーツの姿勢が間違っています。そのパーツのカードに戻ってください。[ブリッジ](glossary.ja.md#ブリッジ-bridging)（bridging）の調整も不要です。ビルド全体で最長のブリッジは、天板ステージ裏面のダボ穴の天井の 3.3 mm で、デフォルト設定で何事もなく渡れます。

<details>
<summary>なぜ形状を 0.2 mm に量子化しているのか、それで何が得られるのか</summary>

このプロジェクトの全パーツの背後にある製造ルールは、**各パーツの出力姿勢において、すべての水平面が 0.2 mm グリッドに乗り、露出する段差は 0.4 mm を下回らない**というものです。どちらの規則も、実際の出力発注の失敗から練り上げられたもので（[設計ログ 18 番](design-log.ja.md#18-ホルダーを積層ピッチに量子化)、姿勢については 20 番）、出力ショップがデフォルトプロファイルのまま流しても使えるパーツが出る理由でもあります。

| パーツ | ビルドプレートから測った水平面の高さ（mm） |
|---|---|
| `main-body.stl` | 0 · 3.0 · 73.0 · 75.6 |
| `cover-stage.stl` | 0 · 2.8 · 3.6 · 5.0 · 6.0 · 10.0 |
| ホルダー底（2 点） | 0 · 2.2 · 3.8 · 4.2 · 4.6 · 5.0 |
| ホルダー蓋（2 点、天面を下にして出力） | 0 · 1.0 · 3.0 |

どの数値も 0.2 の整数倍です。そしてビルド中で最も細かい露出段差、すなわちホルダー底の 0.4 mm の受けとエレメント段こそが、フィルム面を定義する 2 段です。だから仕様は全ファイルの積層ピッチを 0.2 mm に固定しています：どの面も層境界にちょうど乗り、0.4 の段差はきれいな 2 層になり、スライサーの丸めに委ねるものがなくなります。0.28 のような粗いピッチはわずかに安くはなりますが、グリッドが層境界の間に落ち、ぼやけるのはフィルム面を支えるまさにその段差です。

</details>

**ノズル。** ビルド最小の形状はホルダー底の 0.4 mm の段差で、最も薄い壁は 2.4 mm です。標準の 0.4 mm ノズルですべてのパーツを出力できます。

---

## フィラメント

### 通常の PLA を 2 色

仕様はセット全体で通常の PLA です。エンジニアリング系フィラメントも、特殊な表面仕上げの材料も要りません。

**筐体 3 点、本体とどちらの天板ステージも白。** 本体の内側そのものが反射面です。ストロボは完全に開いた前面（オープンフロント）から腔内に発光し、白い壁と天板ステージの白い裏面の間で何度も反射してからフィルムに届きます。白い生地の面が光学面**そのもの**です。

> [!IMPORTANT]
> 白は通常の白 PLA を使い、シルク・サテンなどの特殊仕上げは避けてください。内側の面には手を入れないこと。塗装・研磨・コーティングはいずれも不可です。白壁の生地のままの反射率は光学設計の一部です。

**フィルムの近くにある 9 点は黒。** フィルムが至近距離で「見る」もの（ホルダー底とホルダー蓋、押さえ窓インサート、マスク、スライドプレート、シートプレート）はすべて黒で、迷光を吸収します。

**数量。** 標準ビルドでおよそ **300–350 g**、プロトタイプのほぼ 3 分の 1 です。オプションのスライドプレートは約 25 g、4×5 の 2 点は約 35 g 加わります。各色 1 巻きで何度でも作れる量です。

---

## 12 点のパーツ

プリントパーツをビルドプレートに置いた側面図

### パーツ各部の呼び方

ここでの出力指示は、必ず実物で見える特徴の名前を使い、見えない面は指しません。語の意味は次のとおりです。

| ここで使う語 | 実物のどこを見ているか |
|---|---|
| レール | ホルダー底の、フィルムの走る方向に通る 2 本の長い外側リブの一方 |
| 受け | レールの内側に沿う細い凸の棚。フィルムの両縁がここに載る |
| エレメント段 | レールに切られた 4.6 mm の段。押さえエレメントがここに載る |
| 溝 | 受けと押さえエレメントの間の 0.4 mm の隙間。フィルムはここを引き抜く |
| 窓 | 撮影のために開いた長方形の穴 |
| 押さえエレメント | エレメント段に載るもの。既定はプリントした押さえ窓インサート、アップグレードはオプションのアンチニュートンガラス |
| 位置決めダボ | 本体の側壁の上面にある 4 個の小さな凸の一つ |
| ダボ穴 | 天板ステージ裏面の四隅にある 4 個の受け口の一つ。位置決めダボがここに嵌まる |
| トレイフランジ | 天板ステージの上面に立ち上がる枠。フィルムホルダーはこの枠の中に座る |
| ポケット | スライドプレートの上面にある 51.4 mm 角のくぼみ。マウント済みスライドをここに落とし込む |
| 指掛け溝 | ポケットの両側にある小さな貫通しないくぼみの一つ。マウントを取り出すときに指を掛ける |
| 縁の切欠き | シートプレートの短辺にある 2 つの開いた切り込みの一つ。シートを取り出すときに指を掛ける |

> [!CAUTION]
> 姿勢の罠は 2 つ、パーツ族ごとに 1 つずつです。**ホルダー底**は平らな面を下にして出力します。レールのある面をビルドプレートに向けてはいけません。受けとエレメント段が宙に浮き、溝は出ません。**ホルダー蓋**は逆で、平らな**天面**を下にし、浅い凹みとマグネット穴が上を向くようにします。姿勢を誤ったホルダーはすでに一度ショップに届いています（[設計ログ 20 番](design-log.ja.md)）。下の各カードが見える特徴で置き方を指定しているのは、そのためです。

### [main-body.stl](../stl/white-pla/main-body.stl)

- **白。** 124.8 × 154.8 × 75.6。セット最大で、出力時間も最長のパーツです。
- **プレート上の姿勢：** 平らな底面を下に。3 面の壁が底から立ち上がり、4 面目の完全に開いた前面には壁がそもそもありません。これは設計であって、壊れたファイルではありません。4 個の位置決めダボは側壁の上面に載っています。
- **サポート：不要。** オープンフロントは「無い」だけでオーバーハングではなく、このパーツに宙に浮く形状はありません。
- **注意：** 内側の面は光学面です。研磨も塗装も不可。

### [cover-stage.stl](../stl/white-pla/cover-stage.stl)

- **白。** 124.8 × 154.8 × 10.0。この 1 点がプロトタイプの天板とフィルムステージを統合したパーツです。
- **プレート上の姿勢：** 四隅にダボ穴のある平らな面を下に。立ち上がるトレイフランジが上を向きます。
- **サポート：不要。** ダボ穴の天井が 3.3 mm のブリッジになります。これがビルド最長のブリッジで、それでも取るに足りません。
- **このパーツのその他：** 62 × 95 の透光窓、上面のすぐ下にある乳白アクリルの受け座、鋼シムを入れる小さな角形の座ぐり 4 個、フィルムホルダーを位置決めするトレイフランジ。

### [film-holder-135-base.stl](../stl/black-pla/film-holder-135-base.stl)

- **黒。** 94 × 120 × 5.0。窓 25 × 37。
- **プレート上の姿勢：** 平らな面を下、2 本の長いレールを上に。溝の両端には短いガイドリブがあり、フィルムを導き入れます。
- **サポート：不要。** マグネットポケットも段差もすべて上向きに開きます。
- **注意：** このパーツの受けとエレメント段がフィルム面を定義します。0.2 mm 積層を使うなら、効くのはここです。

### [film-holder-135-lid.stl](../stl/black-pla/film-holder-135-lid.stl)

- **黒。** 94 × 120 × 3.0。窓 25 × 37。
- **プレート上の姿勢：天面を下に。** 窓のほかに何もない平らな面をプレートに当て、浅い長方形の凹みと 8 個のマグネット穴のある面を上に向けます。
- **サポート：不要。** この姿勢では凹みもポケットもすべて上向きに開きます。

### [film-holder-120-base.stl](../stl/black-pla/film-holder-120-base.stl)

- **黒。** 94 × 120 × 5.0。窓 57 × 85（6×9 のフルフレーム）で、溝の幅は 62 mm。
- **プレート上の姿勢：** 平らな面を下、2 本の長いレールを上に。
- **サポート：不要。**
- **注意：** 135 の底と同じで、受けとエレメント段がフィルム面です。

### [film-holder-120-lid.stl](../stl/black-pla/film-holder-120-lid.stl)

- **黒。** 94 × 120 × 3.0。窓 57 × 85。
- **プレート上の姿勢：天面を下に**。135 の蓋とまったく同じで、凹みとマグネット穴が上です。
- **サポート：不要。**

### [pressure-window-135.stl](../stl/black-pla/pressure-window-135.stl)

- **黒。** 64 × 95 × 2.0、窓 25 × 37。135 の既定の押さえエレメントで、135 の底のエレメント段に載ります。
- **プレート上の姿勢：** 平置き、平らな底面を下に。
- **サポート：不要。**

### [pressure-window-120.stl](../stl/black-pla/pressure-window-120.stl)

- **黒。** 64 × 95 × 2.0、窓 57 × 85。120 の既定の押さえエレメントです。
- **プレート上の姿勢：** 平置き、平らな底面を下に。
- **サポート：不要。**
- **補足：** フォーマット別に分かれる押さえエレメントはこの 2 点のインサートだけです。オプションのアンチニュートンガラスは 64 × 95 の 1 枚で両フォーマットに共用できます。

### [mask-6x6.stl](../stl/black-pla/mask-6x6.stl)——オプション

- **黒。** 94 × 80 × 1.0、窓 56.5 × 56.5。
- **プレート上の姿勢：** 平置き。
- **サポート：不要。**
- **出力するのは** 6×6 を撮る場合だけです。120 の底の下、トレーの中に敷いて窓を正方形に絞ります。6×4.5 のマスクはありません。6×4.5 は後処理でトリミングします。

### [slide-plate-135.stl](../stl/black-pla/slide-plate-135.stl)——オプション

- **黒。** 94 × 120 × 5.0。51.4 × 51.4・深さ 2.0 の角ポケット、ポケットの底を貫通する窓 26 × 38、指掛け溝 2 つ。
- **プレート上の姿勢：** 平らな面を下に。ポケットと指掛け溝が上を向きます。
- **サポート：不要。** くぼみはすべて上に開き、窓は貫通穴です。
- **出力するのは** マウント済みの 135 スライドを持っている場合だけです。135 のホルダー 1 組の代わりにトレイに立ち、マウントをポケットに落とし込みます。蓋もマグネットも押さえエレメントもありません。

### [cover-stage-4x5.stl](../stl/white-pla/cover-stage-4x5.stl)——オプション

- **白。** 124.8 × 154.8 × 10.0。天板ステージと同じ外形に、102 × 126 の採光窓、106 × 130 × 2 の乳白板を収める溝、112.6 × 138.6 のトレイ。ワッシャーポケットはありません。
- **プレート上の姿勢：** 天板ステージとまったく同じ。四隅にダボ穴のある平らな面を下に、立ち上がったトレイフランジを上に。
- **サポート：不要。** ダボ穴の天井は天板ステージと同じです。
- **出力するのは** 4×5 を撮る場合だけです。同じ本体の上で天板ステージの代わりに載ります。裏面はチャンバーに面する光学面なので、研磨も塗装も不可です。

### [sheet-plate-4x5.stl](../stl/black-pla/sheet-plate-4x5.stl)——オプション

- **黒。** 112 × 138 × 5.0。102.2 × 127.6・深さ 2.0 のポケット、ポケットの底を貫通する窓 97 × 121、短辺に縁の切欠き 2 つ。
- **プレート上の姿勢：** 平らな面を下に。ポケットと切欠きが上を向きます。
- **サポート：不要。**
- **出力するのは** 4×5 を撮る場合だけです。4×5 天板ステージのトレイに立ち、シートをポケットに落とし込みます。蓋もマグネットも押さえエレメントもありません。

---

## まず 135 ホルダーを 1 組だけ出力する

残りのファイルに踏み切る前に、`film-holder-135-base.stl`・`film-holder-135-lid.stl`・`pressure-window-135.stl` を出力してください。セット中でも小さい部類の 3 点でありながら、この 3 点で重要な嵌合をひととおり試せます。マグネットポケット、エレメント段、0.4 mm の溝です。

この最初の 1 組で確認するのは 4 点です。

- **段。** 押さえ窓インサートが 4.6 mm のエレメント段に落ちて平らに座り、蓋がその上に閉じること。わずかな遊びは設計どおりです。蓋の凹みがエレメントの浮きを 0.4 mm 以内に制限します。
- **溝。** インサートを載せ蓋を閉じた状態で、フィルムストリップが引っかかりも擦れもなく引き抜けること。
- **マグネット。** Ø8 × 2 のマグネットが各ポケットに押し込めること。これは設計上の締まり嵌めです。押し込むと簡単には戻せないので、底側と蓋側のマグネットがどの向きで吸い合うかを、押し込む**前に**突き合わせて確かめておくこと。
- **平面度。** 底がガタつかずに座ること。フィルム面はこの上に載ります。

どれかが外れていたら、ここで直してください（[きつい場合と緩い場合の対処](#きつい場合と緩い場合の対処)を参照）。そのうえで残りの黒パーツ、最後に白 2 点の順で出力します。

---

## 組み立てる前に各パーツを確認する

機械から降ろしたとき、あるいは出力サービスの箱から出したときに、以下の項目を確認してください。最初の 3 項目はスライサーがファイルをスケーリングした事故を捕まえます。

- [ ] `main-body.stl` の外形が 124.8 × 154.8 あること。
- [ ] `cover-stage.stl` が 124.8 × 154.8 で、4 個のダボ穴が自重で本体の 4 個の位置決めダボに落ち着くこと。
- [ ] フィルムホルダーの各パーツの外形が底・蓋とも 94 × 120 であること。
- [ ] 押さえ窓インサートが 64 × 95 で、対応する底のエレメント段に落ちること。
- [ ] Ø8 × 2 のマグネットが、底と蓋のすべてのポケットに押し込めること。
- [ ] インサートを入れ蓋を閉じた状態で、出力した各ホルダーをフィルムストリップが通り抜けること。
- [ ] 出力した場合：`mask-6x6.stl` が 94 × 80 で、120 の底の下のトレーに収まること。
- [ ] 出力した場合：`slide-plate-135.stl` が 94 × 120 で、トレーに収まり、マウント済みスライドがポケットに落ちて指掛け溝から取り出せること。
- [ ] 出力した場合：`cover-stage-4x5.stl` が天板ステージと同じように 4 つのダボに落ち着き、`sheet-plate-4x5.stl` が 112 × 138 でそのトレイに収まること。
- [ ] 本体の内側に研磨・磨き・塗装をしていないこと。生地のままの白い面が反射面です。

外れた項目には下に対処があります。あるいは[トラブルシューティング](troubleshooting.ja.md#プリント)を参照してください。

---

## きつい場合と緩い場合の対処

嵌合をきつい順に並べます。XY 方向の補正は PrusaSlicer と OrcaSlicer では *XY size compensation*、Cura では *Horizontal expansion* という名前です。小刻みに変えて、一度に出し直すのは 1 パーツだけ。セット全体を刷り直さないこと。

| 嵌合部 | 公称 | きつすぎる場合 | 緩すぎる場合 |
|---|---|---|---|
| 溝 | 受けと押さえエレメントの間 0.4 mm | まずエレメントがエレメント段に完全に座っているか確認し、受けの縁とエレメントの縁のバリをホビーナイフで取る。それでもフィルムが引っかかるなら、XY 補正に手を出す前に、底を 0.2 mm 積層で出し直す（受けと段が層境界にちょうど乗ります）。 | わずかなガタは正常です。0.4 mm の溝に対しフィルムの厚みは約 0.12–0.18 mm しかなく、引き抜くときに溝がフィルムを平らに押さえて通します。 |
| 押さえエレメントとエレメント段 | 段の上に 64 × 95 | 細かいサンドペーパーで**エレメント側**の縁を軽く整える。削るのはエレメントだけで、段は絶対に削らない。 | 問題ありません。蓋の凹みがエレメントの浮きを 0.4 mm 以内に制限します。 |
| 天板ステージのダボ穴と位置決めダボ | ダボ 4 個、2.4 × 12 | ダボ穴の口をナイフで軽くさらう。足りなければ[エレファントフット](glossary.ja.md#エレファントフット-elephant-foot)（elephant foot）補正を有効にして出し直す。 | 無害です。ダボ穴は位置決めであり、保持しているのは重力です。 |
| マグネットポケット | Ø8 × 2 のマグネット | 締まり嵌めは設計どおりです。真っ直ぐ、しっかり押し込む。どうしても入らないときだけポケットの口をナイフでさらう。ネオジムマグネットを叩き込まないこと。欠けます。 | 瞬間接着剤を一滴。位置を決めるのはポケット、保持するのは接着剤です。 |

> [!CAUTION]
> きつい溝を緩めるために、受けやエレメント段を研磨・やすりがけ・「仕上げ」してはいけません。この 2 段が**フィルム面そのもの**であり、ここで取り除いた材料は取り返しのつかない平面度誤差になります。きつい溝はスライサー側（0.2 mm 積層、わずかな XY 補正）か、交換可能なエレメント側で直します。底の段には決して手を入れないこと。

---

## 出力サービスへの発注

プリンタがまったくなくても、これはもう小さな注文です。12 ファイル（うち 4 点は任意）、通常の PLA がおよそ 300–350 g、サポートは一切なし、どのパーツも 160 × 160 mm のビルドプレートに収まります。検索ワードは `3Dプリント 出力代行 PLA`。次の文面をそのまま送ってください。全ファイル名を挙げ、オペレーターの画面で見える特徴で置き方を指定してあります。

```text
STL 12 ファイル：必須 8 点＋任意 4 点（mask-6x6、slide-plate-135、cover-stage-4x5、sheet-plate-4x5）。
単位はミリ、1:1。スケール変更は不可。

通常の PLA。積層ピッチは全パーツ 0.2 mm。インフィル 15 %。サポートはどのパーツにも不要。
どのパーツも 160 x 160 mm のビルドプレートに収まります。

白 PLA - 2 点 + 任意 1 点:
  main-body.stl        124.8 x 154.8 x 75.6。
                       平らな底面をプレートに、壁を上に。1 面だけ壁があり
                       ませんが、これは設計でありデータの破損ではありません。
                       内側の面は研磨・塗装・コーティングをしないでください。
  cover-stage.stl      124.8 x 154.8 x 10。
                       四隅に受け口のある平らな面をプレートに、立ち上がる
                       長方形の枠を上に。
  cover-stage-4x5.stl（任意）  cover-stage.stl と同じ配置。

黒 PLA - 6 点 + 任意 3 点:
  film-holder-135-base.stl  平らな面をプレートに、2 本の長いリブを上に。
  film-holder-120-base.stl  同じ配置。
  film-holder-135-lid.stl   平らな天面をプレートに。浅い凹みと 8 個の
  film-holder-120-lid.stl   マグネット穴のある面を上に。
  pressure-window-135.stl   薄い平板。平置き。
  pressure-window-120.stl   薄い平板。平置き。
  mask-6x6.stl（任意）      薄い平板。平置き。
  slide-plate-135.stl（任意）  平らな面をプレートに、角ポケットを上に。
  sheet-plate-4x5.stl（任意）  平らな面をプレートに、ポケットを上に。
```

**支払う前に 3 つ質問してください。** 出力サービスは先に注文を受けてから問題に気づきます。

1. 全ファイルを 100 % スケール・ミリ単位で出力しますか。「プレートに合わせて縮小」はしませんか。
2. 白のフィラメントは、シルクでも光沢でもない通常の白 PLA ですか。
3. 2 点のホルダー蓋を、文面どおり天面を下にして配置してもらえますか。

**ショップが設定に難色を示したら、**先方のデフォルトプロファイルに任せて構いません。デフォルトで通るように形状を量子化してあります。すべての水平面が 0.2 mm グリッドに乗り、露出段差は 0.4 mm 以上です。譲れないのは「スケールしない」「姿勢は文面どおり」「サポートなし」の 3 点だけです。

この文面の各言語版（タオバオ向けの中国語、その他向けの英語）は[発注文面](bom.ja.md#発注文面)にあり、出力以外に買うものの調達先もそこにまとまっています。

---

← [部品表と調達](bom.ja.md) · [ドキュメント索引](../README.ja.md#ドキュメント) · [組み立て](assembly.ja.md) →

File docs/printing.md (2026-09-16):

# Printing

**English** · [简体中文](printing.zh-CN.md) · [日本語](printing.ja.md)

> How to print the twelve NeoBox parts: why almost any printer can, one set of settings for the whole build, a card per file, and the checks to run before you assemble anything.

**Contents:** [Will it fit your printer?](#will-it-fit-your-printer) · [Print settings](#print-settings) · [Filament](#filament) · [The twelve parts](#the-twelve-parts) · [Print one 135 holder first](#print-one-135-holder-first) · [Check each part before you assemble](#check-each-part-before-you-assemble) · [If it came out tight or loose](#if-it-came-out-tight-or-loose) · [Ordering from a print service](#ordering-from-a-print-service)

Twelve STL files: **eight for the default build plus four optional: the 6×6 mask, the slide plate for mounted slides, and the 4×5 cover-stage and sheet plate**. Three are white, nine are black. All are 1:1 in millimetres, all print without supports, and the default build weighs about **300–350 g of filament, roughly a third of what the printed prototype needed**.

One-page manufacturing overview: the printed parts, the bought parts, and the print notes for each

> [!CAUTION]
> Never let a slicer scale these files. "Scale to fit the build plate" is the single most common way a print order goes wrong. The files are already 1:1, and every acceptance check below assumes they stayed that way.

> [!NOTE]
> This design has not been printed: nothing on this page comes from a machine. The geometry is verified in CAD (`cad/neobox.blend` is the authority).

---

## Will it fit your printer?

Yes, almost certainly. The largest parts in the build, the main body and the cover-stage, are 124.8 × 154.8 mm on the plate, and the tallest is the main body at 75.6 mm. **A 160 × 160 mm bed prints everything**, which today means practically every desktop machine, including the smallest current ones. The old warnings about oversized parts and outsourcing the enclosure went away with the prototype.

| Part | Footprint on the plate | Height |
|---|---|---|
| `main-body.stl` | 124.8 × 154.8 | 75.6 |
| `cover-stage.stl` | 124.8 × 154.8 | 10.0 |
| `film-holder-*-base.stl` (both) | 94 × 120 | 5.0 |
| `film-holder-*-lid.stl` (both) | 94 × 120 | 3.0 |
| `pressure-window-*.stl` (both) | 64 × 95 | 2.0 |
| `mask-6x6.stl` | 94 × 80 | 1.0 |
| `slide-plate-135.stl` | 94 × 120 | 5.0 |
| `cover-stage-4x5.stl` | 124.8 × 154.8 | 10.0 |
| `sheet-plate-4x5.stl` | 112 × 138 | 5.0 |

---

## Print settings

One settings block for the whole build. Every other mention of a print setting in this repository refers back to here.

| Setting | Value | Why it is this value |
|---|---|---|
| Scale | 100 %, millimetres | The files are already 1:1. |
| Filament | Plain PLA: white for the two enclosure parts, black for the rest | See [Filament](#filament). |
| [Layer height](glossary.md#layer-height) | **0.2 mm on every part** | Every height in the design sits on a 0.2 mm grid, so at 0.2 every face lands exactly on a layer boundary: a printed 0.4 step is a true 0.4 step. |
| [Infill](glossary.md#infill) | 15 % | Nothing carries a load beyond its own stack. |
| [Supports](glossary.md#supports) | **None, on any part** | Every part is designed to print support-free in the orientation on its card. |

> [!IMPORTANT]
> If your slicer proposes support anywhere, the part is oriented wrong; go back to its card. There is also no [bridging](glossary.md#bridging) to tune: the longest bridge in the whole build is the 3.3 mm roof of the locating notches under the cover-stage, which default settings clear without a thought.

<details>
<summary>Why the geometry is quantised to 0.2 mm, and what that buys you</summary>

The manufacturing rule behind every part in this project: **every horizontal face sits on a 0.2 mm grid in the part's print orientation, and no exposed step is thinner than 0.4 mm.** Both rules came out of real vendor orders going wrong ([design log entry 18](design-log.md#18-layer-quantised-holders), and entry 20 for orientation), and they are the reason a print shop's default profile produces a working part.

| Part | Horizontal faces, measured from the plate (mm) |
|---|---|
| `main-body.stl` | 0 · 3.0 · 73.0 · 75.6 |
| `cover-stage.stl` | 0 · 2.8 · 3.6 · 5.0 · 6.0 · 10.0 |
| Holder bases (both) | 0 · 2.2 · 3.8 · 4.2 · 4.6 · 5.0 |
| Holder lids (both, printed top face down) | 0 · 1.0 · 3.0 |

Every number is a multiple of 0.2, and the finest exposed steps in the build, the 0.4 mm land and ledge steps on the holder bases, are exactly the ones that define the film plane. That is why the spec pins the layer height to 0.2 mm on every file: each of those faces lands exactly on a layer boundary, a printed 0.4 step is two clean layers, and nothing is left to slicer rounding. A coarser layer such as 0.28 is slightly cheaper, but it drops the grid between boundaries and blurs exactly the steps the film plane depends on.

</details>

**Nozzle.** Nothing in the build is finer than the 0.4 mm steps on the holder bases, and no wall is thinner than 2.4 mm. A standard 0.4 mm nozzle handles every part.

---

## Filament

### Plain PLA, two colours

The spec is ordinary PLA throughout: no engineering filaments, no specialty finishes.

**White for the three enclosure parts: the main body and either cover-stage.** The interior of the main body is the reflector: the flash fires into the fully open front and reaches the film only after bouncing between the white walls and the white underside of the cover-stage. The bare white surface *is* the optical surface.

> [!IMPORTANT]
> Use plain white PLA (not silk, satin or another specialty finish) and leave the interior faces untouched: no paint, no sanding, no coating. The reflectance of the bare white walls is part of the optical design.

**Black for the nine parts near the film.** Everything the film sees at close range is black to absorb stray light: holder bases and lids, pressure windows, the mask, the slide plate, the sheet plate.

**Quantity.** About **300–350 g for the default build**, roughly a third of the prototype build; the optional slide plate adds about 25 g and the 4×5 pair about 35 g. One spool of each colour covers it many times over.

---

## The twelve parts

Side views of the printed parts on the build plate

### Part vocabulary

Print instructions here always name a feature you can see on the part, never a hidden face. This is what the words mean:

| Word used here | What you are looking at |
|---|---|
| Rail | One of the two long outer ridges on a holder base, running the direction the film travels |
| Land | The narrow raised shelf along each rail that the film edges ride on |
| Element ledge | The 4.6 mm step cut into each rail that the pressure element sits on |
| Channel | The 0.4 mm gap between the land and the pressure element that the film slides through |
| Window | The rectangular hole you photograph through |
| Pressure element | Whatever sits on the element ledge: a printed pressure-window insert by default, or the optional anti-Newton glass |
| Tenon | One of the four small locating tabs on top of the main-body side walls |
| Notch | One of the four corner sockets in the underside of the cover-stage that the tenons locate into |
| Tray flange | The raised rim on top of the cover-stage that the film holder sits inside |
| Pocket | The 51.4 mm square recess in the top of the slide plate that a mounted slide drops into |
| Finger well | One of the two small blind recesses at the sides of the pocket that let you lift the mount out |
| Edge notch | One of the two open cuts in the short sides of the sheet plate that let you lift a sheet out |

> [!CAUTION]
> Two orientation traps, one per part family. The holder **bases** print flat face down: never with the railed side toward the plate, or the lands and ledges hang over air and the channel will not come out. The holder **lids** are the opposite case: their flat **top** face goes down, so that the shallow recess and the magnet pockets face up. A misoriented holder reached a vendor once already ([design log entry 20](design-log.md)); that is why every card below places its part by a feature you can see.

### [main-body.stl](../stl/white-pla/main-body.stl)

- **White.** 124.8 × 154.8 × 75.6, the biggest and longest print in the set.
- **On the plate:** the flat floor down. Three walls rise from it; the fourth side (the fully open front) has no wall at all; that is the design, not a broken file. The four locating tenons ride on top of the side walls.
- **Supports: none.** The open front is an absence, not an overhang; nothing on this part hangs over air.
- **Watch:** the interior faces are optical. No sanding, no paint.

### [cover-stage.stl](../stl/white-pla/cover-stage.stl)

- **White.** 124.8 × 154.8 × 10.0. This single part replaces the prototype's top cover and film stage.
- **On the plate:** the flat face with the four corner notches goes down; the raised tray flange faces up.
- **Supports: none.** The notch roofs bridge 3.3 mm, the longest bridges in the build and still trivial.
- **On this part:** the 62 × 95 light window, the recessed seat for the opal acrylic just below the deck surface, four small square counterbores for the steel shims, and the tray flange that locates the film holder.

### [film-holder-135-base.stl](../stl/black-pla/film-holder-135-base.stl)

- **Black.** 94 × 120 × 5.0. Window 25 × 37.
- **On the plate:** flat face down; the two long rails point up. Short guide ribs at each end of the channel lead the film in.
- **Supports: none.** Every magnet pocket and every step opens upward.
- **Watch:** the land and the element ledge on this part define the film plane; this is where 0.2 mm layers pay off if you use them.

### [film-holder-135-lid.stl](../stl/black-pla/film-holder-135-lid.stl)

- **Black.** 94 × 120 × 3.0. Window 25 × 37.
- **On the plate: top face down.** The flat face with nothing on it but the window goes against the plate; the face with the shallow rectangular recess and the eight magnet pockets points up.
- **Supports: none.** In this orientation the recess and the pockets all open upward.

### [film-holder-120-base.stl](../stl/black-pla/film-holder-120-base.stl)

- **Black.** 94 × 120 × 5.0. Window 57 × 85 (a full 6×9 frame) with a 62 mm wide channel.
- **On the plate:** flat face down; the two long rails point up.
- **Supports: none.**
- **Watch:** same as the 135 base: the land and ledge are the film plane.

### [film-holder-120-lid.stl](../stl/black-pla/film-holder-120-lid.stl)

- **Black.** 94 × 120 × 3.0. Window 57 × 85.
- **On the plate: top face down**, exactly like the 135 lid: recess and magnet pockets up.
- **Supports: none.**

### [pressure-window-135.stl](../stl/black-pla/pressure-window-135.stl)

- **Black.** 64 × 95 × 2.0, window 25 × 37. The default pressure element for 135; it sits on the element ledge of the 135 base.
- **On the plate:** lies flat, flat side down.
- **Supports: none.**

### [pressure-window-120.stl](../stl/black-pla/pressure-window-120.stl)

- **Black.** 64 × 95 × 2.0, window 57 × 85. The default pressure element for 120.
- **On the plate:** lies flat, flat side down.
- **Supports: none.**
- **Note:** the two pressure windows are the format-specific pressure elements. The optional anti-Newton glass upgrade is a single 64 × 95 sheet that serves both formats.

### [mask-6x6.stl](../stl/black-pla/mask-6x6.stl) — optional

- **Black.** 94 × 80 × 1.0, window 56.5 × 56.5.
- **On the plate:** lies flat.
- **Supports: none.**
- **Print it only if** you shoot 6×6: it goes into the tray under the 120 base and masks the window down to a square. There is no 6×4.5 mask; crop 6×4.5 in post.

### [slide-plate-135.stl](../stl/black-pla/slide-plate-135.stl) — optional

- **Black.** 94 × 120 × 5.0. Square pocket 51.4 × 51.4, 2.0 deep; window 26 × 38 through the pocket floor; two finger wells.
- **On the plate:** flat face down; the pocket and the finger wells open upward.
- **Supports: none.** Every recess opens upward and the window is a through hole.
- **Print it only if** you have mounted 135 slides: it stands in the tray in place of the 135 holder set and the mount drops into the pocket. No lid, no magnets, no pressure element.

### [cover-stage-4x5.stl](../stl/white-pla/cover-stage-4x5.stl) — optional

- **White.** 124.8 × 154.8 × 10.0: the cover-stage's outline with a 102 × 126 light window, a recess for a 106 × 130 × 2 opal sheet and a 112.6 × 138.6 tray; no washer pockets.
- **On the plate:** exactly like the cover-stage: the flat face with the four corner notches goes down, the raised tray flange faces up.
- **Supports: none.** The same notch roofs as the cover-stage.
- **Print it only if** you shoot 4×5: it replaces the cover-stage on the same main body. Its underside faces the cavity, so no sanding, no paint.

### [sheet-plate-4x5.stl](../stl/black-pla/sheet-plate-4x5.stl) — optional

- **Black.** 112 × 138 × 5.0. Pocket 102.2 × 127.6, 2.0 deep; window 97 × 121 through the pocket floor; two edge notches on the short sides.
- **On the plate:** flat face down; the pocket and the notches open upward.
- **Supports: none.**
- **Print it only if** you shoot 4×5: it stands in the 4×5 cover-stage's tray and the sheet drops into the pocket. No lid, no magnets, no pressure element.

---

## Print one 135 holder first

Print `film-holder-135-base.stl`, `film-holder-135-lid.stl` and `pressure-window-135.stl` before you commit to the rest. They are among the smallest parts in the set, and between them they exercise every fit that matters: the magnet pockets, the element ledge, and the 0.4 mm channel.

Four things to check on that first set:

- **The ledge.** The pressure window drops onto the 4.6 mm element ledge and sits flat, and the lid closes over it. A little play is by design: the lid's recess limits the element's float to 0.4 mm.
- **The channel.** With the insert seated and the lid closed, a strip of film pulls through smoothly, with no binding or scraping.
- **The magnets.** A Ø8 × 2 magnet presses into each pocket. The fit is a designed interference. Check which way round the base and lid magnets attract *before* pressing them home, because they do not come back out easily.
- **Flatness.** The base sits flat with no rocking. It carries the film plane.

If any of these is wrong, fix it here (see [If it came out tight or loose](#if-it-came-out-tight-or-loose)), then print the remaining black parts, and the two white parts last.

---

## Check each part before you assemble

Run these as parts come off the machine or out of the box from a print service. The first three catch a slicer that scaled a file.

- [ ] `main-body.stl` measures 124.8 × 154.8 outside.
- [ ] `cover-stage.stl` measures 124.8 × 154.8, and its four notches settle onto the main body's four tenons under their own weight.
- [ ] Every holder part measures 94 × 120 in outline, base and lid alike.
- [ ] The pressure windows measure 64 × 95 and drop onto the element ledge of their base.
- [ ] Ø8 × 2 magnets press into every pocket in every base and lid.
- [ ] With the insert in and the lid closed, a film strip pulls through each holder you printed.
- [ ] If you printed it: `mask-6x6.stl` measures 94 × 80 and sits in the tray under the 120 base.
- [ ] If you printed it: `slide-plate-135.stl` measures 94 × 120, sits in the tray, and a mounted slide drops into its pocket and lifts out by the finger wells.
- [ ] If you printed them: `cover-stage-4x5.stl` settles onto the four tenons like the cover-stage, and `sheet-plate-4x5.stl` measures 112 × 138 and sits in its tray.
- [ ] Nothing inside the main body has been sanded, polished or painted. The bare white surface is the reflector.

Anything that fails has a remedy below, or in [troubleshooting](troubleshooting.md#printing).

---

## If it came out tight or loose

Fits, in order of how tight they are. XY compensation is called *XY size compensation* in PrusaSlicer and OrcaSlicer and *Horizontal expansion* in Cura; change it in small steps and reprint one part, never the whole set.

| Fit | Nominal | Too tight | Too loose |
|---|---|---|---|
| Film channel | 0.4 mm between land and pressure element | Check the element is fully seated on its ledge, then deburr the land edges and the element edges with a hobby knife. If film still binds, reprint the base at 0.2 mm layers (that lands the land and ledge exactly on layer boundaries) before reaching for XY compensation. | A slight rattle is normal: the film is only about 0.12–0.18 mm thick in a 0.4 mm channel, and the channel presses the film flat as it is pulled through. |
| Pressure element on its ledge | 64 × 95 on the ledge | Lightly ease the *element's* edges with fine sandpaper: the element, never the ledge. | Fine. The lid's recess limits the element's float to 0.4 mm. |
| Cover-stage notches on the tenons | four tenons, 2.4 × 12 | Ease the notch mouths with a knife; enable [elephant-foot](glossary.md#elephant-foot) compensation on a reprint if that is not enough. | Harmless. The notches locate the cover-stage; gravity holds it. |
| Magnet pockets | Ø8 × 2 magnets | The interference is designed: press squarely and firmly. If a magnet genuinely will not start, ease the pocket rim with a knife. Never hammer a neodymium magnet; it chips. | A drop of cyanoacrylate; the pocket locates, the glue holds. |

> [!CAUTION]
> Never sand, file or "clean up" the land or the element ledge to free a tight channel. Those two steps *are* the film plane: material removed there is a film-flatness error you cannot undo. A tight channel is fixed in the slicer (0.2 mm layers, a touch of XY compensation) or on the removable element, never on the base's steps.

---

## Ordering from a print service

Even with no printer at all this is now a small order: twelve files (four optional), about 300–350 g of plain PLA, no supports, and every part fits a 160 × 160 mm bed. Send this text as-is; it names every file and places each one by a feature the operator can see.

```text
12 STL files: 8 required + 4 optional (mask-6x6, slide-plate-135, cover-stage-4x5, sheet-plate-4x5). Millimetres, 1:1. DO NOT SCALE.

Plain PLA. Layer height 0.2 mm on every part. Infill 15%. NO SUPPORTS on any part.
Everything fits a 160 x 160 mm bed.

WHITE PLA - 2 parts + 1 optional:
  main-body.stl        124.8 x 154.8 x 75.6. Flat floor on the plate, walls up.
                       One side has no wall - that is the design, not an error.
                       Do not sand, paint or coat the inside faces.
  cover-stage.stl      124.8 x 154.8 x 10. The flat face with the four corner
                       sockets goes on the plate; the raised rectangular frame
                       faces up.
  cover-stage-4x5.stl (OPTIONAL)  Same placement as cover-stage.stl.

BLACK PLA - 6 parts + 3 optional:
  film-holder-135-base.stl  Flat face on the plate, the two long ridges up.
  film-holder-120-base.stl  Same placement.
  film-holder-135-lid.stl   FLAT TOP FACE on the plate. The face with the
  film-holder-120-lid.stl   shallow recess and eight magnet holes faces UP.
  pressure-window-135.stl   Thin flat plate, lies flat.
  pressure-window-120.stl   Thin flat plate, lies flat.
  mask-6x6.stl (OPTIONAL)   Thin flat plate, lies flat.
  slide-plate-135.stl (OPTIONAL)  Flat face on the plate, square pocket up.
  sheet-plate-4x5.stl (OPTIONAL)  Flat face on the plate, pocket up.
```

**Ask three questions before you pay.** Print services take the order first and discover the problem afterwards.

1. Will every file print at 100 % scale, in millimetres, with no "scale to fit"?
2. Is the white filament plain PLA, not silk, not glossy?
3. Will you place the two holder lids top face down, exactly as written?

**If the shop pushes back on the settings,** let them run their default profile. The geometry is quantised so that defaults work: every horizontal face on a 0.2 mm grid, no exposed step under 0.4 mm. The only load-bearing instructions are "do not scale", the orientations, and "no supports".

Vendor-language versions of this text (Chinese for Taobao, Japanese for Japanese services) are in [vendor scripts](bom.md#vendor-scripts), along with sourcing for everything you buy rather than print.

---

← [Bill of materials](bom.md) · [Documentation index](../README.md#documentation) · [Assembly](assembly.md) →

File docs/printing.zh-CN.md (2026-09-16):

# 3D 打印

[English](printing.md) · **简体中文** · [日本語](printing.ja.md)

> 怎么把 NeoBox 的十二个件打出来：为什么几乎任何打印机都行、一套通用参数、每个文件一张卡片，以及动手装配之前必须做完的检查。

**目录：** [你的打印机打得下吗](#你的打印机打得下吗) · [打印参数](#打印参数) · [耗材](#耗材) · [十二个零件](#十二个零件) · [先打一副 135 胶片夹](#先打一副-135-胶片夹) · [装配前逐件检查](#装配前逐件检查) · [打紧了或打松了怎么办](#打紧了或打松了怎么办) · [找代打服务下单](#找代打服务下单)

十二个 STL 文件：**默认配置 8 个，外加 4 个可选件：6×6 遮幅插片、装框幻灯片用的幻灯片板，以及 4×5 顶盖台和片板**。三个白色，九个黑色。全部 1:1 毫米，全部免支撑，默认配置的耗材约 **300–350 g，大约是原型机的三分之一**。

一页纸制造总览：打印件、需要采购的零件，以及每个件的打印要点

> [!CAUTION]
> 绝不要让切片软件缩放这些文件。「缩放到适合打印床」是代打订单出错最常见的一种方式。文件本来就是 1:1 的，下面所有验收检查都建立在这一点没被破坏之上。

> [!NOTE]
> 这个设计还没有真正打印出来过：本页没有任何一个数字来自实际机器。几何在 CAD 里核对过（权威是 `cad/neobox.blend`）。

---

## 你的打印机打得下吗

几乎一定打得下。全套最大的两个件是主箱和顶盖台，在床上占 124.8 × 154.8 mm；最高的是 75.6 mm 的主箱。**打印床有 160 × 160 mm 就能打完整套**，也就是说如今几乎所有桌面机、包括最小的那一档都够用。原型机时代关于超大件和外发壳体的告警，已经随原型机一起作废。

| 零件 | 在打印床上的占地 | 高度 |
|---|---|---|
| `main-body.stl` | 124.8 × 154.8 | 75.6 |
| `cover-stage.stl` | 124.8 × 154.8 | 10.0 |
| `film-holder-*-base.stl`（两个） | 94 × 120 | 5.0 |
| `film-holder-*-lid.stl`（两个） | 94 × 120 | 3.0 |
| `pressure-window-*.stl`（两个） | 64 × 95 | 2.0 |
| `mask-6x6.stl` | 94 × 80 | 1.0 |
| `slide-plate-135.stl` | 94 × 120 | 5.0 |
| `cover-stage-4x5.stl` | 124.8 × 154.8 | 10.0 |
| `sheet-plate-4x5.stl` | 112 × 138 | 5.0 |

---

## 打印参数

整套构建只有这一组参数。仓库里其他任何地方提到打印参数，都回指这里。

| 参数 | 取值 | 为什么是这个值 |
|---|---|---|
| 缩放 | 100 %，毫米 | 文件本来就是 1:1。 |
| 耗材 | 普通 PLA，两个壳体件白色，其余黑色 | 见[耗材](#耗材)。 |
| [层高](glossary.zh-CN.md#层高)（layer height） | **所有件 0.2 mm** | 设计里每个高度都落在 0.2 网格上：用 0.2 层高，每个面都正好落在层边界，0.4 的台阶打出来就是真正的 0.4。 |
| [填充](glossary.zh-CN.md#填充)（infill） | 15 % | 没有件承受自重以外的负载。 |
| [支撑](glossary.zh-CN.md#支撑)（supports） | **任何件都不要** | 每个件都按各自卡片上的朝向做了免支撑设计。 |

> [!IMPORTANT]
> 切片软件在任何地方提出要加支撑，就说明件摆错了朝向，回去看它的卡片。[桥接](glossary.zh-CN.md#桥接)（bridging）也没有任何要调的：全套最长的桥，是顶盖台底面榫槽顶那 3.3 mm，默认参数随手就过。

<details>
<summary>为什么几何按 0.2 mm 量化，这换来了什么</summary>

本项目每个零件背后的制造规则是：**在各自的打印朝向下，每一个水平面都落在 0.2 mm 网格上，且暴露台阶不薄于 0.4 mm。** 这两条规则都是从真实的代打订单翻车里迭代出来的（[设计日志第 18 条](design-log.zh-CN.md)，朝向问题见第 20 条），也是代打店用默认配置就能打出能用零件的原因。

| 零件 | 从打印床起算的水平面高度（mm） |
|---|---|
| `main-body.stl` | 0 · 3.0 · 73.0 · 75.6 |
| `cover-stage.stl` | 0 · 2.8 · 3.6 · 5.0 · 6.0 · 10.0 |
| 夹底座（两个） | 0 · 2.2 · 3.8 · 4.2 · 4.6 · 5.0 |
| 夹上盖（两个，顶面朝下打印） | 0 · 1.0 · 3.0 |

每个数都是 0.2 的整数倍；而全套最细的暴露台阶，即夹底座上 0.4 mm 的承台和元件台阶，恰恰就是定义胶片平面的那两级。所以规格把全部文件的层高定死在 0.2：每个面都正好落在层边界上，0.4 的台阶就是干净的两层，不给切片软件留任何四舍五入的空间。0.28 这类更粗的层高虽然省一点点，但会让网格落在层边界之间，糊掉的恰恰是胶片平面赖以成立的那些台阶。

</details>

**喷嘴。** 全套最细的特征是夹底座上那 0.4 mm 的台阶，最薄的墙是 2.4 mm。标准 0.4 mm 喷嘴什么件都能打。

---

## 耗材

### 普通 PLA，两种颜色

规格就是普通 PLA，全套通用：不需要工程料，也不要特殊表面效果的料。

**三个壳体件用白色：主箱和两块顶盖台中的任一块。** 主箱内壁就是反射面：闪光灯从完全敞开的前口打进腔内，光在白墙和顶盖台的白色底面之间多次反弹之后才到达胶片。裸露的白色表面*本身*就是光学面。

> [!IMPORTANT]
> 白色请用普通白 PLA，不要丝绸、缎面或其他特殊表面效果的料；内壁保持原样：不喷漆、不打磨、不镀膜。白墙的裸面反射率是光学设计的一部分。

**靠近胶片的九个件用黑色。** 胶片近距离能「看到」的东西都是黑色，用来吸收杂光：夹底座、夹上盖、压片窗插片、遮幅插片、幻灯片板、片板。

**用量。** 默认配置约 **300–350 g**，大约是原型机的三分之一；可选的幻灯片板另加约 25 g，4×5 那两件约 35 g。每种颜色一卷料绰绰有余。

---

## 十二个零件

打印件在打印床上的侧视图

### 零件术语

这里的打印说明一律用你在件上看得见的特征来描述朝向，绝不提看不见的面。这些词的意思是：

| 这里用的词 | 你看到的是什么 |
|---|---|
| 导轨 | 夹底座上沿走片方向通长的两条外侧凸起中的一条 |
| 承台 | 沿导轨内侧那条窄窄的凸台，片条两边就骑在上面 |
| 元件台阶 | 切在导轨里的那级 4.6 mm 台阶，压片元件搁在上面 |
| 通道 | 承台与压片元件之间那 0.4 mm 的缝，片条从这里抽过 |
| 开窗 | 供拍摄用的那个矩形孔 |
| 压片元件 | 搁在元件台阶上的东西：默认是打印的压片窗插片，升级是那片可选的防牛顿环玻璃 |
| 定位榫 | 主箱侧壁顶上四个小凸榫中的一个 |
| 榫槽 | 顶盖台底面四角的四个槽口中的一个，定位榫就插在里面 |
| 托盘凸缘 | 顶盖台台面上凸起的那圈围框，胶片夹就坐在框里 |
| 方槽 | 幻灯片板顶面上那个 51.4 mm 见方的凹槽，装框幻灯片就放在里面 |
| 指槽 | 方槽两侧那两个小盲槽中的一个，让你能把框抠出来 |
| 边缺口 | 片板两条短边上那两个开口切槽中的一个，让你能把页片抠出来 |

> [!CAUTION]
> 两个朝向陷阱，一个件族一个。**夹底座**平面朝下打：绝不要把带导轨的那面朝着打印床，否则承台和元件台阶全部悬空，通道根本成不了形。**夹上盖**正好反过来：平整的**顶面**朝下，让浅凹腔和磁铁孔朝上。摆错朝向的胶片夹已经在一家代打店身上发生过一次（[设计日志第 20 条](design-log.zh-CN.md)），下面每张卡片都用看得见的特征描述摆放，就是这个原因。

### [main-body.stl](../stl/white-pla/main-body.stl)

- **白色。** 124.8 × 154.8 × 75.6，全套最大、打印时间最长的件。
- **在床上：** 平底朝下。三面墙从底板上立起来；第四面就是完全敞开的前口，根本没有墙。这是设计如此，不是文件坏了。四个定位榫骑在侧壁顶上。
- **支撑：不需要。** 敞开的前口是「没有东西」，不是悬空；这个件上没有任何悬空结构。
- **注意：** 内壁是光学面。不打磨、不喷漆。

### [cover-stage.stl](../stl/white-pla/cover-stage.stl)

- **白色。** 124.8 × 154.8 × 10.0。这一个件合并了原型机的顶盖和胶片台。
- **在床上：** 带四角榫槽的平面朝下；凸起的托盘凸缘朝上。
- **支撑：不需要。** 榫槽顶要桥 3.3 mm，已经是全套最长的桥，仍然不值一提。
- **这个件上还有：** 62 × 95 的透光窗、台面下方那个搁乳白亚克力的暗槽、四个放钢垫片的小方沉孔，以及给胶片夹定位的托盘凸缘。

### [film-holder-135-base.stl](../stl/black-pla/film-holder-135-base.stl)

- **黑色。** 94 × 120 × 5.0。开窗 25 × 37。
- **在床上：** 平面朝下，两条长导轨朝上。通道两端各有一小段导向筋，把片条引进来。
- **支撑：不需要。** 所有磁铁孔和台阶都是朝上开口的。
- **注意：** 这个件上的承台和元件台阶定义了胶片平面：要是打算用 0.2 层高，收益就在这里。

### [film-holder-135-lid.stl](../stl/black-pla/film-holder-135-lid.stl)

- **黑色。** 94 × 120 × 3.0。开窗 25 × 37。
- **在床上：顶面朝下。** 除了开窗以外什么都没有的那个平面贴床；带浅矩形凹腔和八个磁铁孔的那一面朝上。
- **支撑：不需要。** 这个朝向下，凹腔和磁铁孔全部朝上开口。

### [film-holder-120-base.stl](../stl/black-pla/film-holder-120-base.stl)

- **黑色。** 94 × 120 × 5.0。开窗 57 × 85（整格 6×9），通道宽 62 mm。
- **在床上：** 平面朝下，两条长导轨朝上。
- **支撑：不需要。**
- **注意：** 和 135 底座一样：承台和元件台阶就是胶片平面。

### [film-holder-120-lid.stl](../stl/black-pla/film-holder-120-lid.stl)

- **黑色。** 94 × 120 × 3.0。开窗 57 × 85。
- **在床上：顶面朝下**，和 135 上盖完全一样：凹腔和磁铁孔朝上。
- **支撑：不需要。**

### [pressure-window-135.stl](../stl/black-pla/pressure-window-135.stl)

- **黑色。** 64 × 95 × 2.0，开窗 25 × 37。135 的默认压片元件，搁在 135 底座的元件台阶上。
- **在床上：** 平放，平底朝下。
- **支撑：不需要。**

### [pressure-window-120.stl](../stl/black-pla/pressure-window-120.stl)

- **黑色。** 64 × 95 × 2.0，开窗 57 × 85。120 的默认压片元件。
- **在床上：** 平放，平底朝下。
- **支撑：不需要。**
- **说明：** 两个压片窗插片是唯一分幅面的压片元件。可选的防牛顿环玻璃升级件是一片 64 × 95，两个幅面通用。

### [mask-6x6.stl](../stl/black-pla/mask-6x6.stl)——可选

- **黑色。** 94 × 80 × 1.0，开窗 56.5 × 56.5。
- **在床上：** 平放。
- **支撑：不需要。**
- **只有在**你要拍 6×6 时**才打它**：垫在 120 底座下方的托盘里，把开窗缩成正方形。没有 6×4.5 的遮幅，6×4.5 靠后期裁切。

### [slide-plate-135.stl](../stl/black-pla/slide-plate-135.stl)——可选

- **黑色。** 94 × 120 × 5.0。方槽 51.4 × 51.4，深 2.0；开窗 26 × 38，穿过槽底；两个指槽。
- **在床上：** 平面朝下；方槽和指槽开口朝上。
- **支撑：不需要。** 每个凹槽都开口向上，开窗是通孔。
- **只有在**你有装框的 135 幻灯片时**才打它**：它代替 135 那副胶片夹立在托盘里，框放进方槽。没有上盖、没有磁铁、没有压片元件。

### [cover-stage-4x5.stl](../stl/white-pla/cover-stage-4x5.stl)——可选

- **白色。** 124.8 × 154.8 × 10.0：顶盖台的外形，透光窗改为 102 × 126，暗槽放 106 × 130 × 2 的乳白板，托盘 112.6 × 138.6；没有垫片沉孔。
- **在床上：** 和顶盖台完全一样：带四个角槽的平面朝下，凸起的托盘凸缘朝上。
- **支撑：不需要。** 榫槽顶和顶盖台的一样。
- **只有在**你拍 4×5 时**才打它**：它在同一只主箱上代替顶盖台。它的底面对着混光腔，所以不打磨、不喷漆。

### [sheet-plate-4x5.stl](../stl/black-pla/sheet-plate-4x5.stl)——可选

- **黑色。** 112 × 138 × 5.0。片槽 102.2 × 127.6，深 2.0；开窗 97 × 121，穿过槽底；两条短边上各一个边缺口。
- **在床上：** 平面朝下；片槽和缺口开口朝上。
- **支撑：不需要。**
- **只有在**你拍 4×5 时**才打它**：它立在 4×5 顶盖台的托盘里，页片放进片槽。没有上盖、没有磁铁、没有压片元件。

---

## 先打一副 135 胶片夹

在决定打其余文件之前，先打 `film-holder-135-base.stl`、`film-holder-135-lid.stl` 和 `pressure-window-135.stl`。它们属于全套最小的几个件，而这三件合起来把所有要紧的配合都跑了一遍：磁铁孔、元件台阶、0.4 mm 的通道。

第一组要检查四件事：

- **台阶。** 压片窗插片落进 4.6 mm 元件台阶并且放得平，上盖能盖上。有一点点活动量是设计意图：上盖的凹腔把元件的浮动限制在 0.4 mm 以内。
- **通道。** 插片装好、上盖盖上之后，片条能顺滑地抽过，不卡、不刮。
- **磁铁。** Ø8 × 2 的磁铁能压进每一个孔。这是设计好的过盈配合。压到底*之前*先把底座磁铁和上盖磁铁凑到一起弄清哪面相吸，因为压进去就很难再取出来。
- **平面度。** 底座平放不翘。胶片平面就架在它上面。

有任何一件不对，就在这里解决（见[打紧了或打松了怎么办](#打紧了或打松了怎么办)），然后再打其余黑色件，两个白色件放到最后。

---

## 装配前逐件检查

件从机器上下来、或者从代打店的包裹里拆出来时就把这些做掉。前三条是用来抓「切片软件缩放了文件」的。

- [ ] `main-body.stl` 外形量得 124.8 × 154.8。
- [ ] `cover-stage.stl` 量得 124.8 × 154.8，四个榫槽靠自重就能落到主箱的四个定位榫上。
- [ ] 每个胶片夹零件外形都量得 94 × 120，夹底座和夹上盖一样。
- [ ] 压片窗插片量得 64 × 95，能落进各自底座的元件台阶。
- [ ] Ø8 × 2 磁铁能压进每个夹底座和夹上盖上的每一个磁铁孔。
- [ ] 插片装好、上盖盖上之后，片条能抽过你打出来的每一副胶片夹。
- [ ] 如果打了 `mask-6x6.stl`：量得 94 × 80，能垫进 120 底座下方的托盘。
- [ ] 如果打了 `slide-plate-135.stl`：量得 94 × 120，能放进托盘，装框幻灯片放得进它的方槽、也能从指槽抠出来。
- [ ] 如果打了这两件：`cover-stage-4x5.stl` 能像顶盖台一样靠自重落到四个定位榫上，`sheet-plate-4x5.stl` 量得 112 × 138，能放进它的托盘。
- [ ] 主箱内壁没有被打磨、抛光或喷涂过。裸露的白色表面就是反射面。

任何一条不过，下面有对应的处理办法，或者见[排错](troubleshooting.zh-CN.md#打印)。

---

## 打紧了或打松了怎么办

下表按配合的紧密程度从紧到松排列。XY 补偿在 PrusaSlicer 和 OrcaSlicer 里叫 *XY size compensation*，在 Cura 里叫 *Horizontal expansion*；每次只改一小步，只重打一个件，绝不整套重来。

| 配合部位 | 标称值 | 太紧 | 太松 |
|---|---|---|---|
| 通道 | 承台与压片元件之间 0.4 mm | 先确认元件完全落进元件台阶，再用美工刀把承台边缘和元件边缘的毛刺修掉。片条还是卡，就先用 0.2 层高重打底座（那样承台和台阶正好落在层边界上），再考虑动 XY 补偿。 | 轻微晃动是正常的：0.4 mm 的通道里，片条厚度只有约 0.12–0.18 mm，抽片时通道会把片条压平带过。 |
| 压片元件配元件台阶 | 64 × 95 落台阶 | 用细砂纸轻轻修*元件*的边：只修元件，绝不修台阶。 | 无妨。上盖凹腔把元件浮动限制在 0.4 mm 以内。 |
| 顶盖台榫槽配定位榫 | 四个榫，2.4 × 12 | 用刀修一下榫槽口；还不够就打开[象足](glossary.zh-CN.md#象足)（elephant foot）补偿重打。 | 无害。榫槽负责定位，重力负责固定。 |
| 磁铁孔 | Ø8 × 2 磁铁 | 过盈本来就是设计好的：垂直、用力压到底。真压不进去就用刀修一下孔口。绝不要敲钕磁铁，会崩角。 | 点一滴 502；孔负责定位，胶负责固定。 |

> [!CAUTION]
> 绝不要为了让偏紧的通道松开而去打磨、锉削或「清理」承台和元件台阶。这两级台阶*就是*胶片平面：在这里去掉的材料，就是一笔无法撤销的压平误差。通道偏紧要在切片软件里解决（0.2 层高、一点 XY 补偿），或者修可更换的元件，绝不动底座上的台阶。

---

## 找代打服务下单

就算完全没有打印机，这也已经是一张小单：十二个文件（其中四个可选）、约 300–350 g 普通 PLA、全程免支撑，每个件 160 × 160 mm 的打印床都放得下。淘宝搜索词：`3D打印 代打 PLA`。下面这段话原样复制发给店家即可。它点名了每一个文件，并用操作员看得见的特征描述摆放。

```text
共 12 个 STL 文件：必打 8 个，另有 4 个可选（mask-6x6、slide-plate-135、cover-stage-4x5、sheet-plate-4x5）。
单位毫米，1:1，请勿缩放。

普通 PLA。所有件层高 0.2 mm。
填充 15%。任何件都不要加支撑。每个件 160 x 160 mm 的床都放得下。

白色 PLA 2 件 + 1 件可选：
  - main-body.stl（124.8 x 154.8 x 75.6）
    摆放：平底朝下贴床，墙朝上。有一面没有墙，这是设计如此，不是文件坏了。
    内壁请勿打磨、喷漆或镀膜。
  - cover-stage.stl（124.8 x 154.8 x 10）
    摆放：带 4 个角槽的平面朝下贴床，凸起的矩形围框朝上。
  - cover-stage-4x5.stl（可选）
    摆放：与 cover-stage.stl 相同。

黑色 PLA 6 件 + 3 件可选：
  - film-holder-135-base.stl / film-holder-120-base.stl（两个夹底座）
    摆放：平面朝下，带两条长凸条的面朝上。
  - film-holder-135-lid.stl / film-holder-120-lid.stl（两个夹上盖）
    摆放：平整的顶面朝下贴床；带浅凹腔和 8 个磁铁孔的那一面朝上。
  - pressure-window-135.stl / pressure-window-120.stl（两个薄插片）
    摆放：平放。
  - mask-6x6.stl（可选，薄板）
    摆放：平放。
  - slide-plate-135.stl（可选）
    摆放：平面朝下，方槽朝上。
  - sheet-plate-4x5.stl（可选）
    摆放：平面朝下，片槽朝上。
```

**付款之前先问三个问题。** 代打店往往是先接单，后发现问题。

1. 每个文件都按 100 % 缩放、毫米单位打，不会「缩放到适合打印床」吧？
2. 白色料是普通白 PLA 吗？不是丝绸料，也不是亮面料？
3. 两个夹上盖会照文字要求顶面朝下摆吗？

**店家不愿意照参数走时，** 随他用自己的默认配置。几何量化的目的就是让默认配置也能打准：每个水平面都在 0.2 mm 网格上，暴露台阶不小于 0.4 mm。真正不能让的只有「请勿缩放」、摆放朝向，和「不加支撑」。

其他语言版本的话术（发给日本代打服务的日文版、其余地区用的英文版），连同所有需要采购而不是打印的东西的货源，都在[店家话术](bom.zh-CN.md#给店家的话术)里。

---

← [物料清单](bom.zh-CN.md) · [文档索引](../README.zh-CN.md#文档) · [装配](assembly.zh-CN.md) →

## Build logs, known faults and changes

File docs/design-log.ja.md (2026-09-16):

# 設計ログ

[English](design-log.md) · [简体中文](design-log.zh-CN.md) · **日本語**

> NeoBox がなぜこの形に落ち着いたのか。決定を下した順に並べた 26 件と、検討したうえで見送った 4 つのアイデアです。何かを改造する前に読んでください。

**目次：** [このログの読み方](#このログの読み方) · [フェーズ 1：初稿は成立しなかった](#フェーズ-1初稿は成立しなかった) · [フェーズ 2：32 リットルから約 5 リットルへ](#フェーズ-232-リットルから約-5-リットルへ) · [フェーズ 3：不要なものをすべて削る](#フェーズ-3不要なものをすべて削る) · [フェーズ 4：ストロボが箱を出る](#フェーズ-4ストロボが箱を出る) · [あえてやらなかったこと](#あえてやらなかったこと)

## このログの読み方

先に番号について：本ログの v1 から v5 は社内の草案番号です。第 5 案がそのまま公開版 v1 として出ており、本文に出てくる出力済みプロトタイプは社内第 4 案を指します。

設計は 3 つのフェーズを通りました。算術の合わない初稿を立て直す段階、背の高い縦型を平たい横型へ潰す段階、そして不要と分かったものを片端から削る段階です。

```mermaid
flowchart LR
    A["初稿<br/>縦型・拡散板 2 枚"] --> B["フェーズ 1<br/>算術の破綻を修正"]
    B --> C["フェーズ 2<br/>拡散板 1 枚・ストロボを横倒し"]
    C --> D["フェーズ 3<br/>部品を削減・合板からプリントへ"]
    D --> E["リリース<br/>208 × 273 × 96 mm"]
```

> [!NOTE]
> ここに書かれた結論は、どれも実物を作って得たものではありません。**この箱はまだ一度も出力も撮影も均一性の測定もされていません。** 以下の判断はすべて CAD と計算の上で、あるいは出力業者とのやり取りの中で下したものです。挙げてある寸法はリリース版の形状であり、旧改訂の数値は再検証していないので繰り返しません。

各エントリは見出しになっているので、どれもほかのページからリンクできます。たとえば `design-log.ja.md#18-ホルダーを積層ピッチに量子化` のように書きます。

## フェーズ 1：初稿は成立しなかった

最初の仕様は、拡散板 2 層の下にストロボを足で立てて置く縦型の箱でした。その形は何一つ残っていませんが、そこで生まれたルールのうち 5 つは今も生きています。

*収録エントリ：[1](#1-高さが算術的に成立しなかった) · [2](#2-枠のない拡散板は光が漏れる) · [3](#3-最終拡散板より上を白にしたのは誤りだった) · [4](#4-発光部のセンタリングストッパー) · [5](#5-水平調整の荷重を受けられる天面) · [6](#6-ストレートな穴ではなく遮光ラビリンスの通気) · [7](#7-均一性を判定する前にフラットフィールド補正) · [8](#8-大判への布石)*

### 1. 高さが算術的に成立しなかった

初稿は 3 つの空隙を積み上げる構成でした。発光部から 1 枚目の拡散板まで、拡散板 2 枚のあいだで光を混ぜる空間、そして 2 枚目の上の黒いチャンバーです。足し合わせると、同じ文書が宣言していた内寸高さを超えていました。しかもその予算には、ストロボ本体そのものが入っていません。

修正は数値ではなく、方法でした。

> [!IMPORTANT]
> **高さは床から実測した層を積み上げて求め、そのうえで外形寸法を読み取ること。外形高さを先に決めて層を逆算してはいけません。** リリース版のスタックはこの方法で導いてあり、[design.ja.md](design.ja.md#2-寸法チェーン) に一覧してあります。

### 2. 枠のない拡散板は光が漏れる

拡散板は、それが収まる拡散チャンバーより小さいものでした。つまり光は板を通らずに縁を回り込めます。各拡散板には、発光する窓だけを開けた全幅のキャリアパネルを与えました。

**教訓：光が拡散板を回り込めるなら、その板は仕事をしていない。**

### 3. 最終拡散板より上を白にしたのは誤りだった

最終拡散板より上の白い壁は、迷光をフィルムへ跳ね返してコントラストを下げます。この区間はつや消し黒に変えました。このルールはリリース版まで生き残っています。拡散板より上はすべて黒、下は無塗装の白いフィラメントのままです。

**教訓：拡散板より下は白、上は黒。**

### 4. 発光部のセンタリングストッパー

寝かせたスピードライトの発光部は、箱の中心線に乗ってくれません。そしてホットスポットは発光部について動きます。初稿には、光学系が前提としていた位置に発光部を置くためのストッパーが加わりました。リリース版では同じ仕事を手順で果たします。ストロボの周囲をなぞって床に線を引き、毎回同じ場所に戻るようにします。

**教訓：位置が光を左右する部品には、位置決め形状か目印か、どちらかを与える。**

### 5. 水平調整の荷重を受けられる天面

初稿は薄い板の天面に水平調整ねじを直接載せており、ねじは板を潰していたはずです。天面は、金属の受け点を持つ厚いパネルになりました。リリース版の天板もこの原則を保っています。3 個のインサートナットは、4 mm の天板そのものではなく、その裏側に立つ専用のポストに収まっています。

**教訓：水平調整点は荷重の通り道である。裏に材料を置く。**

### 6. ストレートな穴ではなく遮光ラビリンスの通気

ライトボックスにまっすぐな通気穴を開けるのは、肩書きを与えた光漏れです。初稿の通気口はラビリンスになりました。リリース版はさらに先へ進み、通気口を 1 つも持ちません。後述の[換気](#換気)を参照してください。

**教訓：放熱のために筐体へ穴を開けるなら、先にその穴が光へ与える影響を確かめる。**

### 7. 均一性を判定する前にフラットフィールド補正

初稿の均一性目標は、レンズ自身の周辺減光と光源の本当のムラという別々のものを混同していました。[フラットフィールド補正 (flat-field correction)](glossary.ja.md#フラットフィールド補正-flat-field-correction)（何も載せない発光面を撮影し、そのコマで減光を割り戻す処理）が、この 2 つを切り分けます。光源そのものに対する目標は四隅で **±0.1 [EV](glossary.ja.md#ev-露出値)**、しかもこの補正の前ではなく後に適用される値です。

**教訓：公差は何を基準に測るのかまで書く。書かなければ誰も満たせない。**

### 8. 大判への布石

将来の 4×5 版に向けた確保は、箱の本体と同じ「ストロボの高さを数え忘れる」誤りを抱えていたので、スケーリングではなく層の足し算から計算し直しました。それでも確保にとどまります。リリース版の箱は 100 × 120 mm の開口を通して、35 mm と 6×9 までの 120 フィルムを扱います。

## フェーズ 2：32 リットルから約 5 リットルへ

3 つの決定が、縦型のキャビネットを机に載るものへ変えました。

*収録エントリ：[9](#9-拡散板-2-枚を-1-枚に) · [10](#10-縦置きから横倒しへ) · [11](#11-小型ストロボでは小さくならない)*

### 9. 拡散板 2 枚を 1 枚に

拡散層を 2 枚重ね、そのあいだに光を混ぜる空間を置く。これは均一な発光面を作る教科書どおりのやり方で、初稿があれほど背が高かった理由の大半でもありました。これを 1 枚に削りました。

この選択は、この箱を測って裏づけたものでは**ありません**。作者が現に使っているカメラスキャンの作業手順（ライトパッドの上に直接フィルムを置き、1 枚の拡散面をそのすぐ下に置くやり方）から持ち込んだ判断です。残った 1 枚の下で光を混ぜる距離は、引き継ぐのではなく広げました。2 層構成のすきまは 2 枚目へ光を供給するための値であり、そのまま写していれば、ストロボのホットスポットが発光面にそのまま焼き付いていたはずです。

**教訓：半分を削除した設計から写してきた寸法はただの残骸で、使う前に導出し直す必要がある。**

### 10. 縦置きから横倒しへ

箱の高さは依然として「足で立てたストロボ＋垂直方向に光を混ぜる距離」に人質を取られており、設置面積は拡散板 2 枚時代の遺物でした。ストロボを寝かせて横向きに発光させると、光を混ぜる距離は箱の奥行きへ移ります。ストロボ本体がすでに占めていた奥行きです。

この 1 つの変更で、体積は約 **32 リットルから約 5 リットル**になりました。リリース版は 208 × 273 × 96 mm、約 5.4 リットルです。途中の改訂では 45° の反射板で光を曲げていましたが、これは後に削除されました（[エントリ 16](#16-締結具と内部パーツの削除)）。

**教訓：箱が高すぎるときは、1 つの寸法が 2 つの仕事をしている場所を探して、横に倒す。**

### 11. 小型ストロボでは小さくならない

レイアウトを確定する前に、Godox TT350、iM30Pro、iT30Pro、KEKS KF-01 の 4 つの代替を検証しました。どれも箱を実質的に小さくしません。

<details>
<summary>小さいストロボにしても箱が小さくならない理由</summary>

縦型のレイアウトでは、光を混ぜる距離を決めるのは幾何であってストロボではありません。厚みゼロのストロボという思考実験でさえ、横型のレイアウトには勝てません。横型では、幅を決めるのは開口とフィルムステージで、中に何が入っていようと 208 mm です。奥行きは、ストロボ本体・トリガーのレシーバー・反射ゾーンが一列に並ぶことで決まります。小さいストロボは体積を買えず、出力の余裕とチャージ時間を失います。

</details>

そこで設計は、作者がすでに持っていた機材に固定されました。NEEWER TT560 スピードライトと ZENIKO T1 トリガーセットです。公開している STL はこのストロボにしか合いません。別のストロボの数値は [design.ja.md](design.ja.md#別のストロボへの一般化) の式で求まりますが、式はファイルの寸法を変えてはくれません。

**教訓：いま手に持っている部品を最適化する前に、実際にサイズを決めている寸法を見つける。**

## フェーズ 3：不要なものをすべて削る

9 件のエントリ。うち 3 件は、作者よりも注意深く図面を読んだ出力業者がきっかけです。

*収録エントリ：[12](#12-中間キャリアパネルと黒チャンバーの削除) · [13](#13-拡散板をフィルムステージの上へ) · [14](#14-縦置き運用のための確実な固定) · [15](#15-合板から-3d-プリントへ) · [16](#16-締結具と内部パーツの削除) · [17](#17-フィルム走行路) · [18](#18-ホルダーを積層ピッチに量子化) · [19](#19-1-層だけの段差をなくす) · [20](#20-向きの指示は作業者に見えるもので書く)*

### 12. 中間キャリアパネルと黒チャンバーの削除

拡散板が 1 枚になると、2 枚目を囲っていたキャリアパネルには囲うものがなく、その上の黒いチャンバーには内張りするものがありませんでした。どちらも削除し、拡散板は開口の真上へ、そして拡散チャンバーは一様な白になりました。135 と 120 のフィルムホルダーは、同じ改訂で設計・確定しています。

**教訓：部品を消すと、たいていそれを支えるために存在していた部品が宙に浮く。作り込み直す前に下流を確認する。**

### 13. 拡散板をフィルムステージの上へ

乳白アクリル拡散板を筐体の中から取り出し、フィルムステージの上（開口をまたいで載せ、フィルムホルダーの重さで平らに保たれる位置）へ移しました。フィルムから拡散板までは約 **4.3 mm** となり、この設計が手本にしたライトパッドの幾何と一致します。

これは塵とのトレードです。拡散板の上の粒子は、[撮影倍率 (magnification ratio)](glossary.ja.md#撮影倍率-magnification-ratio) 0.43×（6×6 をフルサイズで撮る場合）・f/8 のとき、フィルム面で径およそ 0.2 mm のぼやけた塊として写ります。反転したネガでは見えず、ポジでは見えます。それでも受け入れたのは、代償が公差ではなく手順に落ちるからです。セッションの最初に、拡散板の両面と[フィルムゲート (film gate)](glossary.ja.md#フィルムゲート-film-gate)をブロアーで払う。それだけです。直射防止のバッフルとそのブラケットも、同じときに消えました。

> [!NOTE]
> この改訂では、内部の内張りをパネルへの白塗装に置き換えてもいます。それは合板構造に属する話で、[エントリ 15](#15-合板から-3d-プリントへ) を生き延びませんでした。**プリントした箱の内側は塗装しないでください**。内部は設計上、無塗装の白いフィラメントです。

**教訓：光学的に正しい位置へ部品を動かすことは、その代償が手順に収まるなら、維持コストを払う価値がある。**

### 14. 縦置き運用のための確実な固定

箱を立てて使うには、重力で位置が決まっていた部品をすべて、確実に保持される部品に変える必要がありました。各ホルダー底のマグネット 4 個がフィルムステージ上の鉄ワッシャーに吸い付き、フィルムステージ自体は、天板のインサートナットにねじ込んだ寸切りボルト 3 本の上で、下ナットと上ナットに挟持されます。

本物の誤りが捕まったのはここです。ステージの穴は、ねじ穴として指定されていました。同じピッチの寸切りボルトにねじを切った板を組み合わせると差動ねじ (differential screw)になります。板と寸切りボルトが一緒に進むので、高さがまったく設定できません。穴は Ø6.5 mm のバカ穴 (clearance hole) になりました。

> [!CAUTION]
> フィルムステージの 3 つの穴には、絶対にタップを立てないでください。Ø6.5 mm のバカ穴が必須です。ねじを切った板は水平出しができませんし、後からもみ直すとたいてい板が使い物にならなくなります。

**教訓：締結方式は強度だけでなく、運動学の面からも点検する。**

### 15. 合板から 3D プリントへ

タブとスロットで組む合板シェルのレーザーカット図面を描いたところで、そもそも最初からプリントする箱のつもりだったと分かり、廃案にしました。

プリント化によって壁は 3 mm、床は 4 mm まで薄くなり、内部の塗装はすべて不要になり、木用のねじインサートは熱圧入の真鍮に替わり、ケーブルグランドの穴とアクセス開口はプリント後の加工ではなくプリントそのものの一部になりました。内部の光学寸法は 1 つも変わっていません。合板の DXF は `cad/legacy-plywood/` に残っていますが、これは部分的なパネルセットの歴史的記録であって、**組み立てられる代替案ではありません**。この箱に合板ルートは存在しません。

**教訓：光学がまだ部品ではなく数値であるうちに、製法を変える。**

### 16. 締結具と内部パーツの削除

天板を押さえていた M3 のポスト 6 本は、10 mm のスカートを持ち、ただ被せるだけの天板になりました。スカートが位置決め形状と遮光を兼ね、筐体を組み立てるためのねじは 1 本も残っていません。

続いて内部パーツが次々に消えました。引き出しトレイ（ストロボは床に直接寝ます）、そのブラケット、ストロボを縛るストラップ、そして最後に 45° の反射板です。奥の壁がすでに光の転向を担っており、内部パーツは 1 つ増えるごとに位置合わせが 1 つ増えるだけだからです。標準ビルドに残ったのは**プリント 8 点**、乳白アクリル拡散板 1 枚、寸切りボルト 3 本。オプションの 6×6 マスクを含めて STL は 9 ファイルです。

**教訓：部品を 1 つ削れば、それを出力する費用も位置合わせの手間も丸ごと消える。**

### 17. フィルム走行路

一体型フィルムステージの最初の勘合チェックで、2 つのブロックがホルダーの両端（ちょうど溝の入口の正面）に座り、その頂面がフィルム面のすぐ下にあることが分かりました。フィルムストリップを通すことは不可能だったはずです。同じ点検で、前側の寸切りボルトが、フィルムの通り道の真ん中でフィルム高さまで立っていることも見つかりました。

どちらも、縮めるのではなく動かしました。ブロックは |x| = 40–60 mm の 4 つのコーナーブロックになり、これで溝の入口は両側とも全開です。前側の寸切りボルトは、ステージ中心を基準に (45, −100) mm へ移りました。この制約はいまや恒久的なものです。ホルダーの両端より外側では、|x| < 31 mm の内側にフィルム高さ付近まで立ち上がるものを置いてはいけません。31 mm は 120 フィルムの幅（約 62 mm）の半分です。この空間が[フィルム走行路 (run-out corridor)](glossary.ja.md#フィルム走行路-run-out-corridor)です。

**教訓：部品どうしのすきまだけでは足りない。動くワークが掃く走行路そのものを、1 つの部品として扱う。**

### 18. ホルダーを積層ピッチに量子化

出力業者はホルダーの露出した z 段差を実測し、図面が要求していた 0.12–0.16 mm の[積層ピッチ (layer height)](glossary.ja.md#積層ピッチ-layer-height)に難色を示しました。自分たちの標準である 0.2 mm では、その段差はきれいに出ない、というのです。業者が正しく、悪いのはプリンタではなく形状のほうでした。0.5 mm の段差は、一般的な積層ピッチのどの整数倍でもありません。2.5 層にスライスされ、切り上げるか切り下げるかはスライサーの裁量に委ねられます。

キャリブレーションを議論する代わりに、z 方向の形状をすべて 0.2 mm の整数倍へ再量子化しました。その結果、溝はフィルム面を動かさないまま **0.4 mm** になりました。同じ改訂で窓も片側およそ 0.5 mm 広げ（135 は 25 × 37 mm、120 は 57 × 85 mm）、カメラの画面枠の個体差とプリンタの XY 公差を吸収させています。切り抜きは後処理で行ってください。

**教訓：製造プロセスが表現できない寸法は、業者の限界ではなく設計のバグである。**

### 19. 1 層だけの段差をなくす

業者との 3 巡目です。0.2 mm のまま残っていた形状（ホルダー底の受けの逃げ、ホルダー蓋の裏の押さえリブ）は、標準の積層ピッチではちょうど 1 層分の高さです。理論上は出力できますが、1 層だけの段差はファーストレイヤーの潰れと吐出量のキャリブレーションに人質を取られるので、業者はもう少し高さが欲しいと求めてきました。

現在はすべて 0.4 mm、2 層分です。しかも効いてくるものは何一つ動かしていません。底板を 3.8 mm に薄くして、受けの頂面（フィルム面）を据え置いたまま逃げを倍にしました。ホルダー蓋の板とレールは一緒に上がり、押さえリブは深くなりながら、溝は 0.4 mm のままです。押さえリブにはレールとのあいだに 0.3 mm の逃げも与え、ホルダー蓋が食い込まないようにしました。フィルム面、溝、窓、外形、マグネットの間隔は、いずれも変更なしです。

**教訓：露出する z 段差は 2 層を下回らせない。1 層だけの形状は、狙いどおりに出るとは当てにできない。**

### 20. 向きの指示は作業者に見えるもので書く

業者から、図面の向きの指示（溝のある面を名指しした初版の文言で、いまはどの文書からも削除済み）が実際にはどの面を指すのかと質問が来ました。プリントの物理から答えを導き直したところ、その指示自体が誤りだと判明しました。あの向きではホルダー底が 2 本のレールの頂で立ち、フィルムが載る受けが宙に浮きます。平らでなければならない唯一の面を[サポート (supports)](glossary.ja.md#サポート-supports)の上に築くことになります。

ホルダーの全パーツの正しい向きは、平らな面を下にし、形状を上へ伸ばし、サポートは一切使わないことです。ただしスライサーは自分ではそこへ行き着きません。`film-holder-*-lid.stl` は押さえリブを下にして読み込まれるので、読み込んだあとに X 軸まわりに 180° 回転させる必要があります。発注文面はすべて、作業者に見える特徴でパーツを置く方式に改めました（「長いリブが 2 本ある面を上に」）。サポート位置も明記します。[printing.ja.md](printing.ja.md#12-点のパーツ) のパーツごとのカードも、同じルールに従っています。

**教訓：向きの指示は、作業者が見て指させる特徴で書く。見えない面の名前を挙げても伝わらない。**

## フェーズ 4：ストロボが箱を出る

フェーズ 3 は、リリースされた 208 × 273 × 96 mm の箱で 3 フェーズの歴史を締めくくりました。そのあと、箱は実際に作られました。v4 は出力業者にプリントしてもらい、約 1,200 人民元かかりました。そして、その実物を手に持って行った実験が、設計をもう一度こじ開けました。以下の 4 件は 2026-08-14 に追記したもので、設計を **v5** へ進めます。

> [!NOTE]
> [このログの読み方](#このログの読み方)にある注記はこれらのエントリより前に書かれたもので、いまは 1 つの修正が要ります。**v4 はプリントされ、手に取って使われました。v5 はまだです。** v5 は一度も出力も撮影も均一性の測定もされていません。下記で報告する v4 の手持ちでの観察を除けば、v5 の数値はすべて CAD と計算です（`cad/neobox.blend`）。

*収録エントリ：[21](#21-ストロボを箱の外へ前面は全開に) · [22](#22-フィルム押さえは交換式インサート方式に収束) · [23](#23-ねじの全廃) · [24](#24-天板とフィルムステージの一体化と薄肉化)*

### 21. ストロボを箱の外へ、前面は全開に

v4 の設置面積は、「ストロボは箱の中に住む」という前提の上に立っていました。奥行きはストロボ本体・トリガーのレシーバー・反射ゾーンが一列に並んだ長さで（[エントリ 11](#11-小型ストロボでは小さくならない)）、アクセスパネルはそれらに手を届かせるために存在していました。ところが、プリントされた v4 実機での手持ちテストで分かったことがあります。ストロボを箱の中に据えず、ただ開口に構えて白いチャンバーへ発光させても、フィルム開口の光は目視で十分に均一だったのです。校正された測定ではありませんし、[エントリ 7](#7-均一性を判定する前にフラットフィールド補正) のフラットフィールドの規律も引き続き有効です。それでも、ストロボ格納部に引導を渡すには十分でした。光を混ぜているのは白い壁であって、ストロボの周りの囲いではなかったのです。

v5 では、ストロボは最初から最後まで箱に入りません。机の上に寝かせ、発光部を**全開の前面（オープンフロント）**に突き当てて、チャンバーの中へ発光させます。前壁はそもそも存在しません。ZENIKO T1 のレシーバーもストロボと一緒に箱の外に残ります。電波の通りが良く、電池交換で何かを開ける必要もありません。特定の 1 台のための車庫だったものは、ただ光を混ぜるためのチャンバーになりました。

- 本体の箱は 208 × 273 × 96 mm から **124.8 × 154.8 × 73 mm** へ。プリント材料はおよそ 65 % 減。
- アクセスパネルは削除。箱の中に、手を届かせる相手がもういません。
- **ホットシューのストロボなら何でも使えます。** STL はもう TT560 の寸法を形状に刻んでいません。TT560 は単なる参考機種になりました。
- 最大パーツは長さ 154.8 mm。160 × 160 mm のビルドプレートで全部品が出力できます。旧文書の 220 mm ベッドの注意書きは失効です。

代償として、開いた前面からは環境光が入ります。それでも受け入れました。ストロボの発光量は室内光を圧倒するからです。薄暗い部屋で撮影し、天井照明が開口へ直接差し込まないようにしてください。

**教訓：箱の中へ光を向けるだけなら、その部品を箱の中に置く必要はない。**

### 22. フィルム押さえは交換式インサート方式に収束

v4 はホルダー蓋の裏の押さえリブと 0.4 mm の溝でフィルムを平らにしていました（[エントリ 18](#18-ホルダーを積層ピッチに量子化)・[19](#19-1-層だけの段差をなくす)）。v5 ではこの問いを最初から開け直し、生き残れなかった 3 つの答えを経て着地しました。

- **押さえリブ、まずは持ち越し。** リブは窓の四辺でしかフィルムを拘束できず、全画面の平面性へ向かうガラスというアップグレード路線が手招きし続けていました。
- **持ち上げるガラス蓋。** 窓の上に任意で載せ、コマを送るたびに持ち上げるガラス。テンポで却下です。[エントリ 13](#13-拡散板をフィルムステージの上へ) が受け入れたのはセッションに 1 回で済む代償でした。コマごとにガラスを持ち上げるのは代償を 1 コマごとに払うことで、36 枚撮り 1 本ではワークフロー全体で最も遅い工程になります。
- **フォームによる吊り。** エレメントを蓋の裏のフォームで押さえる案。寿命で却下です。フォームは経年劣化し、予圧は年々抜けていきます。
- **インサートのプラットフォーム。** ホルダー底の外レールが **4.6 mm のエレメント段**を一周持ち、その段に交換式の押さえエレメントを落とし込みます。標準はプリントの**押さえ窓インサート**、アップグレードは 1 枚の**アンチニュートンガラス**です。エレメントは一度据えたら二度と触りません。フィルムは 4.2 mm の受けに載り、エレメントの下面は 4.6 mm。つまり **0.4 mm のチャネル**が四辺にも画面全体にも通り、コマ送りはリーダーをつまんで引き抜くだけです。蓋も開けず、エレメントも持ち上げず、カールは滑り抜けるあいだにエレメントの下面で平らに押さえられます。

CAD 上の数値では、インサート方式でフィルムが窓の中で持ち上がれるのは最大およそ 0.28 mm で、等倍・f/8 での被写界深度およそ ±0.4 mm の中に収まります。ガラス方式なら画面全体に連続で蓋ができます。**64 × 95 × 2 mm** のガラス 1 枚が両フォーマット共通です。135 の底がレールを二重に持つからです。内レールが幅の狭いフィルムを案内し、外レールは 120 の底と同じエレメント段を共有します。インサートはフォーマットごと、ガラスはこの 1 枚だけです。

**教訓：作業者の動作はセッション単位ではなくコマ単位で予算を組む。一度据えたら二度と触らない部品なら、位置もずれない。**

### 23. ねじの全廃

v4 はフィルムステージを 3 本の M6 寸切りボルトの上下ナットで挟み、ボルトはインサートナットにねじ込まれ、ナットを回して水平を出していました（[エントリ 14](#14-縦置き運用のための確実な固定)）。v5 では、寸切りボルト 3 本、ナット 6 個、インサートナット、そして機体のあらゆるねじの嵌め合いまで、その一式を丸ごと削除します。理由は 2 つの確信です。

- **プラスチックにねじを担わせない。** 真鍮のインサートを使っても、ねじの荷重は結局その周りのプラスチックに落ちます。プリントした機械のねじ結合は、どれも摩耗する箇所であると同時に公差の積み重ねです（[エントリ 5](#5-水平調整の荷重を受けられる天面) のポストは、その仕組みに仕えるためだけの機構でした）。
- **水平出しは箱ではなくカメラ側の仕事。** フィルムステージに小さな鏡を置き、ファインダーを覗きます。レンズ自身の反射像が中心に来たとき、センサーはフィルム面と平行です。このひと目の確認は、本当に大事な 2 面を直接そろえ、ついでに箱のプリント公差まで吸収します。ボルトをいくら回しても同じことはできません。ボルトが調整できるのは箱であって、その上のカメラを見ることはできないからです。

ねじが退場したあと、組み立ては重力とマグネットだけです。天板ステージは箱の壁の上に載り、壁の頂の 4 つの**位置決めダボ**が四隅の**ダボ穴**へ落ちて位置が決まります。置き方は 1 通り、締めるものは皆無、組み立てに工具は 1 本も要りません。エントリ 14 の CAUTION は v4 のハードウェアには引き続き有効です。v5 には、そもそもタップを立てるステージ穴が存在しません。

**教訓：調整は誤差が見える場所に置く。箱のねじを回しても結果は見えないが、フィルム面の鏡なら直接確かめられる。**

### 24. 天板とフィルムステージの一体化と薄肉化

v4 試作の請求書（約 1,200 人民元）は、この設計が受け取った中で最も鋭いレビューでした。出力業者は体積に課金します。壁の 1 枚 1 枚が請求項目なのです。v5 はグラム数へ直接切り込みます。

- **壁 2.4 mm・床 3.0 mm**（それまでは 3 と 4）。ねじの嵌め合いが消えたので（[エントリ 23](#23-ねじの全廃)）、締結の荷重を受ける壁も板もありません。シェルの仕事は、立っていること、白いこと、天板ステージの位置を決めること。それだけです。
- **天板とフィルムステージは「天板ステージ」1 部品に統合**です。壁の上に載る 1 枚の板が、ホルダーの受けトレイ・採光窓・アクリルの収まりをすべて持ちます。ビルド最大級のパーツが 1 つ消え、2 部品のあいだの継ぎ目も一緒に消えました。
- **アクリル拡散板は 68 × 118 mm に縮小**（v4 は 110 × 130。旧材はアクリル店で裁ち直して続用できます）。
- **鉄ワッシャーは 10 × 10 mm のスチールシム 4 枚**になり、天板ステージのざぐりに沈んで面一に収まります。

すべてのパーツは引き続きサポートなし・平らな面を下にして出力します。9 ファイル一式の見積もりは **300–350 g** のフィラメントです。ほかの v5 の数値と同じく机上の見積もりですが、次の請求書が答え合わせをしてくれます。

**教訓：プリント体積にも、ほかの寸法と同じように先に予算を 1 行与えておく。**

### 25. マウント済みスライドには専用の板を

マウント済みの 135 スライドは v5 まで対象外でした。紙やプラスチックのマウントはおよそ 1.2 – 3.2 mm の厚みがあり、135 の通り道は 0.4 だからです。すぐ思いつく解決策、つまり 135 の底に 50 × 50 のポケットを掘る案は、見た瞬間に却下されました。ポケットは窓の四辺の受けを削り取ってしまい、受けこそが押さえの仕組みそのものだからです（[エントリ 22](#22-フィルム押さえは交換式インサート方式に収束)）。ストリップ用に受けを埋め戻す詰め物を足せば、部品が 1 つ増えるうえ、フィルム面がプリントされた段ではなく詰め物の座りに委ねられます。

代わりに採用したのは、1 部品で完結する 4 組目のホルダー、`slide-plate-135.stl` です。94 × 120 × 5 の板に、深さ 2.0 の 51.4 mm 角ポケット、その底を貫通する 26 × 38 の窓、貫通しない指掛け溝 2 つ。ホルダー底が立つ場所にそのまま立つので、135 のホルダー 1 組には一切手を触れません。蓋もマグネットもガラスもありません。マウントは硬く、箱は水平なので、ポケットが位置を決め、重力が押さえます。フィルム面はマウントに応じて約 82.6 – 83.6 に来ます。ストリップのフィルム面 83.2 からピントを合わせ直せる範囲で、6×6 マスクがすでに求めているのと同じ対応です。

**教訓：新しいフォーマットが押さえの形状を共有できないなら、共有部品に妥協を持ち込むのではなく、専用の部品を与える。**

### 26. 同じ本体での 4×5 を、実験として

設計 §10 は 4×5 をより大きな箱に取っておきました。窓に v1 の拡散マージンを足すと、本体はおよそ 165 × 186 mm、ビルドプレートは 220 クラスになります。それを導出する前に、より安い問いを立てました。いまある本体の上で、4×5 は何を要するのか。答えは部品 2 点です。同じ外形と 4 つのダボ穴を持つ 2 つ目の天板ステージが、102 × 126 の窓、106 × 130 × 2 の乳白板用の溝、112.6 × 138.6 のトレイを持ち、そのトレイに立つシートプレートが 101.6 × 127 のシートを 102.2 × 127.6 のポケットで受けて、97 × 121 の窓の上に置きます。押さえエレメントはなし。0.25× では f/8 の被写界深度がおよそ 8 – 10 mm、135 の場合の 10 倍あるので、シートの反りは見えません。箱のほかの部分は何も変わらず、すべて 160 × 160 のビルドプレートで出力できます。

手放したのは拡散マージンです。壁まで 29 と 27.5 ではなく、9 と 12 mm。それが勾配として現れるかどうかは分かりません。v1 自身の均一性が分かっていないのとまったく同じです。アクリルは変わらず拡散し、フラットフィールド補正は変わらずあり、大きな箱は次の一手として残ります。このステージを同じ本体の上の実験として出すのは、確かめるのにファイル 2 つとアクリル 1 枚のカットで済み、推測のために本体を丸ごと作り直す必要がないからです。

**教訓：箱を大きくする前に、いまある箱に何ができるかを確かめる。部品 2 点の実験は、導出し直した筐体より安い。**

## あえてやらなかったこと

検討に値するとして俎上に載せ、そのうえで見送った 4 つの変更です。このどれかを提案しようとしているなら、まずここから読んでください。

*[LED パネル](#ストロボの代わりに高演色-led-パネル) · [2 枚目の拡散板](#2-枚目の拡散板) · [天板の一体化](#天板を本体と一体化する) · [換気](#換気)*

### ストロボの代わりに高演色 LED パネル

箱を有意に小さくできる唯一の変更です（高さ約 100 mm、約 4 リットル）。LED パネルはそれ自体がすでに面光源で、光を混ぜる距離をほとんど必要としないからです。

それでもストロボを採って、この案は見送りました。閉じた箱の中ではストロボの発光そのものが露光のすべてなので、振動もシャッターショックも問題でなくなり、ベース ISO・f/8 でも出力に余裕が残ります。とはいえアクセスパネルは、フィルム面もカメラの高さも動かさずに、後から LED パネルへ換装できる寸法にしてあります。

### 2 枚目の拡散板

拡散板が 2 枚あれば均一性は上がります。現在の設計で 2 枚目とそのチャンバーを復活させると、高さが約 **43 mm** 増えます。再検討に値するのは、4×5 版を作るとき、あるいはポジに対して 1 枚では力不足だと分かったときだけです。

### 天板を本体と一体化する

出力できるかどうかだけで却下しました。閉じた中空の箱は、拡散チャンバーの天井に 202 × 267 mm の無支持スパンを作ります。FDM ではこれを[ブリッジ (bridging)](glossary.ja.md#ブリッジ-bridging)できません。内部にサポートを詰めるしかありませんが、それは 190 × 76 mm のアクセス開口からしか取り出せず、光学的な天井に傷跡が残ります。ほかの面を下にして出力しても、問題が移動するだけです。

そもそも得られるものがありません。天板はもともと締結具なしで付いており、そのスカートが遮光を担っています。継ぎ目のない案が 1 つだけ本当に成立します。天板をビルドプレートに置き、そこから壁を立ち上げ、アクセスパネルを床面へ移す構成です。ただしこれは天面の継ぎ目を底面の継ぎ目に替えるだけで、しかも全体をモデリングし直すことになります。天板が緩く感じるなら、一体化するより、スカートに小さなタッピンねじを 2 本通すほうがずっと優れています。

### 換気

プロトタイプでは省きました。低いデューティサイクルで使うスピードライトはほとんど発熱しませんし、穴はどれも光漏れの候補です。セッションが熱を持つようなら、ロールとロールのあいだにアクセスパネルを抜いてください。

---

← [設計](design.ja.md#設計) · [ドキュメント一覧](../README.ja.md#ドキュメント) · [用語集](glossary.ja.md#用語集) →

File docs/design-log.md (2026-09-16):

# Design log

**English** · [简体中文](design-log.zh-CN.md) · [日本語](design-log.ja.md)

> Why NeoBox ended up this shape: twenty-six decisions in the order they were taken, and the four ideas that were considered and turned down. Read it before you modify anything.

**Contents:** [How to read this log](#how-to-read-this-log) · [Phase 1: the first draft did not close](#phase-1-the-first-draft-did-not-close) · [Phase 2: from 32 litres to about 5](#phase-2-from-32-litres-to-about-5) · [Phase 3: removing everything unnecessary](#phase-3-removing-everything-unnecessary) · [Phase 4: the flash leaves the box](#phase-4-the-flash-leaves-the-box) · [Things deliberately not done](#things-deliberately-not-done)

## How to read this log

A note on numbering first: v1 to v5 in this log are internal draft numbers. The fifth draft is what shipped as the public release, version 1; the printed prototype discussed below is internal draft 4.

The design moved through three phases: repairing a first draft whose arithmetic did not close, collapsing a tall upright box into a flat horizontal one, and then deleting everything that turned out to be unnecessary.

```mermaid
flowchart LR
    A["First draft<br/>upright, two diffusers"] --> B["Phase 1<br/>arithmetic repaired"]
    B --> C["Phase 2<br/>one diffuser, flash lying flat"]
    C --> D["Phase 3<br/>parts deleted, plywood to print"]
    D --> E["Released<br/>208 × 273 × 96 mm"]
```

> [!NOTE]
> Nothing here was settled by building anything. **The box has never been printed, photographed or evenness-tested.** Every decision below was reached in CAD and arithmetic, or in correspondence with a print vendor. Dimensions quoted are the released geometry; figures from superseded revisions are not repeated, because they were never re-verified.

Each entry is a heading, so any of them can be linked from elsewhere, for example `design-log.md#18-layer-quantised-holders`.

## Phase 1: the first draft did not close

The first specification was an upright box that stood the flash on its foot under two diffuser layers. None of it survives, but five of the rules it produced do.

*Entries: [1](#1-the-height-was-arithmetically-impossible) · [2](#2-unframed-diffusers-leak) · [3](#3-all-white-was-wrong-above-the-last-diffuser) · [4](#4-a-centring-stop-for-the-flash-head) · [5](#5-a-top-that-could-carry-the-levelling-load) · [6](#6-light-labyrinth-vents-instead-of-straight-holes) · [7](#7-flat-field-before-judging-evenness) · [8](#8-the-large-format-provision)*

### 1. The height was arithmetically impossible

The draft called for three stacked air gaps: flash head to the first diffuser, a mixing space between the two diffusers, and a black chamber above the second. Added up, they came to more than the interior height the same document declared, and that budget did not include the flash itself.

The fix was not a number, it was a method.

> [!IMPORTANT]
> **Build the height by summing measured layers from the floor upward, then read off the outer dimension. Never fix the outer height first and back-calculate the layers.** The released stack is derived that way; it is set out in [design.md](design.md#2-dimension-chain).

### 2. Unframed diffusers leak

The diffuser sheets were smaller than the cavity they sat in, so light could pass around the edges instead of through them. Each diffuser was given a full-width carrier panel with only the emitting window open.

**Lesson: if light can get around a diffuser, the diffuser is not doing anything.**

### 3. All-white was wrong above the last diffuser

White walls above the final diffuser bounce stray light back down onto the film and lower contrast. That section became matte black. The rule survives into the released design: everything above the diffuser is black, everything below it is bare white filament.

**Lesson: white below the diffuser, black above it.**

### 4. A centring stop for the flash head

A speedlight lying down does not place its head on the centreline of the box, and the hot spot follows the head. The draft gained a stop that put the head where the optics assumed it was. In the released box the same job is done procedurally: draw a line on the floor around the flash so that it returns to the same place every time.

**Lesson: if a part's position changes the light, give it either a location feature or a mark.**

### 5. A top that could carry the levelling load

The draft carried the levelling screws directly on a thin sheet top, which they would have crushed. The top became a thicker panel with metal load points. The released top cover keeps the principle: the three heat-set inserts sit in dedicated posts underneath, not in the 4 mm cover plate itself.

**Lesson: a levelling point is a load path. Put material behind it.**

### 6. Light-labyrinth vents instead of straight holes

A straight ventilation hole in a light box is a light leak with a job title. The draft's vents became labyrinths. The released design goes further and has none at all; see [Ventilation](#ventilation) below.

**Lesson: before cutting a hole for heat, work out what it does to the light.**

### 7. Flat-field before judging evenness

The draft's evenness target confused two different things: the lens's own vignetting and real unevenness in the light source. [Flat-field correction](glossary.md#flat-field-correction) (photographing the bare lit surface and using that frame to divide out the falloff) separates them. The target for the source itself is **±0.1 [EV](glossary.md#ev) corner to corner**, and it applies after that correction, not before.

**Lesson: state what a tolerance is measured against, or nobody can meet it.**

### 8. The large-format provision

The reservation for a future 4×5 version carried the same missing-flash-height error as the main box, so it was recalculated from the layer sum rather than scaled. It remains a reservation only: the released box covers 35 mm and 120 film up to 6×9 through a 100 × 120 mm aperture.

## Phase 2: from 32 litres to about 5

Three decisions took the design from an upright cabinet to something that sits on a desk.

*Entries: [9](#9-two-diffusers-became-one) · [10](#10-upright-became-lying-flat) · [11](#11-smaller-flashes-do-not-help)*

### 9. Two diffusers became one

Two diffusing layers with a mixing space between them is the textbook way to build an even emitting surface, and it is most of why the first draft was so tall. It was cut to one sheet.

That choice is **not** validated by any measurement of this box. It is carried across from the author's existing camera-scanning workflow, which lays film directly on a light pad with a single diffusing surface close underneath. The mixing distance below the remaining sheet was then increased rather than inherited: the gap in the two-layer design existed to feed the second layer, and copying it across would have printed the flash's hot spot straight onto the emitting surface.

**Lesson: a dimension copied out of a design you have just deleted half of is a leftover; re-derive it before trusting it.**

### 10. Upright became lying flat

The box was still hostage to the flash standing on its foot plus a vertical mixing distance, while the footprint was a leftover from the two-diffuser era. Laying the flash flat and firing it sideways moved the mixing distance into the depth of the box: depth the flash body already occupied.

That single change took the volume from about **32 litres to about 5**; the released box is 208 × 273 × 96 mm, about 5.4 litres. An interim revision turned the light with a 45° reflector plate, which was itself deleted later ([entry 16](#16-fasteners-and-internal-parts-deleted)).

**Lesson: when a box is too tall, find the dimension that is doing two jobs and turn it sideways.**

### 11. Smaller flashes do not help

Four alternatives were checked before the layout was frozen: the Godox TT350, the iM30Pro, the iT30Pro and the KEKS KF-01. None of them shrinks the box meaningfully.

<details>
<summary>Why a smaller flash does not make a smaller box</summary>

In an upright layout the mixing distance is set by geometry, not by the flash: a thought experiment with a zero-thickness flash still loses to the horizontal layout. In the horizontal layout the width is set by the aperture and the film stage (208 mm, whatever flash is inside) and the depth is set by the flash body, the trigger receiver and the reflection zone lying end to end. A smaller flash buys no volume and costs power headroom and recycle time.

</details>

The design was therefore fixed on hardware the author already owned: a NEEWER TT560 speedlight and a ZENIKO T1 trigger set. The published STLs fit that flash only. The formulas in [design.md](design.md#generalising-to-another-flash) give the numbers for a different one, but they do not resize the files.

**Lesson: find the dimension that actually sets the size before optimising the part you happen to be holding.**

## Phase 3: removing everything unnecessary

Nine entries, three of them provoked by a print vendor reading the drawings more carefully than the author had.

*Entries: [12](#12-the-mid-level-carrier-panel-and-black-chamber-came-out) · [13](#13-the-diffuser-moved-above-the-film-stage) · [14](#14-positive-fastening-for-use-on-end) · [15](#15-plywood-became-3d-printing) · [16](#16-fasteners-and-internal-parts-deleted) · [17](#17-the-film-run-out-corridor) · [18](#18-layer-quantised-holders) · [19](#19-no-single-layer-steps) · [20](#20-orientation-instructions-must-name-what-the-operator-can-see)*

### 12. The mid-level carrier panel and black chamber came out

With one diffuser left, the carrier panel that had framed the second one had nothing to frame, and the black chamber above it had nothing to line. Both were deleted, the diffuser went directly over the aperture, and the cavity became uniformly white. The 135 and 120 film holders were designed and released in the same revision.

**Lesson: deleting a part usually orphans the parts that existed to support it. Check downstream before re-detailing.**

### 13. The diffuser moved above the film stage

The opal acrylic diffuser was lifted out of the enclosure and onto the film stage, resting over the aperture and held flat by the weight of the film holder. Film-to-diffuser distance became about **4.3 mm**, which matches the light-pad geometry the design was modelled on.

That is a dust trade. A particle on the diffuser projects as a soft blob about 0.2 mm across at the film plane at 0.43× [magnification](glossary.md#magnification-ratio) (the 6×6-on-full-frame case) and f/8: invisible on inverted negatives, visible on slides. It was accepted because the cost lands in a routine rather than in a tolerance: blow both faces of the diffuser and the [film gate](glossary.md#film-gate) at the start of every session. The anti-direct-light baffle and its brackets went at the same time.

> [!NOTE]
> That revision also replaced the interior liners with white paint on the panels. That belonged to the plywood construction and did not survive [entry 15](#15-plywood-became-3d-printing). **Do not paint the inside of the printed box**: the interior is bare white filament by design.

**Lesson: moving a part to where it works optically can be worth a maintenance cost, provided the cost lands in a routine.**

### 14. Positive fastening for use on end

For the box to work stood on end, every gravity-located part had to become positively held: four magnets in each holder base pulling onto steel washers on the film stage, and the film stage itself clamped between a lower nut and an upper nut on three studs screwed into the top cover's heat-set inserts.

This is where a real error was caught. The stage holes had been specified as threaded. A threaded plate on a stud of the same pitch is a differential screw: the plate and the stud advance together, so the height cannot be set at all. They became Ø6.5 mm clearance holes.

> [!CAUTION]
> Never tap the three film-stage holes. Ø6.5 mm clearance holes are mandatory: a tapped plate cannot be levelled, and re-drilling one afterwards usually ruins the plate.

**Lesson: check a fastening scheme for kinematics, not only for strength.**

### 15. Plywood became 3D printing

A laser-cut plywood shell with tab-and-slot joints was drawn, then abandoned once it was clear the intent had been a printed box all along.

Printing collapsed the walls to 3 mm and the floor to 4 mm, removed all interior painting, replaced threaded inserts in wood with heat-set brass, and made the cable gland and the access opening part of the print rather than operations after it. No internal optical dimension changed. The plywood DXFs are still in `cad/legacy-plywood/`, but they are a historical record of a partial panel set, **not a buildable alternative**. There is no plywood route to this box.

**Lesson: change the process while the optics are still numbers rather than parts.**

### 16. Fasteners and internal parts deleted

Six M3 posts holding the top cover down became a top cover with a 10 mm skirt that simply drops on: the skirt is both the location feature and the light trap, and no screws hold the enclosure together at all.

Then the internal parts went one after another: the drawer tray (the flash lies on the floor), its brackets, the strap that held the flash, and finally the 45° reflector plate, because the far wall already performs the turn and every internal part is one more thing to align. What remains in the default build is **eight printed parts**, one opal acrylic diffuser and three studs: nine STL files including the optional 6×6 mask.

**Lesson: a deleted part costs nothing to print and nothing to align.**

### 17. The film run-out corridor

The first fit-check of the integrated film stage found two blocks sitting centred on the holder ends (exactly across the channel mouths) with their tops just below the film plane. A film strip could never have been threaded through. The same sweep found the front stud rising to film height in the middle of the path the film has to travel.

Both were moved rather than shrunk. The blocks became four corner blocks at |x| = 40–60 mm, which leaves both channel mouths fully open, and the front stud moved to (45, −100) mm relative to the stage centre. The constraint is now permanent: nothing may rise near film height inside |x| < 31 mm (half the width of 120 film, which is about 62 mm across) beyond the ends of the holder. That volume is the [run-out corridor](glossary.md#run-out-corridor).

**Lesson: clearance between parts is not enough. The moving workpiece needs its own swept corridor, treated as a part.**

### 18. Layer-quantised holders

The print vendor measured the holder's exposed z-steps and pushed back on the 0.12–0.16 mm [layer heights](glossary.md#layer-height) the drawings asked for: at their default 0.2 mm layers, they said, the steps would not come out cleanly. They were right, and the fault was in the geometry rather than the printer. A 0.5 mm step is not a multiple of any common layer height: it slices to two and a half layers and rounds up or down at the slicer's discretion.

Rather than argue about calibration, every z-feature was requantised to a multiple of 0.2 mm, which took the channel to **0.4 mm** without moving the film plane. The windows grew about 0.5 mm per side in the same pass (25 × 37 mm for 135, 57 × 85 mm for 120) to absorb camera-gate variance and printer XY tolerance. Crop in post.

**Lesson: a dimension the manufacturing process cannot represent is a design bug, not a vendor limitation.**

### 19. No single-layer steps

Vendor round three. The features still left at 0.2 mm (the land relief on the holder bases, the pressure strips under the holder lids) are exactly one layer tall at the default layer height. Printable in theory, but a single-layer step is hostage to first-layer squish and flow calibration, and the vendor asked for more height.

All of them now measure 0.4 mm, two layers, without disturbing anything that matters. The base plate thinned to 3.8 mm so that the land tops (the film plane) stayed put while the relief doubled; the lid plate and the rails rose together so that the pressure strips deepened while the channel stayed 0.4 mm. The strips also gained 0.3 mm of side clearance to the rails so the holder lid cannot wedge. Film plane, channel, windows, outline and magnet spacing: all unchanged.

**Lesson: no exposed z-step under two layers; a single layer cannot be trusted to come out at height.**

### 20. Orientation instructions must name what the operator can see

The vendor asked which face the drawings' orientation note (a first-revision phrase naming the channel side, since deleted from every document) actually referred to. Re-deriving the answer from print physics exposed the note itself as wrong: it would have stood the holder base on its two rail crests and left the film-bearing lands hanging over air, so the one surface that has to be flat would have been built on [supports](glossary.md#supports).

The correct orientation for every holder part is flat face down with the features growing upward and no supports at all. But a slicer will not get there by itself: `film-holder-*-lid.stl` loads with the pressure strips down and must be rotated 180° about X after import. Every vendor script now places parts by a feature the operator can see ("the face with the two long ridges goes up") and states support locations explicitly. The per-part cards in [printing.md](printing.md#the-twelve-parts) follow the same rule.

**Lesson: write orientation instructions around a feature the operator can see and point at.**

## Phase 4: the flash leaves the box

Phase 3 closed a three-phase history at the released 208 × 273 × 96 mm box. Then the box got built: a vendor printed v4 for about CN¥1,200, and hand-held experiments with that unit reopened the design. The four entries below, added 2026-08-14, take it to **v5**.

> [!NOTE]
> The note in [How to read this log](#how-to-read-this-log) predates these entries and now needs one amendment: **v4 has been printed and handled. v5 has not.** v5 has never been printed, photographed or evenness-tested; apart from the hand-held v4 observations reported below, every v5 figure is CAD and arithmetic (`cad/neobox.blend`).

*Entries: [21](#21-the-flash-moved-outside-and-the-front-opened-fully) · [22](#22-flattening-converged-on-an-insert-platform) · [23](#23-the-design-went-screwless) · [24](#24-the-cover-absorbed-the-film-stage-and-the-print-thinned)*

### 21. The flash moved outside and the front opened fully

Everything about v4's footprint assumed the flash lived inside: the depth was the TT560 body, the trigger receiver and the reflection zone lying end to end ([entry 11](#11-smaller-flashes-do-not-help)), and the access panel existed to reach them. Then a hand-held test with the printed v4 unit showed that a flash merely held at the opening, firing into the white cavity, lit the film aperture just as evenly by eye. Not a calibrated measurement (the flat-field discipline of [entry 7](#7-flat-field-before-judging-evenness) still applies), but enough to condemn the flash bay: the mixing happens at the white walls, not around the flash body.

In v5 the flash never enters the box. It lies on the desk with its head against a **fully open front** (the front wall simply does not exist), and the ZENIKO T1 receiver stays outside with it, where the radio signal is better and a battery change opens nothing. What used to be a garage for one specific flash is now a mixing cavity and nothing else:

- The main box shrinks from 208 × 273 × 96 mm to **124.8 × 154.8 × 73 mm**, about 65% less printed material.
- The access panel is deleted; there is nothing inside left to reach.
- **Any hot-shoe flash fits.** The STLs no longer encode the TT560's dimensions; it is now just the reference model.
- The largest part is 154.8 mm long, so a 160 × 160 mm bed prints everything. The old 220 mm bed warning is obsolete.

The price is that the open front admits ambient light. Accepted, because the flash pulse dwarfs room light: work in a dim room, and keep ceiling lights from shining into the opening.

**Lesson: a part that only needs to shine into the box can sit outside it.**

### 22. Flattening converged on an insert platform

v4 flattened film with pressure strips under the holder lid and a 0.4 mm channel ([entries 18](#18-layer-quantised-holders) and [19](#19-no-single-layer-steps)). v5 reopened the question from scratch, and it took three answers that did not survive to reach the one that did:

- **Pressure strips, carried over.** They constrain the film only at the window edges, and a glass upgrade path towards full-frame flatness kept suggesting itself.
- **A glass lid you lift.** An optional sheet laid over the window and removed to advance the film. Rejected on cadence: [entry 13](#13-the-diffuser-moved-above-the-film-stage) accepted a cost that lands once per session; lifting glass lands the cost once **per frame**, and over a 36-exposure roll it becomes the slowest step in the whole workflow.
- **Foam suspension.** The flattening element pressed down by a foam pad in the lid. Rejected on lifetime: foam ages, and the preload decays with it.
- **The insert platform.** The holder bases' outer rails carry a **4.6 mm element ledge**, and onto it drops an interchangeable flattening element: the printed **pressure-window insert** by default, a single sheet of **anti-Newton glass** as the upgrade. The element seats once and is never touched again: the film rides the lands at 4.2 mm, the element's underside sits at 4.6 mm, so a **0.4 mm channel** runs under all four edges and right across the frame, and the film advances by pulling the leader. No lid opened, no element lifted, the curl pressed flat as it slides through.

The numbers, from CAD: with the insert the film can rise at most about 0.28 mm inside the window, within the roughly ±0.4 mm depth of field at 1:1 and f/8; with the glass the cap is continuous across the whole frame. One **64 × 95 × 2 mm** sheet serves both formats, because the 135 base carries two rail sets: inner rails to guide the narrow film, outer rails sharing the same ledge as the 120 base. The insert exists per format; the glass is one part.

**Lesson: budget the operator's motions per frame, not per session; a part that is set once and never handled again cannot drift.**

### 23. The design went screwless

v4 clamped its film stage between locknuts on three M6 studs screwed into heat-set inserts, and was levelled by turning them ([entry 14](#14-positive-fastening-for-use-on-end)). v5 deletes all of it: the three studs, the six nuts, the inserts, and with them every threaded interface in the machine. Two convictions drove the deletion:

- **Plastic should not carry threads.** Even with brass inserts, the thread's load ends up in the plastic around it; every threaded joint in a printed machine is a wear point plus a tolerance stack (the posts of [entry 5](#5-a-top-that-could-carry-the-levelling-load) were machinery that existed only to serve one).
- **Levelling belongs at the camera, not the box.** Set a small mirror on the film stage and look through the viewfinder: when the reflection of the lens sits centred, the sensor is parallel to the film plane. That one check aligns the pair that actually matters and absorbs the box's print tolerances on the way, something no amount of stud-turning could do, because the studs could only ever adjust the box, never see the camera above it.

With screws gone, assembly is gravity and magnets. The cover-stage seats on the wall tops, located by four **tenons** on the walls dropping into **notches** in its corners: one way to sit, nothing to tighten, no tool anywhere in the build. The CAUTION in entry 14 still stands for v4 hardware; v5 has no stage holes to tap.

**Lesson: put the adjustment where the error is visible; the mirror check reads the camera-to-film alignment directly, which the studs never could.**

### 24. The cover absorbed the film stage and the print thinned

The invoice for the v4 prototype (about CN¥1,200) was the sharpest review the design ever received: a print vendor charges for volume, so every wall is a line item. v5 goes after the grams directly:

- **Walls 2.4 mm, floor 3.0 mm** (down from 3 and 4). With every threaded interface gone ([entry 23](#23-the-design-went-screwless)), no wall or plate carries a fastener load any more; the shell only has to stand, stay white and locate the cover-stage.
- **The top cover and the film stage merged into one part, the cover-stage:** a single plate seated on the walls that carries the holder tray, the light window and the diffuser recess. One of the largest parts in the build simply no longer exists, and neither does the seam between the two.
- **The diffuser shrank to 68 × 118 mm** (v4: 110 × 130; a v4 sheet can be cut down by the acrylic shop and reused).
- **The steel washers became four 10 × 10 mm shims**, sunk flush into counterbores in the cover-stage deck.

Everything still prints support-free, flat face down. The whole nine-file set is estimated at **300–350 g** of filament: an estimate from CAD like every other v5 figure, but one the next invoice will check.

**Lesson: printed volume needs a budget of its own, like any other dimension.**

### 25. Mounted slides: a plate of their own

Mounted 135 slides were out of scope through v5: a card or plastic mount is about 1.2 – 3.2 mm thick and the 135 channel is 0.4. The obvious fix, a 50 × 50 pocket cut into the 135 base, was rejected on sight: the pocket would take out the land on all four sides of the window, and the land is the whole flattening system ([entry 22](#22-flattening-converged-on-an-insert-platform)). A filler plug to restore the land for strips would add a part and hang the film plane on a plug's seating instead of a printed step.

What shipped instead is a fourth holder set that is one part: `slide-plate-135.stl`, a 94 × 120 × 5 plate with a 51.4 mm square pocket 2.0 deep, a 26 × 38 window through its floor and two blind finger wells. It stands in the tray where a holder base stands, so the 135 set is not touched at all. It has no lid, no magnets and no glass, because a mount is rigid and the box is horizontal: the pocket locates and gravity holds. The film plane lands at about 82.6 – 83.6 depending on the mount, within refocusing distance of the strip plane at 83.2, the same accommodation the 6×6 mask already asks for.

**Lesson: when a new format cannot share the flattening geometry, give it its own part rather than a compromise in the shared one.**

### 26. 4×5 on the same body, as an experiment

Design § 10 had reserved 4×5 for a bigger box: a window with v1's mixing margins, which means a body about 165 × 186 mm and a 220-class bed. Before deriving that, the cheaper question was asked: what does 4×5 cost on the body that exists? Two parts. A second cover-stage with the same outline and four notches carries a 102 × 126 window, a recess for a 106 × 130 × 2 opal sheet and a 112.6 × 138.6 tray; a sheet plate in that tray takes the 101.6 × 127 sheet in a 102.2 × 127.6 pocket over a 97 × 121 window. No pressure element: at 0.25× the depth of field at f/8 is roughly 8 – 10 mm, ten times the 135 case, so a sheet's curl is invisible. Nothing else in the box changes, and everything still prints on a 160 × 160 bed.

What it gives up is the mixing margin: 9 and 12 mm to the walls instead of 29 and 27.5. Whether that shows as a gradient is unknown, exactly as v1's own evenness is unknown; the acrylic still diffuses, flat-field correction still exists, and the bigger box stays on the table as the second step. The stage ships as an experiment on the same body because it costs two files and one acrylic cut to find out, and a whole new body to guess.

**Lesson: before scaling the box, find out what the existing box can do; a two-part experiment is cheaper than a derived enclosure.**

## Things deliberately not done

Four changes that were considered on their merits and turned down. If you are about to propose one of these, start here.

*[LED panel](#a-high-cri-led-panel-instead-of-a-flash) · [second diffuser](#a-second-diffuser) · [fusing the top cover on](#fusing-the-top-cover-into-the-main-body) · [ventilation](#ventilation)*

### A high-CRI LED panel instead of a flash

The only change that would make the box meaningfully smaller (about 100 mm tall and roughly 4 litres), because an LED panel is already an area source and needs almost no mixing distance.

It was declined in favour of the flash. Inside a closed box the flash pulse is the entire exposure, so vibration and shutter shock stop mattering, and there is power in reserve at base ISO and f/8. The access panel is nevertheless sized so that an LED panel could be retrofitted later without moving the film plane or the camera height.

### A second diffuser

Two diffusers would improve uniformity. Restoring the second sheet and its chamber costs about **43 mm** of height in the current design. Worth reconsidering only for a 4×5 version, or for slide film if a single sheet proves marginal.

### Fusing the top cover into the main body

Rejected on printability alone. A closed hollow box puts a 202 × 267 mm unsupported ceiling over the cavity, which FDM cannot [bridge](glossary.md#bridging). It would need internal supports that could only be extracted through the 190 × 76 mm access opening, leaving scars across the optical ceiling. Printing on any other face just moves the problem.

The saving would be nil in any case: the top cover already attaches without fasteners, and its skirt is the light trap. One seam-free variant would genuinely work (print with the top plate on the build plate, walls rising from it, and the access panel moved to the floor), but it trades a top seam for a bottom seam and means remodelling everything. If the top cover ever feels loose, two small self-tapping screws through the skirt beat fusing it.

### Ventilation

Omitted in the prototype. A speedlight at low duty cycle produces little heat, and every hole is a potential light leak. Pull the access panel between rolls if a session runs hot.

---

← [Design](design.md#design) · [Documentation index](../README.md#documentation) · [Glossary](glossary.md#glossary) →

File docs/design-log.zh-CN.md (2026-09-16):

# 设计日志

[English](design-log.md) · **简体中文** · [日本語](design-log.ja.md)

> NeoBox 为什么长成这样：按决策发生的顺序记录二十六项决定，以及四个经过权衡后被否决的想法。动手改造之前请先读这一篇。

**目录：** [如何阅读本日志](#如何阅读本日志) · [阶段一——初稿的账根本算不拢](#阶段一初稿的账根本算不拢) · [阶段二——从 32 升到约 5 升](#阶段二从-32-升到约-5-升) · [阶段三——删掉一切非必需](#阶段三删掉一切非必需) · [阶段四——闪光灯走出箱体](#阶段四闪光灯走出箱体) · [特意没有做的事](#特意没有做的事)

## 如何阅读本日志

先说编号：本日志里的 v1 到 v5 是内部草案编号。第五版草案就是对外发布的正式版 v1；下文提到的打印原型机是内部第 4 版。

设计走过三个阶段：修复一份账算不拢的初稿；把高高的立式箱压扁成扁平的卧式箱；再把事后证明并不必要的东西一件件删掉。

```mermaid
flowchart LR
    A["初稿<br/>立式、双层扩散板"] --> B["阶段一<br/>把算不拢的账修好"]
    B --> C["阶段二<br/>单层扩散板、闪光灯放平"]
    C --> D["阶段三<br/>删零件、合板改打印"]
    D --> E["定稿<br/>208 × 273 × 96 mm"]
```

> [!NOTE]
> 这里的每一条结论都不是靠做出实物得到的。**这只箱子从未被打印、拍照或实测过均匀度。** 以下所有决定都是在 CAD 与算术里、或者在与打印服务商的往来中得出的。文中引用的尺寸都是定稿几何；被取代的旧改版里的数字不再重复，因为那些数字从未重新核验过。

每一个条目都是一个标题，所以任何一条都可以从别处链接过来，例如 `design-log.zh-CN.md#18-夹子按层高量化`。

## 阶段一——初稿的账根本算不拢

最初的规格是一只立式箱：闪光灯竖着立在两层扩散板下面。那个形态一点都没留下来，但它催生的五条规则留下来了。

*收录条目：[1](#1-高度在算术上就不成立) · [2](#2-没有围板的扩散板会漏光) · [3](#3-最后一层扩散板以上用白色是错的) · [4](#4-给灯头加一个居中挡块) · [5](#5-撑得住调平载荷的顶板) · [6](#6-用迷宫式通风口取代直通孔) · [7](#7-判断均匀度之前先做平场校正) · [8](#8-大画幅预留)*

### 1. 高度在算术上就不成立

初稿把三段气隙叠在一起：灯头到第一层扩散板、两层扩散板之间的混光空间、第二层以上的黑腔。加起来已经超过同一份文档自己宣称的内净高，而且这笔预算里根本没有算上闪光灯本身。

修正的不是一个数字，而是一套方法。

> [!IMPORTANT]
> **高度要从底板往上，把实测的各层相加得出，然后再读出外形尺寸。绝不允许先定外形高度再倒推分层。** 定稿的层叠就是这样推出来的，[design.zh-CN.md](design.zh-CN.md#2-尺寸链) 里有完整列表。

### 2. 没有围板的扩散板会漏光

扩散板比它所在的腔体小，于是光可以绕过板边走，而不是穿过板。每层扩散板都补上了整幅载板，只留出发光的那块面积。

**教训：光要是能绕过扩散板，这块板就等于没装。**

### 3. 最后一层扩散板以上用白色是错的

最后一层扩散板以上的白壁，会把杂光反射回胶片、压低反差。那一段改成了哑光黑。这条规则一直活到定稿：扩散板以上一律是黑的，以下一律是裸露的白色耗材。

**教训：扩散板以下用白，以上用黑。**

### 4. 给灯头加一个居中挡块

闪光灯平躺时，灯头不会落在箱子的中心线上，而热点跟着灯头走。初稿因此加了一个挡块，把灯头放到光学设计假定它所在的位置上。定稿里同一件事改用流程来做：沿着闪光灯的轮廓在底板上画一圈线，让它每次都回到同一个位置。

**教训：位置会改变光的零件，要么给它一个定位特征，要么给它一个记号。**

### 5. 撑得住调平载荷的顶板

初稿把调平螺丝直接压在一块薄板顶面上，螺丝会把它压陷。顶面改成了带金属承力点的厚板。定稿的顶盖保留了这条原则：三个热熔铜螺母装在顶盖下方专门的柱子里，而不是装在 4 mm 厚的盖板本身上。

**教训：调平点是一条受力路径，背后要有材料。**

### 6. 用迷宫式通风口取代直通孔

在灯箱上开一个直通的通风孔，等于给漏光安了个职称。初稿的通风口改成了迷宫式。定稿更进一步，一个通风口都没有，见下文的[通风](#通风)。

**教训：想在壳体上开孔散热，先想清楚这个孔对光的影响。**

### 7. 判断均匀度之前先做平场校正

初稿的均匀度指标把两件不同的事混为一谈：镜头自身的暗角，和光源本身真实的不均匀。[平场校正](glossary.zh-CN.md#平场校正)（拍摄裸露的发光面，再用这一帧把衰减除掉）能把两者分开。针对光源本身的指标是**四角之间 ±0.1 [EV](glossary.zh-CN.md#ev)**，而且它是在这一步校正之后才成立的，不是之前。

**教训：写清楚一个公差是相对什么测出来的，否则没有人能满足它。**

### 8. 大画幅预留

为将来的 4×5 版本所做的预留，带着和主箱一样漏算闪光灯高度的错误，所以它是按分层相加重新算过的，不是按比例缩放的。它至今仍然只是一个预留：定稿的箱子通过一个 100 × 120 mm 的开口，覆盖 35 mm 胶片和 6×9 以内的 120 胶片。

## 阶段二——从 32 升到约 5 升

三个决定，把设计从一只立柜变成了一件放得上书桌的东西。

*收录条目：[9](#9-双层扩散板变成单层) · [10](#10-从立式到卧式) · [11](#11-更小的闪光灯帮不上忙)*

### 9. 双层扩散板变成单层

两层扩散层、中间隔一段混光空间，这是做出均匀发光面的教科书做法，也是初稿之所以那么高的主要原因。它被削减成了一层。

这个选择**没有**经过对这只箱子的任何实测验证。它是从作者现有的相机翻拍工作流里搬过来的：那套流程把胶片直接放在灯板上，下面紧贴着单一的一层扩散面。剩下这一层下方的混光距离则是加大了，而不是照搬：双层设计里的那段间距是用来给第二层供光的，照抄过来只会把闪光灯的热点直接印在发光面上。

**教训：从一个刚删掉一半的设计里抄来的尺寸只是残留，用之前得重新推一遍。**

### 10. 从立式到卧式

箱子的高度依然被「竖着立的闪光灯 + 垂直方向的混光距离」绑架，而占地面积则是双层扩散板时代的遗留。把闪光灯放平、朝侧面打光，混光距离就转进了箱子的深度方向，而那段深度本来就被灯身占着。

仅这一个改动，就把体积从约 **32 升降到约 5 升**；定稿的箱子是 208 × 273 × 96 mm，约 5.4 升。中间有一版改版用一块 45° 反射板把光转折，那块板后来也被删掉了（[第 16 条](#16-删掉紧固件和内部零件)）。

**教训：箱子太高的时候，去找那个身兼两职的尺寸，把它放倒。**

### 11. 更小的闪光灯帮不上忙

布局定案之前核验过四个替代品：神牛 TT350、iM30Pro、iT30Pro、KEKS KF-01。没有一个能实质缩小箱子。

<details>
<summary>为什么更小的闪光灯换不来更小的箱子</summary>

在立式布局里，混光距离由几何决定，与闪光灯无关：就算做一个厚度为零的闪光灯的思想实验，也仍然赢不了卧式布局。在卧式布局里，宽度由开口和胶片台决定（不管里面装的是哪只灯，都是 208 mm），深度则由闪光灯灯身、触发器接收端和反射区首尾相接决定。更小的灯买不到体积，却要付出功率余量和回电时间。

</details>

设计因此锁定在作者手上已有的器材上：一只 NEEWER TT560 机顶闪，加一套 ZENIKO T1 触发器。**公开的 STL 只适配这一只闪光灯。**[design.zh-CN.md](design.zh-CN.md#换用其他闪光灯) 里的公式能算出换一只灯之后的数字，但公式不会帮你改文件的尺寸。

**教训：在优化你手里正好拿着的那个零件之前，先找出真正决定尺寸的那个尺寸。**

## 阶段三——删掉一切非必需

九个条目，其中三个是打印服务商比作者更仔细地读图纸读出来的。

*收录条目：[12](#12-中层载板与黑腔一起删除) · [13](#13-扩散板移到胶片台上) · [14](#14-为竖着使用而改成确实固定) · [15](#15-木板--3d-打印) · [16](#16-删掉紧固件和内部零件) · [17](#17-胶片的走片通道) · [18](#18-夹子按层高量化) · [19](#19-不留单层台阶) · [20](#20-朝向指示必须说操作员看得见的东西)*

### 12. 中层载板与黑腔一起删除

扩散板只剩一层之后，原本给第二层做框的中层载板没有东西可框了，它上面的黑腔也没有东西可衬了。两者一起删除，扩散板直接盖在开口上，混光腔变成通体白色。135 和 120 胶片夹在同一版里设计并定稿。

**教训：删掉一个零件，通常会让那些为支撑它而存在的零件失去意义。重新细化之前，先检查下游。**

### 13. 扩散板移到胶片台上

乳白亚克力扩散板被从壳体里取了出来，移到胶片台上：搁在开口之上，靠胶片夹自身的重量压平。胶片到扩散板的距离变成约 **4.3 mm**，与本设计所参照的灯板几何一致。

这是一笔灰尘上的交易。落在扩散板上的一颗颗粒，在 0.43× [放大倍率](glossary.zh-CN.md#放大倍率)（也就是全画幅拍 6×6 的情形）和 f/8 下，会在胶片平面上投出一个直径约 0.2 mm 的柔和斑点：反相后的负片上看不出来，正片上看得出来。之所以接受，是因为代价落在一套例行动作上，而不是落在公差上：每次开工先把扩散板两面和[片门](glossary.zh-CN.md#片门)都吹干净。防直射挡板和它的支架也在同一批里删掉了。

> [!NOTE]
> 那一版也用板材直接刷白漆取代了内衬。那属于合板结构，没有活过[第 15 条](#15-木板--3d-打印)。**不要给打印出来的主箱内部刷漆**：内壁按设计就是原色白色耗材。

**教训：把一个零件挪到光学上正确的位置，只要代价落在例行动作里，就值得付这份维护成本。**

### 14. 为竖着使用而改成确实固定

箱子要能立起来用，每一个靠重力就位的零件都必须改成确实被固定住：每个夹底座上的四颗磁铁吸在胶片台的铁垫片上；胶片台本身夹在下螺母与上螺母之间，三根螺杆旋入顶盖的热熔铜螺母。

真正的错误是在这里抓出来的。胶片台的孔原本被指定成螺纹孔。同螺距的螺纹板配上螺杆构成一个差动螺旋：板和螺杆一起前进，高度根本无从设定。它们改成了 Ø6.5 mm 光孔。

> [!CAUTION]
> 绝对不要给胶片台的三个孔攻丝。Ø6.5 mm 光孔是强制要求：攻了丝的板没法调平，事后再扩孔通常会把整块板废掉。

**教训：紧固方案要按运动学来检查，而不只是按强度检查。**

### 15. 木板 → 3D 打印

激光切割、卡扣榫拼接的合板壳画完之后，才认清本意从头到尾就是一只打印出来的箱子，于是废案。

改用打印之后，壁厚收到 3 mm、底板收到 4 mm，内部油漆全部取消，木用螺纹嵌件换成了热熔铜螺母，过线孔和抽口也从打印后的工序变成了打印件本身的一部分。内部光学尺寸一个都没变。合板 DXF 仍留在 `cad/legacy-plywood/`，但那只是一套不完整面板的历史存档，**不是可以照着做的替代方案**。这个箱子没有合板路线。

**教训：趁光学还只是一堆数字、还没变成零件的时候，把工艺换掉。**

### 16. 删掉紧固件和内部零件

压住顶盖的六根 M3 立柱，变成了一只带 10 mm 裙边、直接扣上去的顶盖：裙边既是定位特征又是光陷阱，而且整个壳体再也没有一颗螺丝。

接着内部零件一个接一个消失：抽屉托盘（闪光灯直接躺在底板上）、它的支架、绑住闪光灯的扎带，最后是那块 45° 反射板，因为远端墙壁本来就完成了转向，而每多一个内部零件，就多一样要对齐的东西。默认配置里剩下的是**八个打印件**、一块乳白亚克力扩散板和三根螺杆：含可选 6×6 遮罩在内共九个 STL 文件。

**教训：删掉一个零件，打印它、对齐它的功夫也一并省掉。**

### 17. 胶片的走片通道

一体化胶片台的首次装配审查发现，两个挡块正坐在夹子两端的中央（恰好挡在滑槽口正对面），顶面就在胶片平面下方一点点。片条根本不可能穿进去。同一轮排查还发现，前螺杆在胶片必经的路径正中间立到了胶片高度。

两者都是挪走，而不是缩小。挡块变成了 |x| = 40–60 mm 处的四角挡块，这样两个滑槽口都完全敞开；前螺杆挪到相对胶片台中心的 (45, −100) mm。约束就此固定：在夹子两端之外、|x| < 31 mm 的范围内（31 是半宽，120 胶片约 62 mm 宽），任何东西都不得升到接近胶片高度。该体积就是[走片通道](glossary.zh-CN.md#走片通道)。

**教训：零件之间有间隙还不够。运动的工件需要有它自己的扫掠通道，而且要当成一个零件来对待。**

### 18. 夹子按层高量化

打印服务商实测了夹子上暴露的 z 向台阶，并对图纸要求的 0.12–0.16 mm [层高](glossary.zh-CN.md#层高)提出异议：用他们默认的 0.2 mm 层高，这些台阶打不干净。他们是对的，而且毛病出在几何上，不在打印机上。0.5 mm 的台阶不是任何常用层高的整数倍：它会被切成两层半，向上取整还是向下取整，全看切片器的裁量。

与其争论校准，不如把每一个 z 向特征都重新量化到 0.2 mm 的整数倍，于是滑槽变成 **0.4 mm**，而胶片平面纹丝未动。同一轮里开窗每边放大约 0.5 mm（135 是 25 × 37 mm，120 是 57 × 85 mm），用来吸收相机片门差异和打印机 XY 公差。多出来的边后期裁掉。

**教训：制造工艺表达不出来的尺寸是设计缺陷，不是服务商的局限。**

### 19. 不留单层台阶

服务商的第三轮反馈。仍然停留在 0.2 mm 的那些特征（夹底座上承托的下沉、夹上盖下面的压条）在默认层高下恰好只有一层高。理论上打得出来，但单层台阶完全被首层压扁量和流量校准绑架，服务商希望多给一点高度。

现在它们全都是 0.4 mm、两层，而且一切要紧的东西都没有被动过：底板减薄到 3.8 mm，让承托顶面（也就是胶片平面）保持原位，而下沉翻了一倍；夹上盖的盖板和导轨一起抬高，压条加深而滑槽仍是 0.4 mm。压条对导轨还留了 0.3 mm 的侧向间隙，防止夹上盖卡死。胶片平面、滑槽、开窗、外形、磁铁间距：全部未变。

**教训：暴露的 z 向台阶不得少于两层；只有一层高的特征，打印出来根本靠不住。**

### 20. 朝向指示必须说操作员看得见的东西

服务商问图纸上那条朝向说明（v1 时代点名滑槽那一侧的一句话，如今已从所有文档中删除）到底指的是哪个面。从打印物理重新推导答案，反而暴露出这条说明本身就是错的：照它摆，夹底座会立在两条导轨的脊上，承托胶片的承托面悬在空中：那个唯一必须平整的面，反而要建在[支撑](glossary.zh-CN.md#支撑)上。

所有胶片夹零件的正确朝向都是平面朝下、特征向上生长、全程免支撑。但切片器不会自己找到这个方向：`film-holder-*-lid.stl` 载入时压条朝下，导入后必须绕 X 轴旋转 180°。现在给服务商的每一份文案，都改成按操作员看得见的特征来摆放零件（「带两条长凸条的面朝上」），并明确写出支撑位置。[printing.zh-CN.md](printing.zh-CN.md#十二个零件) 里逐件的卡片也遵循同一条规则。

**教训：朝向指示要落在操作员看得见、能用手指出来的特征上；光报一个面的名字，对方无从下手。**

## 阶段四——闪光灯走出箱体

阶段三在定稿的 208 × 273 × 96 mm 上，为三个阶段的历史画了句号。然后箱子真的被做了出来：v4 由服务商打样，花了约 1200 元；拿着这只实物做的手持实验，又把设计重新掀开。以下四条追加于 2026-08-14，把设计带到 **v5**。

> [!NOTE]
> [如何阅读本日志](#如何阅读本日志)里那条说明写在这些条目之前，如今需要一条修正：**v4 已经被打印出来、拿在手里用过；v5 没有。** v5 从未被打印、拍摄或实测过均匀度；除了下文如实转述的 v4 手持观察之外，v5 的每一个数字都出自 CAD 与算术（`cad/neobox.blend`）。

*收录条目：[21](#21-闪光灯移到箱外前口全开) · [22](#22-压平系统收敛为插片平台) · [23](#23-全机无螺丝) · [24](#24-顶盖与胶片台合并整体减薄降本)*

### 21. 闪光灯移到箱外，前口全开

v4 的占地全部建立在「闪光灯住在箱子里」这个前提上：深度是 TT560 灯身、触发接收端和反射区首尾相接（[第 11 条](#11-更小的闪光灯帮不上忙)），抽口盖板就是为了够到它们才存在的。然后，一次拿着打印出来的 v4 实物做的手持测试表明：把闪光灯只是举在箱口、朝白色腔内打光，片窗上的光凭肉眼看已经足够均匀。这不是一次校准过的测量（[第 7 条](#7-判断均匀度之前先做平场校正)的平场纪律仍然有效），但足以给灯仓判死刑：混光发生在白壁上，而不是发生在灯身周围。

v5 里闪光灯从头到尾不进箱。它平躺在桌面上，灯头怼着**完全敞开的前口**（前壁干脆不存在），ZENIKO T1 接收器随灯留在箱外：信号更好，换电池也不用开箱。过去那间为某一只特定闪光灯修的车库，现在只剩混光腔本身：

- 箱体从 208 × 273 × 96 mm 缩到 **124.8 × 154.8 × 73 mm**，打印材料约省 65%。
- 抽口盖板取消：箱子里已经没有任何要够的东西。
- **任意热靴闪光灯都能用。** STL 不再把 TT560 的尺寸刻进几何里，它如今只是参考机型。
- 最大件长 154.8 mm，160 × 160 mm 的打印床就能打完全部零件。旧文档里 220 mm 床的告警作废。

代价是敞开的前口会放环境光进来。接受，因为闪光的输出远大于室内光：在昏暗的房间里拍，别让顶灯直射箱口。

**教训：零件只要能朝箱内打光就够了，不一定非得装进箱子里。**

### 22. 压平系统收敛为插片平台

v4 用夹上盖下面的压条加 0.4 mm 滑槽压平胶片（[第 18](#18-夹子按层高量化)、[19 条](#19-不留单层台阶)）。v5 把这个问题从头重新打开，三个没能活下来的答案之后才落地：

- **压条方案，先照搬过来。** 它只在开窗四边约束胶片，一条通向全画幅平整度的玻璃升级路线一直在招手。
- **要掀的玻璃盖。** 在窗口上盖一块可选玻璃、过片时拿起来。按节奏否决：[第 13 条](#13-扩散板移到胶片台上)接受的是每次开工付一次的代价；每帧掀一次玻璃，是把代价摊到每一帧上：一卷 36 张下来，它会变成整个流程里最慢的一步。
- **泡棉悬挂。** 用上盖里的泡棉垫把压平元件压住。按寿命否决：泡棉会老化，预压力跟着逐年衰减。
- **插片平台。** 夹底座的外轨带一圈 **4.6 mm 元件台阶**，台阶上落一件可互换的压平元件：默认是打印的**压片窗插片**，升级是一片**防牛顿环玻璃**。元件放进去一次就不再动：胶片骑在 4.2 mm 的承台上，元件底面在 4.6 mm，于是一条 **0.4 mm 的通道**沿四边、贯穿全幅铺开；过片捏住片头直接抽拉，不开盖、不掀元件，拱起在滑过时被元件底面压平。

CAD 里的数字：插片模式下，胶片在窗内最多抬起约 0.28 mm，落在 1:1、f/8 时约 ±0.4 mm 的景深之内；玻璃模式则是全画幅连续封顶。一片 **64 × 95 × 2 mm** 的玻璃两个幅面通用，因为 135 底座是双轨：内轨导引窄片，外轨与 120 底座共用同一圈台阶。插片分幅面，玻璃只此一件。

**教训：操作动作要按每帧做预算，不能按每次开工做预算；装好之后再也不用碰的零件，位置才不会跑。**

### 23. 全机无螺丝

v4 把胶片台夹在三根 M6 螺杆的上下螺母之间、螺杆旋入热熔铜螺母，靠拧螺母调平（[第 14 条](#14-为竖着使用而改成确实固定)）。v5 把这一整套全部删除：三根螺杆、六颗螺母、铜螺母，连同全机每一处螺纹配合。动手的理由有两条：

- **不让塑料承担螺纹。** 就算换上铜螺母，螺纹的载荷最终还是落在周围的塑料上；打印机器里的每一个螺纹结合都是易损点外加一串公差（[第 5 条](#5-撑得住调平载荷的顶板)的立柱，就是专为伺候它而存在的机关）。
- **调平属于相机端，不属于箱子。** 在胶片台上放一面小镜子，从取景器里看：镜头自己的倒影居中时，传感器就平行于片平面。这一步校验对齐的是真正要紧的那一对，还顺路吸收了箱体的打印公差；拧螺杆做不到这一点，因为螺杆只能调箱子，看不见上面的相机。

螺丝退场之后，组装只剩重力和磁吸。顶盖台搁在箱壁顶上，由壁顶的四个**定位榫**落进其四角的**榫槽**定位：只有一种放法，没有任何要拧的东西，整套组装不需要任何工具。第 14 条里的 CAUTION 对 v4 硬件仍然有效；v5 根本没有可攻丝的胶片台孔。

**教训：把调节放在看得见误差的地方；拧箱子上的螺杆看不到对齐结果，片平面上的镜子看得到。**

### 24. 顶盖与胶片台合并，整体减薄降本

v4 打样的账单（约 1200 元）是这个设计收到过的最锋利的一份评审：打印服务商按体积收钱，每一面墙都是一个收费项。v5 直接对克数下手：

- **壁 2.4 mm、底 3.0 mm**（原来是 3 和 4）。螺纹配合全部消失之后（[第 23 条](#23-全机无螺丝)），再没有哪面墙、哪块板要承受紧固件的载荷；壳体只需要立着、保持白色、给顶盖台定位。
- **顶盖与胶片台合并为一件，即顶盖台**：一块搁在箱壁上的板，托盘、透光窗、亚克力暗槽都在它身上。整套零件里最大的一批就此少了一件，两件之间的接缝也一起消失。
- **亚克力缩为 68 × 118 mm**（v4 是 110 × 130，旧料可以让亚克力店裁小续用）。
- **钢垫片改为四片 10 × 10 mm**，沉在顶盖台台面的沉孔里、与台面齐平。

所有零件仍然免支撑、平面朝下打印。整套九个文件估算 **300–350 g** 耗材。这个数字和 v5 的其他数字一样出自估算，但下一张账单会来核对它。

**教训：打印体积要像其他尺寸一样，事先给它定一条预算。**

### 25. 装框幻灯片自成一板

装框的 135 幻灯片直到 v5 都不在支持范围内：纸框或塑料框厚约 1.2 – 3.2 mm，而 135 通道只有 0.4。最直接的办法是在 135 底座上挖一个 50 × 50 的槽，一看就被否掉了：槽正好把开窗四周的承台挖掉，而承台就是整套压平系统（[第 22 条](#22-压平系统收敛为插片平台)）。拍片条时再用一块填块把承台补回来，又多一个件，胶片面还得靠填块贴合得好不好，而不是靠打印出来的台阶。

最后落地的是独立的第四副夹子，只有一件：`slide-plate-135.stl`，一块 94 × 120 × 5 的板，上面一个 51.4 mm 见方、深 2.0 的方槽，槽底穿一个 26 × 38 的开窗，再加两个不穿透的指槽。它立在托盘里夹底座的位置上，135 那副因此一处都没动。它没有上盖、没有磁铁、没有玻璃，因为框是硬的、箱子是卧式的：方槽定位，重力压住。胶片面落在约 82.6 – 83.6，视框而定，离片条的 83.2 只差重新对一次焦，和 6×6 遮幅片本来就要求的调整是同一回事。

**教训：新画幅共用不了压平几何时，就给它单独一个件，不要在共用件上妥协。**

### 26. 4×5 装在同一只箱子上，先当实验

设计文档 §10 原本把 4×5 留给一只更大的箱子：窗口加上 v1 的混光余量，也就是约 165 × 186 mm 的主箱和 220 级的打印床。推导它之前，先问了一个更便宜的问题：4×5 装在现有的这只箱子上要花什么？两个件。第二块顶盖台沿用同样的外形和四个榫槽，带 102 × 126 的窗口、放 106 × 130 × 2 乳白板的暗槽和 112.6 × 138.6 的托盘；托盘里一块片板，用 102.2 × 127.6 的片槽接住 101.6 × 127 的页片，槽下开 97 × 121 的窗。没有压片元件：0.25× 时 f/8 的景深大约 8 – 10 mm，是 135 的十倍，页片的卷曲根本看不出来。箱子里其余一切不变，每一件仍然能在 160 × 160 的床上打。

它让出去的是混光余量：离箱壁 9 和 12 mm，而不是 29 和 27.5。这会不会表现成渐变是未知的，正如 v1 自己的均匀性也是未知的；亚克力照样扩散，平场校正照样存在，更大的箱子作为第二步留在桌上。套件之所以作为同一只箱子上的实验发布，是因为弄清楚这件事只要两个文件和一次亚克力裁切，而猜要搭一整只新箱子。

**教训：放大箱子之前，先弄清现有的箱子能做到哪里；两个件的实验比推导一整只壳体便宜。**

## 特意没有做的事

四个经过认真权衡之后被否决的改动。如果你正打算提其中之一，先从这里读起。

*[LED 灯板](#用高显色-led-灯板取代闪光灯) · [第二层扩散板](#第二层扩散板) · [把顶盖打成一体](#把顶盖与主箱打成一体) · [通风](#通风)*

### 用高显色 LED 灯板取代闪光灯

这是唯一能让箱子明显变小的改动（高约 100 mm、约 4 升），因为 LED 灯板本身就已经是面光源，几乎不需要混光距离。

最终还是选了闪光灯，否决了它。在一只封闭的箱子里，闪光脉冲就是全部曝光，于是振动和快门震动都不再要紧，而且在基准 ISO 和 f/8 下还有功率余量。即便如此，抽口盖板的尺寸仍然是按「日后可以换装 LED 灯板」留的：换装时不必移动胶片平面，也不必改相机高度。

### 第二层扩散板

两层扩散板确实能改善均匀度。在当前设计里，把第二层和它的腔体加回来，要付出约 **43 mm** 的高度。只有做 4×5 版本、或者正片证明单层不够用时，才值得重新考虑。

### 把顶盖与主箱打成一体

仅因可打印性就被否决。一只封闭的中空箱子，会在混光腔上方形成 202 × 267 mm 的无支撑天花板，FDM 无法[桥接](glossary.zh-CN.md#桥接)。那就必须打内部支撑，而支撑只能从 190 × 76 mm 的抽口里掏出来，还会在光学顶面上留下疤痕。换任何一个面朝下打印，都只是把问题挪个地方。

何况收益为零：顶盖本来就不靠紧固件固定，它的裙边就是光陷阱。确实有一个无缝方案能成立（把顶板放在打印床上、四壁从它向上生长、把抽口盖板挪到底面），但这等于用底面的缝换掉顶面的缝，而且意味着整套重建模。如果顶盖日后觉得松，穿过裙边打两颗小自攻螺丝，远胜过一体成型。

### 通风

原型里省略了。低占空比下工作的机顶闪几乎不发热，而每一个孔都是潜在的漏光点。如果一次连拍下来箱子发烫，在换卷的间隙把抽口盖板拔下来即可。

---

← [设计](design.zh-CN.md#设计) · [文档索引](../README.zh-CN.md#文档) · [术语表](glossary.zh-CN.md#术语表) →

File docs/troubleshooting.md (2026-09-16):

# Troubleshooting

**English** · [简体中文](troubleshooting.zh-CN.md) · [日本語](troubleshooting.ja.md)

> Symptom, likely cause and fix for the faults this design can actually produce: while printing, while building, in the light itself, and at the camera.

**Contents:** [How to use this page](#how-to-use-this-page) · [Printing](#printing) · [Assembly](#assembly) · [Light and evenness](#light-and-evenness) · [Capture](#capture) · [Still stuck](#still-stuck)

## How to use this page

> [!NOTE]
> This design has not been printed or built. Every row below is a fault the geometry, the materials or the procedure can produce, derived from the design and not from a repair log. Nothing here is a measured result.

Check these before you go looking for anything exotic. Most symptoms on this page trace back to one of them:

- [ ] Every part passed [the acceptance checks](printing.md#check-each-part-before-you-assemble): nothing was scaled by a slicer.
- [ ] The protective film is off **both** faces of the opal acrylic diffuser.
- [ ] The flash lies flat on the desk with its head centred on the open front, zoom at its widest setting.
- [ ] The room is dim, and no ceiling light shines straight into the open front.
- [ ] The camera has been squared to the film plane with the mirror method: a small mirror on the stage, the lens's own reflection centred in live view.
- [ ] Glass mode only: the underside of the anti-Newton glass was blown clean before the glass went into its ledge this session.

```mermaid
flowchart TD
  A[Something is wrong] --> B{Where does it show?}
  B -- A part is the wrong size or shape --> C[Printing]
  B -- Parts will not go together --> D[Assembly]
  B -- The bare lit surface is uneven --> E[Light and evenness]
  B -- The picture is wrong --> F[Capture]
  E --> G[Apply flat-field correction before judging either]
  F --> G
```

---

## Printing

| Symptom | Likely cause | Fix |
|---|---|---|
| A part measures smaller than its card in [The twelve parts](printing.md#the-twelve-parts) | The slicer scaled it to fit the build plate | Reslice at 100 %, millimetres, and reprint. The largest part is 154.8 mm across and fits a 160 × 160 plate without scaling, so any scaling was an accident. Re-run the acceptance checks. |
| A corner of the main body or the cover-stage has lifted off the build plate | A cold or draughty machine, or a dirty plate | Reprint on a clean plate, out of the draught, with whatever adhesion aid your machine likes. A lifted corner is not cosmetic: the cover-stage rests on the wall tops and the film plane stands on the cover-stage, so warp at either face rocks everything above it. |
| A part has drooped, ragged overhangs | It was sliced in the wrong orientation | Every part prints support-free, but only one way up: flat base down for the holder bases, the inserts, the main body and the cover-stage, and **top face down** for the two holder lids. Reorient and reprint; nothing recovers the part as printed. |
| The white parts came back shiny or silky | Silk or glossy filament | They have to be reprinted in matte. The bare white interior *is* the reflector; a glossy one reproduces the flash head as a hot spot, and painting the inside is not the fix. |
| Steps and ledges sit at heights that do not match the part cards | A [layer height](glossary.md#layer-height) that does not divide the design's 0.2 mm grid | Print the holder parts at 0.2 mm. The 0.4 mm step between the film lands and the element ledge is what sets the film clearance, and it only comes out right on the grid ([design log entry 18](design-log.md#18-layer-quantised-holders)). |

> [!CAUTION]
> Never add support to force a different orientation. Every part in this build is support-free by design, but only in its stated orientation. The two holder lids go top face down; everything else goes flat base down. Orientation in this project is always described by a feature you can see.

---

## Assembly

| Symptom | Likely cause | Fix |
|---|---|---|
| The cover-stage rocks on the main body, or sits proud at one corner | The four locating tenons are not all seated in their notches, or [elephant foot](glossary.md#elephant-foot) at a tenon or notch edge | Lift the cover-stage and set it down again so all four tenons drop home under its own weight. If it still rocks, a light knife pass on the first layer of the tenons usually clears it. Never force or shim it. |
| The holder lid pushes itself away instead of snapping shut | One or more magnet pairs repel: a magnet was pressed in flipped | Find the repelling spot by holding a spare magnet over each position in turn. The flipped one has to come out, be turned over and pressed back in. Next time, before pressing any of them, mark the same face of every magnet while they are still in one stack: mark up in the bases, mark down in the lids. |
| Lifting the lid (or the holder) brings the whole stage up with it | A straight vertical pull fights every magnet pair at once, and nothing in this build is screwed down | Peel, don't pull: tip the lid (or the holder) up from one corner so the pairs release one at a time. |
| The holder will not snap down onto the stage, or slides around on it | The four steel washers are stainless (not magnetic), or missing from their counterbores | Fit carbon-steel or zinc-plated washers, one in each counterbore, flush with the deck. Test any new batch with a magnet the day it arrives. |
| A magnet drops into its pocket loose instead of press-fitting | The pocket printed oversize | A drop of cyanoacrylate, and seat it to the pocket's full depth; a proud magnet changes the closing gap. |
| The whole holder sits about 1 mm high with the 6 × 6 mask fitted | The mask goes underneath the 120 base | Not a fault; the design does exactly this. |
| The diffuser has gone cloudy or is covered in fine cracks | Alcohol, or an ammonia-based glass cleaner | Fit a new sheet: 68 × 118 × 2 mm is a cheap custom cut, and a prototype-era 110 × 130 sheet can be cut down to it. |
| The diffuser looks dull and milky all over, straight out of the packet | Protective film still on one face | Peel both faces. It is easy to remove one and miss the other. |

> [!CAUTION]
> Never clean the opal acrylic diffuser with alcohol, ammonia or glass cleaner. It crazes the surface permanently, and a crazed sheet is no longer an even source. A rocket blower and a dry microfibre cloth, nothing else.

<details>
<summary>Why nothing in this box screws down, and what that means for a fix</summary>

There is not a single thread in the build. The stack is located by gravity, tenons and magnets, and the tolerances that fasteners would normally fight are absorbed at the camera end instead: a small mirror on the stage, the lens's own reflection centred in live view, and the sensor is parallel to the film plane whatever small errors the plastic carries.

So mechanical fixes here are always *reseat, peel, deburr*: never tighten, shim or glue the stack. If something rocks, find the seat it is not sitting in; do not clamp it down.

</details>

---

## Light and evenness

Judge all of this on a flat frame (the bare lit surface, no film, shot raw at the working aperture), and only after [flat-field correction](glossary.md#flat-field-correction). The procedure is in [Flat-field and inversion](scanning.md#flat-field-and-inversion).

| Symptom | Likely cause | Fix |
|---|---|---|
| The corners are uneven after correction | The flash head is not centred on the open front, the zoom is not at its widest, or room light is mixing in | In this order: centre the head on the mouth of the box; set the zoom to its widest; dim the room. |
| The corners look uneven, but you have not flat-fielded | Lens vignetting and source unevenness are being read as one thing | Correct first, judge second. |
| A bright patch that reproduces the shape of the flash head | Glossy or silk white filament, or an interior that has been sanded, polished or painted | The [cavity](glossary.md#integrating-cavity) must be bare matte white filament. There is no fix short of new parts. |
| Everything is darker than the meter suggested | The bounce cavity costs light; that is the price of evenness | Add flash power before you add ISO. |
| The image is grey and veiled, low in contrast | The white deck reflecting stray light up around the holder, or a ceiling light shining into the open front | Stick the optional black flocking sheet onto the deck, and keep overhead light off the mouth of the box. The flash overwhelms ambient light, but only in a dim room. |
| Evenness has changed since last session | The flash has moved on the desk | Tape or trace its footprint so the head always returns to the same spot against the front opening. |
| A 4×5 frame is brighter toward the back of the box than the front | The 4×5 window sits 9 and 12 mm from the cavity walls, a third of the v1 mixing margin, and nothing has been measured | Flat-field correction removes a smooth gradient. If it is more than you will accept, the bigger box in [Design § 10](design.md#10-45-on-the-v1-body) restores the margins. |

> [!IMPORTANT]
> Fix parallelism before you chase evenness. A flash freezes vibration, but nothing in the box can rescue a film plane that is not parallel to the sensor; the whole adjustment lives at the camera end, in the mirror method. A tilted plane can also read as a brightness gradient once you start pixel-peeping corners.

---

## Capture

| Symptom | Likely cause | Fix |
|---|---|---|
| The frame is completely black | In descending likelihood: a fully electronic shutter, a shutter faster than [sync speed](glossary.md#sync-speed), a flat receiver battery, a channel mismatch, a transmitter not seated in the hot shoe | Work down that list before touching anything else. Flash, receiver and transmitter all live outside the box, so none of it means opening anything. An electronic shutter usually will not fire a flash at all; [EFCS](glossary.md#efcs) sometimes does. |
| Part of the frame is exposed, the rest is a clean dark band | The shutter beat the flash: a speed above the real sync limit. Focal-plane shutters sync at 1/160–1/250 on paper, and a budget 2.4G trigger costs about a stop of that | Start at 1/125 s. If the band goes, walk the speed back up until it returns, then stay one step below. Settings table in [Exposure](scanning.md#exposure). |
| One edge of every frame is soft, the rest is sharp | The film plane is not parallel to the sensor | The mirror method in [Parallelism](scanning.md#parallelism). This is never a focus problem. |
| The frame edges or corners are soft, and it varies frame to frame | The film is not lying flat: curl the pressure element has not fully tamed | In order: stop down to f/8–f/11 (at 1:1 and f/8 the depth of field is about ±0.4 mm, against rises of at most 0.28 mm with the insert); check the loading direction, bow **down** under the pressure-window insert and bow **up** under the glass; and if a stubborn film still shows it, upgrade to the anti-Newton glass, which caps the whole frame continuously. |
| Soft dark blobs in the same place in every frame | Glass mode: dust on the underside of the glass, 0.2 mm from the film plane, close enough to image | Take the glass out and blow its underside before it goes back in; make that the habit at every session start. Dust on the acrylic does *not* image, since it sits on the diffuse source itself; a periodic wipe there is enough. |
| Exposure varies frame to frame | Flash power was changed mid-roll, or the cells are running down and the flash is firing before it has recycled | Settle power once during calibration and do the fine work with the aperture in 1/3 stops. Wait for the ready lamp. Keep two sets of NiMH cells in rotation. |
| Interference rings across the image | Glass mode with the glass in flipped (the frosted anti-Newton face must be **down**, against the film's shiny base), or a plain glass substituted for the AN one | Refit the glass frosted face down. In insert mode rings cannot form at all (see the note below), so rings there mean something extra is lying on the film. |
| A scratch runs the length of a strip | Grit under the pressure element: the film slides through beneath it with 0.4 mm of clearance | Blow the channel and the underside of the element before every strip. |
| The strip drags or jams while being pulled through | A curled edge catching at the break in the inner rails, or the tail of a long strip hanging off and dragging | Back the strip out and re-feed it straight; the rail ends carry 12 mm guides for exactly this. Support the tail of a long strip with your free hand; the flange top helps, 0.2 mm below the film plane, but a long overhang still wants a hand under it. |
| Edge markings read mirrored in live view | The strip is in upside down | Dull emulsion side down toward the light, shiny base up toward the camera. Full sequence in [Loading film](scanning.md#loading-film). |
| A sliver of rebate shows around the frame | The windows are deliberately oversize (25 × 37 for a 24 × 36 frame, about 0.5 mm per side) to absorb camera-gate variance and printer tolerance | Not a fault. Crop it off in post. |
| A mounted slide will not go in | The holders take film strips only | Use the slide plate: lift the 135 holder out, set `slide-plate-135.stl` in the tray and drop the mount into its pocket. See [Mounted slides](scanning.md#mounted-slides). |
| The frame does not fill the sensor | Not enough [magnification](glossary.md#magnification-ratio) for your format and sensor | The table in [Magnification and lens choice](scanning.md#magnification-and-lens-choice). Any 1:1 macro lens covers every format the box handles. |

> [!CAUTION]
> Blow before every strip. Film is advanced by pulling it sideways beneath the pressure element, and a single trapped grain of grit will scratch every frame that passes. A scratched negative cannot be un-scratched.

<details>
<summary>Where Newton rings can and cannot form in this holder</summary>

[Newton rings](glossary.md#newton-rings) are interference fringes that appear where film is in near-contact with a smooth, hard surface.

With the pressure-window insert, the image area touches nothing: the film rides on its edges with 0.4 mm of clearance to the insert above, so there is no optical contact and the mechanism has nothing to work with. Rings in insert mode mean something has been added to the stack: a sleeve left on, a loose glass laid over the film.

With the glass, contact is the point: the film's shiny base rests against the glass, and the frosted anti-Newton face is what breaks the interference up. Frosted face down against the base, emulsion facing the open window below, and rings cannot assemble. Rings in glass mode therefore mean the glass is in flipped, or a plain glass was substituted for the anti-Newton one.

</details>

---

## Still stuck

1. **Prove which half is at fault.** Shoot a flat frame: no film, everything else untouched. If the corrected flat frame is clean, the box is fine and the problem is on the camera side. If it is not, stay in [Light and evenness](#light-and-evenness).
2. **Re-run the acceptance checks.** [Check each part before you assemble](printing.md#check-each-part-before-you-assemble) catches scaling, warp and tight fits: the faults that make everything downstream unbuildable.
3. **Change one thing at a time**, and re-shoot the flat frame after each. The calibration remedies are deliberately ordered; applying the last one first hides what the first one would have told you.
4. **Report it.** This design has never been built, so the failures of a real first build are new information for everyone. The repository is public: <https://github.com/Neoanaloglab/Neobox>.

Reference material: [Design](design.md) for why a part is shaped the way it is, [Design log](design-log.md#things-deliberately-not-done) for what was tried and rejected, and the [Glossary](glossary.md) for any term on this page that is new to you.

---

← [Scanning](scanning.md) · [Documentation index](../README.md#documentation) · [Glossary](glossary.md) →

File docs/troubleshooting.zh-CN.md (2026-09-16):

# 故障排查

[English](troubleshooting.md) · **简体中文** · [日本語](troubleshooting.ja.md)

> 这个设计真正可能产生的故障（打印时、装配时、光线本身，以及相机端），每一条都给出现象、可能原因和处理办法。

**目录：**[怎么用这一页](#怎么用这一页) · [打印](#打印) · [装配](#装配) · [光线与均匀性](#光线与均匀性) · [拍摄](#拍摄) · [还是搞不定](#还是搞不定)

## 怎么用这一页

> [!NOTE]
> 本设计还没有被打印出来，也没有被实际搭建过。下面每一行都是几何结构、材料或者流程本身能够造成的故障，从设计推导出来，不是从维修记录里来的。这里没有任何一个数字是实测结果。

去找那些稀奇古怪的原因之前，先把下面这几条过一遍。这一页上的多数现象，最后都能追回到其中某一条：

- [ ] 每个零件都通过了[装配前逐件检查](printing.zh-CN.md#装配前逐件检查)：没有哪个被切片软件缩放过。
- [ ] 乳白亚克力扩散板**两面**的保护膜都已经撕掉。
- [ ] 闪光灯平躺在桌面上，灯头居中对准敞开前口，变焦设在最广一档。
- [ ] 房间够暗，没有顶灯直射箱口。
- [ ] 相机已经用镜子法对正过：小镜子放在台上，实时取景里让镜头自己的倒影居中。
- [ ] 玻璃模式：这次开工前，防牛顿环玻璃的底面已经吹过灰，才放回台阶里。

```mermaid
flowchart TD
  A[出问题了] --> B{问题在哪一环显现}
  B -- 某个零件尺寸或形状不对 --> C[打印]
  B -- 零件装不到一起 --> D[装配]
  B -- 裸露发光面不均匀 --> E[光线与均匀性]
  B -- 画面不对 --> F[拍摄]
  E --> G[判断之前先做平场校正]
  F --> G
```

---

## 打印

| 现象 | 可能原因 | 处理办法 |
|---|---|---|
| 某个零件量出来比[十二个零件](printing.zh-CN.md#十二个零件)里那张卡片上的尺寸小 | 切片软件把它缩放到了打印床能放下的大小 | 按 100 % 比例、毫米单位重新切片并重打。最大的零件也只有 154.8 mm，160 × 160 的床就放得下，不需要任何缩放，所以缩放一定是误操作。再走一遍验收检查。 |
| 主箱或者顶盖台有一个角从打印床上翘起来了 | 机器冷、有穿堂风，或者床面脏了 | 换干净的床面、避开风口重打，用你机器习惯的那种粘床手段。翘角不是外观问题：顶盖台就搁在箱壁顶上，胶片面又立在顶盖台上，这两个面里任何一个变形，上面的一切都会跟着晃。 |
| 某个零件的悬空处垂塌、毛糙 | 切片时摆放方向不对 | 每个零件都免支撑，但只在规定的那个朝向下成立：夹底座、插片、主箱、顶盖台平底朝下；两个夹上盖则**顶面朝下**。摆正方向重打；已经打成这样的件没有任何补救办法。 |
| 白色件回来是亮面或者丝面的 | 用了丝面或亮面耗材 | 只能换哑光料重打。裸露的白色内壁*就是*那面反射器；亮面会把灯头映成一块亮斑，往内壁上喷涂不是解决办法。 |
| 台阶出现的高度和零件卡片对不上 | [层高](glossary.zh-CN.md#层高)（layer height）除不尽设计的 0.2 mm 网格 | 夹子这一族零件按 0.2 mm 层高打。承台和元件台阶之间那道 0.4 mm 的落差决定了胶片的活动间隙，只有落在网格上才打得准（[设计日志第 18 条](design-log.zh-CN.md#18-夹子按层高量化)）。 |

> [!CAUTION]
> 绝不要靠加支撑去硬凑一个别的打印朝向。这套件里每个零件都是按免支撑设计的，但只在规定的朝向下成立。两个夹上盖顶面朝下，其余一律平底朝下。这个项目描述打印朝向时，永远只用你看得见的特征。

---

## 装配

| 现象 | 可能原因 | 处理办法 |
|---|---|---|
| 顶盖台在主箱上晃，或者有一个角翘着不贴 | 四个定位榫没有全部落进榫槽，或者榫、槽边缘有[象足](glossary.zh-CN.md#象足)（elephant foot） | 把顶盖台整个提起来重新放一次，让四个榫靠自重落到底。还晃的话，用刀轻轻刮掉榫上的第一层，通常就好了。绝不要硬压，也不要垫东西。 |
| 夹上盖不是吸上去，反而被弹开 | 有一对或几对磁铁相斥：某颗磁铁压反了 | 拿一颗备用磁铁挨个位置试，找出相斥的那一处。压反的那颗只能取出来、翻面、重新压入。下次装配前，趁所有磁铁还叠成一摞时给每颗的同一面做上记号：底座里记号朝上、上盖里记号朝下，然后再开始压。 |
| 掀上盖（或者拿夹子）的时候，整个台子跟着起来了 | 竖直硬拔要同时对抗所有磁对，而这套件里没有任何东西是被拧死的 | 剥，不要拔：从一个角把上盖（或夹子）掀起来，让磁对一对一对地断开。 |
| 夹子吸不到台面上，或者在台面上滑来滑去 | 四片钢垫片是不锈钢的（不导磁），或者根本没放进沉孔 | 换碳钢或者镀锌垫片，每个沉孔一片，与台面齐平。新到的每一批，当天就拿磁铁试一下。 |
| 磁铁放进孔里是松的，不是压进去的 | 磁孔打大了 | 点一滴 502 胶，并把它压到孔底；磁铁凸出来会改变闭合间隙。 |
| 装上 6 × 6 遮幅插片后，整个夹子高了大约 1 mm | 遮幅插片就是垫在 120 底座下面的 | 这不是故障，设计就是这样。 |
| 扩散板发白，或者布满细密裂纹 | 用了酒精，或者含氨的玻璃清洁剂 | 换一片新的：68 × 118 × 2 mm 的定制裁切很便宜，原型机尺寸的 110 × 130 旧板也可以裁小续用。 |
| 扩散板刚拆封就是一片灰蒙蒙的奶白 | 有一面的保护膜还没撕 | 两面都撕掉。撕掉一面、漏掉另一面是很容易发生的事。 |

> [!CAUTION]
> 绝不要用酒精、氨水或者玻璃清洁剂去擦乳白亚克力扩散板。它会让表面永久性地起细裂纹，而起了裂纹的板就不再是一个均匀的光源。只能用气吹和干的超细纤维布，别的一概不行。

<details>
<summary>为什么这只箱子里没有任何东西是拧死的，这对处理故障意味着什么</summary>

整套件里没有一处螺纹。堆叠靠重力、定位榫和磁铁定位，而通常要靠紧固件去对抗的公差，全部改在相机端吸收：小镜子放在台上，实时取景里让镜头自己的倒影居中，传感器就与胶片面平行了，塑料件带着多少细小误差都无所谓。

所以这里的机械类处理办法永远是*重放、剥开、修毛刺*，绝不是拧紧、加垫片或者把堆叠粘死。有东西晃，就去找它没坐进去的那个位置，而不是把它压住。

</details>

---

## 光线与均匀性

下面这些一律在平场帧上判断（胶片夹里不放胶片的裸露发光面，用工作光圈拍的 raw），而且要在[平场校正](glossary.zh-CN.md#平场校正)（flat-field correction）之后再判断。流程见[平场校正与反相](scanning.zh-CN.md#平场校正与反相)。

| 现象 | 可能原因 | 处理办法 |
|---|---|---|
| 校正之后四角仍然不均匀 | 灯头没有居中对准敞开前口，变焦不在最广档，或者混进了房间光 | 按这个顺序来：把灯头对箱口摆正居中；变焦设到最广；把房间调暗。 |
| 四角看着不均匀，但你还没做平场 | 镜头暗角和光源不均被当成同一回事在看 | 先校正，后判断。 |
| 有一块亮斑，形状能认出是灯头 | 白色耗材是亮面或者丝面的，或者内壁被打磨、抛光、喷涂过 | [混光腔](glossary.zh-CN.md#混光腔)（integrating cavity）必须是耗材本色的哑光白。除了换新件，没有别的办法。 |
| 整体比测光表给的读数暗 | 反弹混光本身就要吃光，这是均匀性的代价 | 先加闪光出力，再考虑加 ISO。 |
| 画面发灰、蒙着一层雾，反差低 | 白色台面把杂光从夹子四周反上来，或者顶灯直射着箱口 | 把可选的黑色植绒贴贴到台面上，并让顶灯照不到箱口。闪光量远大于环境光，但前提是房间够暗。 |
| 均匀性和上次开工时不一样了 | 闪光灯在桌面上被挪动过 | 用胶带或画线标出它的位置，让灯头每次都回到箱口前的同一个地方。 |
| 4×5 的画面靠箱子后部比前部亮 | 4×5 的窗口离混光腔壁只有 9 和 12 mm，是 v1 混光余量的三分之一，而且没有测过任何东西 | 平场校正能去掉平滑的渐变。要是超出你能接受的程度，[设计 §10](design.zh-CN.md#10-45-装在-v1-主箱上)里的大箱子能把余量补回来。 |

> [!IMPORTANT]
> 先解决平行度，再去追均匀性。闪光脉冲能冻住震动，但箱子里没有任何东西能救回一个与传感器不平行的胶片面：整套调整都在相机端，靠镜子法完成。而一旦你开始放大到像素去抠四角，倾斜的胶片面读起来就像是一道亮度渐变。

---

## 拍摄

| 现象 | 可能原因 | 处理办法 |
|---|---|---|
| 整张画面全黑 | 按可能性从高到低：全电子快门、快门快过[同步速度](glossary.zh-CN.md#同步速度)（sync speed）、接收器电池没电、引闪频道没对上、发射器没在热靴里插实 | 先按这个顺序查完，再去动别的。闪光灯、接收器、发射器全都在箱外，查这些一样也不用开箱。全电子快门通常根本不会触发闪光；[EFCS](glossary.zh-CN.md#efcs) 有时候可以。 |
| 画面一部分有曝光，其余是一条干净的暗带 | 快门跑赢了闪光：速度超过了实际同步上限。焦平面快门纸面上同步在 1/160–1/250，而廉价 2.4G 引闪器还要吃掉大约一档 | 从 1/125 s 排查起。暗带消失了，就一档档往回加快，加到暗带重新出现，然后停在低一档上。参数表见[曝光](scanning.zh-CN.md#曝光)。 |
| 每一格都是同一条边发虚，其余是清晰的 | 胶片面与传感器不平行 | 用[平行度](scanning.zh-CN.md#平行度)里的镜子法。这永远不是对焦问题。 |
| 画幅边缘或四角发虚，而且逐格在变 | 胶片没有躺平：压片元件没有完全压服的卷曲 | 按顺序来：先把光圈收到 f/8–f/11（1:1、f/8 时景深约 ±0.4 mm，而插片模式下起伏至多 0.28 mm）；再检查装片方向，压片窗插片模式拱面朝**下**，玻璃模式拱面朝**上**；顽固的片子还是不平，就升级防牛顿环玻璃，把整个画幅连续压住。 |
| 每一格同一位置都有柔边暗斑 | 玻璃模式：玻璃底面有灰，离焦平面只有 0.2 mm，近到足以成像 | 把玻璃取出来，吹干净底面再放回去；把这变成每次开工的固定动作。亚克力上的灰*不会*成像，因为它就落在漫射光源本身上，定期擦拭就够了。 |
| 逐格曝光在变 | 一卷之中改过闪光出力，或者电池快没电、闪光灯还没回够电就被放掉了 | 出力在校准时一次定死，细活交给光圈的 1/3 档。等回电指示灯亮起再拍。两套镍氢电池轮换。 |
| 画面上出现一圈圈干涉环 | 玻璃模式下玻璃装反了（防牛顿环的磨砂面必须朝**下**，贴着胶片光亮的片基），或者换上了一片普通玻璃 | 把玻璃翻回磨砂面朝下。插片模式下根本出不了环（见下面的说明），真看到了，说明有别的东西压在胶片上。 |
| 一条片条上有一道贯穿全长的划痕 | 压片元件下面进了砂粒：胶片就是贴着它下方 0.4 mm 的间隙滑过去的 | 每装一条片条之前，把通道和元件底面都吹一遍。 |
| 抽片发滞，或者抽到一半卡住 | 翘起的片边卡在了内轨的断口上，或者长片条的尾巴垂在外面拖着 | 把片条退出来、摆直了重新送；导轨两端各留了 12 mm 的导向段，就是为这个。长片条的尾端用另一只手托着；凸缘顶能搭一把（低于片面 0.2 mm），但悬出去太长还是需要一只手。 |
| 实时取景里边缘字码读起来是镜像的 | 片条装反了 | 哑光的乳剂面朝下对着光，光亮的片基面朝上对着相机。完整步骤见[装片](scanning.zh-CN.md#装片)。 |
| 画幅四周露出一条片边 | 开窗是有意做大的：24 × 36 的画幅配 25 × 37 的窗，每侧约 0.5 mm，用来吸收相机片门的差异和打印机的公差 | 这不是故障。后期裁掉。 |
| 装框幻灯片塞不进去 | 胶片夹只吃片条 | 用幻灯片板：把 135 胶片夹掀出来，把 `slide-plate-135.stl` 放进托盘，再把框放进它的方槽。见[装框幻灯片](scanning.zh-CN.md#装框幻灯片)。 |
| 画幅填不满传感器 | 你这个画幅和传感器的组合所需的[放大倍率](glossary.zh-CN.md#放大倍率)（magnification）不够 | 见[放大倍率与镜头选择](scanning.zh-CN.md#放大倍率与镜头选择)里的表。任何一支 1:1 微距镜都能覆盖这只箱子支持的全部画幅。 |

> [!CAUTION]
> 每装一条片条之前都要吹。过片就是让胶片贴着压片元件下方横向滑过去；卡在里面的一粒砂，会把之后经过的每一格都划伤。划伤的底片是修不回来的。

<details>
<summary>牛顿环在这副夹子里哪里可能出现、哪里不可能</summary>

[牛顿环](glossary.zh-CN.md#牛顿环)（Newton rings）是胶片与光滑坚硬表面近乎贴合时出现的干涉条纹。

用压片窗插片时，影像区不接触任何东西：胶片靠两条边骑在承台上，与上方的插片之间留着 0.4 mm 的间隙，没有任何光学接触，这个机制无从发生。插片模式看到环，说明有东西被加进了夹层：没取下的片袋、随手压上去的一片玻璃。

用玻璃时，接触本身就是设计意图：胶片光亮的片基就贴在玻璃上，而磨砂的防牛顿环面正是用来打散干涉的。磨砂面朝下贴着片基、乳剂面朝着下方的开窗，环就组不起来。所以玻璃模式看到环，意味着玻璃装反了，或者防牛顿环玻璃被换成了普通玻璃。

</details>

---

## 还是搞不定

1. **先确定是哪一半出了问题。** 拍一张平场帧：不放胶片，其余一概不动。如果校正后的平场帧是干净的，箱子没问题，问题在相机端。如果不干净，就留在[光线与均匀性](#光线与均匀性)。
2. **把验收检查重跑一遍。**[装配前逐件检查](printing.zh-CN.md#装配前逐件检查)能抓出缩放、变形和配合过紧，而这几样正是让后面一切都做不下去的故障。
3. **一次只改一件事**，每改一次就重拍一张平场帧。校准的那几个补救手段是有意排了顺序的；把最后一条先用上，就把第一条本来能告诉你的信息盖掉了。
4. **把它报上来。** 这个设计从来没有被实际搭建过，所以真实的第一次搭建暴露出来的问题，对所有人都是新信息。仓库是公开的：<https://github.com/Neoanaloglab/Neobox>。

参考资料：[设计](design.zh-CN.md)讲某个零件为什么长成这样，[设计日志](design-log.zh-CN.md#特意没有做的事)讲什么被试过又被否掉，这一页上任何一个你没见过的词都能在[术语表](glossary.zh-CN.md)里查到。

---

← [翻拍扫描](scanning.zh-CN.md) · [文档索引](../README.zh-CN.md#文档) · [术语表](glossary.zh-CN.md) →

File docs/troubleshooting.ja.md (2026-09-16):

# トラブルシューティング

[English](troubleshooting.md) · [简体中文](troubleshooting.zh-CN.md) · **日本語**

> この設計が実際に起こしうる不具合を、症状・考えられる原因・対処の形でまとめます。出力中、組み立て中、光そのもの、そしてカメラ側。

**目次：** [このページの使い方](#このページの使い方) · [プリント](#プリント) · [組み立て](#組み立て) · [光と均一性](#光と均一性) · [撮影](#撮影) · [それでも解決しないとき](#それでも解決しないとき)

## このページの使い方

> [!NOTE]
> この設計はまだ出力も組み立てもされていません。以下の各行は、形状・材料・手順から導いた「起こりうる不具合」であって、修理記録から拾ったものではありません。ここに実測の結果は 1 つもありません。

変わった原因を探しに行く前に、まずここを確認してください。このページの症状のほとんどは、このどれかに行き着きます。

- [ ] すべてのパーツが[組み立てる前に各パーツを確認する](printing.ja.md#組み立てる前に各パーツを確認する)を通っていて、スライサーにスケーリングされたパーツが 1 つもないこと。
- [ ] 乳白アクリル拡散板の保護フィルムが**両面とも**剥がしてあること。
- [ ] ストロボが机の上に寝かせてあり、ヘッドがオープンフロント（前面開口）の中央に向いていて、ズームが最広角になっていること。
- [ ] 部屋が暗く、天井の照明が開口へ直接差し込んでいないこと。
- [ ] カメラが鏡の方法で正対させてあること。小さな鏡をステージに置き、ライブビューでレンズ自身の映り込みを中央に合わせる。
- [ ] ガラスモードの場合：今回のセッションで、アンチニュートンガラスの下面をブロアーで吹いてから段に戻してあること。

```mermaid
flowchart TD
  A[何かがおかしい] --> B{どこに出ているか}
  B -- パーツの寸法か形が違う --> C[プリント]
  B -- パーツ同士が組み合わない --> D[組み立て]
  B -- 発光面そのものがムラになる --> E[光と均一性]
  B -- 写った絵がおかしい --> F[撮影]
  E --> G[判断する前にフラットフィールド補正をかける]
  F --> G
```

---

## プリント

| 症状 | 考えられる原因 | 対処 |
|---|---|---|
| パーツの実寸が [12 点のパーツ](printing.ja.md#12-点のパーツ)のカードより小さい | スライサーがビルドプレートに合わせて縮小した | 100 %・ミリメートルでスライスし直して出力し直してください。最大のパーツでも 154.8 mm で、160 × 160 のプレートに縮小なしで収まります。縮小されていたら、それは事故です。受け入れ確認もやり直すこと。 |
| 本体または天板ステージの角がビルドプレートから浮いた | 機械が冷えている、すきま風がある、またはプレートが汚れている | きれいなプレートの上、風の当たらない場所で、機械に合う定着補助を使って出力し直してください。角の浮きは見た目の問題ではありません。天板ステージは壁の上端に載り、フィルム面は天板ステージの上に立ちます。どちらかの面が反れば、その上のすべてが傾きます。 |
| パーツのオーバーハングが垂れて、がさがさになっている | 誤った向きでスライスされた | すべてのパーツはサポートなしで出力できますが、決められた向きでだけです：ホルダー底・インサート・本体・天板ステージは平らな底を下に、2 つのホルダー蓋は**上面を下に**。向きを直して出力し直してください。出てしまったパーツを救う方法はありません。 |
| 白いパーツが光沢／シルクで返ってきた | シルクまたは光沢フィラメント | つや消しで出力し直すしかありません。生地のままの白い内面**が**反射面そのものであり、光沢だとストロボのヘッドがホットスポットとして写り込みます。内側を塗装するのは対処になりません。 |
| 段差の高さがパーツカードと合わない | [積層ピッチ](glossary.ja.md#積層ピッチ-layer-height)（layer height）が設計の 0.2 mm グリッドを割り切れない | ホルダー系のパーツは 0.2 mm で出力してください。フィルムの受けとエレメント段のあいだの 0.4 mm の段差がフィルムのクリアランスを決めていて、グリッドに乗ったときにだけ正しく出ます（[設計ログの項目 18「ホルダーを積層ピッチに量子化」](design-log.ja.md#18-ホルダーを積層ピッチに量子化)）。 |

> [!CAUTION]
> 別の向きで出すためにサポートを足さないでください。このビルドのパーツはすべて、決められた向きに限ってサポートレスになるよう設計されています。2 つのホルダー蓋は上面を下に、それ以外は平らな底を下に。このプロジェクトで姿勢を必ず「目で見える特徴」で言い表しているのは、このためです。

---

## 組み立て

| 症状 | 考えられる原因 | 対処 |
|---|---|---|
| 天板ステージが本体の上でがたつく、または 1 つの角が浮いている | 4 つの位置決めダボが全部はダボ穴に落ちていない、またはダボやダボ穴の縁の[エレファントフット](glossary.ja.md#エレファントフット-elephant-foot)（elephant foot） | 天板ステージを持ち上げてもう一度置き直し、4 つのダボが自重で落ち切るようにしてください。それでもがたつくなら、ダボの最初の 1 層をナイフで軽くさらうとたいてい直ります。押し込んだり、何かを挟んだりしないこと。 |
| ホルダー蓋が吸い付かず、逆に弾かれる | どれかのマグネット対が反発している。1 個が裏返しに圧入されている | 予備のマグネットを各位置にかざして、反発する場所を探してください。裏返しの 1 個は抜いて、裏返して、圧入し直すしかありません。次からは、マグネットがまだ 1 本の棒に重なっているうちに全部の同じ面へ印を付けてから、圧入を始めてください。底側は印を上、蓋側は印を下です。 |
| 蓋（またはホルダー）を持ち上げると、ステージごと付いてくる | 真上への引き抜きは全部のマグネット対と同時に戦うことになり、しかもこのビルドにはねじ留めが 1 か所もない | 引き抜かずに、剥がしてください：蓋（またはホルダー）を 1 つの角から起こして、マグネット対を 1 組ずつ外します。 |
| ホルダーがステージに吸い付かない、または上で滑る | 4 枚のスチールワッシャーがステンレス（磁性がない）か、座ぐりに入っていない | 炭素鋼か亜鉛メッキのワッシャーを、座ぐり 1 つに 1 枚、ステージ面と面一に入れてください。新しいロットは、届いた日にマグネットで確認すること。 |
| マグネットが穴にすっと落ちて、圧入にならない | 穴が広く出た | 瞬間接着剤を一滴垂らし、穴の底まで沈めてください。マグネットが出っ張ると閉じの隙間が変わります。 |
| 6 × 6 マスクを入れると、ホルダー全体が 1 mm ほど高くなる | マスクは 120 の底の下に敷くものです | 不具合ではありません。設計どおりの挙動です。 |
| 拡散板が白濁した、または細かいひび割れだらけになった | アルコール、またはアンモニア系のガラスクリーナー | 新しい板に交換してください。68 × 118 × 2 mm の特注カットは安価で、プロトタイプの 110 × 130 の板を切り詰めて使うこともできます。 |
| 拡散板が袋から出した時点で、全体にくすんで乳白に見える | 片面に保護フィルムが残っている | 両面とも剥がしてください。片面だけ剥がしてもう片面を見落とすのは、よくあることです。 |

> [!CAUTION]
> 乳白アクリル拡散板を、アルコール・アンモニア・ガラスクリーナーで拭かないでください。表面が永久にひび割れ（クレージング）、ひび割れた板はもう均一な光源ではありません。使ってよいのはブロアーと乾いたマイクロファイバークロスだけです。

<details>
<summary>なぜこの箱にはねじが 1 本もないのか、それが対処にとって何を意味するか</summary>

このビルドにはねじ山が 1 つもありません。積み重ねは重力・位置決めダボ・マグネットで位置が決まり、本来なら締結具で抑え込むはずの公差は、代わりにカメラ側で吸収します：小さな鏡をステージに置き、ライブビューでレンズ自身の映り込みを中央に合わせれば、プラスチックがどんな小さな誤差を抱えていても、センサーはフィルム面と平行になります。

だからここでの機械的な対処は、いつでも「置き直す・剥がす・バリを取る」です。締める・挟む・接着するは決してしません。何かががたつくなら、それが収まっていない座を探すこと。押さえ付けないこと。

</details>

---

## 光と均一性

ここの判断はすべてフラットフレーム（フィルムを入れず、実際に使う絞りで RAW 撮影した発光面そのもの）の上で、しかも[フラットフィールド補正](glossary.ja.md#フラットフィールド補正-flat-field-correction)（flat-field correction）をかけたあとに行ってください。手順は[スキャン の「フラットフィールド補正と反転」](scanning.ja.md#フラットフィールド補正と反転)にあります。

| 症状 | 考えられる原因 | 対処 |
|---|---|---|
| 補正後も四隅がムラになる | ストロボのヘッドがオープンフロントの中央に向いていない、ズームが最広角になっていない、または部屋の光が混ざっている | この順で：ヘッドを開口の中央に合わせる。ズームを最広角にする。部屋を暗くする。 |
| 四隅がムラに見えるが、まだフラットフィールド補正をかけていない | レンズの周辺減光と光源本来のムラを、ひとまとめに読んでいる | 補正が先、判断が後です。 |
| ストロボのヘッドの形をそのまま再現した明るい斑が出る | 光沢またはシルクの白フィラメント、あるいは内面を研磨・磨き・塗装してしまった | [拡散チャンバー](glossary.ja.md#積分キャビティ-integrating-cavity)（integrating cavity）は生地のままのつや消し白フィラメントでなければなりません。新しいパーツを出す以外に対処はありません。 |
| 露出計の指示より全体が暗い | 反射で混ぜるチャンバーは光を失います。それが均一性の代償です | ISO を上げる前に、ストロボの発光量を上げてください。 |
| 画面全体が灰色にかぶって、コントラストが低い | 白いステージ面がホルダーの周囲から迷光を照り返している、または天井の照明が開口へ差し込んでいる | オプションの黒い植毛シートをステージ面に貼り、天井の照明が開口に当たらないようにしてください。ストロボの光量は環境光を圧倒します。ただし部屋が暗ければ、です。 |
| 前回のセッションから均一性が変わった | ストロボが机の上で動いた | テープか線でストロボの位置を印し、ヘッドが毎回、開口の前の同じ場所に戻るようにしてください。 |
| 4×5 のコマが、箱の手前より奥のほうが明るい | 4×5 の窓はチャンバーの壁から 9 と 12 mm、v1 の拡散マージンの 3 分の 1 で、何も測っていない | なだらかな勾配はフラットフィールド補正で取り除けます。受け入れられない大きさなら、[設計 §10](design.ja.md#10-v1-本体での-45)の大きな箱がマージンを取り戻します。 |

> [!IMPORTANT]
> 均一性を追いかける前に、平行を出してください。ストロボは振動を凍結しますが、センサーに対して傾いたフィルム面は箱の中の何をもっても救えません。調整はすべてカメラ側、鏡の方法にあります。しかも傾いた面は、四隅を等倍で見比べ始めたときに輝度勾配として読めてしまいます。

---

## 撮影

| 症状 | 考えられる原因 | 対処 |
|---|---|---|
| コマが真っ黒 | 可能性の高い順に、完全電子シャッター、[同調速度](glossary.ja.md#同調速度-sync-speed)（sync speed）より速いシャッター、レシーバーの電池切れ、チャンネル不一致、送信機がホットシューに入り切っていない | ほかに手を付ける前に、この順で潰してください。ストロボもレシーバーも送信機もすべて箱の外にあるので、どれを確認するにも箱を開ける必要はありません。完全電子シャッターではストロボはたいてい発光すらしません。[EFCS](glossary.ja.md#efcs-先幕電子シャッター)（先幕電子シャッター）なら光ることもあります。 |
| コマの一部だけ写り、残りがきれいな暗い帯になる | シャッターがストロボに勝った：実際の同調上限より速い速度です。フォーカルプレーンシャッターの公称は 1/160–1/250 ですが、安価な 2.4G トリガーがそこから約 1 段ぶん食います | まず 1/125 s から。帯が消えたら速度を 1 段ずつ戻していき、帯が再び出たらその 1 段下で止めます。設定の表は[スキャン の「露出」](scanning.ja.md#露出)にあります。 |
| どのコマも片側だけ甘く、残りはシャープ | フィルム面がセンサーと平行になっていない | [スキャン の「平行出し」](scanning.ja.md#平行出し)にある鏡の方法で合わせます。これは決してピントの問題ではありません。 |
| コマの縁や隅が甘く、しかもコマごとに変わる | フィルムが平らになっていない（押さえエレメントが抑え切れなかったカール） | 順番に：まず絞りを f/8–f/11 まで絞る（等倍・f/8 の被写界深度は約 ±0.4 mm あり、インサートでの浮き上がりは最大でも 0.28 mm）。次に装填の向きを確認する。押さえ窓インサートではふくらみを**下**に、ガラスではふくらみを**上**に。それでも頑固なフィルムが収まらないなら、アンチニュートンガラスに換えて、画面全体を連続した面で押さえてください。 |
| どのコマにも同じ位置に、ぼんやりした暗い染みが出る | ガラスモード：ガラスの下面の埃。フィルム面まで 0.2 mm、写り込むのに十分な近さです | ガラスを外し、下面を吹いてから戻してください。これを毎セッション開始時の習慣にします。アクリルの上の埃は写り込み**ません**。拡散光源そのものの上に載っているからです。あちらは定期的に拭けば十分です。 |
| コマごとに露出がばらつく | 撮影の途中で発光量を変えた、または電池が減ってチャージ完了前に発光している | 発光量はキャリブレーションのときに一度決め、細かい調整は絞りの 1/3 段で行ってください。チャージ完了ランプを待つこと。ニッケル水素電池は 2 セット用意してローテーションします。 |
| 画面に干渉縞のリングが出る | ガラスモードでガラスが裏返し（アンチニュートンのすりガラス状の面は、フィルムのつやのあるベース面に接する**下向き**が正しい）、または普通のガラスに置き換わっている | ガラスをすり面が下になるように入れ直してください。インサートモードではそもそもリングは出ません（下の解説を参照）。インサートで出たなら、何か余計なものがフィルムに載っています。 |
| ストリップの全長にわたって傷が走る | 押さえエレメントの下の砂粒。フィルムはその下を 0.4 mm のクリアランスで滑り抜けます | ストリップを通す前に毎回、通路とエレメントの下面を吹いてください。 |
| ストリップが引き抜きの途中で重くなる、または詰まる | カールで浮いた縁が内レールの切れ目に引っかかった、または長いストリップの尻尾が垂れて引きずっている | ストリップをいったん戻し、まっすぐにして送り直してください。レールの両端に 12 mm のガイドがあるのは、まさにこのためです。長いストリップの尻尾は空いた手で支えます。フランジの上面が受けてくれます（フィルム面の 0.2 mm 下）が、長く垂れた分にはやはり手が要ります。 |
| ライブビューでエッジの文字が裏返しに読める | ストリップが裏返しに入っている | つや消しの乳剤面を下（光の側）、つやのあるベース面を上（カメラ側）に。手順の全体は[スキャン の「フィルムの装填」](scanning.ja.md#フィルムの装填)にあります。 |
| コマの周囲にフィルムのふちが細く写り込む | 窓は意図的に大きく作ってあります。24 × 36 のコマに対して 25 × 37、片側およそ 0.5 mm。カメラゲートの個体差とプリンタの公差を吸収するためです | 不具合ではありません。後処理で切り落としてください。 |
| マウント済みのスライドが入らない | このホルダーが受けるのはフィルムストリップだけです | スライドプレートを使います。135 のホルダーを外し、`slide-plate-135.stl` をトレイに収めて、マウントをそのポケットに落とし込んでください。[マウント済みスライド](scanning.ja.md#マウント済みスライド)を参照。 |
| コマがセンサーいっぱいにならない | フォーマットとセンサーに対して[撮影倍率](glossary.ja.md#撮影倍率-magnification-ratio)（magnification ratio）が足りない | [スキャン の「撮影倍率とレンズの選択」](scanning.ja.md#撮影倍率とレンズの選択)にある表を参照してください。等倍マクロレンズが 1 本あれば、この箱が扱うすべてのフォーマットをカバーできます。 |

> [!CAUTION]
> ストリップを通す前に、毎回吹いてください。コマ送りは、フィルムを押さえエレメントの下で横に滑らせる方式です。砂粒が 1 つ挟まれば、そこを通るコマすべてに傷が入ります。傷の入ったネガは、元には戻せません。

<details>
<summary>このホルダーでニュートンリングが出うる場所と、出えない場所</summary>

[ニュートンリング](glossary.ja.md#ニュートンリング-newton-rings)（Newton rings）は、フィルムが滑らかで硬い面とほぼ密着したところに出る干渉縞です。

押さえ窓インサートでは、画面領域は何にも触れません：フィルムは縁で受けに載り、上のインサートまで 0.4 mm のクリアランスがあります。光学的な接触がどこにもないので、この現象は成り立ちようがありません。インサートモードでリングが見えたなら、何かが足されています。外し忘れたスリーブか、フィルムの上に置いたガラス板です。

ガラスでは、接触こそが設計意図です。フィルムのつやのあるベース面がガラスに載り、すりガラス状のアンチニュートン面が干渉を散らす仕掛けです。すり面を下にしてベースに当て、乳剤面を下の開口に向ければ、リングは組み上がりません。したがってガラスモードでリングが出たなら、ガラスが裏返しか、アンチニュートンガラスが普通のガラスに置き換わっています。

</details>

---

## それでも解決しないとき

1. **箱側とカメラ側のどちらに原因があるかを切り分ける。** フラットフレームを撮ってください。フィルムを入れず、ほかは何も変えずに。補正後のフラットフレームがきれいなら箱は問題なく、原因はカメラ側です。きれいでなければ[光と均一性](#光と均一性)に戻ってください。
2. **受け入れ確認をやり直す。** [組み立てる前に各パーツを確認する](printing.ja.md#組み立てる前に各パーツを確認する)は、スケーリング・反り・きつすぎる嵌合を捕まえます。これこそ、以降の工程すべてを成り立たなくする不具合です。
3. **一度に 1 つだけ変える**。そのたびにフラットフレームを撮り直します。キャリブレーションの対処には意図的に順番が付いています。最後のものを最初にやると、最初のものが教えてくれたはずのことが隠れてしまいます。
4. **報告する。** この設計はまだ一度も作られていないので、実際の最初のビルドで起きた失敗は、誰にとっても新しい情報です。リポジトリは公開されています：<https://github.com/Neoanaloglab/Neobox>。

参考資料：パーツがなぜその形なのかは[設計](design.ja.md)、何を試して何を却下したのかは[設計ログ の「あえてやらなかったこと」](design-log.ja.md#あえてやらなかったこと)、このページで初めて見る用語は[用語集](glossary.ja.md)。

---

← [スキャン](scanning.ja.md) · [ドキュメント一覧](../README.ja.md#ドキュメント) · [用語集](glossary.ja.md) →

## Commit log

2026-07-29 Add NeoBox open-hardware release: docs, STLs and CAD sources
    NeoBox is a 3D-printable flash light source for camera scanning 35 mm and
    120 film up to 6x9. The speedlight lies flat and fires horizontally into an
    all-white cavity, so enclosure height is set by the flash thickness rather
    than its height: 208 x 273 x 96 mm, about 5.4 L.
    Contents:
    - 10 STLs split by filament colour (white cavity, black film-side parts)
    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
    [access-panel.stl, alignment-blocks-x4.stl, film-holder-120-base.stl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]
2026-07-29 Ignore local .remember/ session history
    The workspace moved out of Google Drive into this repo, bringing the
    .remember/ history buffer with it. It is local working state, not part
    of the hardware release.
    Claude-Session: https://claude.ai/code/session_01Nj2tx1jiyVmp3pM1ziXZRX
    [neobox.blend]
2026-07-29 Integrate holder alignment blocks into the printed film stage
    The four blocks existed as separate glue-on parts only because the stage
    was originally aluminium. With the printed stage they belong on the part:
    the stage is now a 200 x 230 x 5 solid plate (bottom ribs deleted) with
    the blocks printed on its top face, giving one flat print orientation and
    nothing to glue. Top face stays at z = 114, so the diffuser, holders and
    studs are unchanged; the lower nuts move down 1 mm to support the thicker
    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
    [film-stage-printed.stl, neobox.blend]
2026-07-29 Clear the film run-out corridor: corner L-blocks, front stud moved
    Fit-check found the film could not be loaded at all: the two end
    alignment blocks sat centred across the holder channel mouths with their
    tops 0.2 mm below the film plane, and the front stud at (0, -100) rose
    to film height in the middle of the run-out path.
    The blocks become four corner Ls (|x| = 40-60) registering the same
    holder faces while leaving both channel mouths open, and the front stud
    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
    [alignment-blocks-x4.stl, film-stage-aluminium-3mm.dxf, film-stage-printed.stl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]
2026-07-29 Explain why the stage levels on three points, not four
    Answers the natural objection that levelling should be symmetric: three
    points define the plane exactly with all studs loaded, a fourth
    over-constrains and bends the plate, and symmetry only affects
    cross-coupling during adjustment, not the ability to level. Also spells
    out the levelling procedure (front nut = pitch, rear pair = roll).
    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
2026-07-29 Drop alignment-blocks-x4.stl
    Its only remaining role was the hypothetical aluminium-stage upgrade,
    which made it a file whose primary documentation was "do not print
    this". The corner-block geometry lives on the printed stage in
    cad/neobox.blend and in the docs; if the aluminium upgrade ever
    happens, re-export the blocks from the source or cut them from scrap.
    Default build stays at 8 parts, optional extras drop to one (6x6 mask).
    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
    [alignment-blocks-x4.stl, neobox.blend]
2026-07-29 Fix overlapping and clipped elements in the manufacturing drawing
    Rendered inspection found the height dimension line slicing through
    four callout texts, the rear-studs note colliding with the film-holder
    callout, and several long lines (subtitle, hardware list, assembly
    steps 5-8) running off the right edge of the canvas. The dimension line
    moves to the left side, notes are repositioned, long lines are wrapped,
    and the canvas grows to 920 px to fit the extra rows.
    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
2026-07-29 Design log: why the lid is not fused into the main body
    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
2026-07-29 Add the optics story to the README with a light-path diagram
    Explains why a flash and not an LED panel — inside the closed box the
    microsecond pulse is the exposure, so vibration cannot blur it, every
    frame gets identical base-ISO f/8 light, and the xenon spectrum is
    continuous daylight — and walks the light path: horizontal firing into
    a white integrating cavity, one opal diffuser under the film, black
    above it, camera shooting against the uniform glow. New annotated
    drawings/optics.svg embedded in all three README languages.
    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
2026-07-29 Localise docs and drawings into Chinese and Japanese
    Every doc now exists in three languages with a switcher line, matching
    the README pattern: design, printing, assembly, BOM and the design log,
    plus translated optics and manufacturing-overview diagrams (geometry
    identical, text swapped, render-verified). The Chinese and Japanese
    READMEs now link to their own language docs and embed their own
    diagrams.
    Also folded in along the way: the effective-shutter argument (the
    microsecond pulse versus the 1/15-1/60 s a continuous panel would
    need) in the READMEs, optics diagram and design docs; a
    minimum-requirements fallback in the printing docs for shops that
    insist on default settings (only the h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
2026-07-29 Quantise holder z-geometry to 0.2 mm layers; enlarge windows 0.5 mm/side
    Print vendor measured the holder steps at 0.20/0.50 mm and (correctly)
    reported they will not resolve at default 0.2 mm layers. The 0.5 step
    was the design's fault: it divides into no common layer height. Every
    holder z-feature is now a multiple of 0.2 — land 0.2, rail 0.8, channel
    0.3 -> 0.4 — so default slicer profiles print it true; the 0.12–0.16 mm
    layer requirement is gone. Film plane unchanged.
    Windows also grew 0.5 mm per side (25x37, 57x85 vs nominal 24x36/56x84)
    to absorb camera-gate variance and printer XY tolerance.
    Re-exported the four holder STLs; updated design/printing/bom docs,
    READMEs and manufa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
    [film-holder-120-base.stl, film-holder-120-lid.stl, film-holder-135-base.stl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]
2026-07-29 Export all STLs as watertight single solids; quantise magnet pocket depths
    Vendor's second review flagged leftover artefacts. Two real causes:
    - Magnet pocket blind depths (1.55/2.05 mm) were not layer multiples.
    Now closure pockets are exactly 2.0 deep and stage pockets 1.6, so
    every exposed z-plane in every part sits on the 0.2 mm grid in both
    print orientations.
    - Parts were exported as overlapping shells (0.5 mm interpenetration,
    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
    [access-panel.stl, film-holder-120-base.stl, film-holder-120-lid.stl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]
2026-07-29 Raise all exposed holder steps to >=2 layers (0.4 mm)
    Vendor round three: the land relief and the lid pressure strips were
    exactly one layer at 0.2 mm — printable but hostage to first-layer
    squish. Base plate thinned 4 -> 3.8 (land tops, i.e. the film plane,
    unchanged; relief doubles to 0.4). Lid plate and rails raised 0.2 so
    the pressure strips deepen to 0.4 while the channel stays 0.4. Strips
    gain 0.3 side clearance to the rails. Verified: watertight, all
    horizontal planes on the 0.2 grid, minimum step 0.4 on every part.
    Docs/READMEs updated in three languages; also fixed stale v1 z-stack
    numbers (120.7/123.7) that had survived in the design tables.
    Design-log entry 19.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
    [film-holder-120-base.stl, film-holder-120-lid.stl, film-holder-135-base.stl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]
2026-07-29 Audit remaining parts: fix access-panel half-layer boundaries and print orientation
    Same two-layer audit applied to the five non-holder parts. Four are
    clean (min step: main-body 4.0, top-cover 2.0 flipped, stage 5.0,
    mask 1.0). The access panel had its thickness split at 3.5/9.5 mm —
    half-layer boundaries in its print orientation — and the documented
    "face-down" orientation would rest the part on its handle. Plug is
    now 4.0 mm (matching the docs), handle 9.0, total depth still 16;
    wall-mating faces untouched. Orientation corrected to plug-face down
    with supports for the 3-7 mm face-plate rim.
    Claude-Session: https://claude.ai/code/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
    [access-panel.stl, neobox.blend]
2026-07-29 Rewrite vendor scripts with visible-feature orientations; fix wrong channel-down rule
    The vendor asked which face "channel face down" meant. Deriving the
    answer from print physics showed the instruction itself was wrong
    since v1: channel-down stands the base on its 2 mm rail crests and
    hangs the film-bearing lands 0.6 mm over air. Correct orientation for
    all holder parts is flat face down, features up, no supports.
    All ordering scripts (bom x3, order note) now describe placement per
    file by what the operator can see, with explicit support locations
    (main-body opening lintel, access-panel face rim). Printing/design
    docs and drawings updated in three languages; bom.md script also lost
    a stale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
2026-07-30 Rewrite the documentation for beginners, in three languages
    The docs were expert-grade in substance but stopped at "the box glows
    evenly" — the reader's actual goal, digitised negatives, was never
    reached. Six reader personas were run over the old set; every one of
    them named the same gap first.
    New documents (all three languages):
    getting-started is this for me, what I must already own, real cost
    and timeline, the whole road map
    scanning the missing half: camera, lens, magnification per
    format, the mirror parallelism method, focus,
    exposure, loading film, flat-field and inversion
    troubleshooting symptom / cause / fi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
    [main-body.stl]
2026-07-30 Give sync speed an actual number
    The documents defined "sync speed", linked it from four places and told
    the reader to stay at or below it — without ever printing a value. A
    beginner had nothing to set, and the one practical trap was missing:
    a cheap 2.4 GHz receiver adds enough latency that the usable sync speed
    is often a step below the camera's rated one.
    The exposure table and the camera-settings strip in the capture-setup
    drawing now say 1/125 s. The glossary entry gives typical ratings
    (1/160-1/250 s on modern focal-plane shutters, 1/125 s or slower on
    older and medium-format bodies, any speed on a leaf shutter), where to
    look it up, why going slower costs nothing inside a closed bo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
2026-07-30 Commit the STL export pipeline as tools/export_stl.py
    The docs claimed the nine STLs are generated from cad/neobox.blend, but
    the procedure that actually turns the deliberately overlapping shells
    into watertight single solids lived nowhere in the repository — and the
    manual re-export recipe in design.md section 11 told the reader to
    boolean-union the main body only, when the top cover (eleven shells),
    access panel, stage and mask are multi-shell too; following it produced
    files that fail the repo's own verifier.
    tools/export_stl.py is the committed pipeline: per output file it
    copies the sources, separates loose shells, unions them (EXACT),
    welds boolean slivers (0.02 mm), limited-dissolv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
2026-08-14 v5 compact redesign: open-front box, integrated cover-stage, screw-free
    Geometry (cad/neobox.blend) redesigned around the flash sitting outside
    the box at its fully open front:
    - main body 124.8x154.8x73 (was 208x273x96), walls 2.4, base 3.0,
    locating tenons on the side walls; access panel deleted
    - cover-stage: one part replaces top cover + film stage; acrylic
    68x118x2 sits in a sunken pocket under the holder seat, steel
    washers 10x10 flush in the tray floor, corner notches drop onto
    the box tenons; whole machine is screw-free (leveling moved to
    the camera side)
    - film holders 94x120 (were 110x170), both formats share one outer
    geometry; pressure system is a 4.6 mm ledge carryi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
    [access-panel.stl, cover-stage.stl, film-holder-120-base.stl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]
2026-08-14 Rewrite all documentation for the v5 geometry
    Every doc family (getting-started, bom, printing, assembly, scanning,
    troubleshooting, design, glossary) in all three languages, plus the
    three READMEs and CONTRIBUTING, now describes the v5 machine: open
    front with the flash on the desk, integrated cover-stage, screw-free
    magnetic assembly with camera-side mirror levelling, and the insert
    platform flattening system (printed pressure windows by default, one
    shared 64x95 anti-Newton glass as the upgrade).
    design-log gains entries 21-24 covering the v5 decisions; obsolete
    glossary entries (heat-set insert, differential screw, clearance vs
    tapped) retire with the fasteners. The print spec is pinned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
2026-08-15 Make the optical case for the flash, with a spectral-response figure
    The Why-a-flash section in all three READMEs grows from four paragraphs
    into the full argument, written from the optics side: the effective-
    shutter case (kept), the spectral case (three dye layers need honest
    energy in all three bands; xenon is a continuous ~5600 K source with
    strong deep red, a white LED has the blue spike, the cyan gap and the
    deep-red roll-off exactly where the cyan layer and orange mask work),
    why RGB-mixed white fails a one-shot Bayer camera, the honest optimum
    (monochrome sensor + sequential RGB, drum-scanner lineage) and where
    NeoBox deliberately sits, consistency (repeatable pulses, no thermal
    drif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
2026-08-15 De-formularise the Why-a-flash section; say where the shutter dial sits
    A reader took the 1/1,000-1/20,000 s pulse duration for a required
    shutter speed. The opening paragraph now states outright that the
    camera dial stays at an ordinary 1/125 s sync and only the tube's pulse
    is that short, in all three languages, and the spectral-response
    figure's time panel carries the same clarifier.
    While in the section: nine consecutive bold-lead paragraphs shrink to
    four, the em-dash density drops by about half, and sentence openings
    vary - same arguments, less template.
    Claude-Session: https://claude.ai/code/session_01RfYwGJtkcfszBvCwkbGwus
2026-08-15 Strip the AI tells from every document, in all three languages
    A corpus-wide edit pass over the nine doc families, the READMEs,
    CONTRIBUTING and the drawing labels. The one pattern the corpus was
    actually sick with was the em-dash: over a thousand of them used as an
    all-purpose dramatic pause. Prose dashes are now gone in every
    language, rewritten as colons, commas, parentheses or shorter
    sentences; the survivors are step-heading titles (their anchors are
    load-bearing), table placeholders and range dashes in numbers.
    Along the way: aphorism-styled lesson lines in the design log became
    plain statements, a few triple-parallel and same-shape sentence runs
    were broken up, two small content bugs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
2026-08-15 Retire the LED strip and call the release v1
    The optional LED positioning strip is gone from everywhere it lived:
    the BOM tables and vendor scripts, the scanning and getting-started
    workflows, the manufacturing-overview drawing, the Blender mock-ups.
    Design section 7 now says the true thing instead: there is no focus
    light and nothing electrical inside the box; frame under ordinary room
    light and let the flash bury it at capture.
    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
    [neobox.blend]
2026-08-15 Rename the Blender source to English, and make the names load-bearing
    Everything inside cad/neobox.blend is English now: objects, mesh
    datablocks, collections and materials. The names were not chosen for
    translation but for a rule that the exporter can check.
    A printed part is named after the STL file it becomes, so main-body.stl
    comes from the four main-body_ shells and cover-stage.stl from an object
    called cover-stage. Everything that is not printed carries a mock_
    prefix. tools/export_stl.py now fails the whole export when it meets a
    mesh object that is neither listed in MAPPING nor prefixed mock_, which
    turns the convention into a gate: a part added to the scene and
    forgotten in the tab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
    [neobox.blend]
2026-09-16 Add the slide plate: a fourth holder set for mounted 135 slides
    A slide in its mount is 1.2–3.2 mm thick and the 135 channel is 0.4, so
    mounted slides were out of scope. Cutting a pocket into the 135 base would
    remove the land that supports the strip, so instead slide-plate-135.stl is
    a single 94 × 120 × 5 black plate that stands in the cover-stage tray in
    place of the 135 set: a 51.4 mm square pocket 2.0 deep, a 26 × 38 window
    through its floor and two blind finger wells. No lid, no magnets, no
    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
    [neobox.blend, slide-plate-135.stl]
2026-09-16 Add the 4×5 stage on the v1 body, and give the cover-stage its missing two notches
    4×5 rides on the unchanged main body with two optional parts and one
    larger acrylic. cover-stage-4x5.stl keeps the cover-stage's outline, plate
    and four notches and carries a 102 × 126 light window, a 107 × 131 recess
    for a 106 × 130 × 2 opal sheet and a 112.6 × 138.6 tray with no washer
    pockets. sheet-plate-4x5.stl stands in that tray: 112 × 138 × 5, a
    102.2 × 127.6 pocket 2.0 deep, a 97 × 121 window and two edge notches. No
    lid, no magnets, no pressure element: at about 0.25× the depth of field at
    f/8 is roughly 8–10 mm, so a sheet's curl is invisible. The mixing margin
    drops from 29/27.5 to 9/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
    [cover-stage-4x5.stl, cover-stage.stl, neobox.blend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]
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2026-11-06 Add a 45° render of the assembly to the READMEs, and fix the 6×7 and 6×9 magnifications in the scanning guide
    README (en, zh-CN, ja): a Cycles render of the current model from an
    oblique 45°, drawings/neobox-45.png, placed under the badges. Printed
    parts are solid; the flash, trigger receiver, lens and camera are
    translucent ghosts. The camera tube in the picture is still in
    development and is not yet in stl/ or the part list.
    docs/scanning (en, zh-CN, ja): the magnification table had 6×7 and 6×9
    computed with the frame's long side across the sensor's short side.
    With the camera turned so the long sides align, both are 0.43× on full
    frame and 0.28× on APS-C, the same as 6×6. The nu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
2026-11-07 Rewrite every document in plain language with less AI tone, unify part names to the glossary, and tighten the camera tube
    Docs: all ten families plus CONTRIBUTING, in English, Chinese and Japanese,
    were rewritten for a reader who has never camera-scanned film or used a 3D
    printer, following the lieflat-less-ai-tone rules: semicolons split into
    sentences (zh 4.31 -> 0.03 per thousand characters, en 296 -> 11, all in
    tables or code), 63 conclusion colons turned into full stops, the contrast
    frames, openers and conditional 当…时 removed, rhetorical 顿号 runs
    collapsed, metaphors replaced by plain statements, and one plain-word gloss
    at the first use of each technical term. Headings, table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
2026-11-07 Collapse the documentation to three documents per language
    The ten document families (about 45,000 English words, times three
    languages) are replaced by a README, a design document and
    CONTRIBUTING. The README covers what the box is, what to buy, how to
    print, assemble and scan, and a fault table, in about 1,800 words
    including the print-shop order text. The design document keeps the
    dimension chain, the cover-stage, holder, slide-plate and 4x5 tables,
    the layer grid, a dozen design decisions distilled from the design log,
    the flash settings, the camera tube and the source workflow, in about
    2,700 words. CONTRIBUTING is 220 words. Every number was carried over
    from the previous documents and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
2026-11-07 Put the spectrum argument back in the README, with its figure
    A short "Why a flash" section in all three READMEs: the pulse is the
    exposure, colour negative needs a continuous spectrum where white LEDs
    have their gap and roll-off, and a fixed manual flash gives every frame
    the same light. The spectral-response drawing goes with it. The design
    document's bullet now points to the README instead of repeating the
    numbers, so each fact is still said once.
2026-11-07 Seat the camera tube on the box instead of the film holder
    The tube's base is now a hood over the box top. A 45-degree seat rests on
    the cover-stage's top edge along all four sides, so the hood centres
    itself with no play and the camera load goes straight down the main-body
    walls. The holder lid, the holder base and their magnets are no longer in
    the camera's load path, and the base has no magnets of its own. A 4 mm
    skirt hangs over the plate edge, 70 mm slots in both end walls pass the
    film, and the corners are cut back so the seat touches only the straight
    edges and every slope stays within 45 degrees.
    Six crush ribs on the column spigot (0.1 mm interference in the bore) let
    the column tu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
2026-11-08 Publish the Laowa 85 parts for 4x5
    stl/camera-tube/ gains a 145 mm spacer and a 145 mm column that put the
    Laowa 85 at a working distance of 350 mm on the hood. At 0.25x the 4x5
    sheet fills the sensor's short side with no margin, and the lens's 0.25x
    working distance is only known to within about 15 mm: a model fitted to
    f = 85 at infinity and the published 96 mm (1x) and 69 mm (2x) gives
    321 mm, a review's chart gives 336 mm. At 350 mm both put the lens at
    0.23-0.24x, below the 0.247x at which the 97 mm window still fits the
    24 mm sensor height, so the whole sheet is in frame either way. Both
    parts use the self-centring ring seat and the crush ribs, are about
    150 mm tall, and pass the verif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
